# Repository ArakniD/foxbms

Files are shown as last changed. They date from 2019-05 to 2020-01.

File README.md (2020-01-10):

# foxBMS

foxBMS is a free, open and flexible development environment to design battery
management systems. It is the first modular open source BMS development
platform.

The foxconda environment: This environment provides all the tools necessary
to generate the documentation, compile the code for the MCUs and flash the
generated binaries on the MCUs (e.g., ``Python``, ``git``, ``GCC``). foxconda
can be downloaded [here](https://iisb-foxbms.iisb.fraunhofer.de/foxbms/).

The starting point to get foxBMS is the foxBMS repository at
[https://github.com/foxBMS/foxbms](https://github.com/foxBMS/foxbms), which
contains all files for the foxBMS project.

## foxBMS Repository

- In `foxbms\documentation` the configuration of the doxygen documentation for
  the primary and secondary MCU can be found.
- The software for the MCUs is found in `foxbms\embedded-software`. This
  includes the Hardware Abstraction Layer (HAL), the real-time operating system
  FreeRTOS and the BMS application itself.
- The layout and schematic files for the foxBMS hardware are found in the
  `foxbms\hardware`.
- The build toolchain and other tools related to foxBMS are found in
  `foxbms\tools`.

A generated version of the Sphinx documentation can be found at
[docs.foxbms.org](https://docs.foxbms.org). It explains the structure of the
foxBMS hardware, how to install the foxconda environment and how to use
foxconda to compile and flash the sources.

## Building the Sources

For building the software, open a shell and type ``python tools\waf --help``.
All available build options will be displayed. The top build directory is
``foxbms\build``.

[foxbms.org/](https://foxbms.org/)

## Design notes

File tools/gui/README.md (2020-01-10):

# foxBMS GUI

The script ``foxbms_interface.py`` is used to visualize the data from foxBMS
(e.g., voltages, temperatures current, errors).

It was written in a modular way, so that the only reference to the driver
of the CAN adapter is in the function ``receive_send_can_adapter()``.
Throughout the rest of the code, instances of the class can_message() are
used to manipulate CAN frames (ID, DLC, data).

The interface needs ``matplotlib``. Within the foxconda environment, this
can be done by using the command

```sh
C:\foxconda3\Scripts\activate
conda install matplotlib
```

The default version was configured to work with USB CAN-adapter from
PEAK (information found on the [peak-system.com](https://www.peak-system.com)
website). Two external elements are then needed in addition to the interface
script:

* PCAN-adapter DLL
* Python-wrapper for PCAN, named ``PCANBasic.py``

These files are redistributed in the foxBMS repository.
Before using them, you have to read the file ``readme.txt`` which gives
the terms of use.

The redistributed DLL is the 64 bit version.

The frame ``AdapterSelectionFrame()`` was used to implement the choice of the
CAN-adapter to use. It was configured to write with the PCAN-adapters.
In case another adapter is used, the frame has to be modified accordingly.

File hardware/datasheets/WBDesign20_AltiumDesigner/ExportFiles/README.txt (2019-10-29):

## WEBENCH Design 20
Created at Sun Jul 21 03:32:41 PDT 2019
**********************************************************
***************** Schematic Instructions  ****************
**********************************************************

To import your new Schematic into Altium:

1. Unzip the downloaded folder files to a local directory and 
   Start the Altium program.
2. From the menu select "File"->"Open".
3. Select the file named in the path above ending with ".schdoc"
   and "Open" the file.
4. Your Schematic should be viewable within Altium now.

For additional information, please visit this site:
http://www.accelerated-designs.com/help/Altium_BrdSch_import.html

**********************************************************
*******************  PCB Instructions  *******************
**********************************************************

To import your new BOARD into Altium:

1. Unzip the downloaded folder files to a local directory
	and Start the Altium program.
2. From the menu select "File"->"Open".
3. Select the file named in the path above ending with ".pcbdoc"
   and "Open" the file.
4. Planes will need to be repoured to update the Copper Pour Polygons
	a. Once your board is loaded, select the Tools menu from the
	   top Menu Bar
	b. Scroll to the Polygon Pours item on the Tools Menu.
	c. The Polygon Pours item should expand to show more options
	d. Select Repour All Polygons, this will repour all of the
	   polygons.
5. Your board should be viewable within Altium now.

For additional information, please visit this site:
http://www.accelerated-designs.com/help/Altium_BrdSch_import.html

**********************************************************
*******************  LIB Instructions  *******************
**********************************************************

To import your new LIBRARY PARTS into Altium follow these steps:

1. After running the Ultra Librarian export for the first time,
   you will need to copy the following files into an area where
   they can be accessed for all future translations.  They are script
   files that Altium will need to be able to find.
	a. UL_Form.dfm
	b. UL_Form.pas
	c. UL_Import.pas
	d. UL_Import.prjScr
2. The above script file will need to be run from within Altium.
   This can be done by going to File, Open and selecting the
   UL_Import.PrjScr file stored above.
3. Select the "DXP" dropdown menu in the top-left corner runfrom
   the drop down menu and select "Run Script". Select "UL_Form.pas"
   and click "OK"
4. When the script is run, it will ask you for the file name of the
   Ultra Librarian file to run. Click "File...", select the latest file
   produced with a date code (for instance 2010-02-17_23-12-34.txt), and
   click "Start Import".
5. The script will open a new Integraged Library project and import
   the Ultra Librarian data into it.  When complete a message box
   will pop up saying that import is done.

For additional information, please visit this site:
http://www.accelerated-designs.com/help/Altium_import.html

For a video tutorial, please visit:
http://youtu.be/pih50yx9HYU

**********************************************************
****************  SIMULATION Instructions  ***************
**********************************************************
This XML can be imported in Altium Designer 14 and higher using
WEBENCH Altium Connector Extension and simulated using WEBENCH
Simulation Engine.

The WEBENCH Altium Connector provides an interface to the
Texas Instruments WEBENCH Designer Tools as well as to open
WEBENCH exported Designs directly from inside Altium Designer.
It also includes the advanced WEBENCH Simulation Engine which
can be used for offline circuit simulations.

You will need to activate WEBENCH Altium Connector to be able
to use the WEBENCH Simulation Engine.

Installation guide:
http://www.ti.com/lit/SNVU481
You can download the WEBENCH extension from Altium Designer Extensions.

Connector Details:
http://www.ti.com/lsds/ti/analog/webench/altiumconnector.page

More about WEBENCH simulation export to Altium:
http://www.ti.com/lsds/ti/analog/webench/simexportaltium.page

User Manual:
http://www.ti.com/lit/szzu007

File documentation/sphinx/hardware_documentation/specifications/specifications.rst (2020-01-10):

.. include:: ../../macros.rst

.. _HARDWARE_DOCUMENTATION_SPECIFICATIONS:

==============
Specifications
==============

The following specifications must be met to ensure a safe and optimal work with the |foxbms| hardware.

----------
BMS-Master
----------

^^^^^^^^^^^^^^^^^^
Electrical Ratings
^^^^^^^^^^^^^^^^^^

==================================================  =======     =======     =======     ====
Description                                         Minimum     Typical     Maximum     Unit
==================================================  =======     =======     =======     ====
Supply Voltage DC                                   10          --          26          V
Contactor Continuous Current                        --          --          4           A
Contactor Feedback Supply Voltage                   --          5.0         --          V
Analog Input                                        --          --          3.3         V
Isolated Contacts Continuous Current                --          --          4           A
Interlock Circuit Sink Current                      --          10          --          mA
Idle Supply Current at 12V supply                   --          150         --          mA
Idle Supply Current at 24V supply                   --          110         --          mA
==================================================  =======     =======     =======     ====

^^^^^^^^^^^^^^^^^^^^^^^^^^^^^^^^^^^^^^^^^^^
Mechanical Dimensions (BMS-Master PCB only)
^^^^^^^^^^^^^^^^^^^^^^^^^^^^^^^^^^^^^^^^^^^

==================================================  =======     =======
Description                                         Value       Unit
==================================================  =======     =======
Width                                               120         mm
Length                                              160         mm
Height                                              15          mm
Weight                                              122         g
==================================================  =======     =======

^^^^^^^^^^^^^^^^^^^^^^^^^^^^^^^^^^^^^^^^^^^^^^^^^^
Mechanical Dimensions (BMS-Master Unit in housing)
^^^^^^^^^^^^^^^^^^^^^^^^^^^^^^^^^^^^^^^^^^^^^^^^^^

The BMS-Master Unit consists of BMS-Master board, BMS-Interface board and BMS-Extension board and is mounted in an aluminum housing.

==================================================  =======     =======
Description                                         Value       Unit
==================================================  =======     =======
Width                                               124         mm
Length                                              164         mm
Height                                              49.2        mm
Weight                                              785         g
==================================================  =======     =======

-----------------
BMS-Slave 12-Cell
-----------------

^^^^^^^^^^^^^^^^^^
Electrical Ratings
^^^^^^^^^^^^^^^^^^

==================================================  =======     =======     =======     ====
Description                                         Minimum     Typical     Maximum     Unit
==================================================  =======     =======     =======     ====
Battery Module Voltage                              11          --          60          V
Single Battery Cell Voltage                         0           --          5           V
Temperature Sensor Inputs                           --          10k         --          Ω
Analog Inputs (pin headers)                         0           --          5           V
Digital Inputs/Outputs (pin headers)                0           --          5           V
External DC Supply (HW version 2.1.0 and above)     8           12          24          V
==================================================  =======     =======     =======     ====

^^^^^^^^^^^^^^^^^^^^^^^^^^^^^^^^
Mechanical Dimensions (PCB only)
^^^^^^^^^^^^^^^^^^^^^^^^^^^^^^^^

==================================================  =======     =======
Description                                         Value       Unit
==================================================  =======     =======
Width                                               100         mm
Length                                              160         mm
Height                                              15          mm
Weight                                              83          g
==================================================  =======     =======

-----------------
BMS-Slave 18-Cell
-----------------

^^^^^^^^^^^^^^^^^^
Electrical Ratings
^^^^^^^^^^^^^^^^^^

==================================================  =======     =======     =======     ====
Description                                         Minimum     Typical     Maximum     Unit
==================================================  =======     =======     =======     ====
Battery Module Voltage                              16          --          90          V
Single Battery Cell Voltage                         0           --          5           V
Temperature Sensor Inputs                           --          10k         --          Ω
Analog Inputs (pin headers)                         0           --          5           V
Digital Inputs/Outputs (pin headers)                0           --          5           V
External DC Supply                                  8           12          24          V
==================================================  =======     =======     =======     ====

^^^^^^^^^^^^^^^^^^^^^^^^^^^^^^^^
Mechanical Dimensions (PCB only)
^^^^^^^^^^^^^^^^^^^^^^^^^^^^^^^^

==================================================  =======     =======
Description                                         Value       Unit
==================================================  =======     =======
Width                                               100         mm
Length                                              160         mm
Height                                              15          mm
Weight                                              88          g
==================================================  =======     =======

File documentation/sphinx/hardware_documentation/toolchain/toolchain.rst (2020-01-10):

.. include:: ../../macros.rst

.. _HARDWARE_DOCUMENTATION_TOOLCHAIN:

=========
Toolchain
=========

Layout and schematics
---------------------

The initial layout and schematics were developed with Cadsoft Eagle version
6.5.0 which is now owned by
`AUTODESK <https://www.autodesk.com/products/eagle/overview>`_. Recently, all
hardware projects were ported to
`Altium Designer <https://www.altium.com/altium-designer/de>`_.

Information on Debugging
------------------------

Two types of debugger have been tested with |foxBMS|.

* The first one is the
  `Segger J-Link Plus <https://www.segger.com/j-link-plus.html>`_ with the
  `adapter for 19-Pin Cortex-M <https://www.segger.com/products/debug-probes/j-link/accessories/adapters/19-pin-cortex-m-adapter/>`_
  (the adapter is needed to connect the debugger to the |master|). A cheaper
  debugger solution is the
  `Segger J-Link Base <https://www.segger.com/jlink_base.html>`_ which also
  needs the adapter.

* The second type of debugger is the
  `Lauterbach Debugger <http://www.lauterbach.com>`_ µTrace for Cortex-M (see
  the "Products" section in the navigation bar on the left). The Lauterbach
  debugger provides more debugging functionalities, but is also more expensive
  than the J-Link.

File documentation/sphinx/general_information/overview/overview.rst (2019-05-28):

.. include:: ../../macros.rst

.. _GENERAL_INFORMATION_OVERVIEW:

========
Overview
========

Hereafter a general overview of the content of |foxbms| can be found.

The |master| consists of 3 boards: |BMS-Master|, |BMS-Interface|, |BMS-Extension|. Two ARM-based microcontroller units (Cortex-M4) are used on |BMS-Master|: |MCU0| (also called primary MCU) and |MCU1| (also called secondary MCU). The BMS software runs on |MCU0|, while |MCU1| is used for redundant safety.

|MCU0| communicates with the outside world via a CAN bus (|CAN0|). The current flowing through the battery system is measured via a current sensor connected via the CAN bus. The sensor is controlled via CAN by |MCU0| and sends the resulting measurement via CAN.

The |slave| (|BMS-Slave|) are used to measure cell voltages and cell temperatures in the battery modules. The |slaves| are linked via a proprietary daisy chain from the company Linear Technology (i.e., isoSPI).

In order for the |master| to communicate with the |slaves|, an interface board (i.e., |BMS-Interface|) is needed. It converts the SPI signals from the |BMS-Master| into differential signals used by the daisy chain and vice versa.

Three power contactors are used to connect and disconnect the battery modules (or pack) from the load:

 - Main Contactor Plus
 - Main Contactor Minus
 - Pre-charge contactor

These contactors are driven by |MCU0|. Requests are made via CAN to the system to open and close the contactors. Based on the measurements and the algorithms implemented in the software, |MCU0| decides if the contactors should be closed or opened. It sends information via CAN so that the user knows the state of the system.

An interlock line is also present. If it is opened, either by |MCU0|, |MCU1| or somewhere else (e.g., emergency stop), all contactors will immediately open.

A secondary ARM-based microcontroller is present on the master, called |MCU1| (or secondary MCU). It monitors the slaves via a second and separate daisy chain. Like the |MCU1|, it can open the interlock in case something goes wrong with the system.

In case more inputs and outputs and further functions are required, an |BMS-Interface| is available and can be easily adapted to specific needs.

This description reflects the current state of foxBMS. Due to the open nature of the system, many other possibilities can be implemented, like for example:

 - Use of other types of current sensors (e.g., shunt-based or Hall-effect based)
 - No |slave| needs to be used: a direct measurement of the cell voltages and cell temperatures can be performed by the |master|
 - A higher number of contactors can be controlled (e.g., up to 9)
 - etc...

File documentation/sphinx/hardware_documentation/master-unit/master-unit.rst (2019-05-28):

.. include:: ../../macros.rst

.. _HARDWARE_DOCUMENTATION_OVERVIEW:

===========
Master-Unit
===========

This section describes the hardware modules used in |foxbms|. :numref:`Fig. %s <master_block_diagram>` shows a block diagram of the |master| with all its components.

.. _master_block_diagram:


   |master| hardware block diagram

Supply 0 (|primary|)
--------------------

.. _supply0:


   Supply for all circuit parts related to the |primary| part of |foxbms|

The external supply for the |BMS-Master| is divided in a part supplying the interlock circuit, the contactors (``SUPPLY_EXT2``), and the rest of the circuit (``SUPPLY_EXT0``) as shown in :numref:`Fig. %s <supply0>` . The |Master| can be supplied with a voltage between 12V and 24V DC. The |primary| part of the |foxbms| is isolated from ``SUPPLY_EXT0`` by an isolating DC/DC converter (IC202). The 5V output of the DC/DC converter is stepped down to 3.3V by an LM1085 LDO (IC201). The output of IC201 (+3.3V_0) supplies the |primary| microcontroller |MCU0| and the related circuits.

Supply 1 (|secondary|)
----------------------

.. _supply1:


   Supply for all circuit parts related to the |secondary| part of |foxbms|

The |secondary| part of |foxbms| is also supplied by ``SUPPLY_EXT0`` as shown in :numref:`Fig. %s <supply1>`. Also the |secondary| part of the |BMS-Master| is isolated from ``SUPPLY_EXT0`` by an isolating DC/DC converter (IC302). The 5V output of the DC/DC converter is stepped down to 3.3V by an LM1085 LDO (IC301). The output of IC301 (+3.3V_1) supplies the |secondary| microcontroller |MCU1| and the related circuits.

|MCU0| (|primary|)
------------------

.. _mcu0_boot_rst:


   Boot and reset circuit for the |primary| microcontroller

:numref:`Fig. %s <mcu0_boot_rst>` shows the boot and reset related circuits of the |primary| microcontroller |MCU0|. |MCU0| can be manually reset by push button S401. Please note that the housing has to be opened to reach S401, therefore resetting |MCU0| by means of S401 is intended for use in a laboratory setting/debugging situation.

.. _mcu0_adc_ref:


   ADC reference voltage for the |primary| microcontroller

The ADCs of the |primary| microcontroller |MCU0| are supplied with a 2.5V reference voltage provided by an ADR3425 (IC401) as shown in  :numref:`Fig. %s <mcu0_adc_ref>`.

.. _mcu0_osc:


   Clock circuits of the |primary| microcontroller

The |primary| microcontroller |MCU0| is clocked by an 8MHz oscillator as shown in :numref:`Fig. %s <mcu0_osc>`. An separate oscillator (Q402) is used to clock the RTC (real time clock) integrated in |MCU0|.

Interface between |MCU0| and |MCU1|
-----------------------------------

.. _mcu_to_mcu_if:


   Interface between |primary| and |secondary| microcontroller

Besides being linked over the common interlock line, the |primary| and |secondary| microcontroller also have a common SPI data interface. The |secondary| microcontroller |MCU1| acts as the master in the SPI communication. The interface is isolated using an ADUM3401 as shown in :numref:`Fig. %s <mcu_to_mcu_if>`.

Interface to Bender ISOMETER
----------------------------
.. _bender:


   Interface to the Bender ISOMETER

The |BMS-Master| supports Bender ISOMETER IR155-3203/-3204/-3210. Two inputs are provided: one for a PWM coded diagnostic signal and one for a simple status signal (OK or NOK) as shown in :numref:`Fig. %s <bender>`. The Bender ISOMETER is supplied ``SUPPLY_EXT0`` and may be switched on or off (lowside) by the |BMS-Master|. The input signals are limited to  level of 5V with Zener diodes D701 and D702. In order adapt the interface for use with a IR155-3204/-3203 device, the solder jumper R705 has to be removed. The input signals are isolated from the microcontoller by an ADUM3301 (IC702).

|CAN0|
------

.. _can0:


   Circuit of the CAN interface (|CAN0|)

The |CAN0| interface is intended to connect additional sensors, such as the Isabellenhütte IVT-MOD-300 current sensor to the |master| and the |master| to other devices such as a test bench control unit or an HMI unit. The circuit in :numref:`Fig. %s <can0>` shown the input circuit consisting of protection diode D801, common mode choke L801, C804, and termination resistors R801 and R802. The CAN transceiver TJA1052 provides isolation and can be put to sleep by the |primary| microcontroller |MCU0| via an CPC1008N optocoupler (IC803). The external part of the |CAN0| interface is supplied by ``SUPPLY_EXT0``.

Interlock
---------

.. _interlock:


   Interlock circuit

The |primary| and |secondary| microcontroller share a common interlock line as shown in :numref:`Fig. %s <interlock>`. The interlock line is isolated from both microcontrollers |MCU0| and |MCU1| by optocouplers. The interlock line is supplied with 10mA by a current source (LM317 - IC901). It can be interrupted by the |primary| microcontroller |MCU0| via optocoupler IC902 and can be read back by |MCU0| via optocoupler IC903. The |secondary| microcontroller |MCU1| can interrupt the interlock line via IC904 and read the interlock status via IC905. The 10mA cause a voltage drop on R906, which turns on MOSFET T901. T901 switches the common ground of all contactors (connected to the |BMS-Master| and |BMS-Extension|). Therefore, when the interlock line is interrupted, the contactors are no longer supplied and open.

Contactors
----------

.. _contactors:


   Contactor circuit, exemplarily shown for contactor0

The |Master| can control up to 9 contactors: 6 on the |BMS-Master| and 3 on the |BMS-Extension|. The according control and feedback circuit is exemplarily shown  for contactor 0 in :numref:`Fig. %s <contactors>`. The contactor is switched on and off by an AQV25G2S photoMOS (IC1001) by the |primary| microcontroller |MCU0|. Every contactor channel is protected with slow blowing fuse (F1001) type Schurter UMT-250 630mA (3403.0164.xx). The free wheeling diode D1001 is not populated. It has to be inserted when contactors are used, that do not provide an internal free wheeling diode. The contactor interface also supports a feedback functionality for contactors with auxiliary contacts. The contactor status can be read back by |MCU0| via an ADUM3300 (IC1103).

Isolated USB interface (|primary| and |secondary|)
--------------------------------------------------

.. _usb:


   USB interface circuit

Both mircocontrollers |MCU0| and |MCU1| provide an isolated USB interface, as exemplarily shown for |MCU0| in :numref:`Fig. %s <usb>`. A FT231XS-R interface IC (IC1402) converts the USB signal to UART, which can easily be interfaced by the microcontroller. The UART signals are isolated by an ADUM3401 isolation IC (IC1403). The USB interface can be used to flash the microcontroller and for communication.

EEPROM
------

.. _eeprom:


   EEPROM, exemplarily shown for the |MCU0|

The |BMS-Master| provides an 2MB EEPROM for data storage for the |primary| and |secondary| MCU (see :numref:`Fig. %s <eeprom>`). It uses an SPI interface, which is shared with the memory card, which is also connected to |MCU0|.

Isolated RS485 Interface
------------------------

.. _rs485:


   Isolated RS485 interface circuit

On the |BMS-Extension| an isolated RS485 interface is provided. It can be used to communicate with the |master| as an alternative to the CAN interface or the UART over USB interface. Moreover, via this interface, monitoring circuits (slaves) using RS485 instead of CAN or another proprietary communication protocol can be connected to the |master|. :numref:`Fig. %s <rs485>` shows the RS485 interface schematic. The external part of the circuit is supplied via a voltage applied to pins 5 (7V - 20V) and 6 (GND) of connector X1301. The external supply voltage is also available on pin 1 (GND) and pin 4. IC1301 provides 5V supply voltage for the transceiver (IC1302) and the external side of the isolator (IC1303). The transceiver (LT1785) features a receiver enable (!RE) and a driver enable (DE) functionality, which can be controlled by the |primary| microcontroller via the signals ``RS485_MCU0_NRE`` and ``RS485_MCU0_DE`` respectively. For data transmission the signals ``RS485_MCU0_TX`` and ``RS485_MCU0_RX`` are used. The data signals are available on connector X1301 pins 1 and 2. The data signals and the enable signals are galvanically isolated from the |BMS-Master| by an ADUM3401 isolator IC.

Isolated Normally Open Contacts (isoNOC)
----------------------------------------

.. _iso_noc:


   Isolated normally open contacts (``ISONOC0`` examplarily)

The |BMS-extension| provides 6 normally open contacts (``ISONOC0`` to ``ISONOC5``) for multi-purpose use. Their function is exemplarily described for ISONOC channel0 ( shown in :numref:`Fig. %s <iso_noc>`). Isolation and switching functionality are realized by AQV25G2S photoMOS (IC2001). The photoMOS are controlled by a MOSFET (T2001), which again is switched by the |primary| microcontroller (``ISONOC0_CONTROL``). The photoMOS is configured for a maximum load current of 6A at 50V. Diode D1002 is optionally and not populated by default. Both power terminals of the photoMOS are available on connector X2001 as ``ISONOC0_POSITIVE`` and ``ISONOC0_POSITIVE`` on consecutive pins 1 and 2.

Analog Inputs
-------------

.. _analog_inputs:


   Non isolated analog inputs (analog channel 0 exemplarily)

For the acquisition of analog data, there are 5 ADC channels (``ANALOG_IN_CH0`` - ``ANALOG_IN_CH4``) available on |BMS-Extension| board. :numref:`Fig. %s <analog_inputs>` shows the input circuit for channel 0. The analog input of the microcontroller (``ADC_MCU0_CH0``) is protected by diode D1701, which clamps the input voltage to 3.3V. By default R1701 is shorted with jumper, while R1702 is 7.75kOhm and C1701 is 100nF. The analog input channels are available on connector X1701. A reference voltage of 2.5V is provided by IC1701 (ADR3425), which can supply a total load current up to +10mA and sink up −3mA. The reference voltage is available in X1701 next to every analog input pin. Pin 11 and 12 are connected to GND.

.. note::
    The analog inputs are not isolated. They are referenced to the same potential as the |primary| microcontroller.

Isolated GPIO
-------------

.. _isolated_gpio:


   Isolated GPIOs (Input 0 and 1; Output 0 and 1 shown exemplarily)

The |BMS-Extension| provides 4 isolated inputs and 4 isolated outputs for general purpose (shown in :numref:`Fig. %s <isolated_gpio>` ). Two ADUM3402 (IC1902 and IC1903) are used for isolation. Their external side of is supplied by ``SUPPLX_EXT0`` via a 78L05F linear voltage regulator (IC1901). The inputs are equipped with a 10kOhm pull down resistor. All isolated GPIOs are available on the connector X1901 pins 1 to 8. Pins 9 and 10 of X1901 are connected to ``GND_EXT0``.

Memory Card
-----------

.. _memory_card:


   Memory card

On the |BMS-Extension| also a memory card slot can be found. It is directly connected to the Data Storage SPI of the |primary| microcontroller. :numref:`Fig. %s <memory_card>` shows the schematic. Via the signal ``CARD_SUPPLY_CONTROL`` (|primary| microcontroller) the supply voltage of the memory card can be switched on and off.

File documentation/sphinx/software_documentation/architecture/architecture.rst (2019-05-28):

.. include:: ../../macros.rst

.. _SOFTWARE_DOCUMENTATION_ARCHITECTURE:

=====================
Software Architecture
=====================

This section describes the |foxbms| software architecture. The architecture
was chosen to enable a processor independent programming as far as possible.
Fig. :numref:`foxbms_software_architecture` shows the software architecture
of |foxbms|.

..  graphviz::
    :caption: |foxbms| software architecture
    :name: foxbms_software_architecture

        digraph {
            rankdir=TB;
            graph [fontname = "monospace"]
            node [fontname = "monospace"]
            edge [fontname = "monospace"];
            subgraph cluster_architecture {
                label="foxBMS (runs within OS context)";
                app [label="application"];
                engine [label="engine"];
                modules [label="foxBMS-Modules", target="_bottom"];
                modules -> app;
                app -> modules;
                app -> engine;
                engine -> app;
                engine -> modules;
            }
            subgraph cluster_foxbms_hal {
                label="";
                drivers [label="Drivers"];
            }
            subgraph cluster_hal {
                label="";
                target="_bottom";
                hal     [label="HAL"];
            }
            modules -> drivers;
            drivers -> hal;
     }

The software consists of a base hardware abstraction layer of the
microcontroller. The driver layer on top if it is used to configure and
initialize the peripherals of the microcontroller. These hardware dependent
layers resemble the base of the software architecture. The remaining modules
are built on top of it to allow an easy port of the software to different
microcontrollers.

Hardware abstraction layer
==========================

The hardware abstraction layer (HAL) consists of the STM32F4xx HAL Drivers
|version-hal|. Additionaly the Cortex Microcontroller Software Interface Standard
(CMSIS) |version-cmsis| is used as an abstraction layer for the Cortex M4F processor.

Drivers
=======

The driver layer is responsible for the configuration and the initialization of
the controller peripherals. These drivers are dependent on the specific used
microcontroller and the used HAL. Drivers are only allowed to include files
from driver or the lower hardware abstraction layer (i.e. SPI modules includes
DMA module to configure the respective DMA stream).

|foxbms|-Modules
================

|foxbms|-modules initialize, configure and control hardware connected to the
|master|. These modules are only allowed to access the hardware through the drivers
and directly via the HAL. No direct function calls to the HAL should be make
the modules as independent as possible from the used microcontroller. They may
include engine modules (i.e. database, diag), applications (com) or even the
operating system if they need to ensure some runtime specific behaviour. These
modules are called within the operating system to ensure a real-time behaviour.

Operating System
================

The real-time operating system FreeRTOS |version-freertos| is used to manage
the foxBMS-engine and applications. Tasks with different priorities are used to
process the different algorithms and state machines and to ensure a real-time
behaviour of the different modules.

|foxbms|-Engine
===============

Important hardware independent software modules are bundled to the
foxBMS-engine. This involves a database for storing important parameters, a
diagnosis module for error detection and handling as well as the
startup/initialization behaviour of the BMS. The operating system engine tasks
are the tasks with the highest priorites and used to ensure a real-time
behaviour of the safety-critical modules. Engine modules are allowed to include
|foxbms|-Modules, drivers, applications and of course the operating system.

|foxbms|-Application
====================

The application layer gathers all hardware independent modules that are
responsible for the actual BMS functionality (i.e. SOC, SOH, balancing...).
The most important module is the |mod_bms| that monitors the behaviour of the
battery system to ensure an adherence of the safe-operating area and controls
the BMS state (i.e. charging/discharging). The operating system applications
tasks are the tasks with the lowest priorites to ensure a real-time behaviour
of the safety-critical modules. Applications are allowed to include |foxbms|-Modules, drivers, engine-modules and of course
the operating system.

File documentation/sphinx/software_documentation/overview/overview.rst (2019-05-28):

.. include:: ../../macros.rst

.. _SOFTWARE_DOCUMENTATION_OVERVIEW:

=================
Software Overview
=================

.. highlight:: C

Startup
-------
The startup code begins at the label ``Reset_Handler`` in
``general\config\startup_stm32f429xx.s``. After initialization of the main
microcontroller registers, the system clock unit and the memory data (e.g.,
stack- and program pointer, system control block (SCB), interrupt vector,
pre-initialization of data-sections, FPU settings), the C function ``main()``
is called.
In ``general\main.c`` the second step of initializations of the
microcontroller unit, peripherals and software modules are done (e.g.,
interrupt priorities, hardware modules like SPI and DMA). At this point,
interrupts are still disabled. The steps are indicated by the global variable
``os_boot``. At the end of the main function, the operating system resources
(tasks, events, queues, mutex) are configured in ``OS_TaskInit()``
(``os/os.c``) and the scheduler is started by enabling the interrupts.
Scheduling is started by invoking all configured tasks (FreeRTOS threads)
regarding their priority. The activation of the scheduling is indicated by
``os_boot = OS_RUNNING``. The OS-scheduler first calls the task
``void ENG_TSK_Engine(void)`` as the highest priority is assigned to this task.
All other tasks are blocked in a while-loop until ``ENG_TSK_Engine()`` finishes
the third initialization step and enters the periodic execution.

Operating System
----------------

The following changes were to the FreeRTOS kernel in file port.c:

- Function ``uint8_t vPortCheckCriticalSection(void)`` was added to check if
  a function is currently executed within a critical section of the OS.

A critical section is entered with the FreeRTOS function ``vPortEnterCritical``
and exited with the function ``vPortExitCritical``. The operating system is
configured in the file ``FreeRTOSConfig.h``. A detailed explanation of the
parameters is given at https://www.freertos.org/a00110.html.

Engine
------

The task ``void ENG_TSK_Engine(void)`` executes the third (and last) step of
system initialization with enabled interrupts in ``ENG_PostOSInit()``. Then
``OS_TSK_Engine()`` manages the database and system monitoring via a periodic
call of ``DATA_Task()`` and ``DIAG_SysMon()`` every 1ms.

After that, ``os_boot`` is set to ``OS_SYTEM_RUNNING`` and the function
``void ENG_Init(void)`` is run before the periodic tasks. Initializations can
be made in this function. The database is already running when it is called.
The system then runs the following tasks periodically:

 - ``void ENG_TSK_Cyclic_1ms(void)``
 - ``void ENG_TSK_Cyclic_10ms(void)``
 - ``void ENG_TSK_Cyclic_100ms(void)``

It must be noted that no changes should be made directly in these functions,
since they are used as wrapper. They call the following functions:

 - ``void ENG_Cyclic_1ms(void)``
 - ``void ENG_Cyclic_10ms(void)``
 - ``void ENG_Cyclic_100ms(void)``

where the effective calls for system tasks are made. These three functions and
``ENG_TSK_Engine()`` make up the core of the system and are called ``engine``.
These function calls are found in ``engine/task/enginetask.c``. Additionally,
three users tasks run periodically. They are described in :ref:`usr_apps`.

.. _usr_apps:

User Applications
-----------------

For the user applications, three periodic tasks are available:

 - ``void APPL_TSK_Cyclic_1ms(void)``
 - ``void APPL_TSK_Cyclic_10ms(void)``
 - ``void APPL_TSK_Cyclic_100ms(void)``

It must be noted that no changes should be made directly in these functions,
since they are used as wrapper. They call the following functions:

 - ``void APPL_Cyclic_1ms(void)``
 - ``void APPL_Cyclic_10ms(void)``
 - ``void APPL_Cyclic_100ms(void)``

Here, the user can implement its own functions, like new battery state estimation
algorithms. The user has access to system data via the database. These function
calls are found in ``application/task/appltask_cfg.c``.

Startup Sequence
----------------

The start-up sequence is shown in :numref:`fig. %s <startup_simplified>`.

.. _startup_simplified:


   |foxbms| system start-up

Software Architecture
---------------------

The database runs with the highest priority in the system and provides
asynchronous data exchange for the whole system. :numref:`Fig. %s <database>`
shows the data exchanges implemented via the database.

.. _database:


   Asynchronous data exchange with the |foxbms| database

:numref:`Fig. %s <engine>` shows the main structure of |foxbms|.

.. _engine:


   Main tasks in |foxbms|

The two key modules used are:

 - ``SYS``
 - ``BMS``

``SYS`` has a lower priority than the database and a higher priority than
``BMS``. Both modules are implemented as a state machine, with a trigger
function that implements the transition between the states. The trigger
functions of ``SYS`` is called in ``void ENG_Cyclic_10ms(void)``. As
``BMS`` implements the user application, it is called in the user task
``void APPL_Cyclic_1ms(void)``.

``SYS`` controls the operating state of the system. It starts the other
state machines (e.g., ``CONT`` for the contactors, ``ILCK`` for the
interlock, ``BMS``).

``BMS`` gathers info on the system via the database and takes decisions based
on this data. The BMS is driven via CAN. Requests are made via CAN to go
either in STANDBY mode (i.e., contactors are open) or in NORMAL mode (i.e.,
contactors are closed). A safety feature is that these requests must be sent
periodically every 100ms. ``BMS`` retrieves the state requests received via
CAN from the database and analyses them. If the requests are not sent
correctly, this means that the controlling unit driving the BMS has a
problem and the correctness of the orders sent to the BMS may not be given
anymore. As a consequence, in this case ``BMS`` makes a request to ``CONT``
to open the contactors. Currently, ``BMS`` checks the cell voltages, the cell
temperatures and the global battery current. If one of these physical
quantities show a value out of the safe operating area, ``BMS`` makes the
corresponding state request to ``CONT`` to open the contactors. ``BMS`` is
started via an initial state request made in ``SYS``.

A watchdog instance is needed in case one of the aforementioned tasks hangs:
in this case, the control over the contactors would not be provided anymore.
This watchdog is made by the System Monitor module which monitors all
important tasks (e.g., ``Database``, ``SYS``, ``BMS``): if any of the
monitored tasks hangs, the contactors are opened to prevent damage and
protect persons and the battery. To ensure the highest level of safety,
opening the contactors is made by direct access to the |mod_io|.

A last barrier is present in case all the preceeding measures fail: the
hardware watchdog timer. In case it is not triggered periodically, it resets
the systems, provoking the opening of the contactors. Function calls (other
than ``SYS``) and closely related to the system are made in the engine tasks,
for example:

 - CAN
 - Battery cells monitoring (voltages and temperatures)
 - Galvanic isolation monitoring
 - Lithium 3V coin cell voltage monitoring
 - EEPROM
 - NVRAM-Handler

Diagnostic
----------

The |mod_diag| is designed to report problems on the whole system. The events
that trigger the |mod_diag| have to be defined by the user. The event handler
``DIAG_Handler(...)`` has to be called when the event is detected. The way the
system reacts to a ``Diag`` event is defined via a callback function or by the
caller according the return value.

Diagnostic events are stored in the Backup SRAM memory in the variable
``DIAG_ERROR_ENTRY_s diag_memory[]``

.. code-block:: C

   typedef struct {
    uint8_t YY;
    uint8_t MM;
    uint8_t DD;
    uint8_t hh;
    uint8_t mm;
    uint8_t ss;
    DIAG_EVENT_e event;
    DIAG_CH_ID_e event_id;
    uint32_t item;
    uint32_t dummy1;
    uint32_t Val0;
    uint32_t Val1;
    uint32_t Val2;
    uint32_t Val3;
    } DIAG_ERROR_ENTRY_s;

Data stored in the database
---------------------------

The following data is stored in the database:

  - Cell voltages
  - Cell temperatures
  - SOX (Battery state, contains State-of-Charge)
  - Balancing control
  - Balancing feedback
  - Current sensor measurements (includes battery current)
  - Hardware information
  - Last state request made to the BMS
  - Minimum, maximum and average values for voltages and temperatures
  - Measurement from isolation monitor
  - Interface to communicate via I2C with extra funcitonalities on slave (e.g., EEPROM, port expander)
  - Result from open-wire check on slaves
  - LTC device parameter
  - LTC accuracy
  - Error state of the BMS (i.e., error flags, set to 0 or 1)
  - MSL, maximum safety limits
  - RSL, recommended safety limits
  - MOL, maximum operating limits
  - Calculated values for moving average
  - Contactor feedback
  - Interlock feedback
  - BMS state (e.g., standby, normal, charge, error)
  - Current limits calcuated for State-of-Function
  - Voltages read on GPIOs of the slaves

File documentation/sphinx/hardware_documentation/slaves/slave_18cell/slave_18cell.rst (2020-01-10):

.. include:: ../../../macros.rst

.. _HW_SLAVE_18CELL:

==================================
Slave 18-Cell ``v1.1.3 and above``
==================================

--------
Overview
--------

.. important::

   The following description only applies for the 18-cell |BMS-Slave| hardware versions ``1.1.3`` and above.

.. hint::

   All connector pinouts described below follow the :ref:`sec-connector-convention`.

^^^^^^^^^^^^^
Block Diagram
^^^^^^^^^^^^^

.. _BMS-Slave_18cell:


   foxBMS BMS-Slave 18-Cell Block Diagram
..

^^^^^^^^^^^^^^^^^^^^^^^^^^
Schematic and Board Layout
^^^^^^^^^^^^^^^^^^^^^^^^^^

More information about the board schematic and layout files can be found in section :ref:`hardware_design_resources`.

^^^^^^^^^^^^^^^^^^^^^
Mechanical Dimensions
^^^^^^^^^^^^^^^^^^^^^

The size of the foxBMS Slave PCB is 160x100mm. A ``*.step`` file and a ``3D-PDF`` of the PCB can be found in section :ref:`hardware_design_resources`.

---------
Functions
---------

The following general descriptions apply to both, the primary and the secondary unit on the foxBMS BMS-Slave. If there are any differences in hardware
between the primary and the secondary unit they will be marked as such.

^^^^^^^^^^^^^^^^^^^^^^^^
Cell Voltage Measurement
^^^^^^^^^^^^^^^^^^^^^^^^

The cell voltage sense lines are input on the connector X200. The pinout is described in :numref:`table %s <cell_sense_connector_18>`.



.. _cell_sense_connector_18:

.. table:: Cell voltage sense connector

    ====   =============    ============    =================================
    Pin    Signal           Direction       Description
    ====   =============    ============    =================================
    1      VBAT-            Input           Battery module negative terminal
    2      CELL_0+          Input           Cell 0 positive terminal
    3      CELL_2+          Input           Cell 2 positive terminal
    4      CELL_4+          Input           Cell 4 positive terminal
    5      CELL_6+          Input           Cell 6 positive terminal
    6      CELL_8+          Input           Cell 8 positive terminal
    7      CELL_10+         Input           Cell 10 positive terminal
    8      CELL_12+         Input           Cell 12 positive terminal
    9      CELL_14+         Input           Cell 14 positive terminal
    10     CELL_16+         Input           Cell 16 positive terminal
    11     VBAT+            Input           Battery module positive terminal
    12     NC               --              --
    13     CELL_0-          Input           Cell 0 negative terminal
    14     CELL_1+          Input           Cell 1 positive terminal
    15     CELL_3+          Input           Cell 3 positive terminal
    16     CELL_5+          Input           Cell 5 positive terminal
    17     CELL_7+          Input           Cell 7 positive terminal
    18     CELL_9+          Input           Cell 9 positive terminal
    19     CELL_11+         Input           Cell 11 positive terminal
    20     CELL_13+         Input           Cell 13 positive terminal
    21     CELL_15+         Input           Cell 15 positive terminal
    22     CELL_17+         Input           Cell 17 positive terminal
    23     NC               --              --
    24     NC               --              --
    ====   =============    ============    =================================

Each of these lines is fused with a fast acting 250 mA surface-mount fuse (F301 - F319) on the board except of the VBAT+ and VBAT- lines which are fused with a
value of 500 mA (F300 and F320). This essentially is important for an evaluation environment. The VBAT+ and VBAT- connection is used for the internal power
supply of the slave board. If the battery module does not contain these separate wires to the positive and negative module terminal the solder jumpers SJ300
and SJ301 have to be shorted. In this case the slave will be supplied through the sense lines CELL_0- and CELL_11+. Running the slave in this configuration
could result in cell measurement errors due to voltage drop on the sense wires.

The cell input lines are filtered by a grounded or differential capacitor filter (both possibilities provided on the PCB). More information on the
corner frequency of this filtering can be found in the schematic. The grounded capacitor filter should be used in environments affected with
high noise as it offers a high level of battery voltage ripple rejection. The differential capacitor filter can be used when noise is less occurrent or the
design is subjected to cost optimization.

^^^^^^^^^^^^^^^^^^^^^^
Passive Cell Balancing
^^^^^^^^^^^^^^^^^^^^^^

The passive balancing circuit is realized by a parallel connection of two 130 Ohm discharge-resistors that can be connected to each single cell in parallel.
The MOSFET switches (T1500 - T1517) that control the connection to the cells are controlled by the primary |LTC-18| monitoring IC. The |LTC-18| on the secondary
unit does not support balancing. The resistor value of 2x 130 Ohm results in a balancing current of about 55mA at a cell voltage of 3.6V. This current results
in a power dissipation of about 0.2W per balancing channel (at 3.6V).

^^^^^^^^^^^^^^^^^^^^^^^^^^^^^^
Global Cell Balancing Feedback
^^^^^^^^^^^^^^^^^^^^^^^^^^^^^^

In order to check the proper function of the balancing process or to detect a malfunction in the balancing control circuit, a global balancing
feedback signal is connected to the |LTC-18|. This allows the system to check whether any balancing action is currently taking place at any time. The feedback
signal is connected to the GPIO3 of the |LTC-18|. The signal remains in a logic zero state until any balancing action on any cell starts.

^^^^^^^^^^^^^^^^^^^^^^^^^^^^^^
Temperature Sensor Measurement
^^^^^^^^^^^^^^^^^^^^^^^^^^^^^^

The cell temperature sensors are connected to the connectors X201 (primary) and X202 (secondary). The pinout is identical for the primary and secondary
unit and is described in :numref:`table %s <temp_sense_connector_18>`.

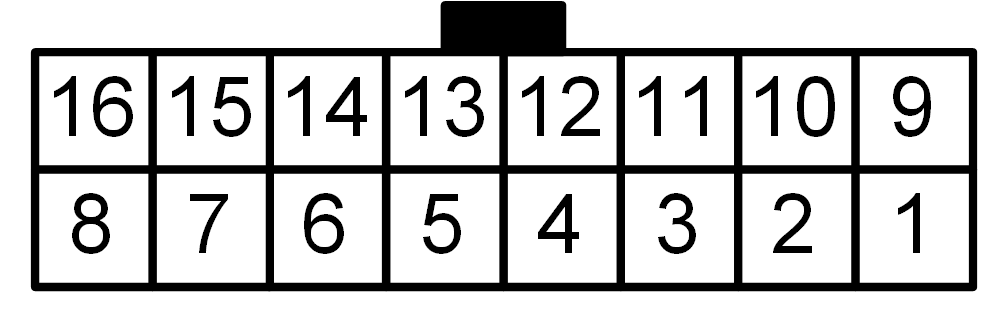
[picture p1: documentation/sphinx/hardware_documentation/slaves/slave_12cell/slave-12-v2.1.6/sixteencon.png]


.. _temp_sense_connector_18:

.. table:: Temperature sensor connector

    ====   =============    ============    ========================
    Pin    Signal           Direction       Description
    ====   =============    ============    ========================
    1      T-SENSOR_0       Input           NTC Sensor 0 terminal 1
    2      T-SENSOR_1       Input           NTC Sensor 1 terminal 1
    3      T-SENSOR_2       Input           NTC Sensor 2 terminal 1
    4      T-SENSOR_3       Input           NTC Sensor 3 terminal 1
    5      T-SENSOR_4       Input           NTC Sensor 4 terminal 1
    6      T-SENSOR_5       Input           NTC Sensor 5 terminal 1
    7      T-SENSOR_6       Input           NTC Sensor 6 terminal 1
    8      T-SENSOR_7       Input           NTC Sensor 7 terminal 1
    9      FUSED_VBAT-      Input           NTC Sensor 0 terminal 2
    10     FUSED_VBAT-      Input           NTC Sensor 1 terminal 2
    11     FUSED_VBAT-      Input           NTC Sensor 2 terminal 2
    12     FUSED_VBAT-      Input           NTC Sensor 3 terminal 2
    13     FUSED_VBAT-      Input           NTC Sensor 4 terminal 2
    14     FUSED_VBAT-      Input           NTC Sensor 5 terminal 2
    15     FUSED_VBAT-      Input           NTC Sensor 6 terminal 2
    16     FUSED_VBAT-      Input           NTC Sensor 7 terminal 2
    ====   =============    ============    ========================

Standard 10kΩ NTC resistors (e.g. Farnell-Nr. 1299926) are recommended for use. When using other values than these, the series resistors
(R100-R107) on the board may have to be adjusted. Please note that the accuracy of the internal voltage reference VREF2 decreases heavily with
a load of over 3mA. Using 8x 10kΩ NTC resistors with the corresponding 10kΩ series resistors results in a current of 1.2mA (at 20°C) which is drawn
from VREF2.

Each 8 temperature sensors are connected to an analog multiplexer.
The analog multiplexer can be controlled via I²C by the |LTC-18| (7-bit address: 0x4C). In order to ensure fast settling times after switching the
multiplexer input, the output signal of the multiplexer is buffered by an operational amplifier. Finally the analog voltage of the selected sensor
is measured on the GPIO1 pin of the |LTC-18|.

^^^^^^^^^^^^^^^
On-board EEPROM
^^^^^^^^^^^^^^^

The primary unit as well as the secondary unit of the foxBMS BMS-Slave board is equipped with an EEPROM IC (IC801).
The EEPROM for example can be used for storing data such as calibration values. Similar to the analog multiplexers, the EEPROM device is connected to the I²C bus of the |LTC-18| (7-bit address: 0x50).

^^^^^^^^^^^^^^^^^^^^^^^^^^^^^^^^^^^
On-board Ambient Temperature Sensor
^^^^^^^^^^^^^^^^^^^^^^^^^^^^^^^^^^^

For an additional monitoring of the ambient temperature an on-board temperature sensor is used. This temperature sensor can be read by the |LTC-18| via
the I²C bus (7-bit address: 0x48). It is possible to program an alert temperature. Once the measured temperature reaches this alert temperature the alert pin
of the IC is set to a logic low level. Currently this signal is not used on the BMS-Slave board, but it is accessible on the connector X404.

^^^^^^^^^^^^^^^^^^^^^^^^^^^^^
Additional Inputs and Outputs
^^^^^^^^^^^^^^^^^^^^^^^^^^^^^

Several additional analog and digital inputs and outputs are provided on the BMS-Slave board via pin headers. Each 16 analog inputs are provided on
connector X400 (primary) and X401 (secondary). The pinout for the connectors for the primary and secondary unit is identical and is described in :numref:`table %s <analog_in_connector_18>`.

.. _analog_in_connector_18:

.. table:: Connector for analog inputs

    ====   =============    ============    =============================
    Pin    Signal           Direction       Description
    ====   =============    ============    =============================
    1      ANALOG-IN_0      Input           Analog input 0
    2      ANALOG-IN_1      Input           Analog input 1
    3      ANALOG-IN_2      Input           Analog input 2
    4      ANALOG-IN_3      Input           Analog input 3
    5      ANALOG-IN_4      Input           Analog input 4
    6      ANALOG-IN_5      Input           Analog input 5
    7      ANALOG-IN_6      Input           Analog input 6
    8      ANALOG-IN_7      Input           Analog input 7
    9      ANALOG-IN_8      Input           Analog input 8
    10     ANALOG-IN_9      Input           Analog input 9
    11     ANALOG-IN_10     Input           Analog input 10
    12     ANALOG-IN_11     Input           Analog input 11
    13     ANALOG-IN_12     Input           Analog input 12
    14     ANALOG-IN_13     Input           Analog input 13
    15     ANALOG-IN_14     Input           Analog input 14
    16     ANALOG-IN_15     Input           Analog input 15
    17     +3.0V_VREF2      Output          |LTC-18| 3.0V voltage reference
    18     FUSED_VBAT-      Output          GND
    ====   =============    ============    =============================

Each 8 analog inputs are connected to an analog multiplexer. The analog multiplexers can be controlled via I²C by the
|LTC-18| (7-bit addresses: 0x4D and 0x4E). In order to ensure fast settling times after switching the multiplexer input, the output signals of the
multiplexers are buffered by operational amplifiers. Finally the analog voltage of the selected sensor can be measured on the GPIO2 pin of the |LTC-18|.

Each 8 digital inputs/outputs are provided on the connectors X402 (primary) and X403 (secondary). The pinout for the connectors for the primary
and secondary unit is identical and is described in :numref:`table %s <digital_io_connector_18>`.

.. _digital_io_connector_18:

.. table:: Connector for digital IOs

    ====   =============    ============    =============================
    Pin    Signal           Direction       Description
    ====   =============    ============    =============================
    1      DIGITAL-IO_0     Input/Output    Digital input/output 0
    2      DIGITAL-IO_1     Input/Output    Digital input/output 1
    3      DIGITAL-IO_2     Input/Output    Digital input/output 2
    4      DIGITAL-IO_3     Input/Output    Digital input/output 3
    5      DIGITAL-IO_4     Input/Output    Digital input/output 4
    6      DIGITAL-IO_5     Input/Output    Digital input/output 5
    7      DIGITAL-IO_6     Input/Output    Digital input/output 6
    8      +5.0V_VREG       Output          |LTC-18| 5.0V regulated voltage
    9      FUSED_VBAT-      Output          GND
    ====   =============    ============    =============================

Each 8 digital inputs/outputs are connected to an I²C controlled port expander (7-bit address: 0x20). The direction of the inputs/outputs as well as the logic
levels on the pins can be selected by register settings. Each of the 8 digital inputs/outputs has a discrete pull up resistor that for example can be used
for directly connecting a tactile switch.

^^^^^^^^^^^^^^^^^^^^^^^^^^^^^
isoSPI Daisy Chain Connection
^^^^^^^^^^^^^^^^^^^^^^^^^^^^^

The data transmission between the slaves and between the slaves and the basic board takes place using the isoSPI interface. The isoSPI signals are input/output on
the connectors X500/X501 (primary) and X502/X503 (secondary). The isoSPI ports are bidirectional, that means they can be used in forward and reverse direction.
The isoSPI connections are isolated galvanically using pulse transformers (TR1400). The voltage amplitude of the differential signal can be adjusted
by setting resistors (see section :ref:`hw_slave_daisy_current_18cell`).

The pinout of the isoSPI connectors is described in :numref:`table %s <daisy_input_connectors_18>` and :numref:`table %s <daisy_output_connectors_18>`.

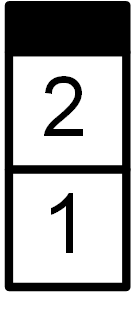
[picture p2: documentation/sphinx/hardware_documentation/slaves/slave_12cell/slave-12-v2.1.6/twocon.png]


.. _daisy_input_connectors_18:

.. table:: isoSPI Daisy Chain Input Connectors

   =============  ==============================
   Connector Pin  Daisy Chain
   =============  ==============================
   1              IN+ (Primary/Secondary |LTC-18|)
   2              IN- (Primary/Secondary |LTC-18|)
   =============  ==============================

.. _daisy_output_connectors_18:

.. table:: isoSPI Daisy Chain Output Connectors

   =============  ==============================
   Connector Pin  Daisy Chain
   =============  ==============================
   1              OUT+ (Primary/Secondary |LTC-18|)
   2              OUT- (Primary/Secondary |LTC-18|)
   =============  ==============================

^^^^^^^^^^^^^^^^^^^^^^^^^^^
Hardware Settings / Options
^^^^^^^^^^^^^^^^^^^^^^^^^^^

Software Timer
""""""""""""""

The internal software timer of the |LTC-18| can be enabled/disabled by a dedicated external pin (SWTEN, pin 36 of the |LTC-18|). In order to support all features, the foxBMS
BMS-Slave board offers a possibility to switch the software timer. The software timer is enabled in the standard configuration, which means pin 36 is
pulled to VREG via a zero-ohm resistor (R1407). The timer can be disabled by removing the resistor R1407 and placing a zero-ohm resistor to R1406.

.. _hw_slave_daisy_current_18cell:

Daisy Chain Communication Current
"""""""""""""""""""""""""""""""""

The daisy chain communication current can be set by the resistors R1400 and R1402. The default value is 820Ω for R1402 and 1.2kΩ for R1400.
This values result in a bias current of approx. 1mA and a differential signal amplitude of 1.18V. Theses values are suitable for high noise environments with
cable lengths of over 50m. For more information please have a look at the |LTC-18| datasheet.

Status LED
""""""""""

The status LEDs LD1400 show the current mode of each, the primary and secondary |LTC-18|. The LED is on in STANDBY, REFUP or MEASURE mode, whereas
the LED is off in SLEEP mode. The LED can be disabled by removing the resistor R1403 next to the LED.

GPIO Extension Connector
""""""""""""""""""""""""

The internal GPIO lines 1 to 5 of the primary or secondary |LTC-18| can be connected to the GPIO extension pin header X404 via optional zero-ohm resistors. In the
standard configuration these resistors are not placed. Of course it is possible to place each both resistors for a parallel connection of the internal
signals to the GPIO extension connector. For more information see the corresponding page of the schematics. The placement of the resistors and the resulting connection
is shown in :numref:`table %s <gpio_connector_18>`.

.. _gpio_connector_18:

.. table:: GPIO extension connector

    ====   =====================    ============================
    GPIO   connect to pin header    connect to internal function
    ====   =====================    ============================
    1      R1408                    R1409 (default)
    2      R1410                    R1411 (default)
    3      R1412                    R1413 (default)
    4      R1414                    R1415 (default)
    5      R1416                    R1417 (default)
    ====   =====================    ============================

The pinout of the extension connector X404 is described in :numref:`table %s <extension_connector_18>`.

.. _extension_connector_18:

.. table:: Extension connector

    ====   ====================   ============    =========================================
    Pin    Signal                 Direction       Description
    ====   ====================   ============    =========================================
    1      +3.0V_VREF2_0          Output          Primary |LTC-18| 3.0V reference voltage 2
    2      +3.0V_VREF2_1          Output          Secondary |LTC-18| 3.0V reference voltage 2
    3      +5.0V_VREG_0           Output          Primary |LTC-18| 5.0V regulated voltage
    4      +5.0V_VREG_1           Output          Secondary |LTC-18| 5.0V regulated voltage
    5      PRIMARY-GPIO1-OPT      Input/Output    Primary |LTC-18| GPIO1
    6      SECONDARY-GPIO1-OPT    Input/Output    Secondary |LTC-18| GPIO1
    7      PRIMARY-GPIO2-OPT      Input/Output    Primary |LTC-18| GPIO2
    8      SECONDARY-GPIO2-OPT    Input/Output    Secondary |LTC-18| GPIO2
    9      PRIMARY-GPIO3-OPT      Input/Output    Primary |LTC-18| GPIO3
    10     SECONDARY-GPIO3-OPT    Input/Output    Secondary |LTC-18| GPIO3
    11     PRIMARY-GPIO4-OPT      Input/Output    Primary |LTC-18| GPIO4
    12     SECONDARY-GPIO4-OPT    Input/Output    Secondary |LTC-18| GPIO4
    13     PRIMARY-GPIO5-OPT      Input/Output    Primary |LTC-18| GPIO5
    14     SECONDARY-GPIO5-OPT    Input/Output    Secondary |LTC-18| GPIO5
    15     PRIMARY-WDT            Output          Primary |LTC-18| watchdog output
    16     SECONDARY-WDT          Output          Secondary |LTC-18| watchdog output
    17     PRIMARY-TEMP-ALERT     Output          Primary board temp. sensor alarm output
    18     SECONDARY-TEMP-ALERT   Output          Secondary board temp. sensor alarm output
    19     FUSED_VBAT-            Output          GND
    20     FUSED_VBAT-            Output          GND
    ====   ====================   ============    =========================================

The GPIO lines 6 to 9 are wired to the connector X405 permanently. There is no internal function for this GPIO lines. The pinout of the extension
connector X405 is described in :numref:`table %s <gpio2_connector>`.

.. _gpio2_connector:

.. table:: Additional GPIO extension connector

    ====   ================       ============    ======================
    Pin    Signal                 Direction       Description
    ====   ================       ============    ======================
    1      PRIMARY-GPIO6          Input/Output    Primary |LTC-18| GPIO6
    2      SECONDARY-GPIO6        Input/Output    Secondary |LTC-18| GPIO6
    3      PRIMARY-GPIO7          Input/Output    Primary |LTC-18| GPIO7
    4      SECONDARY-GPIO7        Input/Output    Secondary |LTC-18| GPIO7
    5      PRIMARY-GPIO8          Input/Output    Primary |LTC-18| GPIO8
    6      SECONDARY-GPIO8        Input/Output    Secondary |LTC-18| GPIO8
    7      PRIMARY-GPIO9          Input/Output    Primary |LTC-18| GPIO9
    8      SECONDARY-GPIO9        Input/Output    Secondary |LTC-18| GPIO9
    ====   ================       ============    ======================

^^^^^^^^^^^^^^^^^^^^^^^^^^^
External Isolated DC-Supply
^^^^^^^^^^^^^^^^^^^^^^^^^^^

It is possible to supply the |BMS-Slave| by an external DC power supply with a voltage range of 8V to 24V. The DC input is protected against reverse voltage and over-current (with a 1.25A fuse).
The external DC supply has to be connected on connector X1001 or X1002 (both connectors are in parallel for daisy chaining the supply). The pinout of the connectors X1001 and X1002 is shown
in :numref:`table %s <dc_connector_18>`.



.. _dc_connector_18:

.. table:: External DC supply connector

    ====   =============    ============    ========================
    Pin    Signal           Direction       Description
    ====   =============    ============    ========================
    1      DC+              Input           positive supply terminal
    2      DC-              Input           negative supply terminal
    ====   =============    ============    ========================

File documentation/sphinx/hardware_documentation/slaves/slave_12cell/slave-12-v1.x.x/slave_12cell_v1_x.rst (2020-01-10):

.. include:: ../../../../macros.rst

.. _HW_SLAVE_12CELL_V1_X:

========================
Slave 12-Cell ``v1.x.x``
========================

--------
Overview
--------

.. note::

   The following description only applies for the |BMS-Slave| hardware versions ``1.x.x``.

.. hint::

   All connector pinouts described below follow the :ref:`sec-connector-convention`.

^^^^^^^^^^^^^
Block Diagram
^^^^^^^^^^^^^

A block diagram of a |BMS-Slave| is shown below:

.. _slave_diagram:


   Block diagram of a |BMS-Slave|
..

The connector indicated as ``Daisy Chain`` in :numref:`fig. %s <foxbmsfront_quickstart>` must be used on the |BMS-Master|. Its layout is described in the table below:



.. _master_daisy_connector:

.. table:: |BMS-Master| Daisy Chain Connector

   ====   ======================
   Pin    Signal
   ====   ======================
   1      NC
   2      OUT+ (Secondary |LTC-old|)
   3      OUT- (Secondary |LTC-old|)
   4      NC
   5      NC
   6      OUT+ (Primary |LTC-old|)
   7      OUT- (Primary |LTC-old|)
   8      NC
   9      NC
   10     NC
   11     NC
   12     NC
   13     NC
   14     NC
   15     NC
   16     NC
   ====   ======================

.. note::
   This connector pin out is only valid for use of a foxBMS Master Interface board for the |LTC-old| monitoring IC.

On the |BMS-Slave|, the connectors indicated as ``Primary Daisy Chain connector`` and ``Secondary Daisy Chain connector`` in :numref:`fig. %s <slave_diagram>` must be used. Their layout is described in :numref:`table %s <primary_daisy_connector>`.



.. _primary_daisy_connector:

.. table:: Primary Daisy Chain Connector

   =============  ============
   Connector Pin  Daisy Chain
   =============  ============
   1              IN+ (Primary |LTC-old|)
   2              OUT- (Primary |LTC-old|)
   3              IN- (Primary |LTC-old|)
   4              OUT+ (Primary |LTC-old|)
   =============  ============

The OUT+ and OUT- pins of the |BMS-Master| go to the IN+ and IN- pins of the |BMS-Slave|.  A cable with a receptable on both ends must be crimped correctly to make the connection.

In case a second |BMS-Slave| must be connected to the daisy chain, the OUT+ and OUT- pins of the first |BMS-Slave| must be connected to the IN+ and IN- pins of the second |BMS-Slave|.

--------------------------------------
Cell Voltage Connector on the |slaves|
--------------------------------------

The connector indicated as ``Battery cell connector (16 pin)`` in :numref:`fig. %s <slave_diagram>` has two purposes:

 * Supply of the |BMS-Slave|
 * Input of the cell voltages to the |LTC-old| monitoring chip

The layout of the connector is described in :numref:`table %s <cell_voltage_connector>`. Up to 12 battery cells can be connected in series, between VBAT+ and VBAT-. The |BMS-Slave| is supplied by VBAT+ and VBAT-. The total voltage of all cells in series must be between 11V and 55V (see [ltc_datasheet6804]_ and [ltc_datasheet6811]_). 0- correspond to the negative pole of cell 0, 0+ to the positive pole of cell 0, 1- correspond to the negative pole of cell 1, 1+ to the positive pole of cell 1 and so one till 11+, the positive pole of cell 11. As the cells are connected in series, the positive pole of one cell is connected to the negative pole of the next cell: 0+ to 1-, 1+ to 2+ and so on. The poles should be connected to the cell voltage connector as shown in :numref:`table %s <cell_voltage_connector>`.

If less than 12 battery cells are used, information on how to connect them can be found |LTC-old| datasheets ([ltc_datasheet6804]_ and [ltc_datasheet6811]_).

.. _cell_voltage_connector_layout:


.. _cell_voltage_connector:

.. table:: |BMS-Slave|, battery cell voltage connector

   =============  ============
   Connector Pin  Battery Cell
   =============  ============
   1              VBAT-
   2              0+ (1-)
   3              2+ (3-)
   4              4+ (5-)
   5              6+ (7-)
   6              8+ (9-)
   7              10+ (11-)
   8              NC
   9              0-
   10             1+ (2-)
   11             3+ (4-)
   12             5+ (6-)
   13             7+ (8-)
   14             9+ (10-)
   15             11+
   16             VBAT+
   =============  ============

In case no cells are available, they can be simulated with a series of voltage divider. A voltage supplied of 30V should be used and 12 resistors with the same value connected in series between the positive and negative connectors of the voltage supply. The positive connector is linked to VBAT+, the negative connector to VBAT- and each pole of a resistor correspond to  a pole of a battery cell. The voltage of 30V  is chosen so that every simulated cell voltage lies around 2.5V, which lies in the center of the safe operating area defined by default in the |foxbms| software.

------------------------------------------
Cell Temperature Connector on the |slaves|
------------------------------------------

The connector indicated as ``Temperature sensor connector (24 pin)`` in :numref:`fig. %s <slave_diagram>` is used to connect temperature sensors to the |BMS-Slave|.

:numref:`Table %s <cell_temperature_connector>` describes the temperature connector.

.. _cell_temperature_connector_layout:


.. _cell_temperature_connector:

.. table:: Temperature Sensor Connector

   =============  ==================
   Connector Pin  Temperature Sensor
   =============  ==================
   1, 24          T-Sensor 0
   2, 23          T-Sensor 1
   3, 22          T-Sensor 2
   4, 21          T-Sensor 3
   5, 20          T-Sensor 4
   6, 19          T-Sensor 5
   =============  ==================

:numref:`Fig. %s <temp_sensor>` shows the functioning of a temperature sensor.

.. _temp_sensor:


   Temperature sensor circuit.

The voltage VREF (3V) is generated by the |LTC-old| chip. A temperature-dependent resistor must be added to build a voltage divider (drawn as a dashed line in :numref:`fig. %s <temp_sensor>`, not delivered with the |BMS-Slaves|). The resulting voltage is measured by the |LTC-old| chip. Knowing the temperature dependence of the resistor, the relation between measured voltage and temperature can be determined.

A function is present in the code to make the conversion between measured voltage and temperature. It must be adapted to the temperature sensor used. This is described in the software FAQ (:ref:`sw_faq_temperature_sensors`). In case temperatures are read incorrectly, this function is the first step to verify.

It must be noted that if no sensor is connected, 3V are measured. For the quickstart guide, no sensor needs to be connected: the conversion function is simply a multiplication by 10, so 30°C will be displayed, which again lies in the center of the safe operating area defined by default in the |foxbms| software.

If sensors are added, they must be connected between the connector pins corresponding to the sensors 0 to 5, as shown in :numref:`table %s <cell_temperature_connector>`.

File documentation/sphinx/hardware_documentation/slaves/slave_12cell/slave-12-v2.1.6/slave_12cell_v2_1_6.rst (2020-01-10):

.. include:: ../../../../macros.rst

.. _HW_SLAVE_12CELL_V2_1_6:

==================================
Slave 12-Cell ``v2.1.6 and above``
==================================

--------
Overview
--------

.. important::

   The following description only applies for the 12-cell |BMS-Slave| hardware versions ``2.1.6`` and above.

   The documentation for the 12-cell |BMS-Slave| version ``2.1.2`` to ``2.1.5`` can be found :ref:`here <hw_slave_12cell_v2_1_2>`.

   The documentation for the 12-cell |BMS-Slave| version ``2.0.3`` to ``2.1.1`` can be found :ref:`here <hw_slave_12cell_v2_0_3>`.

   The documentation for the 12-cell |BMS-Slave| version ``1.x.x`` can be found :ref:`here <hw_slave_12cell_v1_x>`.

.. hint::

   All connector pinouts described below follow the :ref:`sec-connector-convention`.

^^^^^^^^^^^^^
Block Diagram
^^^^^^^^^^^^^

A block diagram of the |BMS-Slave| is shown in :numref:`fig. %s <BMS-Slave_12cell_v2.1.6>`

.. _BMS-Slave_12cell_v2.1.6:
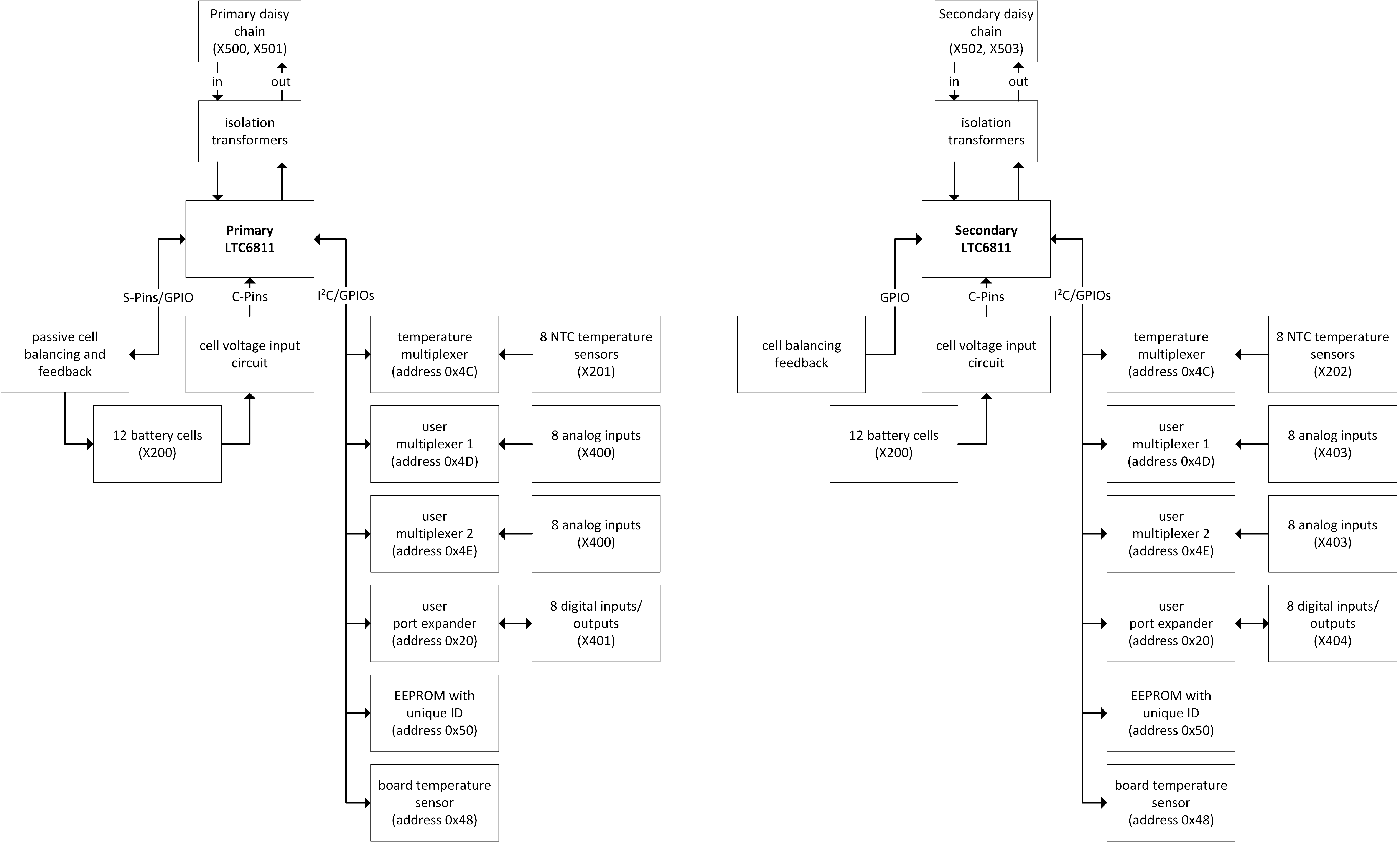
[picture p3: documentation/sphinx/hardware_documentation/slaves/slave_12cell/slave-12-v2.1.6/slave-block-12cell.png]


   |BMS-Slave| 12-Cell Block Diagram
..

^^^^^^^^^^^^^^^^^^^^^^^^^^
Schematic and Board Layout
^^^^^^^^^^^^^^^^^^^^^^^^^^

More information about the board schematic and layout files can be found in section :ref:`hardware_design_resources`.

^^^^^^^^^^^^^^^^^^^^^
Mechanical Dimensions
^^^^^^^^^^^^^^^^^^^^^

The size of the foxBMS Slave PCB is 160x100mm. A ``*.step`` file of the PCB can be found in section :ref:`hardware_design_resources`.

---------
Functions
---------

The following general description applies to both, the primary and the secondary of the |BMS-Slave|. If there are any differences in hardware between the primary and the secondary they will be marked as such.

^^^^^^^^^^^^^^^^^^^^^^^^
Cell Voltage Measurement
^^^^^^^^^^^^^^^^^^^^^^^^

The cell voltage sense lines are input on the connector X200. The pinout is described in :numref:`table %s <cell_sense_connector_v2.1.6>`.



.. _cell_sense_connector_v2.1.6:

.. table:: Cell voltage sense connector

    ====   =============    ============    =================================
    Pin    Signal           Direction       Description
    ====   =============    ============    =================================
    1      VBAT-            Input           Battery module negative terminal
    2      CELL_0+          Input           Cell 0 positve terminal
    3      CELL_2+          Input           Cell 2 positve terminal
    4      CELL_4+          Input           Cell 4 positve terminal
    5      CELL_6+          Input           Cell 6 positve terminal
    6      CELL_8+          Input           Cell 8 positve terminal
    7      CELL_10+         Input           Cell 10 positve terminal
    8      VBAT+            Input           Battery module positive terminal
    9      NC               --              --
    10     NC               --              --
    11     NC               --              --
    12     NC               --              --
    13     CELL_0-          Input           Cell 0 negative terminal
    14     CELL_1+          Input           Cell 1 positive terminal
    15     CELL_3+          Input           Cell 3 positive terminal
    16     CELL_5+          Input           Cell 5 positive terminal
    17     CELL_7+          Input           Cell 7 positive terminal
    18     CELL_9+          Input           Cell 9 positive terminal
    19     CELL_11+         Input           Cell 11 positive terminal
    20     NC               --              --
    21     NC               --              --
    22     NC               --              --
    23     NC               --              --
    24     NC               --              --
    ====   =============    ============    =================================

Each of these lines is protected by a 250mA fast fuse surface mount device (F301 - F313) on the board except of the VBAT+ and VBAT- lines which are protected by a value of 500mA (F300 and F314). This is especially important for a test environment. The VBAT+ and VBAT- connections are used for the internal power supply of the |BMS-Slave| board. If the battery module does not contain these separate wires to the positive and negative module terminals, the solder jumpers SJ401 and SJ402 have to be shorted. In this case the power required by the |BMS-Slave| will be supplied through the sense lines CELL_0- and CELL_11+. Running the |BMS-Slave| in this configuration could result in cell measurement errors due to voltage drop over the sense wires.

The cell input lines are filtered by a grounded or differential capacitor filter: both possibilities are provided on the PCB of the |BMS-Slave|. More information on the corner frequency of this filtering can be found in the schematic. The grounded capacitor filter should be used in environments affected with a high noise as it offers a high level of battery voltage ripple rejection. The differential capacitor filter can be used when noise is less occurrent or the design is subjected to cost optimization.

^^^^^^^^^^^^^^^^^^^^^^
Passive Cell Balancing
^^^^^^^^^^^^^^^^^^^^^^

The passive balancing circuit is realized by a parallel connection of two 68Ω discharge resistors that can be connected to each single cell in parallel. The MOSFET switches (T1500 - T1511) that control the connection to the cells are controlled by the primary |LTC| monitoring IC. The secondary |LTC| does not support balancing. The resistor value of 2x 68Ω results in a balancing current of about 100mA at a cell voltage of 3.6V. This current results in a power dissipation of about 0.36W per balancing channel (at 3.6V).

^^^^^^^^^^^^^^^^^^^^^^^^^^^^^^
Global Cell Balancing Feedback
^^^^^^^^^^^^^^^^^^^^^^^^^^^^^^

In order to check the proper function of the balancing process or to detect a malfunction in the balancing circuit, a global balancing feedback signal is connected to the |LTC|. This allows the |BMS-Master| to check wheather any balancing action is currently taking place. The feedback signal is connected to the GPIO3 of the |LTC|. The signal remains in a logic zero state until any balancing action on at least one cell in the module starts.

.. _slave_voltage_divider_v2.1.6:

^^^^^^^^^^^^^^^^^^^^^^^^^^^^^^
Temperature Sensor Measurement
^^^^^^^^^^^^^^^^^^^^^^^^^^^^^^

The cell temperature sensors are connected to the connectors X201 (primary) and X202 (secondary). The pinout is identical for the primary and secondary and is described in :numref:`table %s <temp_sense_connector_v2.1.6>`.



.. _temp_sense_connector_v2.1.6:

.. table:: Temperature sensor connector

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

Standard 10kΩ NTC resistors (e.g., Farnell-Nr. 1299926) are recommended for use. When using other values than these, the series resistors (R100-1/2 to R107-1/2) on the board may have to be adjusted. Please note that the accuracy of the internal voltage reference VREF2 decreases heavily with a load of over 3mA. Using 8x 10kΩ NTC resistors with the corresponding 10kΩ series resistors results in a current of 1.2mA (at 20°C) which is drawn from VREF2.

Each of the 8 temperture sensors are connected to an analog multiplexer. The analog multiplexer can be controlled via I²C by the |LTC| (7-bit address: 0x4C). In order to ensure fast settling times after swiching the multiplexer input, the output signal of the multiplexer is buffered by an operational amplifier. Finally the analog voltage of the selected sensor is measured on the GPIO1 pin of the |LTC|.

^^^^^^^^^^^^^^^
On-board EEPROM
^^^^^^^^^^^^^^^

.. attention::

   The |BMS-Slave| hardware versions ``2.1.0`` and above use a different EEPROM IC (ST M24M02) than all other previous hardware versions.

The primary as well as the secondary unit of the |BMS-Slave| board is equipped with an EEPROM (IC800-1/2). The EEPROM for example can be used for storing data such as calibration values or minimum and maximum temperatures seen by the module during its lifetime. Similar to the analog multiplexers, the EEPROM device is connected to the I²C bus of the |LTC| (7-bit address: 0x50).

^^^^^^^^^^^^^^^^^^^^^^^^^^^^^^^^^^^
On-board Ambient Temperature Sensor
^^^^^^^^^^^^^^^^^^^^^^^^^^^^^^^^^^^

For an additional monitoring of the ambient temperature an on-board temperature sensor is used. This temperature sensor can be read by the |LTC| via the I²C bus (7-bit address: 0x48). It is possible to program an alert temperature level. Once the measured temperature reaches this alert temperature level, the alert pin of the IC is set to a logic low level. Currently, this signal is not used on the |BMS-Slave| board, but it is accessible on the connector X402.

^^^^^^^^^^^^^^^^^^^^^^^^^^^^^
Additional Inputs and Outputs
^^^^^^^^^^^^^^^^^^^^^^^^^^^^^

Several additional analog and digital inputs and outputs are provided on the |BMS-Slave| board via pin headers. Each 16 analog inputs are provided on connector X400 (primary) and X403 (secondary). The pinout for the connectors for the primary and secondary unit is identical and is described in :numref:`table %s <analog_in_connector_v2.1.6>`.

.. _analog_in_connector_v2.1.6:

.. table:: Connector for analog inputs

    ====   =============    ============    =============================
    Pin    Signal           Direction       Description
    ====   =============    ============    =============================
    1      ANALOG-IN_0      Input           Analog input 0
    2      ANALOG-IN_1      Input           Analog input 1
    3      ANALOG-IN_2      Input           Analog input 2
    4      ANALOG-IN_3      Input           Analog input 3
    5      ANALOG-IN_4      Input           Analog input 4
    6      ANALOG-IN_5      Input           Analog input 5
    7      ANALOG-IN_6      Input           Analog input 6
    8      ANALOG-IN_7      Input           Analog input 7
    9      ANALOG-IN_8      Input           Analog input 8
    10     ANALOG-IN_9      Input           Analog input 9
    11     ANALOG-IN_10     Input           Analog input 10
    12     ANALOG-IN_11     Input           Analog input 11
    13     ANALOG-IN_12     Input           Analog input 12
    14     ANALOG-IN_13     Input           Analog input 13
    15     ANALOG-IN_14     Input           Analog input 14
    16     ANALOG-IN_15     Input           Analog input 15
    17     +3.0V_VREF2      Output          |LTC| 3.0V voltage reference
    18     FUSED_VBAT-      Output          GND
    ====   =============    ============    =============================

Each 8 analog inputs are connected to an analog multiplexer. The analog multiplexers can be controlled via I²C by the |LTC| (7-bit addresses: 0x4D and 0x4E). In order to ensure fast settling times after switching the multiplexer input, the output signals of the multiplexers are buffered by operational amplifiers. Finally the analog voltage of the selected sensor can be measured on the GPIO2 pin of the |LTC|.

Each 8 digital inputs/outputs are provided on the connectors X401 (primary) and X404 (secondary). The pinout for the connectors for the primary and secondary unit is identical and is described in :numref:`table %s <digital_io_connector_v2.1.6>`.

.. _digital_io_connector_v2.1.6:

.. table:: Connector for digital IOs

    ====   =============    ============    =============================
    Pin    Signal           Direction       Description
    ====   =============    ============    =============================
    1      DIGITAL-IO_0     Input/Output    Digital input/output 0
    2      DIGITAL-IO_1     Input/Output    Digital input/output 1
    3      DIGITAL-IO_2     Input/Output    Digital input/output 2
    4      DIGITAL-IO_3     Input/Output    Digital input/output 3
    5      DIGITAL-IO_4     Input/Output    Digital input/output 4
    6      DIGITAL-IO_5     Input/Output    Digital input/output 5
    7      DIGITAL-IO_6     Input/Output    Digital input/output 6
    8      +5.0V_VREG       Output          |LTC| 5.0V regulated voltage
    9      FUSED_VBAT-      Output          GND
    ====   =============    ============    =============================

Each 8 digital inputs/outputs are connected to an I²C controlled port expander (7-bit address: 0x20). The direction of the inputs/outputs as well as the logic levels on the pins can be selected by register settings. Each of the 8 digital inputs/outputs has a discrete pull up resistor that for example can be used for directly connecting a tactile switch.

^^^^^^^^^^^^^^^^^^^^^^^^^^^^^
isoSPI Daisy Chain Connection
^^^^^^^^^^^^^^^^^^^^^^^^^^^^^

The data transmission between the slaves and between the slaves and the basic board takes place using the isoSPI interface. The isoSPI signals are input on the connectors X500 (primary) and X502 (secondary). The isoSPI signals for daisy-chaining are output on the connectors X501 (primary) and X503 (secondary). The isoSPI connections are isolated galvanically using pulse transformers (TR1400-1/2). The voltage amplitude of the differential signal can be adjusted by setting resistors (see paragraph :ref:`hw_slave_daisy_current_12cell_v2.1.6`).

The pinout of the isoSPI connectors is described in :numref:`table %s <daisy_input_connectors_v2.1.6>` and :numref:`table %s <daisy_output_connectors_v2.1.6>`.



.. _daisy_input_connectors_v2.1.6:

.. table:: isoSPI Daisy Chain Input Connectors

   =============  ==============================
   Connector Pin  Daisy Chain
   =============  ==============================
   1              IN+ (Primary/Secondary |LTC|)
   2              IN- (Primary/Secondary |LTC|)
   =============  ==============================

.. _daisy_output_connectors_v2.1.6:

.. table:: isoSPI Daisy Chain Output Connectors

   =============  ==============================
   Connector Pin  Daisy Chain
   =============  ==============================
   1              OUT+ (Primary/Secondary |LTC|)
   2              OUT- (Primary/Secondary |LTC|)
   =============  ==============================

^^^^^^^^^^^^^^^^^^^^^^^^^^^
Hardware Settings / Options
^^^^^^^^^^^^^^^^^^^^^^^^^^^

Software Timer
""""""""""""""

The internal software timer of the |LTC| can be enabled/disabled by a dedicated external pin (SWTEN, pin 36 of the |LTC|). In order to support all features, the |BMS-Slave| board offers a possibility to switch the software timer. The software timer is enabled in the standard configuration, which means pin 36 is pulled to VREG via a zero-ohm resistor (R221/R321). The timer can be disabled by removing the resistor R1402-1/2 and placing a zero-ohm resistor to R1403-1/2.

.. _hw_slave_daisy_current_12cell_v2.1.6:

Daisy Chain Communication Current
"""""""""""""""""""""""""""""""""

The daisy chain communication current can be set by the resistors R1419-1/2 and R1421-1/2. The default value is 820Ω for R14211/2 and 1.21kΩ for R1419-1/2. This values result in a bias current of approximately 1mA and a differential signal amplitude of 1.18V. Theses values are suitable for high noise environments with cable lengths of over 50m. More information can be found in the |LTC| datasheet.

Status LED
""""""""""

The status LEDs LD1400-1/2 show the current mode of each, the primary and secondary |LTC|. The LED is on in STANDBY, REFUP or MEASURE mode, whereas the LED is off in SLEEP mode. The LED can be disabled by removing the resistor R1407-1/2.

GPIO Extension Connector
""""""""""""""""""""""""

The internal GPIO lines of the primary or secondary |LTC| can be connected to the GPIO extension pin header X402 via optional zero-ohm resistors. In the standard configuration these resistors are not placed. Of course it is possible to place each both resistors for a parallel connection of the internal signals to the GPIO extension connector. The placement of the resistors and the resulting connection is shown in :numref:`table %s <gpio_connector_v2.1.6>`.

.. _gpio_connector_v2.1.6:

.. table:: GPIO extension connector

    ====   =====================    ============================
    GPIO   connect to pin header    connect to internal function
    ====   =====================    ============================
    1      R1405-1/2                R1406-1/2 (default)
    2      R1409-1/2                R1410-1/2 (default)
    3      R1412-1/2                R1413-1/2 (default)
    4      R1414-1/2                R1417-1/2 (default)
    5      R1418-1/2                R1420-1/2 (default)
    ====   =====================    ============================

The pinout of the extension connector X402 is described in :numref:`table %s <extension_connector_v2.1.6>`.

.. _extension_connector_v2.1.6:

.. table:: Extension connector

    ====   ====================   ============    =========================================
    Pin    Signal                 Direction       Description
    ====   ====================   ============    =========================================
    1      +3.0V_VREF2_0          Output          Primary |LTC| 3.0V reference voltage 2
    2      +3.0V_VREF2_1          Output          Secondary |LTC| 3.0V reference voltage 2
    3      +5.0V_VREG_0           Output          Primary |LTC| 5.0V regulated voltage
    4      +5.0V_VREG_1           Output          Secondary |LTC| 5.0V regulated voltage
    5      PRIMARY-GPIO1-OPT      Input/Output    Primary |LTC| GPIO1
    6      SECONDARY-GPIO1-OPT    Input/Output    Secondary |LTC| GPIO1
    7      PRIMARY-GPIO2-OPT      Input/Output    Primary |LTC| GPIO2
    8      SECONDARY-GPIO2-OPT    Input/Output    Secondary |LTC| GPIO2
    9      PRIMARY-GPIO3-OPT      Input/Output    Primary |LTC| GPIO3
    10     SECONDARY-GPIO3-OPT    Input/Output    Secondary |LTC| GPIO3
    11     PRIMARY-GPIO4-OPT      Input/Output    Primary |LTC| GPIO4
    12     SECONDARY-GPIO4-OPT    Input/Output    Secondary |LTC| GPIO4
    13     PRIMARY-GPIO5-OPT      Input/Output    Primary |LTC| GPIO5
    14     SECONDARY-GPIO5-OPT    Input/Output    Secondary |LTC| GPIO5
    15     PRIMARY-WDT            Output          Primary |LTC| watchdog output
    16     SECONDARY-WDT          Output          Secondary |LTC| watchdog output
    17     PRIMARY-TEMP-ALERT     Output          Primary board T-sensor alarm output
    18     SECONDARY-TEMP-ALERT   Output          Secondary board T-sensor alarm output
    19     FUSED_VBAT-            Output          GND
    20     FUSED_VBAT-            Output          GND
    ====   ====================   ============    =========================================

^^^^^^^^^^^^^^^^^^^^^^^^^^^
External Isolated DC-Supply
^^^^^^^^^^^^^^^^^^^^^^^^^^^

.. note::

   The external isolated DC-supply is only available in the |BMS-Slave| hardware versions ``2.1.0`` and above.

It is possible to supply the |BMS-Slave| by an external DC power supply with a voltage range of 8V to 24V. The DC input is protected against reverse voltage and over-current (with a 1.25A fuse). The external DC supply has to be connected on connector X1001 or X1002 (both connectors are in parallel for daisy chaining the supply). The pinout of the connectors X1001 and X1002 is shown in :numref:`table %s <dc_connector_v2.1.6>`.



.. _dc_connector_v2.1.6:

.. table:: External DC supply connector

    ====   =============    ============    ========================
    Pin    Signal           Direction       Description
    ====   =============    ============    ========================
    1      DC+              Input           positive supply terminal
    2      DC-              Input           negative supply terminal
    ====   =============    ============    ========================

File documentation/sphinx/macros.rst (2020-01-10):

:orphan:

.. -----------------------------------------------
.. General Documentation Macros
.. -----------------------------------------------
.. |version| replace:: ``1.6.3``
.. |version-hal| replace:: ``V1.7.4``
.. |version-cmsis| replace:: ``V2.6.2``
.. |version-freertos| replace:: ``V10.1.1``
.. |hw-version-master| replace:: ``1.0.6``
.. |hw-version-extension| replace:: ``1.0.5``
.. |hw-version-interface| replace:: ``1.9.4``
.. |hw-version-12-slave| replace:: ``2.1.7``
.. |hw-version-18-slave| replace:: ``1.1.5``
.. |timestamp| date:: %Y-%m-%d %H:%M:%S
.. |foxbms| replace:: foxBMS
.. |foxconda3| replace:: foxconda3
.. |doxygen| replace:: Doxygen

.. -----------------------------------------------
.. Hardware Documentation Macros
.. -----------------------------------------------
.. |LTC-old| replace:: LTC6804-1
.. |LTC| replace:: LTC6811-1
.. |LTC-18| replace:: LTC6813-1
.. |master| replace:: foxBMS Master Unit
.. |masters| replace:: foxBMS Master Units
.. |slave| replace:: foxBMS Slave Unit
.. |slaves| replace:: foxBMS Slave Units
.. |BMS-Master| replace:: BMS-Master Board
.. |BMS-Extension| replace:: BMS-Extension Board
.. |BMS-Interface| replace:: BMS-Interface Board
.. |BMS-Slave| replace:: BMS-Slave Board
.. |BMS-12-Slave| replace:: Slave 12-cell board
.. |BMS-18-Slave| replace:: Slave 18-cell board
.. |BMS-Slaves| replace:: BMS-Slave Boards
.. |primary| replace:: primary
.. |secondary| replace:: secondary
.. |MCU0| replace:: MCU0
.. |MCU1| replace:: MCU1
.. |CAN0| replace:: CAN0
.. |CAN1| replace:: CAN1

.. -----------------------------------------------
.. Software Module Name Macros
.. -----------------------------------------------
.. |mod_bms| replace:: ``bms`` module
.. |mod_sys| replace:: ``sys`` module
.. |mod_io| replace:: ``io`` module
.. |mod_contactor| replace:: ``contactor`` module
.. |mod_interlock| replace:: ``interlock`` module
.. |mod_can| replace:: ``can`` module
.. |mod_cansignal| replace:: ``cansignal`` module
.. |mod_ltc| replace:: ``ltc`` module
.. |mod_com| replace:: ``com`` module
.. |mod_uart| replace:: ``uart`` module
.. |mod_chksum| replace:: ``chksum`` module
.. |mod_sox| replace:: ``sox`` module
.. |mod_isoguard| replace:: ``isoguard`` module
.. |mod_bal| replace:: ``balancing`` module
.. |mod_diag| replace:: ``diag`` module
.. |mod_meas| replace:: ``measurement`` module
.. |mod_database| replace:: ``database`` module
.. |mod_bender| replace:: ``bender`` module
.. |mod_nvm| replace:: ``nvm`` module
.. |mod_nvmh| replace:: ``nvramhandler`` module
.. |mod_algo| replace:: ``algorithm`` module
.. |mod_adc| replace:: ``adc`` module
.. |mod_dma| replace:: ``dma`` module
.. |mod_foxmath| replace:: ``foxmath`` module
.. |mod_hwinfo| replace:: ``hwinfo`` module
.. |mod_vic| replace:: ``vic`` module
.. |mod_watchdog| replace:: ``watchdog`` module
.. |installer archive| replace:: ``foxconda-3.0.3-Windows-x86_64.exe``

.. -----------------------------------------------
.. Hardware-Software Quickcheck Macros
.. -----------------------------------------------
.. |eo| replace:: ``emergency off``
.. |il| replace:: ``interlock``
.. |pmc| replace:: ``plus main contactor``
.. |ppc| replace:: ``plus precharge contactor``
.. |mmc| replace:: ``minus main contactor``
.. |hear| replace:: **(H)**
.. |normal| replace:: Normal
.. |stdby| replace:: Standby

.. -----------------------------------------------
.. Variable Name Macros
.. -----------------------------------------------
.. |var_il| replace:: variable: ``ilck_interlock_state``
.. |var_co| replace:: variable: ``cont_contactor_states``
.. |var_bms_state| replace:: variable ``bms_state``

.. -----------------------------------------------
.. State Machine Macros
.. -----------------------------------------------
.. |req_normal| replace:: Request `Normal`-state via CAN
.. |req_stdby| replace:: Request `Standby`-state via CAN
.. -----------------------------------------------

.. |waf|            replace:: ``waf``

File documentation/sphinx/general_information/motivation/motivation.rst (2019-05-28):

.. include:: ../../macros.rst

.. _GENERAL_INFORMATION_MOTIVATION:

==========
Motivation
==========

What is |foxbms|?
-----------------

With |foxbms|, Fraunhofer IISB delivers the first generation of its open
source battery management system (BMS) research and development platform. The
|foxbms| platform is completely free and open, designed for a maximum of
flexibility, and comprehensively documented. It includes all necessary
hardware and software for potentially any kind of mobile and stationary
application that uses modern rechargeable electrochemical energy storage
systems (e.g., lithium-ion batteries, redox-flow batteries, supercapacitors):

 - |foxbms| Hardware: the schematics and the layout of all electronic boards
   are available for download and the design is based on commonly available
   components and devices, that do not require NDAs or confidentiality
   agreements.
 - |foxbms| Software: the software toolchain uses only own developed open
   source and free of charge components or free of charge third-party
   software, and the entire BMS source code is provided online with its own
   development environment and configuration files, thus enabling immediate
   use on Windows, Mac, and Linux operating systems.

What is |foxbms| designed for?
------------------------------

Experience gained from international research and development projects over
the last 15 years in the field of electrochemical energy storage systems at
Fraunhofer IISB has been implemented in the hardware and software of the
|foxbms| platform. It is designed to manage high-performance prototypes of
advanced and innovative lithium-ion battery systems of any size (i.e., from a
few cells up to several hundreds of kWh and kW), especially for systems
requiring the highest availability and safety levels.

The free and open source version of |foxbms| is not intended for immediate use
in commercial products as they have to meet specific standards and require
application-dependent certifications. In fact, |foxbms| is a safe research,
development, and test platform providing all functions for managing the
complexity and size of state-of-the-art electrochemical energy storage
systems.

Specific adaptions of |foxbms| can be ordered directly from Fraunhofer IISB or
can be jointly developed, for example for automotive, aviation, space,
submarine, industrial, and renewable energy storage applications.

Who is the intended audience?
-----------------------------

|foxbms| is a free and open BMS platform that can be used for developing and
testing products. The |foxbms| hardware and documentation are licensed under
the Creative Commons Attribution 4.0 International (CC BY 4.0) license. The
|foxbms| software is licensed under the BSD 3-Clause license. This means,
|foxbms| parts can be utilized unrestrictedly, including commercial use. The
|foxbms| platform addresses especially:

 - R&D and test engineers requiring a smart and powerful, well documented BMS
   platform
 - Engineering companies requiring a maintained and supported BMS for their
   developments
 - Small enterprises requiring a flexible and future proof BMS for developing
   their products
 - Large enterprises requiring a reliable and safe BMS for testing their
   prototypes
 - Research organizations requiring a simple and universal BMS development
   platform
 - Students looking for a free and open BMS software development toolchain

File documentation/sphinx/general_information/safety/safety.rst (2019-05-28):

.. include:: ../../macros.rst

.. _GENERAL_INFORMATION_SAFETY:

======
Safety
======

This document describes the hazard risk analysis and assessment done for the |foxbms| platform. The content of this document must be read and understood before any tests are done with the |foxbms| hardware. All physical quantities and units used in the document are SI based.

Hazard Risk Analysis and Assessment
-----------------------------------

The risk analysis and assessment was last performed in May 2017. Following persons were involved:

.. list-table::
   :header-rows: 1
   :widths: 15 85

   * - **Name**
     - **Responsibility**
   * - Vincent Lorentz
     - Global project Management
   * - Stéphane Koffel
     - Technical Project Management
   * - Martin Wenger
     - Hardware Development (BMS-Extension)
   * - Radu Schwarz
     - Hardware Development (BMS-Master)
   * - Sebastian Wacker
     - Hardware Development (BMS-Slave)
   * - Stefan Waldhör
     - Software Development
   * - Müsfik Akdere
     - Software Development
   * - Johannes Wachtler
     - Validation and Tests
   * - Markus Freund
     - Moderation

General Description of the |foxbms| Platform
--------------------------------------------

|foxbms| is a research and development platform aimed to be used to develop battery management systems (BMS) for rechargeable energy storage systems based on lithium-ion batteries (LIB) or comparable electrochemical rechargeable accumulator cells (e.g., other chemistries like lithium-sulfur, sodium-ion or even all-solid-state batteries), lithium-ion capacitors (LIC), electric double-layer capacitors (EDLC or supercapacitors). The lithium-ion battery packs or battery modules are a major source of hazards and are not part of the |foxbms| platform (see :numref:`fig. %s <general_information_safety_battery_system>`). The main purposes of the battery management system are charge monitoring and keeping the battery cells in their safe operating area to ensure optimal safety and the longest battery lifetime.

.. _general_information_safety_battery_system:


   |foxbms| in the battery system

For those tasks, the |foxbms| platform is equipped with measurement and control circuits (i.e., |BMS-Slaves|) to monitor the battery cells and to get information about their states. With this, the cell voltages, temperatures and overall battery pack current are measured, and kept in the safe operating area. The battery charge equalization (i.e., balancing) is controlled and fed back to the |master|. The setup of the system is shown in :numref:`fig. %s <general_information_safety_battery_system_block_diagram>`.

.. _general_information_safety_battery_system_block_diagram:


    Block diagram showing the typical topology of a battery system

The |foxbms| platform uses a passive balancing circuit based on the |LTC| multicell battery monitoring integrated circuit. The unique selling point of the |foxbms| platform is its virtually unlimited possibilities to be adapted the needs of the user.

Limits of the |foxbms| Platform
-------------------------------

The |foxbms| platform consists only of the |master| with the |slaves| and the provided computer software. It does not include battery cells, battery cell models, power contactors, current sensors, fuses, chargers, power supplies, ground fault detector.

The |master| and the |slaves| have a primary and a secondary side which are separated and galvanically isolated from each other.

The area of the use of |foxbms| must be free of hazardous materials like flammable gases, combustible dust or ignitable dust and fibers. The temperature should be around 20°C and may not exceed the battery cells restrictions given by the battery cell manufacturer (e.g., around 45°C to 60°C, depending on the battery cell chemistry). The operating and storage environment needs to be dry and free of static electricity with air humidity between 35% and 55%.
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

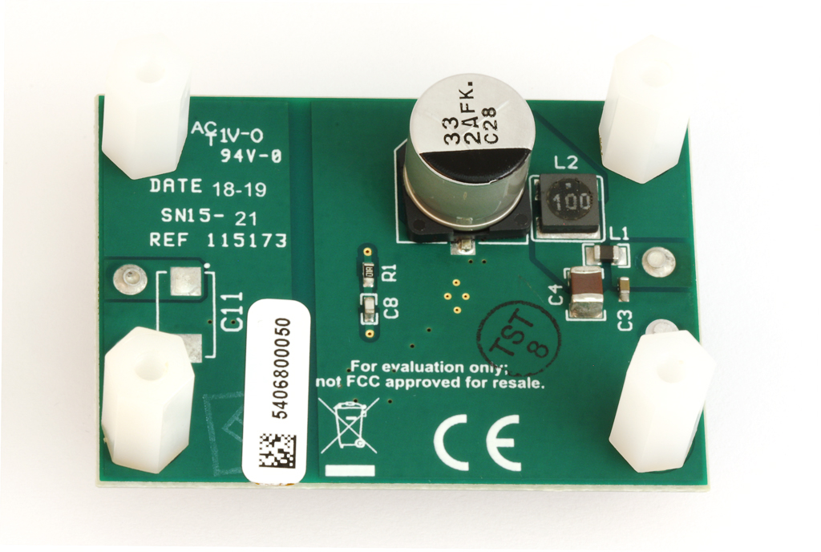
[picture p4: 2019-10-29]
hardware/datasheets/snvc233/LM5180EVM-S05 bottom side1.jpg

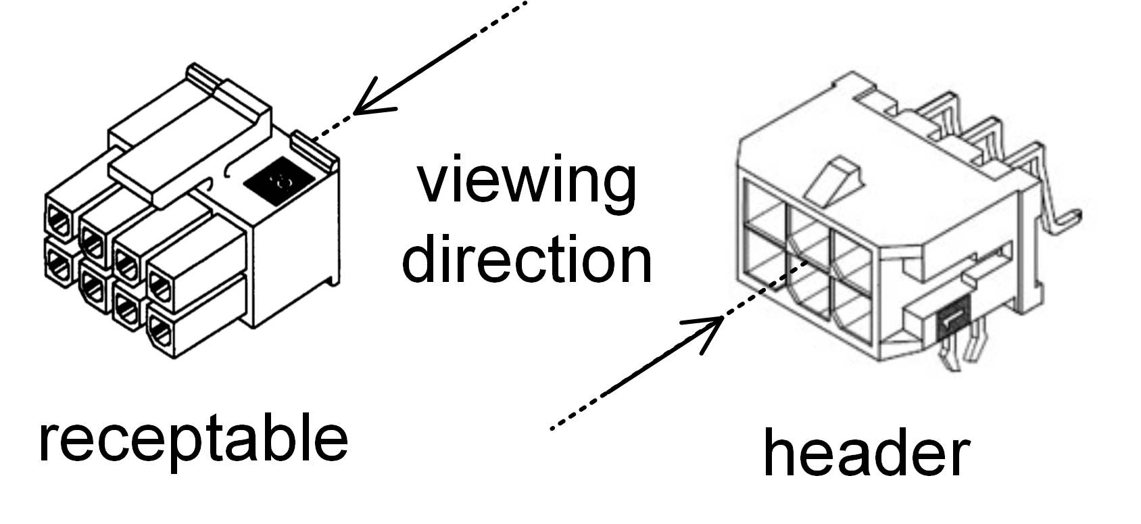
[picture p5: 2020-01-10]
documentation/sphinx/hardware_documentation/slaves/slave_12cell/slave-12-v2.1.6/viewing_direction.png

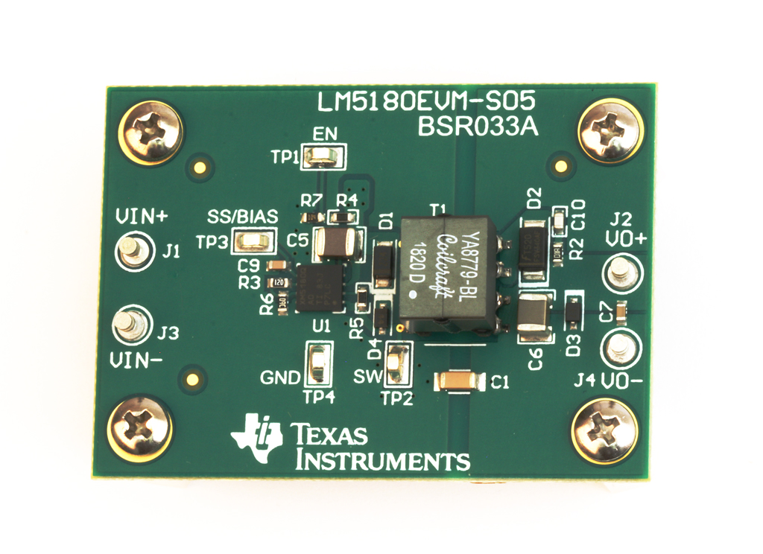
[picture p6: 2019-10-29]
hardware/datasheets/snvc233/LM5180 EVM top side.jpg

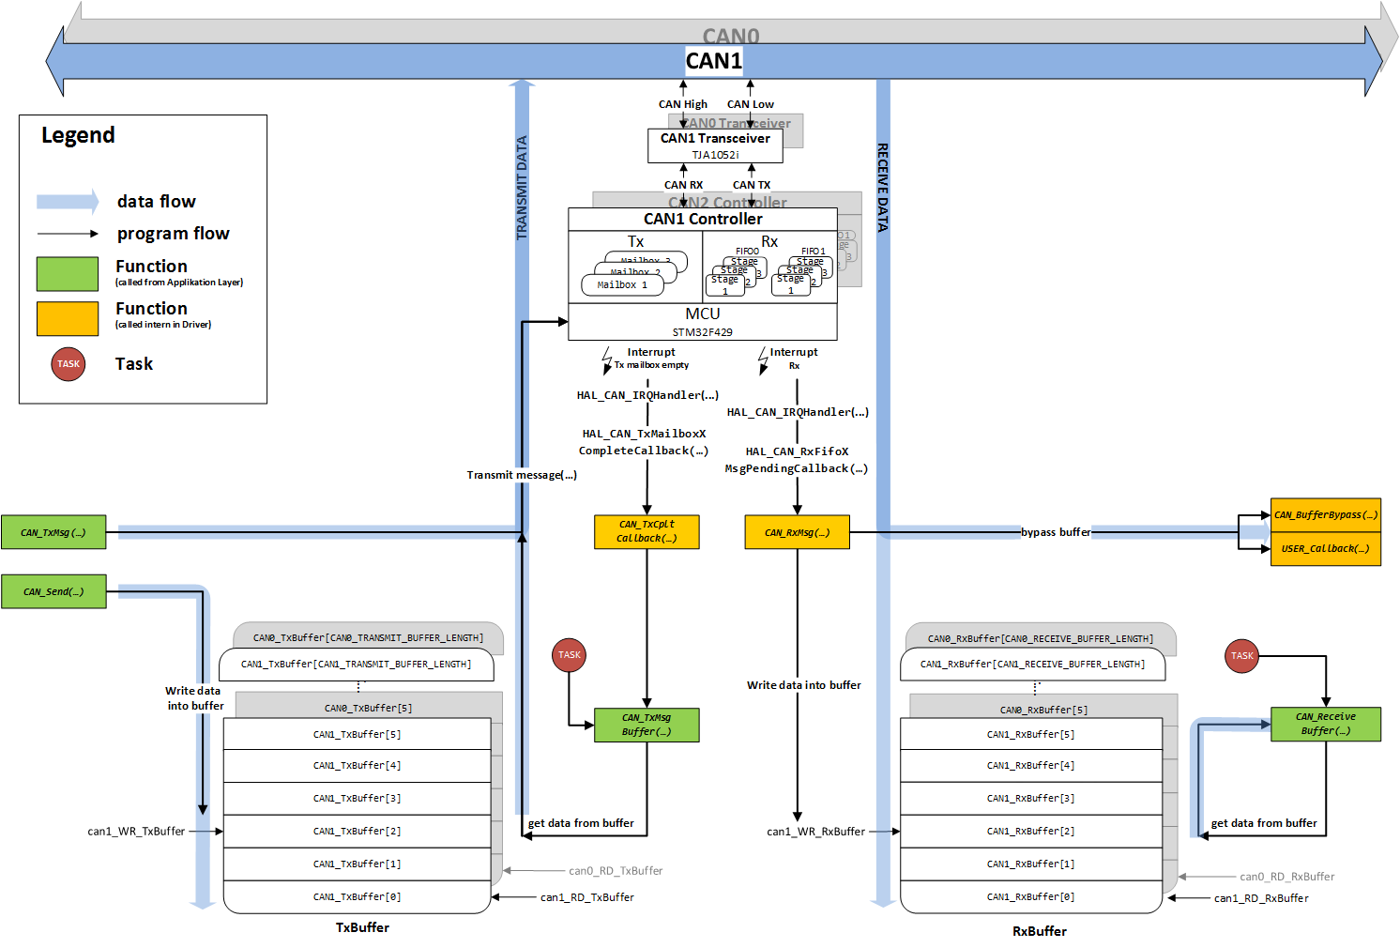
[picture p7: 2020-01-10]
documentation/sphinx/software_documentation/modules/can/can_flowchart.png

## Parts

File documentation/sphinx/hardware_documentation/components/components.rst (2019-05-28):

.. include:: ../../macros.rst

.. _HARDWARE_DOCUMENTATION_COMPONENTS:

=================
Safety Components
=================

Before using |master| and the |slaves| with lithium-ion batteries, safety must be considered very carefully. The following parts and components are recommended to be used with the |master| and the |slaves|.

DC Battery Pack Fuse
--------------------

When using |foxBMS| with batteries, a DC fuse in the current path is mandatory. In case of external short circuit of the battery pack, this fuse must be able to break the current at the maximum high-voltage of the complete battery. This DC fuse is a critical safety component and needs to be selected very carefully. The different parameters of the specific battery pack used must be taken into account (e.g., maximum voltage, expected short circuit current, continuous current).

:numref:`Fig. %s <battery_system_block_diagram>` shows how to set up a basic battery system using these components. In the section :ref:`hardware_documentation_bjb`, details can be found on how to use these and other components depending on the used battery system.

.. _battery_system_block_diagram:


    Block diagram showing the typical topology of a battery system

Power Contactors
----------------

To switching high-current capable batteries, mechanical power contactors (power relays) shall be used. For safety reasons, contactors with auxiliary contacts providing true state feedback are strongly recommended. |foxBMS| was developed and tested with the contactors of type Gigavac GX14 (GX14BAB: 12V coil voltage and normally open auxiliary contacts), but will probably work with many other contactors. The most important safety parameters are the maximum break current and the maximum allowed voltage to be broken. This must carefully be checked by the user of the |foxBMS| research and development platform. Further, the pick-up and continuous current of the contactor coil must be checked to be within the |foxBMS| electrical ratings. Nevertheless, contactors matching the used battery pack specification (e.g., continuous current, maximum voltage, short circuit current) are mandatory.

Current Sensor
--------------

To measure the battery pack current, CAN based current sensors can be used. The Isabellenhütte IVT-MOD and IVT-S shunt based current sensors were tested with |foxBMS|. The automotive current sensor IVT-MOD 300 provides a current measurement range of +/-300A and in addition three voltage measurement inputs with a voltage measurement range of +/-600V. Current sensors with higher current measurement ranges are available. Please check the `Isabellenhütte homepage <https://www.isabellenhuette.de/en/home>`_ and contact a `salesperson <https://www.isabellenhuette.de/en/contact>`_ to get more information. If another CAN based current sensor is used, the embedded software on the |BMS-Master| must be adapted.

Insulation Monitor
------------------

|foxBMS| supports an insulation monitoring device (i.e., also called a ground fault detector) to detect faulty insulation of the battery pack against chassis, ground or or battery pack enclosure. Bender insulation monitor IR155-3203/-3204/-3210 are supported and tested, while IR155-3204 is recommended.
The Bender ISOMETER IR155-3203/-3204 monitors the insulation resistance between the insulated and active HV-conductors of an electrical drive system (up to 1000VDC) and the reference ground. The fault messages (insulation fault at the HV-system, connection or device error)  will be provided at the integrated and galvanic isolated interface. The interface consists of a status output (called OKHS output) and a measurement output
(called MHS/MLS output). The status output signalises errors or that the system is error free. The measurement output signalises the actual insulation resistance. Furthermore, it is possible to distinguish between different fault messages and device conditions, which
are base frequency encoded. For details, consult the corresponding device datasheet or manual. The insulation resistance threshold can be factory programmed, as well as an additional undervoltage threshold. Any violation of thresholds causes an error signal on the status pin.

According to ECE R-100 the insulation resistance between the high voltage bus and the electrical chassis shall have a minimum value of 100Ohm/V of the working voltage for DC buses, and a minimum value of 500Ohm/V of the working
voltage for AC buses (e.g., for a 800V system, the insulation resistance threshold should be selected for 400kOhm).

The following section describes how to test the Bender functionality.

Required Hardware
~~~~~~~~~~~~~~~~~

Before starting, following items are needed:

* |BMS-Master|
* Bender insulation monitor IR155-3204/-3210
* Lauterbach debugger
* Resistors (1kOhm, 220kOhm, 470kOhm, 1MOhm)
* Terminal block for simple wire connection
* This documentation

Electrical Connections
~~~~~~~~~~~~~~~~~~~~~~

The follwong figure displays the the connectors of the Bender insulation monitor.

.. _bender_wiring:


   Wiring of the Bender insulation monitor (image source: Bender Datasheet)

Connect the Bender as follwing:

* connect the bender to |foxbms| as described in chapter :ref:`hardware_documentation_specifications`
* connect line voltage L-(connector XLA-) to chassis ground (Pin 3 and 4 of connector XK1A)
* connect one of the resistors between chassis ground/line voltage L-(XLA-) and line voltage L+(XLA+)

Depending on the connected resistor, different insulation values are measured.

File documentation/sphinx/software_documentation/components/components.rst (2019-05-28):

.. include:: ../../macros.rst

.. _SOFTWARE_DOCUMENTATION_COMPONENTS:

===================
Software Components
===================

.. highlight:: C

The |foxbms| embedded software is made out of the following components:

 - ``mcu-common``
 - ``mcu-freertos``
 - ``mcu-hal``
 - ``mcu-primary``
 - ``mcu-secondary``

mcu-common
==========

The ``mcu-common`` directory contains drivers that are common to |MCU0| and
|MCU1|. This means that any change made in the common directory affects both
|MCU0| and |MCU1|.

driver
------

The ``driver`` directory contains a |foxbms| specific abstraction layer for
the hardware.

+-------------+-------------------------------------------------------------------------------------------+
| Element     | Description                                                                               |
+=============+===========================================================================================+
| adc         | Driver for analog to digital converter, measurement of lithium backup battery voltage     |
+-------------+-------------------------------------------------------------------------------------------+
| can         | Driver to receive/transmit CAN message                                                    |
+-------------+-------------------------------------------------------------------------------------------+
| chksum      | Checksum algorithms for modulo 32-bit addition and CRC32                                  |
+-------------+-------------------------------------------------------------------------------------------+
| dma         | Configuration for Direct Memory Access (e.g. used for SPI Communication)                  |
+-------------+-------------------------------------------------------------------------------------------+
| io          | Driver and interfaces for I/O ports (control of output pins and read of input pins)       |
+-------------+-------------------------------------------------------------------------------------------+
| mcu         | Driver for the interlock                                                                  |
+-------------+-------------------------------------------------------------------------------------------+
| rcc         | Configuration of the prescaler for the MCU clock system                                   |
+-------------+-------------------------------------------------------------------------------------------+
| rtc         | Real time clock driver, Control and Access of Backup SRAM Registers                       |
+-------------+-------------------------------------------------------------------------------------------+
| spi         | Driver for communication via Serial Peripheral Interface (SPI bus)                        |
+-------------+-------------------------------------------------------------------------------------------+
| uart        | Driver for serial communication (UART, RS232 , RS485)                                     |
+-------------+-------------------------------------------------------------------------------------------+
| vic         | Interrupt configuration                                                                   |
+-------------+-------------------------------------------------------------------------------------------+
| watchdog    | Driver for the watchdog timer                                                             |
+-------------+-------------------------------------------------------------------------------------------+

engine
------

The ``engine`` directory contains all the core functions of the BMS.

+-------------+------------------------------------------------------------------------------------+
| Element     | Description                                                                        |
+=============+====================================================================================+
| database    | Implementation of the asynchronous data exchange                                   |
+-------------+------------------------------------------------------------------------------------+

module
------

The ``module`` directory contains all the software modules needed by the BMS.

+-------------+-------------------------------------------------------------------------------------------+
| Element     | Description                                                                               |
+=============+===========================================================================================+
| cansignal   | Definition of CAN messages and signals                                                    |
+-------------+-------------------------------------------------------------------------------------------+
| hwinfo      | Functions to return information about the hardware (e.g., cpu temperature)                |
+-------------+-------------------------------------------------------------------------------------------+
| interlock   | Driver for the interlock                                                                  |
+-------------+-------------------------------------------------------------------------------------------+
| led         | Functions for using the LEDs                                                              |
+-------------+-------------------------------------------------------------------------------------------+
| ltc         | Driver for battery cell monitoring IC                                                     |
+-------------+-------------------------------------------------------------------------------------------+
| meas        | Uses ltc module to perform measurements                                                   |
+-------------+-------------------------------------------------------------------------------------------+

util
----

The ``util`` directory contains additional functions.

+-------------+------------------------------------------------------------------------------------+
| Element     | Description                                                                        |
+=============+====================================================================================+
| foxmath     | Implementation of a math library                                                   |
+-------------+------------------------------------------------------------------------------------+
| misc        | miscellaneous functions (e.g., functions to reverse a string                       |
+-------------+------------------------------------------------------------------------------------+

mcu-freertos
============

The ``mcu-freertos`` directory contains the operating system software (FreeRTOS).

+-----------------------+--------------------------------------------------------------------------------+
| Element               | Description                                                                    |
+=======================+================================================================================+
| Source                | FreeRTOS                                                                       |
+-----------------------+--------------------------------------------------------------------------------+

mcu-hal
=======

The ``mcu-hal`` directory contains the Hardware Abstraction Layer (HAL). It is
used by the system but is provided by the MCU manufacturer, in this case
ST-Microelectronics. It is used by |foxbms| but not part of |foxbms|.

+-----------------------+--------------------------------------------------------------------------------+
| Element               | Description                                                                    |
+=======================+================================================================================+
| CMSIS                 | Interface and configuration of CMSIS                                           |
+-----------------------+--------------------------------------------------------------------------------+
| STM32F4xx_HAL_Driver  | STM32F4xx family Hardware Abstraction Layer drivers                            |
+-----------------------+--------------------------------------------------------------------------------+

mcu-primary
===========

The ``mcu-primary`` directory contains the software specific to |MCU0|.

application
-----------

The ``application`` directory contains the user applications.

+-------------+-----------------------------------------------------------------------------------+
| Element     | Description                                                                       |
+=============+===================================================================================+
| algo        | Task for integration various algorithms                                           |
+-------------+-----------------------------------------------------------------------------------+
| bal         | Driver for balancing                                                              |
+-------------+-----------------------------------------------------------------------------------+
| bms         | Decision are taken here by the BMS (e.g., open contactors in case of a problem)   |
+-------------+-----------------------------------------------------------------------------------+
| com         | Serial port communication layer (for debug purposes)                              |
+-------------+-----------------------------------------------------------------------------------+
| config      | Contains the configuration for the user applications (e.g., task configuration)   |
+-------------+-----------------------------------------------------------------------------------+
| sox         | Coulomb-counter (current integrator) and State-of-Function calculator             |
+-------------+-----------------------------------------------------------------------------------+
| task        | User specific cyclic tasks (10ms and 100ms)                                       |
+-------------+-----------------------------------------------------------------------------------+

Application tasks should be used to call user-defined functions.

driver
------

The ``driver`` directory contains a |foxbms| specific abstraction layer for
the hardware.

+-------------+-------------------------------------------------------------------------------------------+
| Element     | Description                                                                               |
+=============+===========================================================================================+
| config      | Configuration of the drivers (from mcu-common and primary specfific)                      |
+-------------+-------------------------------------------------------------------------------------------+
| sdram       | Drivers for the external SDRAM                                                            |
+-------------+-------------------------------------------------------------------------------------------+
| timer       | Drivers for the internal timers                                                           |
+-------------+-------------------------------------------------------------------------------------------+

engine
------

The ``engine`` directory contains all the core functions of the BMS.

+--------------+------------------------------------------------------------------------------------+
| Element      | Description                                                                        |
+==============+====================================================================================+
| config       | Contains the configuration of engine components (e.g., task configuration)         |
+--------------+------------------------------------------------------------------------------------+
| diag         | With this software module, other modules can report problems                       |
+--------------+------------------------------------------------------------------------------------+
| nvramhandler | Handler for the non volatile memories                                              |
+--------------+------------------------------------------------------------------------------------+
| sys          | System state machine, starts all other state machines                              |
+--------------+------------------------------------------------------------------------------------+
| task         | Cyclic engine tasks (1, 10 and 100ms) that call system related functions           |
+--------------+------------------------------------------------------------------------------------+

general
-------

The ``general`` directory contains the main function and configuration files.

+-------------+-----------------------------------------------------------------------------------+
| Element     | Description                                                                       |
+=============+===================================================================================+
| main        | Initialization of hardware modules, of interrupts and of the operating system     |
+-------------+-----------------------------------------------------------------------------------+
| config      | Contains the configuration for the system initialization:                         |
|             | configuration and interface functions to HAL and FreeRTOS,                        |
|             | global definitions, interrupt configurations and startup code                     |
+-------------+-----------------------------------------------------------------------------------+
| includes    | Contains the standard types                                                       |
+-------------+-----------------------------------------------------------------------------------+
| version     | Sets the version number                                                           |
+-------------+-----------------------------------------------------------------------------------+

module
------

The ``module`` directory contains all the software modules needed by the BMS.

+-------------+-------------------------------------------------------------------------------------------+
| Element     | Description                                                                               |
+=============+===========================================================================================+
| config      | Contains the configuration for the software modules                                       |
+-------------+-------------------------------------------------------------------------------------------+
| contactor   | Driver to open/close contactors and read contactor feedback                               |
+-------------+-------------------------------------------------------------------------------------------+
| isoguard    | Driver for monitoring galvanic isolation in the system                                    |
+-------------+-------------------------------------------------------------------------------------------+
| nvram       | Non-volatile Memory: Eeprom and button cell buffered SRAM (BKP_SRAM)                      |
+-------------+-------------------------------------------------------------------------------------------+

os
--

The ``os`` directory contains configurations for the operating system FreeRTOS.

+-------------+----------------------------------------------------------------------------------------+
| Element     | Description                                                                            |
+=============+========================================================================================+
| os          | Interface to FreeRTOS (e.g., wrapper functions of cyclic application and engine tasks) |
+-------------+----------------------------------------------------------------------------------------+

mcu-secondary
=============

Contains the software specific to |MCU1|. These are the same elements as
``mcu-primary``, adapted for |MCU1|.

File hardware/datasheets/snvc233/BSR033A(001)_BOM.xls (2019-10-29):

Filename: | #VALUE!
Variant: | 001
Generated: | 11/2/2018 9:12:43 AM
 |  | LM5180EVM-S05
Designator | Quantity | Value | Description | PackageReference | PartNumber | Manufacturer | Alternate PartNumber | Alternate Manufacturer
!PCB | 1 |  | Printed Circuit Board |  | BSR033 | Any
C1 | 1 | 1000pF | CAP, CERM, 1000 pF, 2000 V, +/- 10%, X7R, 1206_190 | 1206_190 | 202R18W102KV4E | Johanson Technology
C2 | 1 | 33uF | CAP, AL, 33 uF, 100 V, +/- 20%, 0.7 ohm, AEC-Q200 Grade 2, SMD | SMT Radial G | EEE-FK2A330P | Panasonic
C3, C7 | 2 | 0.1uF | CAP, CERM, 0.1 uF, 100 V, +/- 10%, X7R, 0603 | 0603 | GRM188R72A104KA35J | MuRata
C4, C5 | 2 | 4.7uF | CAP, CERM, 4.7 uF, 100 V, +/- 10%, X7S, 1210 | 1210 | GRM32DC72A475KE01L | MuRata
C6 | 1 | 100uF | CAP, CERM, 100 uF, 6.3 V, +/- 20%, X6S, 1210 | 1210 | GRM32EC80J107ME20L | MuRata
C8, C10 | 2 | 22pF | CAP, CERM, 22 pF, 100 V, +/- 5%, C0G/NP0, 0603 | 0603 | GRM1885C2A220JA01D | MuRata
C9 | 1 | 0.047uF | CAP, CERM, 0.047 uF, 25 V, +/- 10%, X7R, AEC-Q200 Grade 1, 0603 | 0603 | GCM188R71E473KA37D | MuRata
D1 | 1 | 24V | Diode, Zener, 24 V, 1 W, PowerDI123 | PowerDI123 | DFLZ24-7 | Diodes Inc.
D2 | 1 | 40V | Diode, Schottky, 40 V, 3 A, AEC-Q101, SMAF | SMAF | FSV340AF | Fairchild Semiconductor
D3 | 1 | 5.6V | Diode, Zener, 5.6 V, 200 mW, SOD-323 | SOD-323 | MMSZ5232BS-7-F | Diodes Inc.
D4 | 1 | 75V | Diode, Ultrafast, 75 V, 0.25 A, SOD-323 | SOD-323 | CMDD4448 | Central Semiconductor
H1, H2, H3, H4 | 4 |  | MACHINE SCREW PAN PHILLIPS 4-40 | Machine Screw, 4-40, 1/4 inch | PMSSS 440 0025 PH | B&F Fastener Supply
H5, H6, H7, H8 | 4 |  | Standoff, Hex, 0.5"L #4-40 Nylon | Standoff | 1902C | Keystone
J1, J2, J3, J4 | 4 |  | Terminal, Turret, TH, Double | Keystone1573-2 | 1573-2 | Keystone
L1 | 1 | 22 ohm | Ferrite Bead, 22 ohm @ 100 MHz, 6 A, 0805 | 0805 | 742792021 | Wurth Elektronik
L2 | 1 | 10uH | Inductor, Shielded Drum Core, Ferrite, 10 uH, 1 A, 0.12 ohm, SMD | WE-TPC-M1 | 744042100 | Wurth Elektronik
R1, R2 | 2 | 100 | RES, 100, 1%, 0.1 W, 0603 | 0603 | CRCW0603100RFKEA | Vishay-Dale
R3 | 1 | 130k | RES, 130 k, 1%, 0.1 W, AEC-Q200 Grade 0, 0603 | 0603 | CRCW0603130KFKEA | Vishay-Dale
R4 | 1 | 536k | RES, 536 k, 1%, 0.1 W, AEC-Q200 Grade 0, 0603 | 0603 | CRCW0603536KFKEA | Vishay-Dale
R5 | 1 | 158k | RES, 158 k, 1%, 0.1 W, AEC-Q200 Grade 0, 0603 | 0603 | CRCW0603158KFKEA | Vishay-Dale
R6 | 1 | 12.1k | RES, 12.1 k, 1%, 0.1 W, 0603 | 0603 | CRCW060312K1FKEA | Vishay-Dale
R7 | 1 | 100k | RES, 100 k, 1%, 0.1 W, AEC-Q200 Grade 0, 0603 | 0603 | CRCW0603100KFKEA | Vishay-Dale
T1 | 1 | 30uH | Transformer, 30 uH, SMD | 9.3x10.2mm | YA8779-BL | Coilcraft
TP1, TP2, TP3, TP4 | 4 |  | Test Point, Miniature, SMT | Testpoint_Keystone_Miniature | 5015 | Keystone
U1 | 1 |  | 70-V PSR Flyback Converter With 100-V, 1.2-A Power Switch and Ultra-Low IQ, NGU0008C (WSON-8) | NGU0008C | LM5180QNGURQ1 | Texas Instruments | LM5180QNGUTQ1 | Texas Instruments
C11 | 0 | 220uF | CAP, Aluminum Polymer, 220 µF, 6.3 V,+/- 20%, 0.01 ohm, 7343-31 SMD | 7343-31 | ECASD60J227M010K00 | MuRata
FID1, FID2, FID3 | 0 |  | Fiducial mark. There is nothing to buy or mount. | N/A | N/A | N/A
 |  | Notes:
 |  | Unless otherwise noted in the Alternate PartNumber and/or Alternate Manufacturer columns, all parts may be substituted with equivalents.

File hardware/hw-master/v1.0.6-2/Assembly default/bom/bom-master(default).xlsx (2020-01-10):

Line # | Name | Description | Designator | Case EIA | Quantity | TargetPrice | Fitted | Manufacturer 1 | Manufacturer Part Number 1 | Manufacturer Lifecycle 1 | Supplier 1 | Supplier Part Number 1 | Supplier Unit Price 1 | Supplier Subtotal 1
 | 330m | Eaton 330mF, 5.5v, -20 to +80, Ultracapacitor, KW-5R5C334H-R | BT1 |  | 1 | 0 |  | Eaton | KW-5R5C334-R | Volume Production | Digi-Key | 283-4151-ND | 4.48 | 4.48
 | 4.7µF 16V | Ceramic, 4.7µF, ±10%, 16V, X7R, –55 to 125°C, 0805 (2012),RoHS, Automotive | C1_1, C1_2, C39, C85 | 0805 | 4 | 0 |  | Murata | GCJ21BR71C475KA01L | Volume Production | Digi-Key | 490-10557-1-ND | 0.53 | 2.12
 | 100nF 50V | Ceramic, 100nF, ±10%, 50V, X7R, –55 to 125°C, 0603 (1608),RoHS, Automotive | C2_1, C2_2, C5_1, C5_2, C10_1, C10_2, C12_1, C12_2, C28_1, C28_2, C28_3, C28_4, C31, C55, C56, C70, C71, C73, C76, C77, C78, C79, C80, C81, C82, C86, C107, C115, C128, C134, C142, C143, C149, C150, C151, C152, C159, C161_1, C161_2, C164, C165_1, C165_2, C166, C167, C177, C178, C179, C180 | 0603 | 48 | 0 |  | Yageo | CC0603JRX7R9BB104 | Volume Production | Digi-Key | 311-1779-1-ND | 0.0371 | 3.71
 | 10µF 10V | Ceramic, 10µF, ±10%, 10V, X7R, –55 to 125°C, 0805 (2012),RoHS, Automotive | C3_1, C3_2, C8_1, C8_2, C9_1, C9_2, C144, C146, C158_1, C158_2 | 0805 | 10 | 0 |  | Taiyo Yuden | LMK212AB7106MG-T | Volume Production | Digi-Key | 587-3417-1-ND | 0.157 | 1.57
 | 47pF 50V | Ceramic, 47pF, ±5%, 50V, C0G, 25 to 125°C, 0402 (1005),RoHS, Automotive | C4_1, C4_2, C7_1, C7_2 | 0402 | 4 | 0 |  | Murata | GCM1555C1H470JA16D | Volume Production | Digi-Key | 490-10670-1-ND | 0.1 | 0.4
 | 390pF 25V | Ceramic, 390pF, ±5%, 25V, C0G, 25 to 125°C, 0402 (1005),RoHS, Automotive | C6_1, C6_2 | 0402 | 2 | 0 |  | Murata | GCM1555C1H180JA16D | Volume Production | Digi-Key | 490-12650-1-ND | 0.14594 | 0.29188
 | 1.0µF 25V | Ceramic, 1.0µF, ±10%, 25V, X7R, –55 to 125°C, 0603 (1608),RoHS, Automotive | C11_1, C11_2, C67, C154 | 0603 | 4 | 0 |  | Murata | GCJ188R71E105KA01D |  | Digi-Key | 490-14409-1-ND | 0.40864 | 1.63
 | 10nF 50V | Ceramic, 10nF, ±10%, 50V, X7R, –55 to 125°C, 0603 (1608),RoHS, Automotive | C13_1, C13_2, C153, C157 | 0603 | 4 | 0 |  | Murata | GCJ188R71H102KA01D | Volume Production | Digi-Key | 490-5768-1-ND | 0.24 | 0.96
 | 2.2µF 25V | Ceramic, 2.2µF, ±10%, 25V, X7R, –55 to 125°C, 0805 (2012),RoHS, Automotive | C14, C17, C96, C141 | 0805 | 4 | 0 |  | Murata | GCM21BR71E225KA73L | Volume Production | Digi-Key | 490-4787-1-ND | 0.64 | 2.56
 | 100nF 50V | Ceramic, 100nF, ±10%, 50V, X7R, –55 to 125°C, 0402 (1005),RoHS, Automotive | C15, C16, C29, C30, C33, C34, C35, C40, C87, C88, C89, C90, C97, C105, C108, C109, C116, C123, C125, C126, C127, C135, C136, C137, C138 | 0402 | 25 | 0 |  | Murata | GCM155R71H104KE02D | Volume Production | Digi-Key | 490-10672-1-ND | 0.061 | 1.53
 | T598D107M010ATE025 | CAP, Aluminum Polymer, 220 µF, 6.3 V,+/- 20%, 0.01 ohm, 7343-31 SMD | C18_1, C18_2 |  | 2 | 0 |  | Murata | ECASD60J227M010K00 | Volume Production | Digi-Key | 490-12529-1-ND | 1.84 | 3.68
 | 27p/50V | MLCC | C19, C26, C36, C48 | 0603 | 4 | 0 |  | KEMET | C0603X270J5GACAUTO | Volume Production | Farnell | 2219430 | 0.28082 | 2.81
 | 100n/50V | MLCC | C20_1, C20_2, C20_3, C20_4, C23_1, C23_2, C84, C147, C148 | 0603 | 9 | 0 |  | Yageo | CC0603JRX7R9BB104 | Volume Production | Digi-Key | 311-1779-1-ND | 0.079 | 0.79
 | GRM188R72A104KA35J | CAP, CERM, 0.1 uF, 100 V, +/- 10%, X7R, 0603 | C22_1, C22_2, C52_1, C52_2 |  | 4 | 0 |  | Murata | GRM188R72A104KA35J | Volume Production | Digi-Key | 490-6439-1-ND | 0.28 | 1.12
 | GRM1885C2A220JA01D | CAP, CERM, 22 pF, 100 V, +/- 5%, C0G/NP0, 0603 | C24_1, C24_2, C43_1, C43_2 |  | 4 | 0 |  | Murata | GRM1885C2A220JA01D | Volume Production | Digi-Key | 490-1335-1-ND | 0.11 | 0.44
 | GRM32EC80J107ME20L | CAP, CERM, 100 uF, 6.3 V, +/- 20%, X6S, 1210 | C25_1, C25_2 |  | 2 | 0 |  | Murata | GRM32EC80J107ME20L | Volume Production | Digi-Key | 490-6533-6-ND | 1.52 | 3.04
 | 1.0µF 25V | Ceramic, 1.0µF, ±10%, 25V, X7R, –55 to 125°C, 0603 (1608),RoHS, Automotive | C37, C44, C75, C83, C91, C92_1, C92_2, C93, C122, C124, C130, C145 | 0603 | 12 | 0 |  | Samsung | CL10B105KA8NFNC | Volume Production | Digi-Key | 1276-1942-6-ND | 0.061 | 0.732
 | 18pF 50V | Ceramic, 18pF, ±5%, 50V, X7R, 25 to 125°C, 0402 (1005),RoHS, Automotive | C38, C42, C99, C102, C112, C117 | 0402 | 6 | 0 |  | Murata | GCM1555C1H180JA16D | Volume Production | Digi-Key | 490-12650-1-ND | 0.14594 | 0.87565
 | CAP TANTALUM 33UF 50V 2917 | 33µF Molded Tantalum Polymer Capacitor 50V 2917 (7343 Metric) 75mOhm @ 100kHz | C47_1, C47_2 |  | 2 | 0 |  | KEMET | T521X336M050ATE075 | Volume Production | RSComponents | 1737037 | 2.38 | 4.76
 | GRM32DC72A475KE01L | CAP, CERM, 4.7 uF, 100 V, +/- 10%, X7S, 1210 | C49_1, C49_2, C50_1, C50_2 |  | 4 | 0 |  | Samsung | CL32B475KBUYNNE | Volume Production | Digi-Key | 1276-1292-6-ND | 0.54 | 2.16
 | GCM188R71E473KA37D | CAP, CERM, 0.047 uF, 25 V, +/- 10%, X7R, AEC-Q200 Grade 1, 0603 | C53_1, C53_2 |  | 2 | 0 |  | Murata | GCM188R71E473KA37D | Volume Production | Digi-Key | 490-8018-1-ND | 0.23 | 0.46
 | 100nF 50V | Ceramic, 100nF, ±20%, 50V, X7R, –55 to 125°C, 0805 (2012),RoHS, Automotive | C54, C69 | 0805, 0603 | 2 | 0 |  | Murata | GRM21BR71H104KA01L | Volume Production | Element14 | 8820120 | 0.02515 | 0.2515
 | 1500pF 50V | Ceramic, 390pF, ±5%, 25V, C0G, 25 to 125°C, 0402 (1005),RoHS, Automotive | C57 | 0402 | 1 | 0 |  | Murata | GRM155R71H152KA01D | Volume Production | Digi-Key | 490-3245-6-ND | 0.1 | 0.1
 | 10uF 50V | Ceramic, 10uF, 50 V, -55 to 125 degC, 2-Pin SMD (1210), RoHS, Tape and Reel | C58 | 1210 | 1 | 0 |  | Samsung | CL32B106KBJNNWE | Volume Production | Digi-Key | 1276-3388-1-ND | 0.66 | 0.66
 | 10nF 50V | Ceramic, 10nF, ±10%, 50V, X7R, –55 to 125°C, 0402 (1005),RoHS, Automotive | C59, C68 | 0402 | 2 | 0 |  | Murata | GRM155R71H103KA88D | Volume Production | Digi-Key | 490-4516-6-ND | 0.1 | 0.2
 | 22uF 16V | Ceramic, 22uF, 16 V, -55 to 125 degC, 2-Pin SMD (1210), RoHS, Tape and Reel | C60, C61, C62 | 1210 | 3 | 0 |  | Samsung | CL32B226MOJNNNE | Volume Production | Digi-Key | 1276-3395-1-ND | 0.55 | 1.65
 | 1200pF 50V | Ceramic, 390pF, ±5%, 50V, C0G, 25 to 125°C, 0402 (1005),RoHS, Automotive | C63 | 0402 | 1 | 0 |  | Murata | GRM155R71H122KA01D | Volume Production | Digi-Key | 490-1304-6-ND | 0.1 | 0.1
 | GRM31CR72A105KA01L | Chip Capacitor, 1 uF, +/- 10%, 100 V, -55 to 125 degC, 1206 (3216 Metric), RoHS, Tape and Reel | C64, C65, C72, C74 | 1206 | 4 | 0 |  | Murata | GRM31CR72A105KA01L | Volume Production | Digi-Key | 490-3909-1-ND | 0.77 | 3.08
 | 10nF 50V | Ceramic, 10nF, ±10%, 50V, X7R, –55 to 125°C, 0402 (1005),RoHS, Automotive | C66 | 0402 | 1 | 0 |  | Murata | GRM155R71H103KA88D | Volume Production | Digi-Key | 490-4516-6-ND | 0.1 | 0.1
 | 10µF 10V | Ceramic, 10µF, ±10%, 10V, X7R, –55 to 125°C, 0805 (2012),RoHS, Automotive | C120, C156 | 0805 | 2 | 0 |  | Murata | GCJ21BR71A106KE01L | Volume Production | Digi-Key | 490-12646-1-ND | 0.93403 | 1.87
 | 100nF 50V | Ceramic, 100nF, ±10%, 50V, X7R, –55 to 125°C, 0603 (1608),RoHS, Automotive | C155 | 0603 | 1 | 0 |  | Yageo | CC0603JRX7R9BB104 | Volume Production | Digi-Key | 311-1779-1-ND | 0.11 | 0.11
 | GRM1885C1H560JA01D | CAP, CERM, 56 pF, 50 V, +/- 5%, C0G/NP0, 0603 | C160_1, C160_2, C163_1, C163_2 |  | 4 | 0 |  | Murata | GRM1885C1H560JA01D | Volume Production | Digi-Key | 490-1421-1-ND | 0.11 | 0.44
 | GCM188R71H472KA37D | CAP, CERM, 4700 pF, 50 V, +/- 10%, X7R, AEC-Q200 Grade 1, 0603 | C162_1, C162_2 |  | 2 | 0 |  | Murata | GCM188R71H472KA37D | Volume Production | Digi-Key | 490-4932-1-ND | 0.17 | 0.34
 | 1u/50V | MLCC | C181 | 0603 | 1 | 0 |  | Taiyo Yuden | UMK107AB7105KA-T | Volume Production | Farnell | 2779055 | 0.32262 | 0.32262
 | MMSZ5232BS-7-F | Diode, Zener, 5.6 V, 200 mW, SOD-323 | D1_1, D1_2 |  | 2 | 0 |  | Diodes | MMSZ5232BS-7-F | Volume Production | Digi-Key | MMSZ5232BS-FDICT-ND | 0.27 | 0.54
 | 40V | Diode, Schottky, 40 V, 3 A, AEC-Q101, SMAF | D2_1, D2_2 |  | 2 | 0 |  | ON Semiconductor / Fairchild | FSV340AF | New Product | Digi-Key | FSV340AFCT-ND | 0.5 | 1
 | DFLZ24-7 | Diode, Zener, 24 V, 1 W, PowerDI123 | D3_1, D3_2 |  | 2 | 0 |  | Diodes | DFLZ24-7 | Volume Production | Digi-Key | DFLZ24DICT-ND | 0.36 | 0.72
 | 75V | Diode, Ultrafast, 75 V, 0.25 A, SOD-323 | D4_1, D4_2 |  | 2 | 0 |  | Central Semiconductor | CMDD4448TR | Volume Production | Digi-Key | 1514-CMDD4448TRPBFREECT-ND | 0.51 | 1.02
 | MM3Z12VT1G | Zener Diode | D5, D6 |  | 2 | 0 |  | ON Semiconductor | MM3Z12VT1G | Volume Production | Digi-Key | MM3Z12VT1GOSCT-ND | 0.15 | 0.3
 | BAT54SW-7-F | Schottky Barrier Diode, 30 V, 200 mA, -65 to 125 degC, 3-Pin SOT323, RoHS, Tape and Reel | D7 |  | 1 | 0 |  | Diodes | BAT54SW-7-F | Volume Production | Digi-Key | BAT54SW-FDIDKR-ND | 0.25 | 0.25
 | CDSOD323-T05 | TVS Diode, CDSOD323 Series, Unidirectional, 5 V, 18.3 V, SOD-323, 2 Pins | D8, D9, D10, D11 |  | 4 | 0 |  | Bourns | CDSOD323-T05S | Volume Production | Digi-Key | CDSOD323-T05SCT-ND | 0.63 | 2.52
 | MBR0520L | Schottky Diode, 20V, 0.2A, 2-pin SOD-123, RoHS, Tape and Reel | D16, D17 |  | 2 | 0 |  | ON Semiconductor / Fairchild | MBR0520L | Volume Production | Digi-Key | MBR0520LCT-ND | 0.34 | 0.68
 | BZX84C5V1ET1G | Zener Voltage Regulator, 225 mW, 3-Pin SOT-23, Pb-Free, Tape and Reel | D18 |  | 1 | 0 |  | ON Semiconductor | SZBZX84C5V1ET1G | Volume Production | Digi-Key | SZBZX84C5V1ET1GOSDKR-ND | 0.21 | 0.21
 | ISO7741DWR | Imported | IC1_1, IC1_2 |  | 2 | 0 |  | Texas Instruments | ISO7741DWR |  | TI store | ISO7741DWR | 3.02 | 6.04
 | FT231XQ-R | USB to Full-Handshake UART Interface Chip, UHCI/OHCI/EHCI Compatible, USB 2.0 Compatible, -40 to +85 degC, 20-Pin QFN, Pb-Free, Tape and Reel | IC2_1, IC2_2 |  | 2 | 0 |  | FTDI | FT231XQ-R | Volume Production | Digi-Key | 768-1128-6-ND | 2.12 | 4.24
 | MB85RS2MTAPNF-G-BDERE1 | FRAM (Ferroelectric RAM) Memory IC 2Mb (256K x 8) SPI 40MHz 8-SOP | IC3 |  | 1 | 0 |  | Fujitsu | MB85RS2MTAPNF-G-BDERE1 |  | Digi-Key | 865-1286-1-ND | 6.21 | 6.21
 | IS42S16400J-7TLI | SDRAM, 4M x 16 Bit | IC4 |  | 1 | 0 |  | ISSI | IS42S16400J-7TLI | Volume Production | Digi-Key | 706-1132-ND | 1.93 | 1.93
 | BLM21AG471SN1J | Chip Ferrite Bead for General Signal lines, 470 Ohm, 700 mA, -55 to 125 degC, 2 x 1.25 x 1.05 mm SMD, Tape and Reel | L1_1, L1_2, L2_1, L2_2, L6, L7, L8, L9, L10, L11, L12, L13, L14, L17 |  | 14 | 0 |  | Murata | BLM21AG471SZ1D |  | Digi-Key | 490-16493-6-ND | 0.122 | 1.71
 | 744042100 | Inductor, Shielded Drum Core, Ferrite, 10 uH, 1 A, 0.12 ohm, SMD | L3_1, L3_2 |  | 2 | 0 |  | Wurth Electronics | 744042100 | Volume Production | Digi-Key | 732-1025-1-ND | 1.43 | 2.86
 | 742792021 | Ferrite Bead, 22 ohm @ 100 MHz, 6 A, 0805 | L4_1, L4_2 |  | 2 | 0 |  | Wurth Electronics | 742792021 | Volume Production | Digi-Key | 732-4637-1-ND | 0.22 | 0.44
 | SDR0403-4R7ML | 4.7uH | L5 |  | 1 | 0 |  | Bourns | SDR0403-4R7ML | Volume Production | Digi-Key | SDR0403-4R7MLCT-ND | 0.6 | 0.6
 | PA4332.222NLT | Imported | L15_1, L15_2 |  | 2 | 0 |  | Pulse | PA4332.222NLT | Volume Production | Mouser | 673-PA4332222NLT | 0.61 | 1.22
 | Wurth 750316031 Xformer | Isolated interface power supply for CAN, RS-485, RS-422, RS-232, SPI, I2C, lower-power LAN 1:1 1A | L16 |  | 1 | 0 |  | Wurth Electronics Midcom | 750316031 |  | Digi-Key | 1297-1220-6-ND | 6.06 | 6.06
 | B82789C0104H001 | Coupled inductor, 100 µH, 0.15 A, 1.5 ohm, SMD | L20_1, L20_2 |  | 2 | 0 |  | TDK EPCOS | B82789C104H2 | Obsolete | Arrow | B82789C104H2 | 1.68 | 3.37
 | green | LED | LED1, LED4 | 0603 | 2 | 0 |  | Wurth Electronics | 150060VS75000 | Volume Production | Digi-Key | 732-4980-1-ND | 0.14 | 0.28
 | red | LED | LED2, LED5 | 0603 | 2 | 0 |  | Wurth Electronics | 150060RS75000 | Volume Production | Digi-Key | 732-4978-1-ND | 0.14 | 0.28
 | orange | LED | LED3, LED6 | 0603 | 2 | 0 |  | Wurth Electronics | 150060YS75000 | Volume Production | Digi-Key | 732-4981-1-ND | 0.14 | 0.28
 | PS1240P02CT3 | Loudspeaker | LS1 |  | 1 | 0 |  | TDK | PS1240P02CT3 | Volume Production | Digi-Key | 445-5229-1-ND | 0.73 | 0.73
 | CX2520DB32000D0GEJZ1 | Crystal,CRYSTAL 40MHZ 15PF 85degC Surface Mount 2.5 x 2.0 mm | Q1, Q13 |  | 2 | 0 |  | Abracon | ABM3B-8.000MHZ-10-1-U-T | Volume Production | Digi-Key | 535-9721-1-ND | 0.69 | 1.38
 | BSS138 | MOSFET, N-CH, 50V, 0.22A, SOT-23 | Q2, Q4, Q6, Q8, Q10 |  | 5 | 0 |  | Micross | BSS138 |  | Mouser | 512-BSS138 | 0.26 | 1.3
 | CSD17308Q3 | MOSFET, N-CH, 30V, 47A, SON 3.3x3.3mm | Q3 |  | 1 | 0 |  | Texas Instruments | CSD17308Q3 | Volume Production | TI store | CSD17308Q3 | 0.65 | 0.65
 | CSD18543Q3A | 60V, N ch NexFET MOSFET™, single SON3x3, 9.9mOhm | Q5, Q7, Q9, Q11 |  | 4 | 0 |  | Texas Instruments | CSD18543Q3A |  | Digi-Key | 296-47321-1-ND | 0.84 | 3.36
 | 32.768kHz | Crystal, 32.768 KHz, 12.5 pF, -40 to 85 degC, 2-Pin SMD, RoHS, Tape and Reel | Q12 |  | 1 | 0 |  | Epson | FC-13532.7680KA-A3 | Volume Production | Digi-Key | SE2413CT-ND | 0.62755 | 0.62755
 | 27R | SMD Resistor 27R 0603 | R1_1, R1_2, R5_1, R5_2 | 0603 | 4 | 0 |  | Panasonic | ERJ-3GEYJ270V | Volume Production | Farnell | 2059559 | 0.05564 | 0.55642
 | 130R | SMD Resistor 130R 0603 | R2, R3, R4, R60, R61, R62 | 0603 | 6 | 0 |  | Panasonic | ERJ3RBD1300V | Volume Production | Farnell | 2379959 | 0.08033 | 0.80328
 | 0.01R | SMD Resistor 10m 0805 | R6, R116 | 0805 | 2 | 0 |  | Yageo | RL0805FR-7W0R01L | Volume Production | Digi-Key | 311-.01LUCT-ND | 0.58 | 1.16
 | 0R | SMD Resistor 0R 0603 | R7_1, R7_2, R8_1, R8_2, R9, R20_1, R20_2, R26, R55, R56 | 0603 | 10 | 0 |  | Multicomp | MCMR06X000PTL | Volume Production | Farnell | 2073345 | 0.00784 | 0.07837
 | 680R | SMD Resistor 680R 0603 | R10, R54 | 0603 | 2 | 0 |  | Panasonic | ERA3APB681V | Volume Production | Farnell | 2797303 | 0.62303 | 6.23
 | 1k2 | SMD Resistor 1k2 0603 | R11_1, R11_2, R11_3, R11_4 | 0603 | 4 | 0 |  | Multicomp | MCMR06X1201FTL | Volume Production | Farnell | 2073370 | 0.00953 | 0.09535
 | 806R | SMD Resistor 806R 0603 | R12_1, R12_2, R12_3, R12_4 | 0603 | 4 | 0 |  | Panasonic | ERJ-3EKF8060V | Volume Production | Farnell | 2059324 | 0.08059 | 0.80589
 | 2k | SMD Resistor 2k 0603 | R13_1, R13_2, R14_1, R14_2 | 0603 | 4 | 0 |  | Panasonic | ERJ-3EKF2001V | Volume Production | Farnell | 2059343 | 0.08399 | 0.83985
 | 120R | SMD Resistor 120R 0603 | R15_1, R15_2, R15_3, R15_4 | 0603 | 4 | 0 |  | Yageo | RC0805FR-07120RL | Volume Production | Digi-Key | 311-120CRCT-ND | 0.1 | 0.4
 | 0R | SMD Resistor 10m 0805 | R16, R57, R113, R123 | 0805 | 4 | 0 |  | Yageo | RC0805JR-130RL | Volume Production | Mouser | 603-RC0805JR-130RL | 0.026 | 0.26
 | 10k | SMD Resistor 10k 0603 | R17, R24, R34, R35, R41, R70, R73, R74, R75, R78, R79, R80, R83, R84, R86, R92, R93, R94, R95, R96, R99, R101, R115, R134, R138, R139, R140, R141, R142, R143 | 0603 | 30 | 0 |  | MULTICOMP PRO | MCMR06X1002FTL |  | Farnell | 2073349 | 0.00977 | 0.29316
 | CRCW0603100RFKEA | RES, 100, 1%, 0.1 W, 0603 | R21_1, R21_2, R33_1, R33_2 |  | 4 | 0 |  | Vishay Dale | CRCW0603100RFKEA | Volume Production | Digi-Key | 541-100HCT-ND | 0.034 | 0.34
 | 20k | SMD Resistor 20k 0603 | R23_1, R23_2 | 0603 | 2 | 0 |  | Panasonic | ERJ3EKF2002V | Volume Production | Farnell | 2059432 | 0.07889 | 0.78891
 | 100k | SMD Resistor 100k 0603 | R25, R58, R104, R109, R110, R117, R119, R126 | 0603 | 8 | 0 |  | Yageo | RC0603JR-13100KL | Volume Production | Arrow | RC0603JR-13100KL | 0.0141 | 0.141
 | 0R | SMD Resistor 0R 0402 | R31, R48, R64, R112 | 0402 | 4 | 0 |  | Yageo | RC0402JR-070RL | Volume Production | Digi-Key | 311-0.0JRCT-ND | 0.013 | 0.13
 | CRCW0603158KFKEA | RES, 158 k, 1%, 0.1 W, AEC-Q200 Grade 0, 0603 | R39_1, R39_2 |  | 2 | 0 |  | Vishay | CRCW0603158KFKEA | Volume Production | Digi-Key | 541-158KHCT-ND | 0.1 | 0.2
 | 10R | SMD Resistor 10R 0603 | R40, R85, R132 | 0603 | 3 | 0 |  | Multicomp | MCMR06X10R0FTL | Volume Production | Farnell | 2073361 | 0.01842 | 0.18425
 | CRCW0603130KFKEA | RES, 130 k, 1%, 0.1 W, AEC-Q200 Grade 0, 0603 | R44_1, R44_2 |  | 2 | 0 |  | Vishay | CRCW0603130KFKEA | Volume Production | Digi-Key | 541-130KHCT-ND | 0.1 | 0.2
 | CRCW060312K1FKEA | RES, 12.1 k, 1%, 0.1 W, 0603 | R45_1, R45_2 |  | 2 | 0 |  | Vishay | CRCW060312K1FKEA | Volume Production | Digi-Key | 541-12.1KHCT-ND | 0.1 | 0.2
 | 430R | SMD Resistor 430R 0603 | R46, R87 | 0603 | 2 | 0 |  | Multicomp | MCSR06X4300FTL | Volume Production | Farnell | 2074259 | 0.01162 | 0.11625
 | 10.7k | SMD Resistor 10.7k 0402 | R47 | 0402 | 1 | 0 |  | Multicomp | MC00625W0402110K7 | Volume Production | Element14 | 1803139 | 0.00148 | 0.07397
 | 26.1k | SMD Resistor 26.1k 0402 | R49, R63 | 0402 | 2 | 0 |  | Samsung | RC1005F2612CS | Volume Production | Arrow | RC1005F2612CS | 0.0054 | 0.0108
 | 49k9 | SMD Resistor 49.9k 0402 | R50, R65 | 0402 | 2 | 0 |  | Multicomp | MCMR04X4992FTL | Volume Production | Element14 | 2073088 | 0.00959 | 0.09593
 | 100k | SMD Resistor 100k 0402 | R51 | 0402 | 1 | 0 |  | Vishay Dale | CRCW0402100KJNTD | Volume Production | Arrow | CRCW0402100KJNTD | 0.0063 | 0.0063
 | 300R | SMD Resistor 330R 0603 | R52 | 0805 | 1 | 0 |  | Vishay | CRCW1206300RFKEA | Volume Production | Digi-Key | 541-300FCT-ND | 0.1 | 0.1
 | 374k | SMD Resistor 374k 0402 | R53, R66 | 0402 | 2 | 0 |  | Stackpole Electronics | RMCF0402FT374K | Volume Production | Digi-Key | RMCF0402FT374KDKR-ND | 0.014 | 0.14
 | 0.47 | SMD Resistor 0R47 0402 | R59 | 0402 | 1 | 0 |  | Yageo | RC0402JR-071ML | Volume Production | Digi-Key | 311-1.0MJRDKR-ND | 0.1 | 0.1
 | 30k | SMD Resistor 30k 0402 | R67 | 0402 | 1 | 0 |  | TE Connectivity | CRG0402F30K | Volume Production | Element14 | 2331508 | 0.00754 | 0.07537
 | 56k | SMD Resistor 49.9k 0402 | R68 | 0402 | 1 | 0 |  | Yageo | RC0402FR-0756KL | Volume Production | Digi-Key | 311-56.0KLRDKR-ND | 0.1 | 0.1
 | 49k9 | SMD Resistor 49.9k 0402 | R69 | 0402 | 1 | 0 |  | Multicomp | MCMR04X4992FTL | Volume Production | Element14 | 2073088 | 0.00959 | 0.09593
 | 40R | SMD Resistor 120R 0603 | R71 | 0805 | 1 | 0 |  | MULTICOMP PRO | MCMR06X1200FTL |  | Farnell | 2073369 | 0.01818 | 0.18176
 | 20k | SMD Resistor 120R 0603 | R72 | 0805 | 1 | 0 |  | MULTICOMP PRO | MCMR06X1200FTL |  | Farnell | 2073369 | 0.01818 | 0.18176
 | 47R | SMD Resistor 47R 0603 | R76, R77, R81, R82, R89, R90, R97, R98 | 0603 | 8 | 0 |  | Panasonic | ERJ-3EKF47R0V | Volume Production | Farnell | 2303030 | 0.03696 | 0.36964
 | 100k | SMD Resistor 100k 0603 | R88, R91, R108 | 0603 | 3 | 0 |  | Yageo | RC0603JR-13100KL | Volume Production | Arrow | RC0603JR-13100KL | 0.0141 | 0.141
 | 47k | SMD Resistor 47k 0603 | R100 | 0603 | 1 | 0 |  | Multicomp | MCMR06X4702FTL | Volume Production | Farnell | 2073510 | 0.01006 | 0.10057
 | 10R | SMD Resistor 10R 0603 | R118, R120, R121, R122 | 0603 | 4 | 0 |  | Multicomp | MCMR06X10R0FTL | Volume Production | Farnell | 2073361 | 0.01842 | 0.18425
 | CRCW120660R4FKEA | RES, 60.4, 1%, 0.25 W, 1206 | R124_1, R124_2, R125_1, R125_2 |  | 4 | 0 |  | Vishay | CRCW120660R4FKEA | Volume Production | Digi-Key | 541-60.4FCT-ND | 0.1 | 0.4
 | 4k7 | SMD Resistor 4.7k 0603 | R127, R128 | 0603 | 2 | 0 |  | Yageo | RC0603FR-104K7L | Volume Production | Arrow | RC0603FR-104K7L | 0.0488 | 0.0976
 | 10M | SMD Resistor 10M 0603 | R129 | 0603 | 1 | 0 |  | Samsung | RC1608J106CS | Volume Production | Arrow | RC1608J106CS | 0.0071 | 0.0071
 | 1k | SMD Resistor 1k 0603 | R137 | 0603 | 1 | 0 |  | Panasonic | ERJ-1GEJ102C | Volume Production | Arrow | ERJ-1GEJ102C | 0.0423 | 0.0423
 | KMR221GLFS | Microminiature Tactile Switch | S1, S2 |  | 2 | 0 |  | ITT C&K | KMR221GLFS | Volume Production | Digi-Key | 401-1427-6-ND | 0.52 | 1.04
 | YA8779-BL | Transformer, 30 uH, SMD | T1_1, T1_2 |  | 2 | 0 |  | Coilcraft | YA8779-BLD
 | BSS84P | P-Channel SIPMOS Small-Signal-Transistor, -60 V VDS, -0.17 A ID, -55 to 150 degC, PG-SOT23, Reel, Green | T2, T4, T5, T7 |  | 4 | 0 |  | Infineon | BSS84P | Volume Production | Digi-Key | BSS84PH6327XTSA2CT-ND | 0.34 | 1.36
 | IRLML0100TRPBF | MOSFET-Transistor, n-Kanal, 1.6 A, 100 V, 0.178 ohm, 10 V, 2.5 V | T3, T6, T9 |  | 3 | 0 |  | International Rectifier | IRLML0100TRPBF | Volume Production | Digi-Key | IRLML0100TRPBFCT-ND | 0.52 | 1.56
 | SS/BIAS | Test Point, Miniature, SMT | TP9_1, TP9_2 |  | 2 | 0 |  |  |  |  | Digi-Key | 36-5015TR-ND
 | HX1188NL | 10/100 Base-T Single Port Surface Mount Magnetic with Turns Ratio, -40 to 85 degC, 16-Pin Module, RoHS, Tube | TR1, TR2 |  | 2 | 0 |  | Pulse | HX1188NLT | Volume Production | Digi-Key | 553-1536-6-ND | 5.17 | 10.34
 | TPS62142RGTR | Imported | U1_1, U1_2 |  | 2 | 0 |  | Texas Instruments | TPS62142RGTR | Volume Production | TI store | TPS62142RGTR | 1.65 | 3.3
 | STM32F429VIT6 | ARM Cortex-M4 32-bit MCU+FPU, 225 DMIPS, 2048 kB Flash, 256 kB Internal RAM, 82 I/Os, 100-pin LQFP, -40 to 85 degC, Tray | U2 |  | 1 | 0 |  | STMicroelectronics | STM32F429VIT6 | Volume Production | LCSC | C92002 | 9.19 | 9.19
 | LTC6820IUD#PBF | IsoSPI Isolated Communication Interface, 2.7 to 5.5 V, -40 to 85 degC, 16-Pin QFN (UD-16EPV-AA), Pb-Free | U3_1, U3_2, U3_3, U3_4 |  | 4 | 0 |  | Analog Devices / Linear Technology | LTC6820IUD#PBF | Volume Production | Digi-Key | LTC6820IUD#PBF-ND | 5.56 | 22.24
 | SN74LVC00ARGYR | Quadruple 2-Input Positive-NAND Gate, RGY0014A, LARGE T&R | U4_1, U4_2 |  | 2 | 0 |  | Texas Instruments | SN74LVC00ARGYR | Volume Production | Digi-Key | 296-13954-6-ND | 0.46 | 0.92
 | LM3724IM5-3.08/NOPB | 5-Pin Microprocessor Reset Circuits, 5-pin SOT-23, Pb-Free | U7, U17 |  | 2 | 0 |  | TI National Semiconductor | LM3724IM5-3.08/NOPB | Volume Production | Digi-Key | LM3724IM5-3.08/NOPBDKR-ND | 2.01 | 4.02
 | AQY212GHA | PhotoMOS GU 1 Form A, 60 V Load Voltage, 1.1 A Continuous Load Current, -40 to 85 degC, 4-Pin DIP(SMT), Tube, RoHS | U8, U11, U21, U24 |  | 4 | 0 |  | Panasonic | AQY212GHAX | Volume Production | Mouser | 667-AQY212GHAX | 1.81 | 7.24
 | LM5180QNGURQ1 | 70-V PSR Flyback Converter With 100-V, 1.2-A Power Switch and Ultra-Low IQ, NGU0008C (WSON-8) | U12_1, U12_2 |  | 2 | 0 |  | Texas Instruments | LM5180NGUR |  | TI store | LM5180NGUR | 5.59 | 11.18
 | TPS26602RHFR | 37V Clamped input protection | U13 |  | 1 | 0 |  | Texas Instruments | TPS26602RHFR |  | TI store | TPS26602RHFR | 4.62 | 4.62
 | ISO7762DBQR | Imported | U14 |  | 1 | 0 |  | Texas Instruments | ISO7762DBQR |  | Digi-Key | 296-49451-6-ND | 3.73 | 3.73
 | TVS3301DRBR | TVS3301 33-V Bidirectional Flat-Clamp Surge Protection Device | U15, U20 |  | 2 | 0 |  | Texas Instruments | TVS3301DRBR |  | Digi-Key | 296-53063-1-ND | 0.84 | 1.68
 | LM536013QDSXRQ1 | Imported | U16 |  | 1 | 0 |  | Texas Instruments | LM536013QDSXRQ1 |  | Mouser | 595-LM536013QDSXRQ1 | 4.57 | 4.57
 | LT3092EDD#TRPBF | 200 mA Two-Terminal Programmable Current Source, 0.3 mA Isupply, 8-pin SON (DD-8), -40 to 125 degC, Pb-Free, Tape and Reel | U18 |  | 1 | 0 |  | Analog Devices / Linear Technology | LT3092EDD#TRPBF | Volume Production | Digi-Key | LT3092EDD#TRPBFDKR-ND | 4.25 | 4.25
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

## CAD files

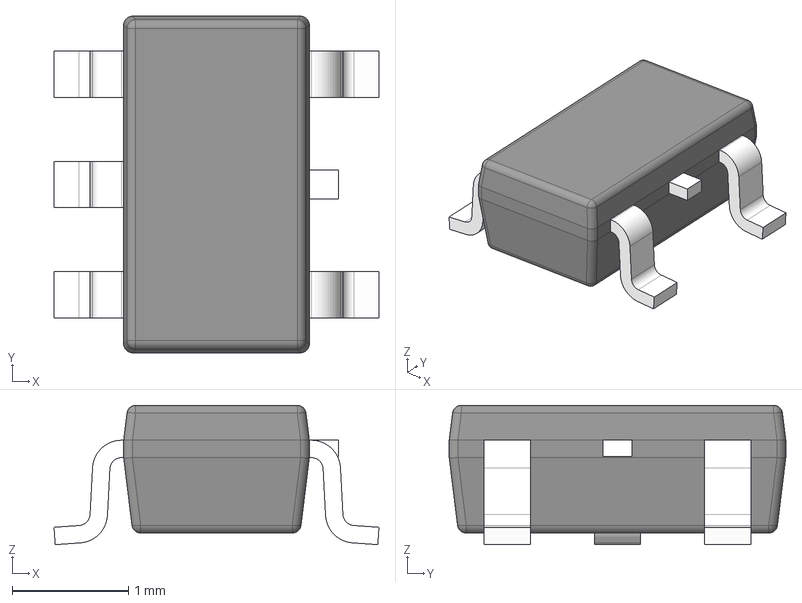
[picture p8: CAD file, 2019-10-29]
hardware/datasheets/Imports/DBV0005A.stp
2.80 x 2.90 x 1.20 mm
BODY-SOT
LEAD-SOT x 5
LEAD-DUMMY

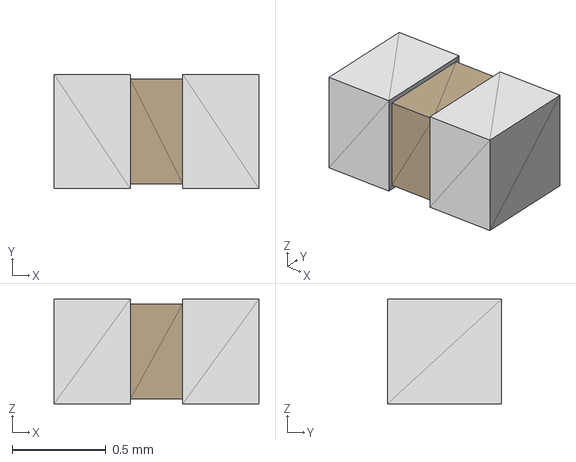
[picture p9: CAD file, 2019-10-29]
hardware/datasheets/WBDesign20_AltiumDesigner/ExportFiles/Board/Altium/2019-07-21_03-32-53/0402.stp
1.09 x 0.61 x 0.559 mm

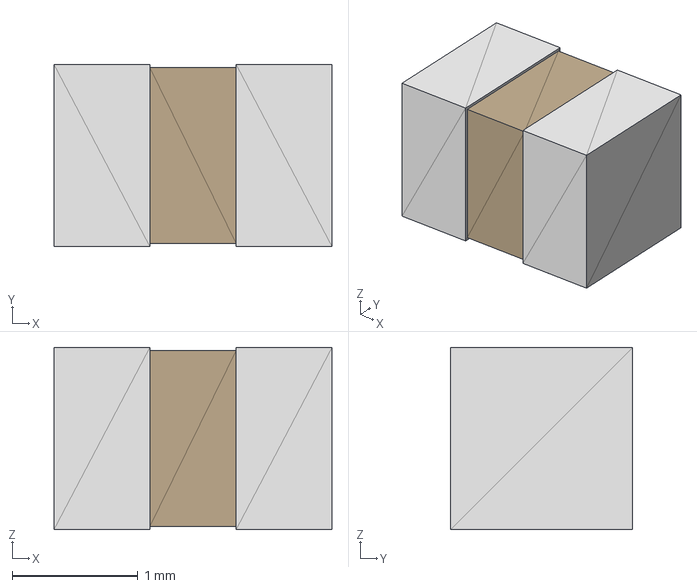
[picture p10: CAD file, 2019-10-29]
hardware/datasheets/WBDesign20_AltiumDesigner/ExportFiles/Schematic/webench_schematic_exchange_design_2304964_20_Altium/Altium/2019-07-21_03-32-45/0805.stp
2.21 x 1.45 x 1.45 mm

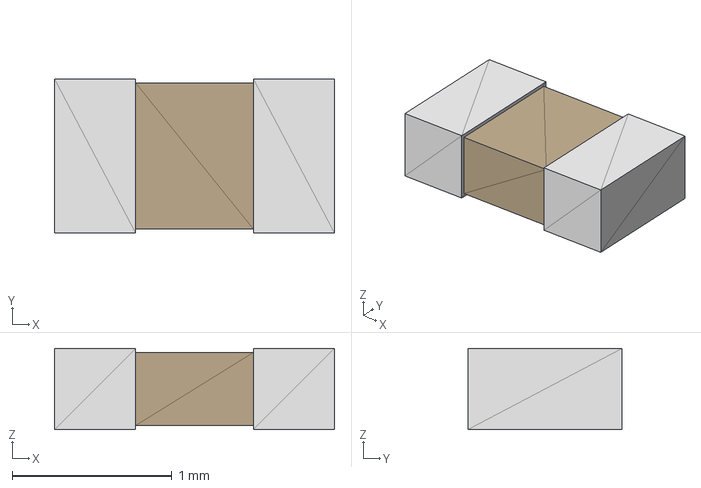
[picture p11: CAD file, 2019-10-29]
hardware/datasheets/WBDesign23/Altium/2019-07-21_05-20-36/0603.stp
1.75 x 0.965 x 0.508 mm

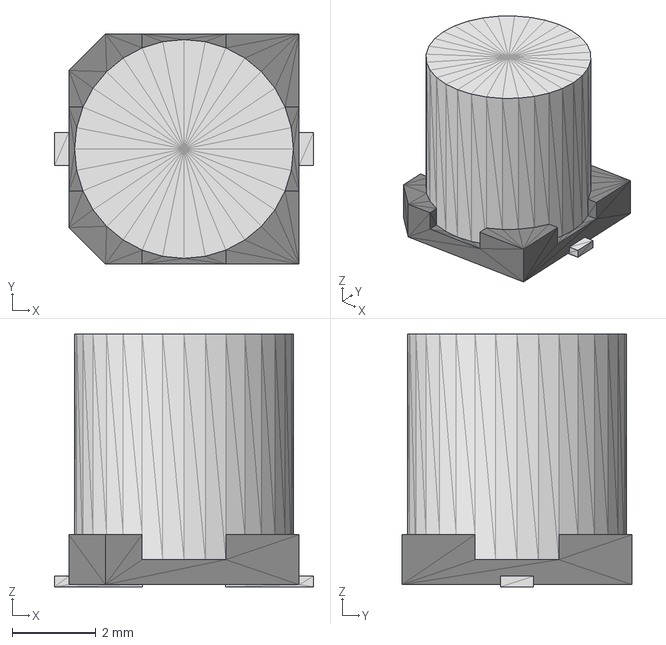
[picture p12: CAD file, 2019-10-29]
hardware/datasheets/WBDesign23/Altium/2019-07-21_05-20-38/SM_RADIAL_5MM.stp
6.20 x 5.51 x 6.05 mm

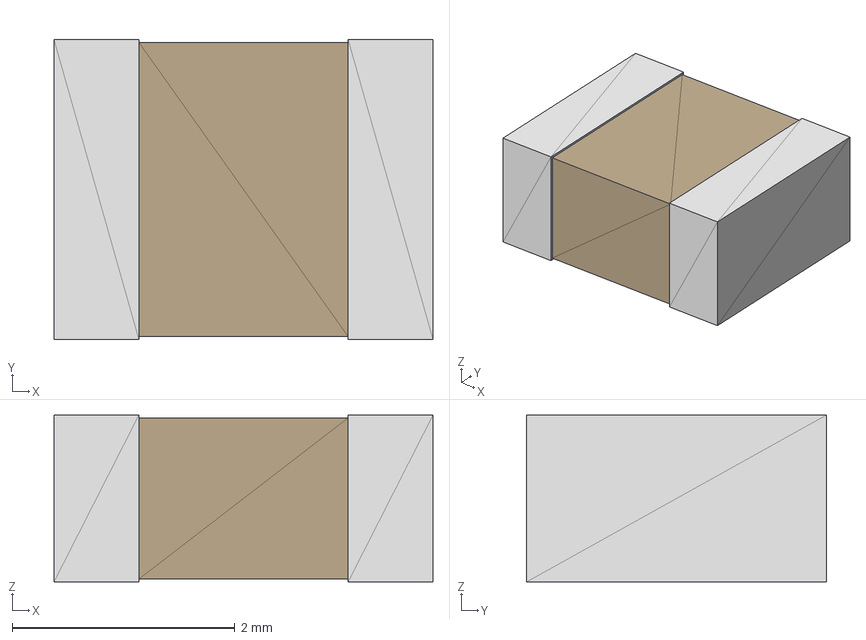
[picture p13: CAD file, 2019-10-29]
hardware/datasheets/WBDesign24_AltiumDesigner/ExportFiles/Schematic/Altium/2019-07-21_05-52-01/1210.stp
3.40 x 2.69 x 1.50 mm

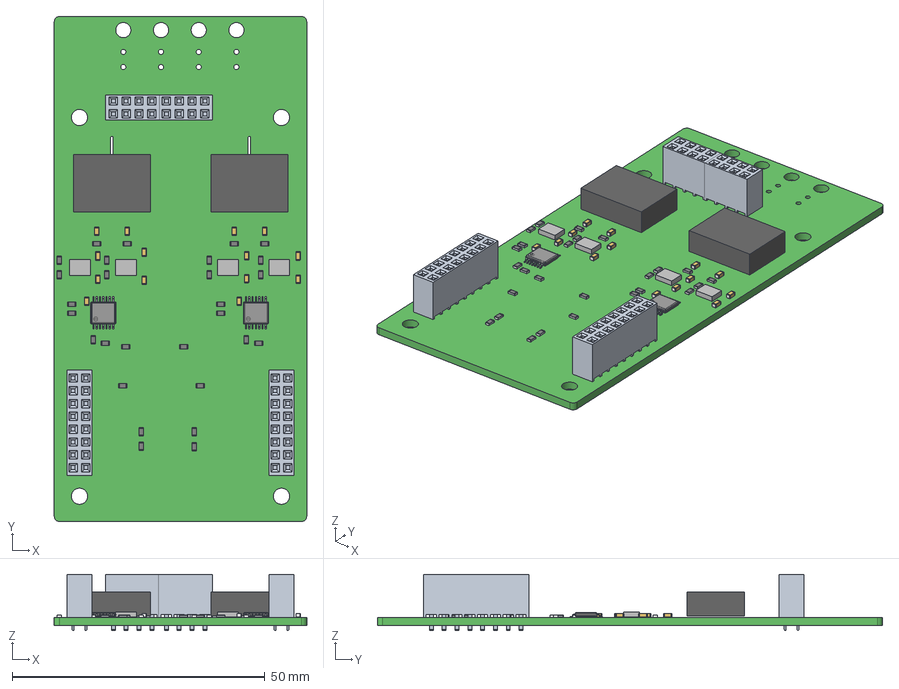
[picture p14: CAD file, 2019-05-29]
hardware/hw-interface-ltc6820/v1.9.3/Assembly default/Export STEP/interface(default).step
50.0 x 100.0 x 11.2 mm
Board
Mid_Body x 28
Open_CASCADE_STEP_translator_6.8_9.2.1 x 56
Mark x 28
SSW-104-01-X-D x 2
Extruded x 6
BODY_MTC14 x 2
LEAD_MTC14 x 28
Open_CASCADE_STEP_translator_6.8_2.1.1 x 14
Open_CASCADE_STEP_translator_6.8_2.1.2 x 14
Open_CASCADE_STEP_translator_6.8_2.2.1 x 14
SSW-108-01-X-D x 2

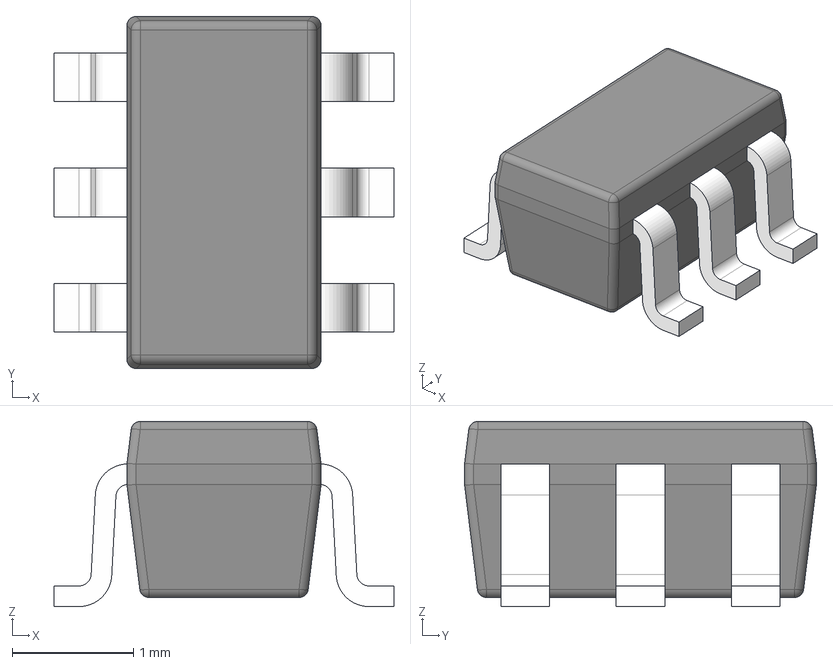
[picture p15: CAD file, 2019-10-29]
hardware/datasheets/Imports/DBV0006A.stp
2.80 x 2.90 x 1.52 mm
LEAD x 6

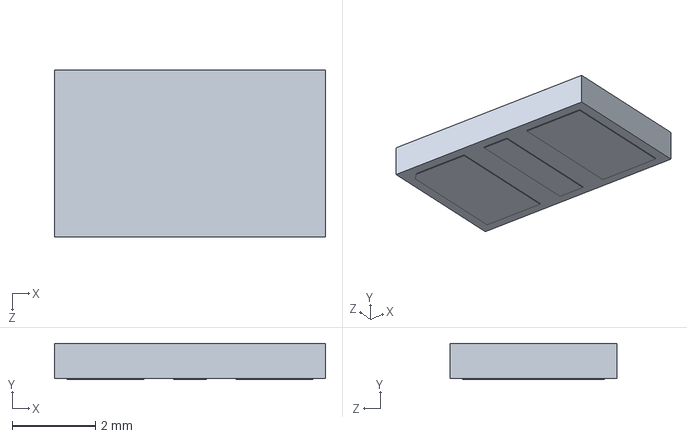
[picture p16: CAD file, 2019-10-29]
hardware/datasheets/tbu-ca.stp
6.50 x 0.875 x 4.00 mm

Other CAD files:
hardware/datasheets/WBDesign20_AltiumDesigner/ExportFiles/Schematic/webench_schematic_exchange_design_2304964_20_Altium/Altium/2019-07-21_03-32-47/0402.stp
hardware/datasheets/WBDesign21_AltiumDesigner/ExportFiles/Schematic/Altium/2019-07-21_03-39-47/0805.stp
hardware/datasheets/WBDesign21_AltiumDesigner/ExportFiles/Schematic/Altium/2019-07-21_03-39-48/0402.stp
hardware/datasheets/WBDesign24_AltiumDesigner/ExportFiles/Schematic/Altium/2019-07-21_05-52-03/1210.stp
hardware/datasheets/WBDesign20_AltiumDesigner/ExportFiles/Board/Altium/2019-07-21_03-32-53/0603.stp
hardware/datasheets/WBDesign20_AltiumDesigner/ExportFiles/Schematic/webench_schematic_exchange_design_2304964_20_Altium/Altium/2019-07-21_03-32-45/0603.stp
hardware/datasheets/WBDesign20_AltiumDesigner/ExportFiles/Schematic/webench_schematic_exchange_design_2304964_20_Altium/Altium/2019-07-21_03-32-47/0805.stp
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

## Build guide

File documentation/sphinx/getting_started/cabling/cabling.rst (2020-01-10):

.. include:: ../../macros.rst

.. _GETTING_STARTED_CABLING:

================
Cabling |foxbms|
================

In the preceding sections, the |master| has been connected to the power supply
and the |foxbms| firmware flashed on the |MCU0| and |MCU1|. This section
describes the |foxbms| hardware in more details and how to connect the |master|
to the |slaves| that perform the cell voltage and temperature measurements. The
CAN communication is also described.

.. note::

    When the connection is made between the |master| and the |slaves|, both
    primary and secondary isoSPI daisy chains have to be connected.

.. _sec-connector-convention:

----------------------------------
Convention for Connector Numbering
----------------------------------

:numref:`Fig. %s <connector_convention>` presents the convention for the
connector numbering. It is used throughout the documentation.

.. _connector_convention:


   Supply connector pin out, receptable - rear view, header - front view
   (image source: MOLEX)

There are two types of connectors:

 * Header
 * Receptable, plugged into the header

The numbering shown on the left in :numref:`fig. %s <connector_convention>`
is always valid when viewing in the direction indicated by the arrow with the
indication ``viewing direction``. This must be taken into account when crimping
the receptables.

-------------------------------------------
Global Description of the |foxbms| Hardware
-------------------------------------------

The |foxbms| system can be mounted in a metal housing, shown in
:numref:`fig. %s <housing>`.

.. _housing:


   |master| housing

In this configuration, the top plate can be removed to have access to the
|foxbms| electronic boards. This is done by unscrewing the four screws holding
the top plate.

The open housing is shown in :numref:`fig. %s <housing_open>`.

.. _housing_open:


   |master| housing, top plate removed

The boards can be removed from the housing. The boards without housing are
shown in :numref:`fig. %s <foxbms_stack>`. To start, it is not necessary to
remove the boards from the housing, but it is helpful to be able to look at the
LEDs located on the |BMS-Master|.

.. _foxbms_stack:


   |foxbms| board stack removed from the housing (both |BMS-Master| and
   |BMS-Interface| are shown)

:numref:`Fig. %s <housing_detail>` shows how to put the boards back in the
housing.

.. _housing_detail:


   Introduction of the board stack in the |Master| housing

------------------------------------------
Detailed Description of the Hardware Parts
------------------------------------------

The heart of |foxbms| is the |BMS-Master|, shown in
:numref:`fig. %s <foxbms_master>`.

.. _foxbms_master:


   |foxbms| |BMS-Master|

As shown in :numref:`fig. %s <foxbms_master>`, the |BMS-Master| has two
microcontroller units (MCU):

 - Primary (also called |MCU0|)
 - Secondary (also called |MCU1|)

Primary is the MCU where the |foxbms| software is run. The secondary MCU is
present for redundant safety when developing software code on the primary MCU.

Each MCU has a set of LEDs, as shown in :numref:`fig. %s <foxbms_master>`:

 - Power LED
 - Red indicator LED
 - Green indicator LED

The power LED must lit when power is supplied to the |BMS-Master|, and the
indicator LEDs should blink, except during flashing of software on the MCU.

If a debugger is used, it must be connected to the debug port (i.e.,
JTAG-interface) corresponding to the MCU being used.

An extension board named |BMS-Extension| is present under the |BMS-Master| and
is shown in :numref:`fig. %s <foxbms_extension>`.

.. _foxbms_extension:


   |foxbms| |BMS-Extension|

It is used to provide more I/O and interfaces than with the |BMS-Master| alone.

The |BMS-Interface| is located on top of the |BMS-Master| (shown in
:numref:`fig. %s <foxbms_interface>`).

.. _foxbms_interface:


   |foxbms| |BMS-Interface|

Its purpose is to convert the signals sent by the Serial Peripheral Interface
(SPI) of the |BMS-Master| to the first |BMS-Slave| in the daisy by using a
proprietary isoSPI interface from Linear Technology.

An example of a |BMS-Slave| is shown in :numref:`fig. %s <foxbms_slave>`.

.. _foxbms_slave:


   |foxbms| |BMS-Slave|

The |BMS-Slave| is based on the |LTC| battery cell monitoring chip. More
information on the |LTC| integrated circuit can be found in the datasheet
([ltc_datasheet6804]_ and [ltc_datasheet6811]_). It supervises up to 12 battery
cells connected in series. It performs voltage measurements, temperature
measurements and passive cell balancing. In the daisy chain, the |BMS-Slaves|
are connected via differential pair cables.

The |BMS-Slave| is not designed to be used in a specific housing.

-----------------------------------
Use of |foxbms| in a Battery System
-----------------------------------

:numref:`Fig. %s <hw_description>` present the organization of the hardware.
The system consists of :math:`n` battery modules and :math:`m` |BMS-Slaves|.
Each |BMS-Slave| is connected to a battery module, where it measures cell
voltages and cell temperatures. The |BMS-Slaves| are connected in a daisy chain
configuration: when a data package is sent to the daisy chain, it is first
received by slave 1, which transmits it to slave 2 and so on until the data
package is received by the last |BMS-Slave|.

.. _hw_description:


   |foxbms| in the battery system

The |BMS-Interface| converts the messages sent by the |BMS-Master| so that they
can be transmitted to the daisy chain and vice versa.

The |master| communicates with the current sensor (for instance,
Isabellenhuette IVT-MOD or IVT-S) via CAN.

Communication with the control unit (for instance, a personal computer), is
also made via CAN.

------------------------------------------------------
Hardware Setup of the |BMS-Master| and the |BMS-Slave|
------------------------------------------------------

:numref:`Fig. %s <foxbmsfront_quickstart>` presents all the connectors of the
|BMS-Master|.

.. _foxbmsfront_quickstart:


   Front view of the foxBMS Master, indicating the location of each header

The connectors needed for this quickstart guide are indicated in the following
parts.

Connecting the |BMS-Slave| to the |BMS-Master|
----------------------------------------------

.. note::

      When the connection is made between the |BMS-Master| and the |BMS-Slave|,
      two communication lines have to be connected: the primary and the
      secondary daisy chain.

The pin assignments and cabling instructions for all different |BMS-Slaves| are
documented in section :ref:`hw_slave`.

CAN Connector
-------------

The connector indicated as ``CAN 0`` in
:numref:`fig. %s <foxbmsfront_quickstart>` must be used on the |BMS-Master|.
Its layout is described in :numref:`table %s <master_CAN>`.



.. _master_CAN:

.. table:: Master CAN connection

   ====    =========    =============    ============
   Pin     Signal       Direction        Description
   ====    =========    =============    ============
   1       GND_EXT0     Output
   2       NC           --
   3       CAN0_L       Input/Output
   4       CAN0_H       Input/Output
   ====    =========    =============    ============

Ground of |CAN0| is shared with supply ground ``GND_EXT0``. |CAN0| is isolated
from the |MCU0| via the isolated CAN transceiver TJA1052. The CAN transceiver
may be put into standby mode by |MCU0|.

-----------------------------------
Communication with the |BMS-Master|
-----------------------------------

Once |foxbms| is running, CAN messages should be sent.

.. note::

      **A periodic state request must be made to the system by sending a
      message with ID 0x152 on the bus CAN periodically.**
      If not, the system will go into an error state. The period must be 100ms.
      More information on state requests can be found in the section
      :ref:`getting_started_communicating_CAN`. Typically the request
      `Standby state` can be made.

If voltages have been applied to the voltage connector, they are sent with the
message IDs 0x550, 0x551, 0x552 and 0x553. Details can be found in the section
:ref:`getting_started_communicating_CAN`.

If temperature sensors have been connected and the conversion function changed
in the software, temperature are sent with the messages with IDs 0x353 and
0x354. Details can be found in the section
:ref:`getting_started_communicating_CAN`.

----------------------------
Current Sensor Configuration
----------------------------

Further information on the current sensor tested with |foxbms| can be found in
the `datasheet of the current sensor <http://www.isabellenhuette.de/uploads/media/IVT_Modular_datasheet_1.20_02.pdf>`_.
By default, |foxbms| uses the factory defaults of the current sensor, which
works in cyclic (non-triggered) mode.
Another possibility tested with |foxbms| is to use the current sensor in
triggered mode. For this, the current sensor IVT-MOD from Isabellenhuette has
to be reprogrammed. The changes compared to factory default are then:

 * The CAN Message IDs was changed
 * The triggered measurement mode was activated

The two following parts sum up the differences between factory setup and
triggered setup tested with |foxbms|.

Factory Default
---------------

* CAN IDs

  * 0x411 (dec: 1041) Command
  * 0x521 (dec: 1313) Current Measurement
  * 0x522 (dec: 1314) Voltage Measurement 1
  * 0x523 (dec: 1315) Voltage Measurement 2
  * 0x524 (dec: 1316) Voltage Measurement 3
  * 0x511 (dec: 1297) Response

* Measurement Mode: Cyclic (Disabled and Triggered are other possible modes)

After Configuration
-------------------

* CAN IDs

  * 0x35B (dec: 859) Command
  * 0x35C (dec: 860) Current Measurement
  * 0x35D (dec: 861) Voltage Measurement 1
  * 0x35E (dec: 862) Voltage Measurement 2
  * 0x35F (dec: 863) Voltage Measurement 3
  * 0x7FF (dec: 2047) Response

* Measurement Mode: Triggered

-------------------------------------------
Hardware Related Frequently Asked Questions
-------------------------------------------

Are the schematic and layout source files available?
----------------------------------------------------

Yes, the complete |foxbms| schematic and layout files are available in EAGLE
format on GitHub. Refer to the HTML documentation section
:ref:`hardware_design_resources`.

Have both |MCU0| and |MCU1| to be connected?
-------------------------------------------------------

Yes, they should always be connected and configured to provide redundant
monitoring and improved safety during software development in prototyping
applications.

.. [ltc_datasheet6804] LTC6804 Datasheet http://cds.linear.com/docs/en/datasheet/680412fb.pdf
.. [ltc_datasheet6811] LTC6811 Datasheet http://cds.linear.com/docs/en/datasheet/68111f.pdf

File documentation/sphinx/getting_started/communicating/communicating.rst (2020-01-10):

.. include:: ../../macros.rst

.. _GETTING_STARTED_COMMUNICATING:

===========================
Communicating with |foxbms|
===========================

.. _getting_started_communicating_CAN:

Communicating over CAN
~~~~~~~~~~~~~~~~~~~~~~

The table :ref:`CANMsgs` shows the CAN messages sent and received by the BMS with their respective names and IDs, the direction and a short comment.

The table :ref:`CANSgnls` gives the CAN signals sent and received in these messages.

To add or change a signal it must be refered to the software FAQ: :ref:`faq_can_manually_add`.

.. note::

    18 cell voltages, 12 cell temperatures and 8 modules are configured in the default CAN configuration of the |foxbms| Software.

If less then 8  modules, 18 cell voltages or 12 temperature sensors are configured in the software (e.g., in ``batterysystem_cfg.h``),
default values are transmitted on these messages/signals. These values from the unused CAN messages must simply be ignored.

In case it is really wanted to not transmit these values, the configuration of the CAN module must be changed as shown in the software FAQ in
:ref:`faq_can_lessthan8modules` and in :ref:`faq_can_lessthan18cells`. The configuration must also be changed if more than 8 modules,
18 cell voltages or 12 temperature sensors are used.

.. _CANMsgs:

CAN Messages
------------

Message names in the DBC file can vary from the following tables in order to be compliant with the 32 character limit of DBC files.

**RX Messages:**

+-----------------------+----------------+---------+---------------+----------------------------------------+
| **Message Name**      | **Message ID** | **DLC** | **Direction** | **Description**                        |
+-----------------------+----------------+---------+---------------+----------------------------------------+
| CAN0_Software_Reset   | 0x95           | 8       | RX            | Perform software reset                 |
+-----------------------+----------------+---------+---------------+----------------------------------------+
| CAN0_Debug_Message    | 0x100          | 8       | RX            | Debug message                          |
+-----------------------+----------------+---------+---------------+----------------------------------------+
| CAN0_State_Request    | 0x120          | 8       | RX            | State request                          |
+-----------------------+----------------+---------+---------------+----------------------------------------+
| CAN0_IVT_Current      | 0x35C/0x521    | 6       | RX            | Current Sensing Current Value          |
+-----------------------+----------------+---------+---------------+----------------------------------------+
| CAN0_IVT_Voltage_1    | 0x35D/0x522    | 6       | RX            | Current Sensing Voltage 1              |
+-----------------------+----------------+---------+---------------+----------------------------------------+
| CAN0_IVT_Voltage_2    | 0x35E/0x523    | 6       | RX            | Current Sensing Voltage 2              |
+-----------------------+----------------+---------+---------------+----------------------------------------+
| CAN0_IVT_Voltage_3    | 0x35F/0x524    | 6       | RX            | Current Sensing Voltage 3              |
+-----------------------+----------------+---------+---------------+----------------------------------------+
| CAN0_IVT_Temperature  | 0x525          | 6       | RX            | Current Sensing Temperature            |
+-----------------------+----------------+---------+---------------+----------------------------------------+
| CAN0_IVT_Power        | 0x526          | 6       | RX            | Current Sensing Power                  |
+-----------------------+----------------+---------+---------------+----------------------------------------+
| CAN0_IVT_CoulombCount | 0x527          | 6       | RX            | Current Sensing Coulomb Counting Value |
+-----------------------+----------------+---------+---------------+----------------------------------------+
| CAN0_IVT_EnergyCount  | 0x528          | 6       | RX            | Current Sensing Energy Counting Value  |
+-----------------------+----------------+---------+---------------+----------------------------------------+
| CAN0_GetReleaseVersion| 0x777          | 8       | RX            | Request software version               |
+-----------------------+----------------+---------+---------------+----------------------------------------+

**TX Messages:**

+-----------------------------+----------------+---------+---------------+----------------------------------------+
| **Message Name**            | **Message ID** | **DLC** | **Direction** | **Description**                        |
+-----------------------------+----------------+---------+---------------+----------------------------------------+
| CAN0_MSG_Boot               | 0x101          | 8       | TX            | BMS booting successful                 |
+-----------------------------+----------------+---------+---------------+----------------------------------------+
| CAN0_MSG_SystemState_0      | 0x110          | 8       | TX            | BMS system state 0                     |
+-----------------------------+----------------+---------+---------------+----------------------------------------+
| CAN0_MSG_SystemState_1      | 0x111          | 8       | TX            | BMS system state 1                     |
+-----------------------------+----------------+---------+---------------+----------------------------------------+
| CAN0_MSG_SystemState_2      | 0x112          | 8       | TX            | BMS system state 2                     |
+-----------------------------+----------------+---------+---------------+----------------------------------------+
| CAN0_MSG_SlaveState_0       | 0x115          | 8       | TX            | BMS slave state 0                      |
+-----------------------------+----------------+---------+---------------+----------------------------------------+
| CAN0_MSG_SlaveState_1       | 0x116          | 8       | TX            | BMS slave state 1                      |
+-----------------------------+----------------+---------+---------------+----------------------------------------+
| CAN0_RecOperatingCurrent    | 0x130          | 8       | TX            | Recommended operating current          |
+-----------------------------+----------------+---------+---------------+----------------------------------------+
| CAN0_SOP                    | 0x131          | 8       | TX            | State-of-power                         |
+-----------------------------+----------------+---------+---------------+----------------------------------------+
| CAN0_SOC                    | 0x140          | 8       | TX            | State-of-charge                        |
+-----------------------------+----------------+---------+---------------+----------------------------------------+
| CAN0_SOH                    | 0x150          | 8       | TX            | State-of-health                        |
+-----------------------------+----------------+---------+---------------+----------------------------------------+
| CAN0_SOE                    | 0x160          | 8       | TX            | State-of-energy                        |
+-----------------------------+----------------+---------+---------------+----------------------------------------+
| CAN0_MinMaxCellVoltages     | 0x170          | 8       | TX            | Cell voltages Max Min Mean             |
+-----------------------------+----------------+---------+---------------+----------------------------------------+
| CAN0_SOV                    | 0x171          | 8       | TX            | State-of-voltage                       |
+-----------------------------+----------------+---------+---------------+----------------------------------------+
| CAN0_MinMaxCellTemperatures | 0x180          | 8       | TX            | Cell temperatures Max Min Mean         |
+-----------------------------+----------------+---------+---------------+----------------------------------------+
| CAN0_Tempering              | 0x190          | 8       | TX            | Cooling/Heating                        |
+-----------------------------+----------------+---------+---------------+----------------------------------------+
| CAN0_Insulation             | 0x1A0          | 8       | TX            | Insulation                             |
+-----------------------------+----------------+---------+---------------+----------------------------------------+
| CAN0_MovAveragePower_0      | 0x1D0          | 8       | TX            | Moving average power 0                 |
+-----------------------------+----------------+---------+---------------+----------------------------------------+
| CAN0_MovAveragePower_1      | 0x1D1          | 8       | TX            | Moving average power 1                 |
+-----------------------------+----------------+---------+---------------+----------------------------------------+
| CAN0_MovAveragePower_2      | 0x1D2          | 8       | TX            | Moving average power 2                 |
+-----------------------------+----------------+---------+---------------+----------------------------------------+
| CAN0_MovAverageCurrent_0    | 0x1E0          | 8       | TX            | Moving average current 0               |
+-----------------------------+----------------+---------+---------------+----------------------------------------+
| CAN0_MovAverageCurrent_1    | 0x1E1          | 8       | TX            | Moving average current 1               |
+-----------------------------+----------------+---------+---------------+----------------------------------------+
| CAN0_MovAverageCurrent_2    | 0x1E2          | 8       | TX            | Moving average current 2               |
+-----------------------------+----------------+---------+---------------+----------------------------------------+
| CAN0_PackVoltage            | 0x1F0          | 8       | TX            | Battery pack voltage                   |
+-----------------------------+----------------+---------+---------------+----------------------------------------+
| CAN0_Cell_voltage_M0_0      | 0x200          | 8       | TX            | Cell voltages module 0 cell 0 1 2      |
+-----------------------------+----------------+---------+---------------+----------------------------------------+
| CAN0_Cell_voltage_M0_1      | 0x201          | 8       | TX            | Cell voltages module 0 cell 3 4 5      |
+-----------------------------+----------------+---------+---------------+----------------------------------------+
| CAN0_Cell_voltage_M0_2      | 0x202          | 8       | TX            | Cell voltages module 0 cell 6 7 8      |
+-----------------------------+----------------+---------+---------------+----------------------------------------+
| CAN0_Cell_voltage_M0_3      | 0x203          | 8       | TX            | Cell voltages module 0 cell 9 10 11    |
+-----------------------------+----------------+---------+---------------+----------------------------------------+
| CAN0_Cell_voltage_M0_4      | 0x204          | 8       | TX            | Cell voltages module 0 cell 12 13 14   |
+-----------------------------+----------------+---------+---------------+----------------------------------------+
| CAN0_Cell_voltage_M0_5      | 0x205          | 8       | TX            | Cell voltages module 0 cell 15 16 17   |
+-----------------------------+----------------+---------+---------------+----------------------------------------+
| CAN0_Cell_temperature_M0_0  | 0x210          | 8       | TX            | Cell temperatures module 0 - 0 1 2     |
+-----------------------------+----------------+---------+---------------+----------------------------------------+
| CAN0_Cell_temperature_M0_1  | 0x211          | 8       | TX            | Cell temperatures module 0 - 3 4 5     |
+-----------------------------+----------------+---------+---------------+----------------------------------------+
| CAN0_Cell_temperature_M0_2  | 0x212          | 8       | TX            | Cell temperatures module 0 - 6 7 8     |
+-----------------------------+----------------+---------+---------------+----------------------------------------+
| CAN0_Cell_temperature_M0_3  | 0x213          | 8       | TX            | Cell temperatures module 0 - 9 10 11   |
+-----------------------------+----------------+---------+---------------+----------------------------------------+
| CAN0_Cell_voltage_M1_0      | 0x220          | 8       | TX            | Cell voltages module 1 cell 0 1 2      |
+-----------------------------+----------------+---------+---------------+----------------------------------------+
| CAN0_Cell_voltage_M1_1      | 0x221          | 8       | TX            | Cell voltages module 1 cell 3 4 5      |
+-----------------------------+----------------+---------+---------------+----------------------------------------+
| CAN0_Cell_voltage_M1_2      | 0x222          | 8       | TX            | Cell voltages module 1 cell 6 7 8      |
+-----------------------------+----------------+---------+---------------+----------------------------------------+
| CAN0_Cell_voltage_M1_3      | 0x223          | 8       | TX            | Cell voltages module 1 cell 9 10 11    |
+-----------------------------+----------------+---------+---------------+----------------------------------------+
| CAN0_Cell_voltage_M1_4      | 0x224          | 8       | TX            | Cell voltages module 1 cell 12 13 14   |
+-----------------------------+----------------+---------+---------------+----------------------------------------+
| CAN0_Cell_voltage_M1_5      | 0x225          | 8       | TX            | Cell voltages module 1 cell 15 16 17   |
+-----------------------------+----------------+---------+---------------+----------------------------------------+
| CAN0_Cell_temperature_M1_0  | 0x230          | 8       | TX            | Cell temperatures module 1 - 0 1 2     |
+-----------------------------+----------------+---------+---------------+----------------------------------------+
| CAN0_Cell_temperature_M1_1  | 0x231          | 8       | TX            | Cell temperatures module 1 - 3 4 5     |
+-----------------------------+----------------+---------+---------------+----------------------------------------+
| CAN0_Cell_temperature_M1_2  | 0x232          | 8       | TX            | Cell temperatures module 1 - 6 7 8     |
+-----------------------------+----------------+---------+---------------+----------------------------------------+
| CAN0_Cell_temperature_M1_3  | 0x233          | 8       | TX            | Cell temperatures module 1 - 9 10 11   |
+-----------------------------+----------------+---------+---------------+----------------------------------------+
| CAN0_Cell_voltage_M2_0      | 0x240          | 8       | TX            | Cell voltages module 2 cell 0 1 2      |
+-----------------------------+----------------+---------+---------------+----------------------------------------+
| CAN0_Cell_voltage_M2_1      | 0x241          | 8       | TX            | Cell voltages module 2 cell 3 4 5      |
+-----------------------------+----------------+---------+---------------+----------------------------------------+
| CAN0_Cell_voltage_M2_2      | 0x242          | 8       | TX            | Cell voltages module 2 cell 6 7 8      |
+-----------------------------+----------------+---------+---------------+----------------------------------------+
| CAN0_Cell_voltage_M2_3      | 0x243          | 8       | TX            | Cell voltages module 2 cell 9 10 11    |
+-----------------------------+----------------+---------+---------------+----------------------------------------+
| CAN0_Cell_voltage_M2_4      | 0x244          | 8       | TX            | Cell voltages module 2 cell 12 13 14   |
+-----------------------------+----------------+---------+---------------+----------------------------------------+
| CAN0_Cell_voltage_M2_5      | 0x245          | 8       | TX            | Cell voltages module 2 cell 15 16 17   |
+-----------------------------+----------------+---------+---------------+----------------------------------------+
| CAN0_Cell_temperature_M2_0  | 0x250          | 8       | TX            | Cell temperatures module 2 - 0 1 2     |
+-----------------------------+----------------+---------+---------------+----------------------------------------+
| CAN0_Cell_temperature_M2_1  | 0x251          | 8       | TX            | Cell temperatures module 2 - 3 4 5     |
+-----------------------------+----------------+---------+---------------+----------------------------------------+
| CAN0_Cell_temperature_M2_2  | 0x252          | 8       | TX            | Cell temperatures module 2 - 6 7 8     |
+-----------------------------+----------------+---------+---------------+----------------------------------------+
| CAN0_Cell_temperature_M2_3  | 0x253          | 8       | TX            | Cell temperatures module 2 - 9 10 11   |
+-----------------------------+----------------+---------+---------------+----------------------------------------+
| CAN0_Cell_voltage_M3_0      | 0x260          | 8       | TX            | Cell voltages module 3 cell 0 1 2      |
+-----------------------------+----------------+---------+---------------+----------------------------------------+
| CAN0_Cell_voltage_M3_1      | 0x261          | 8       | TX            | Cell voltages module 3 cell 3 4 5      |
+-----------------------------+----------------+---------+---------------+----------------------------------------+
| CAN0_Cell_voltage_M3_2      | 0x262          | 8       | TX            | Cell voltages module 3 cell 6 7 8      |
+-----------------------------+----------------+---------+---------------+----------------------------------------+
| CAN0_Cell_voltage_M3_3      | 0x263          | 8       | TX            | Cell voltages module 3 cell 9 10 11    |
+-----------------------------+----------------+---------+---------------+----------------------------------------+
| CAN0_Cell_voltage_M3_4      | 0x264          | 8       | TX            | Cell voltages module 3 cell 12 13 14   |
+-----------------------------+----------------+---------+---------------+----------------------------------------+
| CAN0_Cell_voltage_M3_5      | 0x265          | 8       | TX            | Cell voltages module 3 cell 15 16 17   |
+-----------------------------+----------------+---------+---------------+----------------------------------------+
| CAN0_Cell_temperature_M3_0  | 0x270          | 8       | TX            | Cell temperatures module 3 - 0 1 2     |
+-----------------------------+----------------+---------+---------------+----------------------------------------+
| CAN0_Cell_temperature_M3_1  | 0x271          | 8       | TX            | Cell temperatures module 3 - 3 4 5     |
+-----------------------------+----------------+---------+---------------+----------------------------------------+
| CAN0_Cell_temperature_M3_2  | 0x272          | 8       | TX            | Cell temperatures module 3 - 6 7 8     |
+-----------------------------+----------------+---------+---------------+----------------------------------------+
| CAN0_Cell_temperature_M3_3  | 0x273          | 8       | TX            | Cell temperatures module 3 - 9 10 11   |
+-----------------------------+----------------+---------+---------------+----------------------------------------+
| CAN0_Cell_voltage_M4_0      | 0x280          | 8       | TX            | Cell voltages module 4 cell 0 1 2      |
+-----------------------------+----------------+---------+---------------+----------------------------------------+
| CAN0_Cell_voltage_M4_1      | 0x281          | 8       | TX            | Cell voltages module 4 cell 3 4 5      |
+-----------------------------+----------------+---------+---------------+----------------------------------------+
| CAN0_Cell_voltage_M4_2      | 0x282          | 8       | TX            | Cell voltages module 4 cell 6 7 8      |
+-----------------------------+----------------+---------+---------------+----------------------------------------+
| CAN0_Cell_voltage_M4_3      | 0x283          | 8       | TX            | Cell voltages module 4 cell 9 10 11    |
+-----------------------------+----------------+---------+---------------+----------------------------------------+
| CAN0_Cell_voltage_M4_4      | 0x284          | 8       | TX            | Cell voltages module 4 cell 12 13 14   |
+-----------------------------+----------------+---------+---------------+----------------------------------------+
| CAN0_Cell_voltage_M4_5      | 0x285          | 8       | TX            | Cell voltages module 4 cell 15 16 17   |
+-----------------------------+----------------+---------+---------------+----------------------------------------+
| CAN0_Cell_temperature_M4_0  | 0x290          | 8       | TX            | Cell temperatures module 4 - 0 1 2     |
+-----------------------------+----------------+---------+---------------+----------------------------------------+
| CAN0_Cell_temperature_M4_1  | 0x291          | 8       | TX            | Cell temperatures module 4 - 3 4 5     |
+-----------------------------+----------------+---------+---------------+----------------------------------------+
| CAN0_Cell_temperature_M4_2  | 0x292          | 8       | TX            | Cell temperatures module 4 - 6 7 8     |
+-----------------------------+----------------+---------+---------------+----------------------------------------+
| CAN0_Cell_temperature_M4_3  | 0x293          | 8       | TX            | Cell temperatures module 4 - 9 10 11   |
+-----------------------------+----------------+---------+---------------+----------------------------------------+
| CAN0_Cell_voltage_M5_0      | 0x2A0          | 8       | TX            | Cell voltages module 5 cell 0 1 2      |
+-----------------------------+----------------+---------+---------------+----------------------------------------+
| CAN0_Cell_voltage_M5_1      | 0x2A1          | 8       | TX            | Cell voltages module 5 cell 3 4 5      |
+-----------------------------+----------------+---------+---------------+----------------------------------------+
| CAN0_Cell_voltage_M5_2      | 0x2A2          | 8       | TX            | Cell voltages module 5 cell 6 7 8      |
+-----------------------------+----------------+---------+---------------+----------------------------------------+
| CAN0_Cell_voltage_M5_3      | 0x2A3          | 8       | TX            | Cell voltages module 5 cell 9 10 11    |
+-----------------------------+----------------+---------+---------------+----------------------------------------+
| CAN0_Cell_voltage_M5_4      | 0x2A4          | 8       | TX            | Cell voltages module 5 cell 12 13 14   |
+-----------------------------+----------------+---------+---------------+----------------------------------------+
| CAN0_Cell_voltage_M5_5      | 0x2A5          | 8       | TX            | Cell voltages module 5 cell 15 16 17   |
+-----------------------------+----------------+---------+---------------+----------------------------------------+
| CAN0_Cell_temperature_M5_0  | 0x2B0          | 8       | TX            | Cell temperatures module 5 - 0 1 2     |
+-----------------------------+----------------+---------+---------------+----------------------------------------+
| CAN0_Cell_temperature_M5_1  | 0x2B1          | 8       | TX            | Cell temperatures module 5 - 3 4 5     |
+-----------------------------+----------------+---------+---------------+----------------------------------------+
| CAN0_Cell_temperature_M5_2  | 0x2B2          | 8       | TX            | Cell temperatures module 5 - 6 7 8     |
+-----------------------------+----------------+---------+---------------+----------------------------------------+
| CAN0_Cell_temperature_M5_3  | 0x2B3          | 8       | TX            | Cell temperatures module 5 - 9 10 11   |
+-----------------------------+----------------+---------+---------------+----------------------------------------+
| CAN0_Cell_voltage_M6_0      | 0x2C0          | 8       | TX            | Cell voltages module 6 cell 0 1 2      |
+-----------------------------+----------------+---------+---------------+----------------------------------------+
| CAN0_Cell_voltage_M6_1      | 0x2C1          | 8       | TX            | Cell voltages module 6 cell 3 4 5      |
+-----------------------------+----------------+---------+---------------+----------------------------------------+
| CAN0_Cell_voltage_M6_2      | 0x2C2          | 8       | TX            | Cell voltages module 6 cell 6 7 8      |
+-----------------------------+----------------+---------+---------------+----------------------------------------+
| CAN0_Cell_voltage_M6_3      | 0x2C3          | 8       | TX            | Cell voltages module 6 cell 9 10 11    |
+-----------------------------+----------------+---------+---------------+----------------------------------------+
| CAN0_Cell_voltage_M6_4      | 0x2C4          | 8       | TX            | Cell voltages module 6 cell 12 13 14   |
+-----------------------------+----------------+---------+---------------+----------------------------------------+
| CAN0_Cell_voltage_M6_5      | 0x2C5          | 8       | TX            | Cell voltages module 6 cell 15 16 17   |
+-----------------------------+----------------+---------+---------------+----------------------------------------+
| CAN0_Cell_temperature_M6_0  | 0x2D0          | 8       | TX            | Cell temperatures module 6 - 0 1 2     |
+-----------------------------+----------------+---------+---------------+----------------------------------------+
| CAN0_Cell_temperature_M6_1  | 0x2D1          | 8       | TX            | Cell temperatures module 6 - 3 4 5     |
+-----------------------------+----------------+---------+---------------+----------------------------------------+
| CAN0_Cell_temperature_M6_2  | 0x2D2          | 8       | TX            | Cell temperatures module 6 - 6 7 8     |
+-----------------------------+----------------+---------+---------------+----------------------------------------+
| CAN0_Cell_temperature_M6_3  | 0x2D3          | 8       | TX            | Cell temperatures module 6 - 9 10 11   |
+-----------------------------+----------------+---------+---------------+----------------------------------------+
| CAN0_Cell_voltage_M7_0      | 0x2E0          | 8       | TX            | Cell voltages module 7 cell 0 1 2      |
+-----------------------------+----------------+---------+---------------+----------------------------------------+
| CAN0_Cell_voltage_M7_1      | 0x2E1          | 8       | TX            | Cell voltages module 7 cell 3 4 5      |
+-----------------------------+----------------+---------+---------------+----------------------------------------+
| CAN0_Cell_voltage_M7_2      | 0x2E2          | 8       | TX            | Cell voltages module 7 cell 6 7 8      |
+-----------------------------+----------------+---------+---------------+----------------------------------------+
| CAN0_Cell_voltage_M7_3      | 0x2E3          | 8       | TX            | Cell voltages module 7 cell 9 10 11    |
+-----------------------------+----------------+---------+---------------+----------------------------------------+
| CAN0_Cell_voltage_M7_4      | 0x2E4          | 8       | TX            | Cell voltages module 7 cell 12 13 14   |
+-----------------------------+----------------+---------+---------------+----------------------------------------+
| CAN0_Cell_voltage_M7_5      | 0x2E5          | 8       | TX            | Cell voltages module 7 cell 15 16 17   |
+-----------------------------+----------------+---------+---------------+----------------------------------------+
| CAN0_Cell_temperature_M7_0  | 0x2F0          | 8       | TX            | Cell temperatures module 7 - 0 1 2     |
+-----------------------------+----------------+---------+---------------+----------------------------------------+
| CAN0_Cell_temperature_M7_1  | 0x2F1          | 8       | TX            | Cell temperatures module 7 - 3 4 5     |
+-----------------------------+----------------+---------+---------------+----------------------------------------+
| CAN0_Cell_temperature_M7_2  | 0x2F2          | 8       | TX            | Cell temperatures module 7 - 6 7 8     |
+-----------------------------+----------------+---------+---------------+----------------------------------------+
| CAN0_Cell_temperature_M7_3  | 0x2F3          | 8       | TX            | Cell temperatures module 7 - 9 10 11   |
+-----------------------------+----------------+---------+---------------+----------------------------------------+
| CAN0_MSG_ISENS_TRIG         | 0x35B          | 8       | TX            | Trigger for CurrentSensor              |
+-----------------------------+----------------+---------+---------------+----------------------------------------+

.. _CANSgnls:

CAN RX Signals
--------------

+---------------------------------+-----------------------+----------------+---------+---------+------------+------------+----------+---------------+
| **Message: CAN0_Software_Reset**| **Message ID: 0x95**  | **DLC: 8**     |         |         |            |            |          |               |
+---------------------------------+-----------------------+----------------+---------+---------+------------+------------+----------+---------------+
| **Signal name**                 | **Start bit**         | **Bit length** | **Min** | **Max** | **Factor** | **Offset** | **Unit** | **Byteorder** |
+---------------------------------+-----------------------+----------------+---------+---------+------------+------------+----------+---------------+

When this message is received, a software reset is performed.

--------------

+---------------------------------+-----------------------+----------------+---------+------------+------------+------------+----------+---------------+
| **Message: CAN0_Debug_Message** | **Message ID: 0x100** | **DLC: 8**     |         |            |            |            |          |               |
+---------------------------------+-----------------------+----------------+---------+------------+------------+------------+----------+---------------+
| **Signal name**                 | **Start bit**         | **Bit length** | **Min** | **Max**    | **Factor** | **Offset** | **Unit** | **Byteorder** |
+---------------------------------+-----------------------+----------------+---------+------------+------------+------------+----------+---------------+
| CAN0_SIG_DEBUG_Data             | 0                     | 64             | 0.0     | 0xFFFFFFFF | 1.0        | 0.0        | none     | Intel         |
+---------------------------------+-----------------------+----------------+---------+------------+------------+------------+----------+---------------+

This message contains only one single signal. The debug data is interpreted by the embedded software differently depending on its actual databits. In the software FAQ (:ref:`can_debug_message`), further details are given on the handling of debug messages.

--------------

+---------------------------------+-----------------------+----------------+---------+------------+------------+------------+----------+---------------+
| **Message: CAN0_State_Request** | **Message ID: 0x120** | **DLC: 8**     |         |            |            |            |          |               |
+---------------------------------+-----------------------+----------------+---------+------------+------------+------------+----------+---------------+
| **Signal name**                 | **Start bit**         | **Bit length** | **Min** | **Max**    | **Factor** | **Offset** | **Unit** | **Byteorder** |
+---------------------------------+-----------------------+----------------+---------+------------+------------+------------+----------+---------------+
| CAN0_SIG_ReceiveStateRequest    | 8                     | 8              | 0.0     | 255        | 1.0        | 0.0        | none     | Intel         |
+---------------------------------+-----------------------+----------------+---------+------------+------------+------------+----------+---------------+

In the messages described in the previous table, the signal ``CAN0_SIG_ReceiveStateRequest`` is used to change the state of the |master|. This is one of the most important signals: it allows initiating the procedure to close the power contactors. Possible request numbers in default configuration are 3 (Normal state), 4 (Charge state) and 8 (Standby state), but can be configured (0 is No Request). More details can be found in the documentation of the module :ref:`BMS`.

A state request has to be sent every 100ms, otherwise the BMS enters into an error state. The requests must come in the window 95-105ms to be valid.

--------------

+----------------------------------+------------------------------+----------------+-------------+------------+------------+------------+----------+---------------+
| **Message: CAN0_MSG_IVT_Current**| **Message ID: 0x35C/0x521**  | **DLC: 6**     |             |            |            |            |          |               |
+----------------------------------+------------------------------+----------------+-------------+------------+------------+------------+----------+---------------+
| **Signal name**                  | **Start bit**                | **Bit length** | **Min**     | **Max**    | **Factor** | **Offset** | **Unit** | **Byteorder** |
+----------------------------------+------------------------------+----------------+-------------+------------+------------+------------+----------+---------------+
| CAN0_SIG_IVT_Current_MuxID       | 0                            | 8              | 0.0         | 255        | 1.0        | 0.0        | none     | Intel         |
+----------------------------------+------------------------------+----------------+-------------+------------+------------+------------+----------+---------------+
| CAN0_SIG_IVT_Current_Status      | 8                            | 8              | 0.0         | 255        | 1.0        | 0.0        | none     | Intel         |
+----------------------------------+------------------------------+----------------+-------------+------------+------------+------------+----------+---------------+
| CAN0_SIG_IVT_Current_Measurement | 16                           | 32             | -2147483648 | 2147483647 | 1.0        | 0.0        | mA       | Intel         |
+----------------------------------+------------------------------+----------------+-------------+------------+------------+------------+----------+---------------+

``CAN0_IVT_Current_MuxID`` indicates the measurement type and ``CAN0_IVT_Current_Status`` indicates status values and counters of the current sensor measurement.
For details the `datasheet of the current sensor <http://www.isabellenhuette.de/uploads/media/IVT_Modular_datasheet_1.20_02.pdf>`_ must be consulted.
``CAN0_IVT_Current_Measurement`` is the current value measured by the sensor. It is a 32 bit signed value with 1mA resolution. It must be noted that resolution
in CAN transmission is not the same as the measurement accuracy.

--------------

+-------------------------------------+------------------------------+----------------+-------------+------------+------------+------------+----------+---------------+
| **Message: CAN0_MSG_IVT_Voltage_1** | **Message ID: 0x35D/0x522**  | **DLC: 6**     |             |            |            |            |          |               |
+-------------------------------------+------------------------------+----------------+-------------+------------+------------+------------+----------+---------------+
| **Signal name**                     | **Start bit**                | **Bit length** | **Min**     | **Max**    | **Factor** | **Offset** | **unit** | **Byteorder** |
+-------------------------------------+------------------------------+----------------+-------------+------------+------------+------------+----------+---------------+
| CAN0_SIG_IVT_Voltage_1_MuxID        | 0                            | 8              | 0.0         | 255        | 1.0        | 0.0        | none     | Intel         |
+-------------------------------------+------------------------------+----------------+-------------+------------+------------+------------+----------+---------------+
| CAN0_SIG_IVT_Voltage_1_Status       | 8                            | 8              | 0.0         | 255        | 1.0        | 0.0        | none     | Intel         |
+-------------------------------------+------------------------------+----------------+-------------+------------+------------+------------+----------+---------------+
| CAN0_SIG_IVT_Voltage_1_Measurement  | 16                           | 32             | 0.0         | 4294967295 | 1.0        | 0.0        | mV       | Intel         |
+-------------------------------------+------------------------------+----------------+-------------+------------+------------+------------+----------+---------------+

``CAN0_IVT_Voltage_1_MuxID`` indicates the measurement type and ``CAN0_IVT_Voltage_1_Status`` indicates status values and counters of the current sensor measurement.
For details the `datasheet of the current sensor <http://www.isabellenhuette.de/uploads/media/IVT_Modular_datasheet_1.20_02.pdf>`_ must be consulted.
``CAN0_IVT_Voltage_1_Measurement`` is the voltage value measured by the sensor at the voltage input channel 1. It is a 32 bit unsigned value with 1mV resolution.
It must be noted that resolution in CAN transmission is not the same as the measurement accuracy.

--------------

+-------------------------------------+------------------------------+----------------+-------------+------------+------------+------------+----------+---------------+
| **Message: CAN0_MSG_IVT_Voltage_2** | **Message ID: 0x35E/0x523**  | **DLC: 6**     |             |            |            |            |          |               |
+-------------------------------------+------------------------------+----------------+-------------+------------+------------+------------+----------+---------------+
| **Signal name**                     | **Start bit**                | **Bit length** | **Min**     | **Max**    | **Factor** | **Offset** | **unit** | **Byteorder** |
+-------------------------------------+------------------------------+----------------+-------------+------------+------------+------------+----------+---------------+
| CAN0_SIG_IVT_Voltage_2_MuxID        | 0                            | 8              | 0.0         | 255        | 1.0        | 0.0        | none     | Intel         |
+-------------------------------------+------------------------------+----------------+-------------+------------+------------+------------+----------+---------------+
| CAN0_SIG_IVT_Voltage_2_Status       | 8                            | 8              | 0.0         | 255        | 1.0        | 0.0        | none     | Intel         |
+-------------------------------------+------------------------------+----------------+-------------+------------+------------+------------+----------+---------------+
| CAN0_SIG_IVT_Voltage_2_Measurement  | 16                           | 32             | 0.0         | 4294967295 | 1.0        | 0.0        | mV       | Intel         |
+-------------------------------------+------------------------------+----------------+-------------+------------+------------+------------+----------+---------------+

``CAN0_IVT_Voltage_2_MuxID`` indicates the measurement type and ``CAN0_IVT_Voltage_2_Status`` indicates status values and counters of the current sensor measurement.
For details the `datasheet of the current sensor <http://www.isabellenhuette.de/uploads/media/IVT_Modular_datasheet_1.20_02.pdf>`_ must be consulted.
``CAN0_IVT_Voltage_2_Measurement`` is the voltage value measured by the sensor at the voltage input channel 2. It is a 32 bit unsigned value with 1mV resolution.
It must be noted that resolution in CAN transmission is not the same as the measurement accuracy.

--------------

+-------------------------------------+------------------------------+----------------+-------------+------------+------------+------------+----------+---------------+
| **Message: CAN0_MSG_IVT_Voltage_3** | **Message ID: 0x35F/0x524**  | **DLC: 6**     |             |            |            |            |          |               |
+-------------------------------------+------------------------------+----------------+-------------+------------+------------+------------+----------+---------------+
| **Signal name**                     | **Start bit**                | **Bit length** | **Min**     | **Max**    | **Factor** | **Offset** | **Unit** | **Byteorder** |
+-------------------------------------+------------------------------+----------------+-------------+------------+------------+------------+----------+---------------+
| CAN0_SIG_IVT_Voltage_3_MuxID        | 0                            | 8              | 0.0         | 255        | 1.0        | 0.0        | none     | Intel         |
+-------------------------------------+------------------------------+----------------+-------------+------------+------------+------------+----------+---------------+
| CAN0_SIG_IVT_Voltage_3_Status       | 8                            | 8              | 0.0         | 255        | 1.0        | 0.0        | none     | Intel         |
+-------------------------------------+------------------------------+----------------+-------------+------------+------------+------------+----------+---------------+
| CAN0_SIG_IVT_Voltage_3_Measurement  | 16                           | 32             | 0.0         | 4294967295 | 1.0        | 0.0        | mV       | Intel         |
+-------------------------------------+------------------------------+----------------+-------------+------------+------------+------------+----------+---------------+

``CAN0_IVT_Voltage_3_MuxID`` indicates the measurement type and ``CAN0_IVT_Voltage_3_Status`` indicates status values and counters of the current sensor measurement.
For details the `datasheet of the current sensor <http://www.isabellenhuette.de/uploads/media/IVT_Modular_datasheet_1.20_02.pdf>`_ must be consulted.
``CAN0_IVT_Voltage_3_Measurement`` is the voltage value measured by the sensor at the voltage input channel 3. It is a 32 bit unsigned value with 1mV resolution.
It must be noted that resolution in CAN transmission is not the same as the measurement accuracy.

--------------

+--------------------------------------+------------------------------+----------------+-------------+------------+------------+------------+----------+---------------+
| **Message: CAN0_MSG_IVT_Temperature**| **Message ID: 0x525**        | **DLC: 6**     |             |            |            |            |          |               |
+--------------------------------------+------------------------------+----------------+-------------+------------+------------+------------+----------+---------------+
| **Signal name**                      | **Start bit**                | **Bit length** | **Min**     | **Max**    | **Factor** | **Offset** | **Unit** | **Byteorder** |
+--------------------------------------+------------------------------+----------------+-------------+------------+------------+------------+----------+---------------+
| CAN0_SIG_IVT_Temperature_MuxID       | 0                            | 8              | 0.0         | 255        | 1.0        | 0.0        | none     | Intel         |
+--------------------------------------+------------------------------+----------------+-------------+------------+------------+------------+----------+---------------+
| CAN0_SIG_IVT_Temperature_Status      | 8                            | 8              | 0.0         | 255        | 1.0        | 0.0        | none     | Intel         |
+--------------------------------------+------------------------------+----------------+-------------+------------+------------+------------+----------+---------------+
| CAN0_SIG_IVT_Temperature_Measurement | 16                           | 32             | -2147483648 | 2147483647 | 1.0        | 0.0        | 0.1°C    | Intel         |
+--------------------------------------+------------------------------+----------------+-------------+------------+------------+------------+----------+---------------+

``CAN0_IVT_Temperature_MuxID`` indicates the measurement type and ``CAN0_IVT_Temperature_Status`` indicates status values and counters of the current sensor measurement.
For details the `datasheet of the current sensor <http://www.isabellenhuette.de/uploads/media/IVT_Modular_datasheet_1.20_02.pdf>`_ must be consulted.
``CAN0_IVT_Temperature_Measurement`` is the temperature value measured by the sensor. It is a 32 bit signed value with 0.1°C resolution. It must be noted
that resolution in CAN transmission is not the same as the measurement accuracy.

--------------

+---------------------------------+------------------------------+----------------+-------------+------------+------------+------------+----------+---------------+
| **Message: CAN0_MSG_IVT_Power** | **Message ID: 0x526**        | **DLC: 6**     |             |            |            |            |          |               |
+---------------------------------+------------------------------+----------------+-------------+------------+------------+------------+----------+---------------+
| **Signal name**                 | **Start bit**                | **Bit length** | **Min**     | **Max**    | **Factor** | **Offset** | **Unit** | **Byteorder** |
+---------------------------------+------------------------------+----------------+-------------+------------+------------+------------+----------+---------------+
| CAN0_SIG_IVT_Power_MuxID        | 0                            | 8              | 0.0         | 255        | 1.0        | 0.0        | none     | Intel         |
+---------------------------------+------------------------------+----------------+-------------+------------+------------+------------+----------+---------------+
| CAN0_SIG_IVT_Power_Status       | 8                            | 8              | 0.0         | 255        | 1.0        | 0.0        | none     | Intel         |
+---------------------------------+------------------------------+----------------+-------------+------------+------------+------------+----------+---------------+
| CAN0_SIG_IVT_Power_Measurement  | 16                           | 32             | -2147483648 | 2147483647 | 1.0        | 0.0        | W        | Intel         |
+---------------------------------+------------------------------+----------------+-------------+------------+------------+------------+----------+---------------+

``CAN0_IVT_Power_MuxID`` indicates the measurement type and ``CAN0_IVT_Power_Status`` indicates status values and counters of the current sensor measurement.
For details the `datasheet of the current sensor <http://www.isabellenhuette.de/uploads/media/IVT_Modular_datasheet_1.20_02.pdf>`_ must be consulted.
``CAN_IVT0_Power_Measurement`` is the power value measured by the sensor (referring to current and voltage U1). It is a 32 bit signed value with 1W resolution. It must be noted
that resolution in CAN transmission is not the same as the measurement accuracy.

--------------

+---------------------------------------+------------------------------+----------------+-------------+------------+------------+------------+----------+---------------+
| **Message: CAN0_MSG_IVT_CoulombCount**| **Message ID: 0x527**        | **DLC: 6**     |             |            |            |            |          |               |
+---------------------------------------+------------------------------+----------------+-------------+------------+------------+------------+----------+---------------+
| **Signal name**                       | **Start bit**                | **Bit length** | **Min**     | **Max**    | **Factor** | **Offset** | **Unit** | **Byteorder** |
+---------------------------------------+------------------------------+----------------+-------------+------------+------------+------------+----------+---------------+
| CAN0_SIG_IVT_CC_MuxID                 | 0                            | 8              | 0.0         | 255        | 1.0        | 0.0        | none     | Intel         |
+---------------------------------------+------------------------------+----------------+-------------+------------+------------+------------+----------+---------------+
| CAN0_SIG_IVT_CC_Status                | 8                            | 8              | 0.0         | 255        | 1.0        | 0.0        | none     | Intel         |
+---------------------------------------+------------------------------+----------------+-------------+------------+------------+------------+----------+---------------+
| CAN0_SIG_IVT_CC_Measurement           | 16                           | 32             | -2147483648 | 2147483647 | 1.0        | 0.0        | As       | Intel         |
+---------------------------------------+------------------------------+----------------+-------------+------------+------------+------------+----------+---------------+

``CAN0_IVT_CoulombCount_MuxID`` indicates the measurement type and ``CAN0_IVT_CoulombCount_Status`` indicates status values and counters of the current sensor measurement.
For details the `datasheet of the current sensor <http://www.isabellenhuette.de/uploads/media/IVT_Modular_datasheet_1.20_02.pdf>`_ must be consulted.
``CAN0_IVT_CoulombCount_Measurement`` is the current counted by the sensor. It is a 32 bit signed value with 1As resolution. It must be noted
that resolution in CAN transmission is not the same as the measurement accuracy.

--------------

+---------------------------------------+------------------------------+----------------+-------------+------------+------------+------------+----------+---------------+
| **Message: CAN0_MSG_IVT_EnergyCount** | **Message ID: 0x528**        | **DLC: 6**     |             |            |            |            |          |               |
+---------------------------------------+------------------------------+----------------+-------------+------------+------------+------------+----------+---------------+
| **Signal name**                       | **Start bit**                | **Bit length** | **Min**     | **Max**    | **Factor** | **Offset** | **Unit** | **Byteorder** |
+---------------------------------------+------------------------------+----------------+-------------+------------+------------+------------+----------+---------------+
| CAN0_SIG_IVT_EC_MuxID                 | 0                            | 8              | 0.0         | 255        | 1.0        | 0.0        | none     | Intel         |
+---------------------------------------+------------------------------+----------------+-------------+------------+------------+------------+----------+---------------+
| CAN0_SIG_IVT_EC_Status                | 8                            | 8              | 0.0         | 255        | 1.0        | 0.0        | none     | Intel         |
+---------------------------------------+------------------------------+----------------+-------------+------------+------------+------------+----------+---------------+
| CAN0_SIG_IVT_EC_Measurement           | 16                           | 32             | -2147483648 | 2147483647 | 1.0        | 0.0        | Wh       | Intel         |
+---------------------------------------+------------------------------+----------------+-------------+------------+------------+------------+----------+---------------+

``CAN0_IVT_EnergyCount_MuxID`` indicates the measurement type and ``CAN_IVT0_EnergyCount_Status`` indicates status values and counters of the current sensor measurement.
For details the `datasheet of the current sensor <http://www.isabellenhuette.de/uploads/media/IVT_Modular_datasheet_1.20_02.pdf>`_ must be consulted.
``CAN0_IVT_EnergyCount_Measurement`` is the energy counted by the sensor (referring to current and voltage U1). It is a 32 bit signed value with 1Wh resolution.
It must be noted that resolution in CAN transmission is not the same as the measurement accuracy.

--------------

+-----------------------------------------+------------------------------+----------------+-------------+------------+------------+------------+----------+---------------+
| **Message: CAN0_MSG_GetReleaseVersion** | **Message ID: 0x777**        | **DLC: 8**     |             |            |            |            |          |               |
+-----------------------------------------+------------------------------+----------------+-------------+------------+------------+------------+----------+---------------+
| **Signal name**                         | **Start bit**                | **Bit length** | **Min**     | **Max**    | **Factor** | **Offset** | **Unit** | **Byteorder** |
+-----------------------------------------+------------------------------+----------------+-------------+------------+------------+------------+----------+---------------+
| CAN0_SIG_GetReleaseVersion              | 0                            | 64             | 0.0         | 0          | 1.0        | 0.0        | none     | Intel         |
+-----------------------------------------+------------------------------+----------------+-------------+------------+------------+------------+----------+---------------+

When message ``CAN0_MSG_GetReleaseVersion`` is received, CAN message ``CAN0_MSG_BOOT`` is transmitted as response message.

--------------

CAN TX Signals
--------------

+---------------------------------------+------------------------------+----------------+-------------+------------+------------+------------+----------+---------------+
| **Message: CAN0_MSG_BOOT**            | **Message ID: 0x101**        | **DLC: 8**     |             |            |            |            |          |               |
+---------------------------------------+------------------------------+----------------+-------------+------------+------------+------------+----------+---------------+
| **Signal name**                       | **Start bit**                | **Bit length** | **Min**     | **Max**    | **Factor** | **Offset** | **Unit** | **Byteorder** |
+---------------------------------------+------------------------------+----------------+-------------+------------+------------+------------+----------+---------------+
| CAN0_SIG_VersionNumberMajor           | 0                            | 8              | 0.0         | 255        | 1.0        | 0.0        | none     | Intel         |
+---------------------------------------+------------------------------+----------------+-------------+------------+------------+------------+----------+---------------+
| CAN0_SIG_VersionNumberMinor           | 8                            | 8              | 0.0         | 255        | 1.0        | 0.0        | none     | Intel         |
+---------------------------------------+------------------------------+----------------+-------------+------------+------------+------------+----------+---------------+
| CAN0_SIG_VersionNumberBugfix          | 16                           | 8              | 0.0         | 255        | 1.0        | 0.0        | none     | Intel         |
+---------------------------------------+------------------------------+----------------+-------------+------------+------------+------------+----------+---------------+
| CAN0_SIG_Checksum                     | 32                           | 32             | 0.0         | 4294967295 | 1.0        | 0.0        | none     | Intel         |
+---------------------------------------+------------------------------+----------------+-------------+------------+------------+------------+----------+---------------+

``CAN0_SIG_VersionNumberMajor``, ``CAN0_SIG_VersionNumberMinor`` and signal
``CAN0_SIG_VersionNumberMinor`` add up to the current flashed SW-version. The
latest Releaseversion is |version|. ``CAN0_SIG_Checksum`` holds the calculated
CRC32 checksum of the flashed software. This message is transmitted once after
startup or can be requested via CAN.

--------------

+------------------------------------------+------------------------------+----------------+-------------+------------+------------+------------+----------+---------------+
| **Message: CAN0_MSG_SystemState_0**      | **Message ID: 0x110**        | **DLC: 8**     |             |            |            |            |          |               |
+------------------------------------------+------------------------------+----------------+-------------+------------+------------+------------+----------+---------------+
| **Signal name**                          | **Start bit**                | **Bit length** | **Min**     | **Max**    | **Factor** | **Offset** | **Unit** | **Byteorder** |
+------------------------------------------+------------------------------+----------------+-------------+------------+------------+------------+----------+---------------+
| CAN0_SIG_GS0_general_error               | 0                            | 8              | 0.0         | 255        | 1.0        | 0.0        | none     | Intel         |
+------------------------------------------+------------------------------+----------------+-------------+------------+------------+------------+----------+---------------+
| CAN0_SIG_GS0_current_state               | 8                            | 8              | 0.0         | 255        | 1.0        | 0.0        | none     | Intel         |
+------------------------------------------+------------------------------+----------------+-------------+------------+------------+------------+----------+---------------+
| CAN0_SIG_GS0_error_overtemp_charge       | 16                           | 8              | 0.0         | 255        | 1.0        | 0.0        | none     | Intel         |
+------------------------------------------+------------------------------+----------------+-------------+------------+------------+------------+----------+---------------+
| CAN0_SIG_GS0_error_undertemp_charge      | 24                           | 8              | 0.0         | 255        | 1.0        | 0.0        | none     | Intel         |
+------------------------------------------+------------------------------+----------------+-------------+------------+------------+------------+----------+---------------+
| CAN0_SIG_GS0_error_overtemp_discharge    | 32                           | 8              | 0.0         | 255        | 1.0        | 0.0        | none     | Intel         |
+------------------------------------------+------------------------------+----------------+-------------+------------+------------+------------+----------+---------------+
| CAN0_SIG_GS0_error_undertemp_discharge   | 40                           | 8              | 0.0         | 255        | 1.0        | 0.0        | none     | Intel         |
+------------------------------------------+------------------------------+----------------+-------------+------------+------------+------------+----------+---------------+
| CAN0_SIG_GS0_error_overcurrent_charge    | 48                           | 8              | 0.0         | 255        | 1.0        | 0.0        | none     | Intel         |
+------------------------------------------+------------------------------+----------------+-------------+------------+------------+------------+----------+---------------+
| CAN0_SIG_GS0_error_overcurrent_discharge | 56                           | 8              | 0.0         | 255        | 1.0        | 0.0        | none     | Intel         |
+------------------------------------------+------------------------------+----------------+-------------+------------+------------+------------+----------+---------------+

+------------------------------------------+------------------------------+----------------+-------------+------------+------------+------------+----------+---------------+
| **Message: CAN0_MSG_SystemState_1**      | **Message ID: 0x111**        | **DLC: 8**     |             |            |            |            |          |               |
+------------------------------------------+------------------------------+----------------+-------------+------------+------------+------------+----------+---------------+
| **Signal name**                          | **Start bit**                | **Bit length** | **Min**     | **Max**    | **Factor** | **Offset** | **Unit** | **Byteorder** |
+------------------------------------------+------------------------------+----------------+-------------+------------+------------+------------+----------+---------------+
| CAN0_SIG_GS1_error_overvoltage           | 0                            | 8              | 0.0         | 255        | 1.0        | 0.0        | none     | Intel         |
+------------------------------------------+------------------------------+----------------+-------------+------------+------------+------------+----------+---------------+
| CAN0_SIG_GS1_error_undervoltage          | 8                            | 3              | 0.0         | 7          | 1.0        | 0.0        | none     | Intel         |
+------------------------------------------+------------------------------+----------------+-------------+------------+------------+------------+----------+---------------+
| CAN0_SIG_GS1_error_deep_discharge        | 11                           | 5              | 0.0         | 31         | 1.0        | 0.0        | none     | Intel         |
+------------------------------------------+------------------------------+----------------+-------------+------------+------------+------------+----------+---------------+
| CAN0_SIG_GS1_error_temperature_MCU0      | 16                           | 8              | 0.0         | 255        | 1.0        | 0.0        | none     | Intel         |
+------------------------------------------+------------------------------+----------------+-------------+------------+------------+------------+----------+---------------+
| CAN0_SIG_GS1_error_contactor             | 24                           | 8              | 0.0         | 255        | 1.0        | 0.0        | none     | Intel         |
+------------------------------------------+------------------------------+----------------+-------------+------------+------------+------------+----------+---------------+
| CAN0_SIG_GS1_error_selftest              | 32                           | 8              | for future use (not implemented yet)                                          |
+------------------------------------------+------------------------------+----------------+-------------+------------+------------+------------+----------+---------------+
| CAN0_SIG_GS1_error_cantiming             | 40                           | 8              | 0.0         | 255        | 1.0        | 0.0        | none     | Intel         |
+------------------------------------------+------------------------------+----------------+-------------+------------+------------+------------+----------+---------------+
| CAN0_SIG_GS1_current_sensor              | 48                           | 8              | 0.0         | 255        | 1.0        | 0.0        | none     | Intel         |
+------------------------------------------+------------------------------+----------------+-------------+------------+------------+------------+----------+---------------+
| CAN0_SIG_GS1_balancing_active            | 56                           | 8              | 0.0         | 255        | 1.0        | 0.0        | none     | Intel         |
+------------------------------------------+------------------------------+----------------+-------------+------------+------------+------------+----------+---------------+

+------------------------------------------+------------------------------+----------------+-------------+------------+------------+-------------+----------+---------------+
| **Message: CAN0_MSG_SystemState_2**      | **Message ID: 0x112**        | **DLC: 8**     |             |            |            |             |          |               |
+------------------------------------------+------------------------------+----------------+-------------+------------+------------+-------------+----------+---------------+
| **Signal name**                          | **Start bit**                | **Bit length** | **Min**     | **Max**    | **Factor** |  **Offset** | **Unit** | **Byteorder** |
+------------------------------------------+------------------------------+----------------+-------------+------------+------------+-------------+----------+---------------+
| CAN0_SIG_GS2_state_cont_interlock        | 0                            | 16             | 0.0         | 65535      | 1.0        | 0.0         | none     | Intel         |
+------------------------------------------+------------------------------+----------------+-------------+------------+------------+-------------+----------+---------------+
| CAN0_SIG_GS2_error_insulation            | 16                           | 8              | 0.0         | 255        | 1.0        | 0.0         | none     | Intel         |
+------------------------------------------+------------------------------+----------------+-------------+------------+------------+-------------+----------+---------------+
| CAN0_SIG_GS2_fuse_state                  | 24                           | 8              | 0.0         | 255        | 1.0        | 0.0         | none     | Intel         |
+------------------------------------------+------------------------------+----------------+-------------+------------+------------+-------------+----------+---------------+
| CAN0_SIG_GS2_lowCoinCellVolt             | 32                           | 8              | 0.0         | 255        | 1.0        | 0.0         | none     | Intel         |
+------------------------------------------+------------------------------+----------------+-------------+------------+------------+-------------+----------+---------------+
| CAN0_SIG_GS2_error_openWire              | 40                           | 8              | 0.0         | 255        | 1.0        | 0.0         | none     | Intel         |
+------------------------------------------+------------------------------+----------------+-------------+------------+------------+-------------+----------+---------------+
| CAN0_SIG_GS2_daisyChain                  | 48                           | 8              | 0.0         | 255        | 1.0        | 0.0         | none     | Intel         |
+------------------------------------------+------------------------------+----------------+-------------+------------+------------+-------------+----------+---------------+
| CAN0_SIG_GS2_plausibilityCheck           | 56                           | 8              | 0.0         | 255        | 1.0        | 0.0         | none     | Intel         |
+------------------------------------------+------------------------------+----------------+-------------+------------+------------+-------------+----------+---------------+

The signals of the messages ``CAN0_MSG_SystemState_0`` , ``CAN0_MSG_SystemState_1``
and ``CAN0_MSG_SystemState_2`` display information about the system status of
the battery system.

``CAN0_SIG_GS0_general_error`` indicates if and an error is detected from the BMS:

* Bit[0]: maximum safety limit violated, CAN timing, current sensor or contactor error detected
* Bit[1]: recommended safety limit violated
* Bit[2]: maximum operating limit violated

The current state of the battery system is represented by the a bitfield in
signal ``CAN0_SIG_GS0_current_state``:

* 0x00: Uninitialized
* 0x03: Idle
* 0x04: Standby
* 0x05: Precharge (normal)
* 0x06: Normal
* 0x07: Precharge (charge)
* 0x08: Charge
* 0xF0: Error

The various error signals ``CAN0_SIG_GSx_error_xxxx`` give information about
limit violations and internal errors. In general, the following bitfield is used:

* Bit[0]: maximum safety limit violated
* Bit[1]: recommended safety limit violated
* Bit[2]: maximum operating limit violated

Flag ``CAN0_SIG_GS1_error_deep_discharge`` is a non-volatile flag saved in
backup SRAM that indicates if a deep-discharge of a cell has been detected.
This means that a power-cycle of the BMS won't reset the flag provided the coin
cell is not empty. The affected cell has to be replaced and the BMS won't
reset the flag until the corresponding CAN debug message was sent (see
:ref:`faq_reset_deep_discharge`).

``CAN0_SIG_GS1_error_temperature_MCU0`` indicates if the operating range of
the MCU0 junction temperature is violated. ``CAN0_SIG_GS1_error_cantiming``
is set to 1 if the can timing is violated (see #define CHECK_CAN_TIMING for
more information). ``CAN0_SIG_GS1_current_sensor`` is 1 if no current sensor is
detected and otherwise 0. ``CAN0_SIG_GS1_error_contactor`` is set to 1 if
contactor error is detected. This means the feedback signal of the contactor
doesn't match the controlled state. ``CAN0_SIG_GS1_error_cantiming`` occurs if
no state request message is received within 100ms. This feature can be
enabled/disabled (see :ref:`software_documentation_defines`). The signal
``CAN0_SIG_GS1_balancing_active`` is a simple flag to show if balancing is ON
(1) or OFF (0). ``CAN0_SIG_GS2_error_insulation`` indicates an insulation
error. ``CAN0_SIG_GS2_dieTempMCU`` indicates a violation of the primary MCU die
temperature.

The status of contactors and the interlock is represented as a bitfield in
``BMS1_status_contactors`` (0: open, 1: closed):

* Bit[0]: Plus (normal)
* Bit[1]: Precharge (normal)
* Bit[2]: Minus (normal)
* Bit[3]: Plus (charge)
* Bit[4]: Precharge (charge)
* Bit[5]: Minus (charge)
* Bit[6-8]: reserved for future use
* Bit[9]: Interlock status
* Bit[10-15]: reserved for future use

Bitfield ``CAN0_SIG_GS2_lowCoinCellVolt`` displays the coin cell
status.

* Bit[0]: Coin cell voltage low: swap battery in the near future
* Bit[1]: Coin cell voltage critically low: swap battery as soon as possible

``CAN0_SIG_GS2_error_openWire`` is set to 1 if an open voltage sense wire is
detected. Bitfield ``CAN0_SIG_GS2_fuse_state`` indicates the fuse state (0: fuse
intact, 1: fuse tripped):

* Bit[0]: Fuse state normal path
* Bit[1]: Fuse/Contactor state normal path
* Bit[2]: Fuse state charge path
* Bit[3]: Fuse/Contactor state charge path

A problem with the daisy-chain communication is indicated with bitfield
``CAN0_SIG_GS2_daisyChain`` (0: no error, 1: error)

* Bit[0]: spi error
* Bit[1]: ltc PEC error
* Bit[2]: multiplexer error

Plausibility errors detected by on of the checks are indicated with bitfield
``CAN0_SIG_GS2_plausibilityCheck`` (0: no error, 1: error)

* Bit[0]: cell voltage plausibility error
* Bit[1]: temperature sensor plausibility error
* Bit[2]: pack voltage plausibility error

----------------

+------------------------------------------+------------------------------+----------------+-------------+------------+------------+------------+----------+---------------+
| **Message: CAN_MSG_SlaveState_0**        | **Message ID: 0x115**        | **DLC: 8**     |             |            |            |            |          |               |
+------------------------------------------+------------------------------+----------------+-------------+------------+------------+------------+----------+---------------+
| **Signal name**                          | **Start bit**                | **Bit length** | **Min**     | **Max**    | **Factor** | **Offset** | **Unit** | **Byteorder** |
+------------------------------------------+------------------------------+----------------+-------------+------------+------------+------------+----------+---------------+
| CAN0_SIG_SS0_states                      | 0                            | 64             |  for future use (not implemented yet)                         |               |
+------------------------------------------+------------------------------+----------------+-------------+------------+------------+------------+----------+---------------+

+------------------------------------------+------------------------------+----------------+-------------+------------+------------+------------+----------+---------------+
| **Message: CAN_MSG_SlaveState_1**        | **Message ID: 0x116**        | **DLC: 8**     |             |            |            |            |          |               |
+------------------------------------------+------------------------------+----------------+-------------+------------+------------+------------+----------+---------------+
| **Signal name**                          | **Start bit**                | **Bit length** | **Min**     | **Max**    | **Factor** | **Offset** | **Unit** | **Byteorder** |
+------------------------------------------+------------------------------+----------------+-------------+------------+------------+------------+----------+---------------+
| CAN0_SIG_SS1_states                      | 0                            | 64             |  for future use (not implemented yet)                                         |
+------------------------------------------+------------------------------+----------------+-------------+------------+------------+------------+----------+---------------+

This messages indicate any errors with the |slaves| but this functionality is currently not supported.

----------------

+------------------------------------------+------------------------------+----------------+-------------+------------+------------+------------+----------+---------------+
| **Message: CAN0_RecOperatingCurrent**    | **Message ID: 0x130**        | **DLC: 8**     |             |            |            |            |          |               |
+------------------------------------------+------------------------------+----------------+-------------+------------+------------+------------+----------+---------------+
| **Signal name**                          | **Start bit**                | **Bit length** | **Min**     | **Max**    | **Factor** | **Offset** | **Unit** | **Byteorder** |
+------------------------------------------+------------------------------+----------------+-------------+------------+------------+------------+----------+---------------+
| CAN0_SIG_RecChargeCurrent                | 0                            | 16             | 0.0         | 6553.5     | 0.1        | 0.0        | A        | Intel         |
+------------------------------------------+------------------------------+----------------+-------------+------------+------------+------------+----------+---------------+
| CAN0_SIG_RecChargeCurrent_Peak           | 16                           | 16             | 0.0         | 6553.5     | 0.1        | 0.0        | A        | Intel         |
+------------------------------------------+------------------------------+----------------+-------------+------------+------------+------------+----------+---------------+
| CAN0_SIG_RecDischargeCurrent             | 32                           | 16             | 0.0         | 6553.5     | 0.1        | 0.0        | A        | Intel         |
+------------------------------------------+------------------------------+----------------+-------------+------------+------------+------------+----------+---------------+
| CAN0_SIG_RecDischargeCurrent_Peak        | 48                           | 16             | 0.0         | 6553.5     | 0.1        | 0.0        | A        | Intel         |
+------------------------------------------+------------------------------+----------------+-------------+------------+------------+------------+----------+---------------+

The recommended current capability of the battery system is indicated by the
signals of the previous table. For both discharge and charge directions, two
values are stated, one for the continuous current capability and one for the
peak current capability. Currently, the peak value is simply the same as the
continuous value. The resolution of the values is 0.1A, which should be of
sufficient granularity for most applications. It is a tradeoff that enables a
range up to 6553.5A in charge and discharge direction with reasonable
resolution.

----------------

.. note::

    This feature is currently not supported!

+------------------------------------------+------------------------------+----------------+-------------+------------+------------+------------+----------+---------------+
| **Message: CAN0_MSG_SOP**                | **Message ID: 0x131**        | **DLC: 8**     |             |            |            |            |          |               |
+------------------------------------------+------------------------------+----------------+-------------+------------+------------+------------+----------+---------------+
| **Signal name**                          | **Start bit**                | **Bit length** | **Min**     | **Max**    | **Factor** | **Offset** | **Unit** | **Byteorder** |
+------------------------------------------+------------------------------+----------------+-------------+------------+------------+------------+----------+---------------+
| CAN0_SIG_MaxChargePower                  | 0                            | 16             | 0.0         | 6553.5     | 0.1        | 0.0        | kW       | Intel         |
+------------------------------------------+------------------------------+----------------+-------------+------------+------------+------------+----------+---------------+
| CAN0_SIG_MaxChargePower_Peak             | 16                           | 16             | 0.0         | 6553.5     | 0.1        | 0.0        | kW       | Intel         |
+------------------------------------------+------------------------------+----------------+-------------+------------+------------+------------+----------+---------------+
| CAN0_SIG_MaxDischargePower               | 32                           | 16             | 0.0         | 6553.5     | 0.1        | 0.0        | kW       | Intel         |
+------------------------------------------+------------------------------+----------------+-------------+------------+------------+------------+----------+---------------+
| CAN0_SIG_MaxDischargePower_Peak          | 48                           | 16             | 0.0         | 6553.5     | 0.1        | 0.0        | kW       | Intel         |
+------------------------------------------+------------------------------+----------------+-------------+------------+------------+------------+----------+---------------+

The power capability of the battery system is indicated by the signals of the previous table. For both discharge and charge directions, two values are
stated, one for the continuous power capability and one for the peak power capability. Currently, the peak value is simply the same as the continuous value.
The resolution of the values is 100W, which should be of sufficient granularity for most applications. It is a tradeoff that enables a range up to 6553.5kW
in charge and discharge direction with reasonable resolution.

.. note::

    This feature is currently not supported!

----------------

+------------------------------------------+------------------------------+----------------+-------------+------------+------------+------------+----------+---------------+
| **Message: CAN0_MSG_SOC**                | **Message ID: 0x140**        | **DLC: 8**     |             |            |            |            |          |               |
+------------------------------------------+------------------------------+----------------+-------------+------------+------------+------------+----------+---------------+
| **Signal name**                          | **Start bit**                | **Bit length** | **Min**     | **Max**    | **Factor** | **Offset** | **Unit** | **Byteorder** |
+------------------------------------------+------------------------------+----------------+-------------+------------+------------+------------+----------+---------------+
| CAN0_SIG_SOC_mean                        | 0                            | 16             | 0.0         | 100.0      | 0.01       | 0.0        | %        | Intel         |
+------------------------------------------+------------------------------+----------------+-------------+------------+------------+------------+----------+---------------+
| CAN0_SIG_SOC_min                         | 16                           | 16             | 0.0         | 100.0      | 0.01       | 0.0        | %        | Intel         |
+------------------------------------------+------------------------------+----------------+-------------+------------+------------+------------+----------+---------------+
| CAN0_SIG_SOC_max                         | 32                           | 16             | 0.0         | 100.0      | 0.01       | 0.0        | %        | Intel         |
+------------------------------------------+------------------------------+----------------+-------------+------------+------------+------------+----------+---------------+
| CAN0_SIG_SOC_max                         | 48                           | 16             | currently not used                                                            |
+------------------------------------------+------------------------------+----------------+-------------+------------+------------+------------+----------+---------------+

Once initialized, ``CAN0_SIG_SOC_mean``, ``CAN0_SIG_SOC_min``, ``CAN0_SIG_SOC_max`` the values are updated via Coulomb counting. The values can be initialized either with a look-up table or by setting the values directly.

----------------

+------------------------------------------+------------------------------+----------------+-------------+------------+------------+------------+----------+---------------+
| **Message: CAN0_MSG_SOH**                | **Message ID: 0x150**        | **DLC: 8**     |             |            |            |            |          |               |
+------------------------------------------+------------------------------+----------------+-------------+------------+------------+------------+----------+---------------+
| **Signal name**                          | **Start bit**                | **Bit length** | **Min**     | **Max**    | **Factor** | **Offset** | **Unit** | **Byteorder** |
+------------------------------------------+------------------------------+----------------+-------------+------------+------------+------------+----------+---------------+

This message is currently not backed up with information and provided for forward-compatibility only.

----------------

+------------------------------------------+------------------------------+----------------+-------------+------------+------------+------------+----------+---------------+
| **Message: CAN0_MSG_SOE**                | **Message ID: 0x160**        | **DLC: 8**     |             |            |            |            |          |               |
+------------------------------------------+------------------------------+----------------+-------------+------------+------------+------------+----------+---------------+
| **Signal name**                          | **Start bit**                | **Bit length** | **Min**     | **Max**    | **Factor** | **Offset** | **Unit** | **Byteorder** |
+------------------------------------------+------------------------------+----------------+-------------+------------+------------+------------+----------+---------------+

This message is currently not backed up with information and provided for forward-compatibility only.

----------------

+------------------------------------------+------------------------------+----------------+-------------+------------+------------+------------+----------+---------------+
| **Message: CAN_MinMaxCellVoltages**      | **Message ID: 0x170**        | **DLC: 8**     |             |            |            |            |          |               |
+------------------------------------------+------------------------------+----------------+-------------+------------+------------+------------+----------+---------------+
| **Signal name**                          | **Start bit**                | **Bit length** | **Min**     | **Max**    | **Factor** | **Offset** | **Unit** | **Byteorder** |
+------------------------------------------+------------------------------+----------------+-------------+------------+------------+------------+----------+---------------+
| CAN0_SIG_Cellvolt_mean                   | 0                            | 16             | 0.0         | 65535      | 1.0        | 0.0        | mV       | Intel         |
+------------------------------------------+------------------------------+----------------+-------------+------------+------------+------------+----------+---------------+
| CAN0_SIG_Cellvolt_min                    | 16                           | 16             | 0.0         | 65535      | 1.0        | 0.0        | mV       | Intel         |
+------------------------------------------+------------------------------+----------------+-------------+------------+------------+------------+----------+---------------+
| CAN0_SIG_Cellvolt_max                    | 32                           | 16             | 0.0         | 65535      | 1.0        | 0.0        | mV       | Intel         |
+------------------------------------------+------------------------------+----------------+-------------+------------+------------+------------+----------+---------------+
| CAN0_SIG_ModNumber_volt_min              | 48                           | 8              | 0.0         | 255        | 1.0        | 0.0        | none     | Intel         |
+------------------------------------------+------------------------------+----------------+-------------+------------+------------+------------+----------+---------------+
| CAN0_SIG_ModNumber_volt_max              | 56                           | 8              | 0.0         | 255        | 1.0        | 0.0        | none     | Intel         |
+------------------------------------------+------------------------------+----------------+-------------+------------+------------+------------+----------+---------------+

The minimum, maximum and mean voltage are transmitted in the signals ``CAN0_SIG_Cellvolt_min``, ``CAN0_SIG_Cellvolt_max`` and ``CAN0_SIG_Cellvolt_mean``.
Additionally, the number of the module with minimum and maximum voltage is indicated in the signals ``CAN0_SIG_ModNumber_volt_min`` and ``CAN0_SIG_ModNumber_volt_max``.
Indexing of module numbers starts from zero.

----------------

+------------------------------------------+------------------------------+----------------+-------------+------------+------------+------------+----------+---------------+
| **Message: CAN0_MSG_SOV**                | **Message ID: 0x171**        | **DLC: 8**     |             |            |            |            |          |               |
+------------------------------------------+------------------------------+----------------+-------------+------------+------------+------------+----------+---------------+
| **Signal name**                          | **Start bit**                | **Bit length** | **Min**     | **Max**    | **Factor** | **Offset** | **Unit** | **Byteorder** |
+------------------------------------------+------------------------------+----------------+-------------+------------+------------+------------+----------+---------------+

This message is currently not backed up with information and provided for forward-compatibility only.

----------------

+------------------------------------------+------------------------------+----------------+-------------+------------+------------+------------+----------+---------------+
| **Message: CAN0_MinMaxCellTemperatures** | **Message ID: 0x180**        | **DLC: 8**     |             |            |            |            |          |               |
+------------------------------------------+------------------------------+----------------+-------------+------------+------------+------------+----------+---------------+
| **Signal name**                          | **Start bit**                | **Bit length** | **Min**     | **Max**    | **Factor** | **Offset** | **Unit** | **Byteorder** |
+------------------------------------------+------------------------------+----------------+-------------+------------+------------+------------+----------+---------------+
| CAN0_SIG_Celltemp_mean                   | 0                            | 16             | -128.0      | 527.35     | 0.01       | -128.0     | °C       | Intel         |
+------------------------------------------+------------------------------+----------------+-------------+------------+------------+------------+----------+---------------+
| CAN0_SIG_Celltemp_min                    | 16                           | 16             | -128.0      | 527.35     | 0.01       | -128.0     | °C       | Intel         |
+------------------------------------------+------------------------------+----------------+-------------+------------+------------+------------+----------+---------------+
| CAN0_SIG_Celltemp_max                    | 32                           | 16             | -128.0      | 527.35     | 0.01       | -128.0     | °C       | Intel         |
+------------------------------------------+------------------------------+----------------+-------------+------------+------------+------------+----------+---------------+
| CAN0_SIG_ModNumber_temp_min              | 48                           | 8              | 0.0         | 255        | 1.0        | 0.0        | none     | Intel         |
+------------------------------------------+------------------------------+----------------+-------------+------------+------------+------------+----------+---------------+
| CAN0_SIG_ModNumber_temp_max              | 56                           | 8              | 0.0         | 255        | 1.0        | 0.0        | none     | Intel         |
+------------------------------------------+------------------------------+----------------+-------------+------------+------------+------------+----------+---------------+

The minimum, maximum and mean temperature are transmitted in the signals ``CAN0_SIG_Celltemp_min``, ``CAN0_SIG_Celltemp_max`` and ``CAN0_SIG_Celltemp_mean``,
respectively. Additionally, the number of the module with minimum and maximum temperature is indicated in the signals ``CAN0_SIG_ModNumber_temp_min`` and
``CAN0_SIG_ModNumber_temp_max``, respectively. Indexing of module numbers starts from zero.

----------------

+------------------------------------------+------------------------------+----------------+-------------+------------+------------+------------+----------+---------------+
| **Message: CAN0_Tempering**              | **Message ID: 0x190**        | **DLC: 8**     |             |            |            |            |          |               |
+------------------------------------------+------------------------------+----------------+-------------+------------+------------+------------+----------+---------------+
| **Signal name**                          | **Start bit**                | **Bit length** | **Min**     | **Max**    | **Factor** | **Offset** | **Unit** | **Byteorder** |
+------------------------------------------+------------------------------+----------------+-------------+------------+------------+------------+----------+---------------+
| CAN0_SIG_CoolingNeeded                   | 0                            | 8              | 0.0         | 255        | 1.0        | 0.0        | none     | Intel         |
+------------------------------------------+------------------------------+----------------+-------------+------------+------------+------------+----------+---------------+
| CAN0_SIG_HeatingNeeded                   | 8                            | 8              | 0.0         | 255        | 1.0        | 0.0        | none     | Intel         |
+------------------------------------------+------------------------------+----------------+-------------+------------+------------+------------+----------+---------------+
| CAN0_SIG_TemperingDemand                 | 16                           | 32             | 0.0         | 0xFFFFFFFF | 1.0        | 0.0        | none     | Intel         |
+------------------------------------------+------------------------------+----------------+-------------+------------+------------+------------+----------+---------------+

The signals ``CAN0_SIG_CoolingNeeded``, ``CAN0_SIG_HeatingNeeded`` and ``CAN0_SIG_TemperingDemand`` are left free for use for application specific development.
Here, ``CAN0_SIG_CoolingNeeded`` and ``CAN0_SIG_HeatingNeeded`` could be simple ON/OFF flags and ``CAN0_SIG_TemperingDemand`` could be a 'continuous' value
indicating the needed cooling/heating power.

----------------

+------------------------------------------+------------------------------+----------------+-------------+------------+------------+------------+----------+---------------+
| **Message: CAN0_Insulation**             | **Message ID: 0x1A0**        | **DLC: 8**     |             |            |            |            |          |               |
+------------------------------------------+------------------------------+----------------+-------------+------------+------------+------------+----------+---------------+
| **Signal name**                          | **Start bit**                | **Bit length** | **Min**     | **Max**    | **Factor** | **Offset** | **Unit** | **Byteorder** |
+------------------------------------------+------------------------------+----------------+-------------+------------+------------+------------+----------+---------------+
| CAN0_SIG_InsulationStatus                | 0                            | 8              | 0.0         | 255        | 1.0        | 0.0        | none     | Intel         |
+------------------------------------------+------------------------------+----------------+-------------+------------+------------+------------+----------+---------------+
| CAN0_SIG_InsulationValue                 | 8                            | 16             | 0.0         | 65535      | 1.0        | 0.0        | kOhm     | Intel         |
+------------------------------------------+------------------------------+----------------+-------------+------------+------------+------------+----------+---------------+

The signal ``CAN0_SIG_InsulationStatus`` indicates if the insulation value is greater than the threshold value and  ``CAN0_SIG_InsulationValue`` holds the
measured insulation value by the insulation monitoring device.

----------------

+------------------------------------------+------------------------------+----------------+-------------+------------+------------+------------+----------+---------------+
| **Message: CAN0_MovAveragePower_0**      | **Message ID: 0x1D0**        | **DLC: 8**     |             |            |            |            |          |               |
+------------------------------------------+------------------------------+----------------+-------------+------------+------------+------------+----------+---------------+
| **Signal name**                          | **Start bit**                | **Bit length** | **Min**     | **Max**    | **Factor** | **Offset** | **Unit** | **Byteorder** |
+------------------------------------------+------------------------------+----------------+-------------+------------+------------+------------+----------+---------------+
| CAN0_SIG_MovAverage_Power_1s             | 0                            | 32             | -2500000    | 4292467295 | 1.0        | -2500000   | W        | Intel         |
+------------------------------------------+------------------------------+----------------+-------------+------------+------------+------------+----------+---------------+
| CAN0_SIG_MovAverage_Power_5s             | 32                           | 32             | -2500000    | 4292467295 | 1.0        | -2500000   | W        | Intel         |
+------------------------------------------+------------------------------+----------------+-------------+------------+------------+------------+----------+---------------+

+------------------------------------------+------------------------------+----------------+-------------+------------+------------+------------+----------+---------------+
| **Message: CAN0_MovAveragePower_1**      | **Message ID: 0x1D1**        | **DLC: 8**     |             |            |            |            |          |               |
+------------------------------------------+------------------------------+----------------+-------------+------------+------------+------------+----------+---------------+
| **Signal name**                          | **Start bit**                | **Bit length** | **Min**     | **Max**    | **Factor** | **Offset** | **Unit** | **Byteorder** |
+------------------------------------------+------------------------------+----------------+-------------+------------+------------+------------+----------+---------------+
| CAN0_SIG_MovAverage_Power_10s            | 0                            | 32             | -2500000    | 4292467295 | 1.0        | -2500000   | W        | Intel         |
+------------------------------------------+------------------------------+----------------+-------------+------------+------------+------------+----------+---------------+
| CAN0_SIG_MovAverage_Power_30s            | 32                           | 32             | -2500000    | 4292467295 | 1.0        | -2500000   | W        | Intel         |
+------------------------------------------+------------------------------+----------------+-------------+------------+------------+------------+----------+---------------+

+------------------------------------------+------------------------------+----------------+-------------+------------+------------+------------+----------+---------------+
| **Message: CAN0_MovAveragePower_2**      | **Message ID: 0x1D2**        | **DLC: 8**     |             |            |            |            |          |               |
+------------------------------------------+------------------------------+----------------+-------------+------------+------------+------------+----------+---------------+
| **Signal name**                          | **Start bit**                | **Bit length** | **Min**     | **Max**    | **Factor** | **Offset** | **Unit** | **Byteorder** |
+------------------------------------------+------------------------------+----------------+-------------+------------+------------+------------+----------+---------------+
| CAN0_SIG_MovAverage_Power_60s            | 0                            | 32             | -2500000    | 4292467295 | 1.0        | -2500000   | W        | Intel         |
+------------------------------------------+------------------------------+----------------+-------------+------------+------------+------------+----------+---------------+
| CAN0_SIG_MovAverage_Power_config         | 32                           | 32             | -2500000    | 4292467295 | 1.0        | -2500000   | W        | Intel         |
+------------------------------------------+------------------------------+----------------+-------------+------------+------------+------------+----------+---------------+

The messages ``CAN0_MovAveragePower_0``, ``CAN0_MovAveragePower_1`` and
``CAN0_MovAveragePower_2`` provide moving average values over the different time
frames 1s, 5s, 10s, 30s and 60s. The signal ``CAN0_SIG_MovAverage_Power_config``
can be configured to an arbitrary duration. The default configuration is 3
seconds.

----------------
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

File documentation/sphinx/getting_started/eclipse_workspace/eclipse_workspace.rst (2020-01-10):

.. include:: ../../macros.rst

.. _GETTING_STARTED_ECLIPSE_WORKSPACE:

====================================
Eclipse Workspace Setup and Flashing
====================================

In this section, it is shown how to set up an Eclipse workspace to work with
the |foxBMS| sources. Within the workspace, it is possible to flash the
compiled sources on the |Master|.

Setting an Eclipse Workspace
============================

..  warning::
    Every part of this setup instruction must be read carefully and it must be
    followed step by step, including details. If this is not the case, the
    Eclipse Workspace will not work.

..  warning::
    Only |foxconda_name| (see :ref:`GETTING_STARTED_FOXCONDA`) is supported.
    The support for older versions of |foxconda_old| has been dropped.

In the following, it is described which requirements have to be fulfilled and
what steps have to be made to setup an Eclipse workspace for working with the
|foxbms| sources.

..  note::
    The following setup instructions use two variables which have to be adapted
    to the user's settings. The example below shows how to adapt these two
    variables.

    -   **Variable 1**: Path to the project directory

        -   The project directory is |setup_dir|. The path to the project is
            therefore |setup_path| (e.g., |setup_dir_example|,
            |setup_dir_example2|, etc.). This means, during this setup
            procedure where ever the variable |setup_path| occurs it needs to
            be replaced with actual project directory on the machine (e.g.,
            |setup_dir_example| or |setup_dir_example2|, etc.).

        -   The path to the project directory must not contain spaces.

    -   **Variable 2**: Path to |foxconda_name| installation

            -   The preferred installation path of |foxconda_name| is
                |foxconda_default_windows_path|. This path will be used during
                the setup. If this is changed, it is up to the reader to change
                it at time to the appropriate path. It is strongly recommended
                to install foxconda to |foxconda_default_windows_path|.

            -   If |foxconda_name| is installed into
                |foxconda_default_windows_path| some steps of these
                instructions can be skipped. These steps are indicated.

Requirements
------------

The following requirements have to be fulfilled to be able to set up an Eclipse
Workspace for working with the |foxbms| sources.

-   |foxconda_name| is installed.

-   |foxbms| source files are downloaded to |setup_path|. Getting the source
    files is described in section ":ref:`getting_started_build`".

-   `Eclipse CDT <https://www.eclipse.org/cdt/>`_ , in version Oxygen.1.Release
    (4.7.1a). Eclipse CDT Oxygen.1.Release (4.7.1a) can be downloaded form
    `eclipse.org <https://www.eclipse.org/downloads/packages/eclipse-ide-cc-developers/oxygenr>`_.
    After downloading the ``.zip file`` and extracting it, ``eclipse.exe`` must
    be started to launch ``Eclipse CDT``.

-   The following plugins must be installed into ``Eclipse CDT``. ``PyDev``
    (`PyDev project website <https://www.pydev.org/>`_) is mandatory, while
    ``LiClipseText``
    (`LiClipseText project website <http://www.liclipse.com/>`_) is optional.
    However it is recommended to install both plugins. The plugins can be
    installed from the ``Eclipse Marketplace``.

    .. _eclipse_marketplace:
    

            ``Eclipse Marketplace``

    - Installing ``PyDev``

            .. _pydev_plugin:
            

                ``PyDev`` Eclipse plugin

        - Click |ECLIPSEINSTALL| to install the plugin.

    - Installing ``LiClipseText``

            .. _liclipsetext_plugin:
            

                ``LiClipseText`` Eclipse plugin

        - Click |ECLIPSEINSTALL| to install the plugin.

How to Setup the Eclipse Workspace
----------------------------------

The setup process is divided into following parts:

 #. :ref:`creating_the_workspace`
 #. :ref:`configuring_the_python_interpreter`
 #. :ref:`importing_the_project`
 #. :ref:`configuring_the_project_paths`
 #. :ref:`configuring_the_project_includes`
 #. :ref:`testing_the_project_setup`

The order of these steps must **not** be changed.

.. _creating_the_workspace:

Creating the Workspace
++++++++++++++++++++++

The Eclipse Workspace will be called ``.ws``.

#.  Start ``Eclipse`` and click ``File`` -> ``Switch Workspace`` -> ``other``
    and configure ``path\to\foxbms\.ws`` as workspace, see
    :numref:`Fig. %s <switch_workspace>`.

    .. _switch_workspace:
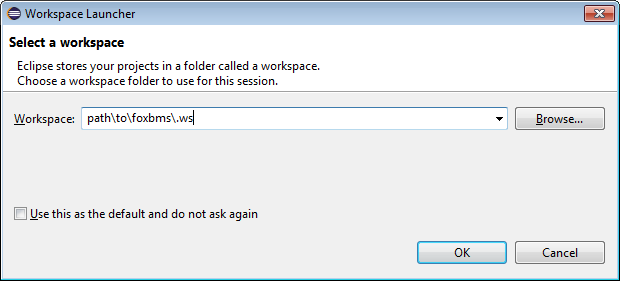
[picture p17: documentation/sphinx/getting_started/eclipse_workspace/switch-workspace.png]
    

        Selecting the correct workspace location

#. Click |ECLIPSELAUNCH|

|OK| The |foxbms| Eclipse Workspace is now successfully created. |OK|

.. _DEFAULT_ENCODING_AND_NEWLINE_DELIMITER:

Configuring Default Encoding and Newline Delimiter
++++++++++++++++++++++++++++++++++++++++++++++++++

#.  Open ``Window`` -> ``Preferences`` -> ``General`` -> ``Workspace``

#.  Set ``Text file encoding`` to ``Other: UTF-8`` and
    ``New text file line delimiter`` and select ``Other: Windows``

    ..  _SET_DEFAULT_ENCODING_AND_NEWLINE_DELIMITER:
    ..  figure:: eclipse-default-file-encoding-and-newline-delimiter.png

        Setting the default file encoding and the line delimiter

#.  Click |ECLIPSEAPPLYANDCLOSE|

.. _configuring_the_python_interpreter:

Configuring the Python Interpreter
++++++++++++++++++++++++++++++++++

#.  Open ``Window`` -> ``Preferences`` -> ``PyDev`` -> ``Interpreters`` ->
    ``Python Interpreter``.

    ..  _select_python_interpreter:
    ..  figure:: select-python-interpreter-1.png

        Selecting the python interpreter

#.  Click |ECLIPSENEW|.
    In the window ``Select Interpreter`` use

    #.  |foxconda_name| for the ``Interpreter Name``

    #.  |foxconda_pythonexe_path| for ``Interpreter Executable``.

    ..  _select_python_interpreter_2:
    ..  figure:: select-python-interpreter-2.png
        :width: 80 %

        Choosing the python interpreter name and executable

#.  Click |ECLIPSEOK|

#.  In menu ``Selection needed`` do not change anything and click |ECLIPSEOK|

    ..  _python_selection_needed:
    ..  figure:: python-selection-needed.png
        :width: 80 %

        Adding the ``PYTHONPATH``

#.  Click |ECLIPSEAPPLYANDCLOSE|

    ..  _python_configuration_done:
    ..  figure:: python-configuration-done.png
        :width: 80 %

        Configuration done

|OK| |foxconda_name| is now successfully selected as Python interpreter. |OK|

.. _importing_the_project:

Importing the Project
+++++++++++++++++++++

#.  Import the project via ``File`` -> ``Import``

    .. _eclipse_import.png:
    

        Select ``Import``

#.  Click ``General`` -> ``Existing Projects into Workspace``.

    ..  _setup_project_existing_projects_into_workspace.png:
    ..  figure:: setup-project-existing-projects-into-workspace.png

        Select projects import by ``Existing Projects into Workspace``

#.  Click |ECLIPSENEXT|

#.  Chose ``Select archive file:`` and use
    ``path\to\foxbms\tools\eclipse\foxbms-eclipse-project.zip``
    This will list the |foxbms| projects.

    .. _setup-project-import-projects.png:
    

        Select all projects to be imported

    .. note::
        Always import all projects that appear, as the number of projects might
        increase with future updates and this help might not be up-to-date.

#.  Click |ECLIPSEFINISH| to complete the project import process.

|OK| The |foxbms| projects are now successfully imported. |OK|

.. _configuring_the_project_paths:

Configuring the Project PATHs
+++++++++++++++++++++++++++++

..  note::
    If |foxconda_name| was installed in the default installation path
    (|foxconda_default_windows_path|), this section can be skipped.

For this setup: Change the path |foxconda_default_windows_path| to the path
where |foxconda_name| was installed to.

#.  Select the ``Primary`` project and click right and select ``Properties``.

    ..  _eclipse_project_properties.png:
    ..  figure:: eclipse-project-properties.png

        Eclipse project properties

#.  Goto ``C/C++ Build`` -> ``Environment``. Select ``[All configurations]``

    ..  _eclipse_project_properties_c_cpp_environment.png:
    ..  figure:: eclipse-project-properties-c-cpp-environment.png

        ``C/C++ Build`` project properties

        #. Click |ECLIPSEADD| and

            #.  use ``FOXCONDA3`` for ``Name``

            #.  use
                ``C:\foxconda3;``
                ``C:\foxconda3\bin;``
                ``C:\foxconda3\Scripts;``
                ``C:\foxconda3\Library\bin;``
                ``C:\foxconda3\Lib;``
                for ``Value``.

                .. warning::
                    -   The ``Value`` property  must not include spaces.
                    -   Do not add a backslash (``\``) at the end of the paths.
                    -   These paths need to be in a single line.

            #.  Check ``Add to all configurations``

            #.  Click |ECLIPSEOK|

        #. Click |ECLIPSEADD| and

            #.  Use ``PATH`` for ``Name``
            #.  Leave ``Value`` empty
            #.  Click |ECLIPSEOK|

        #. Select the ``PATH`` entry and click |ECLIPSEEDIT|

            #.  Delete all entries in ``Value``
            #.  Add ``${FOXCONDA3};`` to ``Value``
            #.  Click |ECLIPSEOK|

    The result should look like this:

    ..  _project_path_adding.png:
    ..  figure:: project-path-adding.png

        ``Environment`` settings for the project.

#.  Repeat these steps for the following projects:

    - ``documentation``
    - ``foxbms``
    - ``secondary``

|OK| The |foxbms| projects now include the correct environment settings. |OK|

.. _configuring_the_project_includes:

Configuring the Project Includes
++++++++++++++++++++++++++++++++

..  note::
    If |foxconda_name| was installed in the default installation path
    (|foxconda_default_windows_path|), this section can be skipped.

For this setup: Change the path |foxconda_default_windows_path| to the path
where |foxconda_name| was installed to.

#.  Select the ``primary`` project and click right. Goto ``C/C++ General`` ->
    ``Paths and Symbols`` and switch to Tab ``Includes``.

#.  Click |ECLIPSEADD| for ``Assembly``, ``GNU C`` and ``GNU C++`` and
    configure the following two paths as ``Includes``

    #. ``C:\foxconda3\Library\arm-none-eabi\include``

    #. ``C:\foxconda3\Library\lib\gcc\arm-none-eabi\4.9.3\include``

    ..  _include_header.png:
    ..  figure:: include-header.png

        Adding the gcc-includes to a project

    #. Click |ECLIPSEAPPLYANDCLOSE|

#.  Repeat this procedure for the ``secondary`` project.

#.  Restart Eclipse

|OK| The |foxbms| projects are now successfully configured. |OK|

.. _testing_the_project_setup:

Testing the Project Setup
+++++++++++++++++++++++++

#. ``foxbms`` project

    #.  Select the ``foxbms`` project and click |ECLIPSEHAMMER| button and
        select ``1 configure``. The project is now configured and all options
        (building documentation and binaries) can now be used.

        ..  code-block:: console

            'configure' finished successfully (0.450s)

    #.  Select the ``foxbms`` project and click |ECLIPSEHAMMER| button and
        select ``2 help``. The project help for building is printed.

#.  ``documentation`` project

    #.  Select the ``documentation`` project and click on the dropdown menu of
        the |ECLIPSEHAMMER| button and select ``1 sphinx`` to build the general
        |foxbms| documentation.

        ..  code-block:: console

            'sphinx' finished successfully (0.105s)

    #. The ``Documentation`` project is now successfully tested.

#.  ``primary`` project

    #.  Select the ``primary`` project and click on the dropdown menu of the
        |ECLIPSEHAMMER| button and select ``1 build_primary`` to build the
        |foxbms| binaries of the primary mcu.

        The binary generation was successful, if the Eclipse console puts the
        following line at the bottom:

        ..  code-block:: console

            'build_primary' finished successfully (1.340s)

    #.  Select the ``primary`` project and click on the dropdown menu of the
        |ECLIPSEHAMMER| button and select ``2 doxygen_primary`` to build the
        |foxbms| embedded documentation of the primary mcu.

        The primary mcu dopxygen documentation generation was successful, if
        the Eclipse console puts the following line at the bottom:

        ..  code-block:: console

            'doxygen_primary' finished successfully (46.906s)

    #.  Select the ``primary`` project, right click the project and select
        ``Clean Project``

        The cleaning of the primary mcu binaries and doxygen documentation was
        successful, if the Eclipse console puts the following line at the
        bottom:

        ..  code-block:: console

            'clean_primary' finished successfully (1.065s)

    #. The ``primary`` project is now successfully tested.

#.  ``secondary`` project

    #.  Select the ``secondary`` project and repeat all steps of the
        ``primary`` project.

    #. The ``secondary`` project is now successfully tested.

|OK| The |foxbms| Eclipse Workspace is now successfully tested. |OK|

..  warning::

    To test flashing in the next step, binaries of the primary and secondary
    mcu need to be build again.

Optional Settings
-----------------

When working with the build scripts (``wscript``) it is more convenient to have
python syntax highlighting. The following has to be configured to achieve it:

#.  Click ``Window`` -> ``Preferences``

#. Select ``General`` -> ``Editors`` -> ``File Associations``

#.  At the entry ``File types`` click |ECLIPSEADD|

    ..  _syntax-highlighting-wscript-1.png:
    ..  figure:: syntax-highlighting-wscript-1.png

        ``File Associations`` settings

#.  Define the file type ``wscript`` and click |ECLIPSEOK|

    ..  _syntax-highlighting-wscript-2.png:
    ..  figure:: syntax-highlighting-wscript-2.png

        ``File type definition``

#.  Select the ``Python Editor`` as and click |ECLIPSEOK|

    #.  ..  _syntax-highlighting-wscript-3.png:
        ..  figure:: syntax-highlighting-wscript-3.png

        ``Editor Selection`` setting

#.  Finish the configuration by clicking |ECLIPSEAPPLYANDCLOSE|

    ..  _syntax-highlighting-wscript-4.png:
    ..  figure:: syntax-highlighting-wscript-4.png

        Final file association setting for ``wscript``

Flashing |foxbms|
=================

This section describes how to supply the |master| in order to flash both |MCU0|
and |MCU1| with the firmware produced by compiling the C-code source files.

This section shows how to connect the different parts of the |foxbms| platform.

Convention for Connector Numbering
----------------------------------

:numref:`Fig. %s <connector_convention_flash>` presents the convention for the
connector numbering. It is used throughout the documentation.

.. _connector_convention_flash:


    Supply connector pin out, receptable - rear view, header - front view
    (image source: MOLEX)

There are two types of connectors:

 * Header
 * Receptable, plugged into the header

The numbering shown on the left in
:numref:`fig. %s <connector_convention_flash>` is always valid when viewing in
the direction indicated by the arrow with the indication ``viewing direction``.
This must be taken into account when crimping the receptables.

Hardware Setup of |master| and |slaves|
---------------------------------------

The foxBMS system can be mounted in a metal housing, as shown in
:numref:`fig. %s <housing_flash>`.

.. _housing_flash:


    |master| housing

Connectors are available, shown in
:numref:`Fig. %s <foxbmsfront_quickstart_flash>`, which presents all the
connectors of the |master|.

.. _foxbmsfront_quickstart_flash:


    Front view of the |master| indicating the location of each header

For this section on flashing, only the connector ``Supply`` is needed.

Supply of the |master|
----------------------

The first step is to supply the |master|, which works with supply voltages
between 12V and 24V DC. To supply the |master|, a connector must be prepared
for the ``Supply`` connector as shown in
:numref:`table %s <master_supply_connector>`, which describes the different
pins used.

.. _sixcon_view:


.. _master_supply_connector:

.. table:: |BMS-Master| Supply Connector

   ====   =============    ============    ============
   Pin    Signal           Input/Output    Description
   ====   =============    ============    ============
   1      SUPPLY_EXT_2     Input           12 - 24V
   2      SUPPLY_EXT_2     Input           12 - 24V
   3      GND_EXT_2        Input           GND
   4      SUPPLY_EXT_0     Input           12 - 24V
   5      GND_EXT_0        Input           GND
   6      GND_EXT_2        Input           GND
   ====   =============    ============    ============

The supply is separated as follows:

 -  The microcontrollers and the isolation devices are supplied through the
    pins ``SUPPLY_EXT_0`` and ``GND_EXT_0``
 -  The contactors and the interlock are supplied through the pins
    ``SUPPLY_EXT_2`` and ``GND_EXT_2``

To power up the |master|, plug in the supply connector and apply a voltage
between 12V and 24V. ``SUPPLY_EXT_0`` / ``GND_EXT_0`` and ``SUPPLY_EXT_2`` /
``GND_EXT_2`` may be connected to the same source for this initial test. At
this point, the |master| should draw approximately 150mA at 12V or 110mA at
24V.

Primary and Secondary MCU
-------------------------

The |BMS-Master| has two MCUs: primary (|MCU0|) and secondary (|MCU1|). The
|MCU1| is present to ensure redundant safety especially when used in research
and development prototyping.

First, the primary MCU will be flashed.

In order to program the primary MCU, the mini USB jack indicated as
``Prim. USB`` in :numref:`fig. %s <foxbmsfront_quickstart_flash>` must be used
to connect the |master| to a PC. The |master| can be connected to a PC
immediately. When connecting |master| for the first time, the required drivers
will install automatically.

.. note::

      Before the connection is made between the |master| and the computer for
      the first time, the computer must be connected to the internet, because
      the operating system might look for drivers on the internet. It this
      fails, administrator rights are needed to install the driver.

In case of problems by the installation of the drivers, administrator rights
might be needed. Once the hardware is supplied with the appropriate voltage,
the |foxbms| binaries can be flashed.

The same procedure must be made for secondary: the mini USB jack indicated as
``Sec. USB`` in :numref:`fig. %s <foxbmsfront_quickstart_flash>` must be used
to connect the |master| to a PC. As for the primary MCU, the PC must be
connected to the internet before the connection is made with the |master| for
the first time.

Flashing the Compiled Sources for the Primary MCU
-------------------------------------------------

In the chapter :ref:`getting_started_build`, the |foxbms| sources have been
compiled and the generated binary is ready to be flashed.
The |MCU0| will be flashed first.

These binaries are needed:

 1. a binary file with the header
 2. a binary file with the main code

Unless the build process has been altered or different binaries should be
flashed, there is no need to change the default file locations. For this guide,
the default file locations are used.

The device must be connected to the computer with the USB cable. The |MCU0|
USB-connector must be used. The ``primary`` project must be select. Clicking on
the dropdown menu of the |ECLIPSEHAMMER| button and selecting
``3 flash_primary`` allows flashing the |foxbms| binaries of the primary mcu.

.. note::

    Make sure that CAN0 connector is either disconnected or that there is no
    traffic on CAN0 bus while flashing ``primary`` MCU. If this is not the
    case, the internal bootloader of the controller will select a wrong boot
    source and the flashing fails.

The connection state can also be checked by watching the LEDs on the |master|
hardware: for a running board, the green power LED is on, and the two indicator
LEDs (green and red) are blinking alternately. If the device is connected and
being flashed, the power-on LED is on but the two indicator LEDs are off.

The LEDs for the |MCU0| must be used. In the :ref:`getting_started_cabling`, it
is explained how to find the |MCU0| indicator LEDs.

When the flashing is complete, the flashing windows disappears and the
indicator LEDs start to blink again.

Under Windows 7 (64 bit), it can happen that the COMPORT number is increased by
Windows, leading to problems during flashing. This can be reset in registry, by
setting ``ComDB`` to zero in the entry
``HKEY_LOCAL_MACHINE::SYSTEM::CURRENT_CONTROL_SET::CONTROL::COM NAME ARBITER``.
This way, all COM ports used are reset.

Flashing the Compiled Sources for the Secondary MCU
---------------------------------------------------

The same procedure as explained above must be followed for the |MCU1|. The
difference is that the |MCU1| USB-connector must be used. The ``secondary``
project must be selected before clicking on the dropdown menu of the
|ECLIPSEHAMMER| button. ``3 flash_secondary`` must then be selected to flash the
|foxbms| binaries of the secondary mcu.

With the supplied code, the |MCU1| checks the temperatures and voltages. If one
or more of the values are outside the limits, the |MCU1| opens the interlock
line (thus opening the contactors). The interlock line remains open until the
|MCU1| is reset.

.. note::

    Setting the limits is safety relevant and must be done with care.

.. note::

    **Working without configuring the right battery cell voltage limits is
    dangerous and should never be done when real batteries are connected, since
    they may burn and explode when overcharged or shorted.**

The next step shown in :ref:`getting_started_cabling` is to connect a |slave|
to perform voltage and temperature measurement.

Debugging the Primary and Secondary MCU
---------------------------------------

The following two debuggers can be used for debugging and have been tested with
|foxBMS|:

 *  `Segger J-Link Plus <https://www.segger.com/j-link-plus.html>`_, with the
    `19-Pin Cortex-M adapter <https://www.segger.com/jlink-adapters.html#CM_19pin>`_
    (needed to connect to foxBMS)
 *  `Lauterbach ÂµTrace Debugger for Cortex-M <http://www.lauterbach.com>`_

 .. |OK|                     image:: ok.png

.. |ECLIPSEADD|             image:: eclipse-add.png
.. |ECLIPSEAPPLY|           image:: eclipse-apply.png
.. |ECLIPSEAPPLYANDCLOSE|   image:: eclipse-apply-and-close.png
.. |ECLIPSEEDIT|            image:: eclipse-edit.png
.. |ECLIPSEFINISH|          image:: eclipse-finish.png
.. |ECLIPSEHAMMER|          image:: eclipse-hammer.png
.. |ECLIPSEINSTALL|         image:: eclipse-install.png
.. |ECLIPSELAUNCH|          image:: eclipse-launch.png
.. |ECLIPSENEW|             image:: eclipse-new.png
.. |ECLIPSENEXT|            image:: eclipse-next.png
.. |ECLIPSEOK|              image:: eclipse-ok.png

.. |setup_dir|                      replace:: ``foxbms``
.. |setup_path|                     replace:: ``path\to\foxbms``
.. |setup_dir_example|              replace:: ``C:\Users\username\Documents\foxbms``
.. |setup_dir_example2|              replace:: ``C:\projects\foxbms``
.. |foxconda_old|                   replace:: ``foxconda``
.. |foxconda_name|                  replace:: ``foxconda3``
.. |foxconda_path|                  replace:: ``C:\foxconda3``
.. |foxconda_pythonexe_path|        replace:: ``C:\foxconda3\python.exe``
.. |foxconda_default_windows_path|  replace:: ``C:\foxconda3``

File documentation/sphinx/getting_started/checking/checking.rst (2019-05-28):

.. include:: ../../macros.rst

.. _GETTING_STARTED_CHECKING:

====================
Checking-up |foxbms|
====================

This section describes how to test the |BMS-Master| with one |BMS-Slave|
connected. These tests show if the hardware and software components of the
|BMS-Master| and |BMS-Slave| are working correctly:

-----------------
Required Hardware
-----------------

 - 1 * |BMS-Master| including a supply cable
 - 1 * |BMS-Slave|
 - 1 * Battery voltage simulation at the |BMS-Slave| (e.g., voltage divider)
 - 1 * CAN-Bus to PC adapter
 - 1 * Normally closed switch for opening the |il| (hereafter referred to as
   |eo|)
 - 3 * Contactors with normally open feedback (hereafter referred to as |pmc|,
   |ppc|, |mmc|)
 - 1 * Debugger (optionally, but recommended)

Testing Without Debugger
------------------------

It is also possible to get little information if the system is running
correctly without variable checking on the debugger. When requesting the later
described states to the BMS, the contactors opening and closing can be heard.

Testing With Debugger
---------------------

This test procedure gives more detailed test information when a debugger is
used. The following variables should be checked during the test:

- ``os_timer``
- ``sys_state``
- ``bms_state``
- ``ltc_cellvoltage``
- ``cont_contactor_states``
- ``ilck_interlock_state``

-----------------
Required Software
-----------------

- |foxbms| binaries for |MCU0| (`latest release on GitHub for primary <https://github.com/foxbms/mcu-primary>`_)
- |foxbms| binaries for |MCU1| (`latest release on GitHub for secondary <https://github.com/foxbms/mcu-secondary>`_)
- Debugger-Software
- Software to send CAN messages from the PC on the CAN bus.
- CAN message for |normal| and |stdby|

--------------
Test Procedure
--------------

The test procedure consists of three steps:

 #. Preparing the hardware
 #. Building the software from source
 #. Requesting bms-states to |BMS-Master| and checking variable values on the
    debugger

If no debugger is available, only a partially test if all parts of |foxbms| are
running correctly can be performed. As mentioned above, it can be checked
accoustically if the contactors are opening and closing. This is marked in the
`Test`_ with |hear| and the corresponding explanation if needed.

Hardware Setup
--------------

#. Apply voltages to the |BMS-Slave| cell measurement inputs (e.g., voltage divider)
#. Connect the daisy chain connector from the |BMS-Slave| to the
   |BMS-Master|.
#. Connect the |eo| to the |il| of the |BMS-Master|.
#. Connect the following contactors to the |BMS-Master|:

   #. ``contactor 0`` the |pmc| in the positive current path
   #. ``contactor 1`` the |ppc| in the positive current path
   #. ``contactor 2`` the |mmc| in the negative current path

#. Connect the CAN-interface to the PC
#. The debugger is connected from the PC to the JTAG-interface of |MCU0| of
   |BMS-Master| (optional).

Software Setup
--------------

#. Build the |foxbms| binaries for both, |MCU0| and |MCU1|.

Test
----

#. Power |BMS-Master|
#. Flash |foxbms| |MCU0| binaries on |MCU0|
#. Flash |foxbms| |MCU1| binaries on |MCU1|
#. Start CAN-communication viewer (e.g., PCAN-View when using PCAN-USB)
#. Restart |BMS-Master|
#. Send CAN message for |req_stdby|
#. Check on the debugger if the system timer is running; variable: ``os_timer``
#. Check if |BMS-Slave| reads voltages; variable: ``ltc_cellvoltage``
#. |req_stdby|

   #. Check on the debugger if |il| is closed (|var_il| with ``ilck_interlock_state.feedback=ILCK_SWITCH_ON``)

#. |req_normal|

   #. Check on the debugger if contactors are closed in the correct order (|var_co|)

      #. close |mmc|
      #. close |ppc|
      #. close |pmc|
      #. open |ppc|

   |hear|: If this test is performed with no debugger, contactors can be clicking four times.

#. |req_stdby|

   #. Check on the debugger if |il| is closed (|var_il|)
   #. Check on the debugger if contactors are opened (|var_co|)

   |hear|: If this test is performed with no debugger, each contactor can be heard clicking one time.

#. |req_normal|

   #. Check on the debugger if contactors are closed in the correct order (|var_co|)

      #. close |mmc|
      #. close |ppc|
      #. close |pmc|
      #. open |ppc|

   |hear|: If this test is performed with no debugger, contactors can be heard clicking four times.

#. Open |il| by pressing |eo|

   #. Check on the debugger if |il| is opened (|var_il|)
   #. Check on the debugger if contactors are opened (|var_co|)

   |hear|: If this test is performed with no debugger, each contactor can be heard clicking one time.

#. |req_normal|

   #. BMS should switch to ``bms_state.state=BMS_STATEMACH_ERROR`` as the |il| is still open (|var_bms_state|)

#. Close |il| by releasing |eo|

   #. Check on the debugger if |il| is still open (|var_il|)
   #. BMS has to stay in error state (check |var_bms_state|)

#. |req_stdby|

   #. Check on the debugger if |il| is closed (|var_il|)
   #. Check on the debugger if contactors are still open (|var_co|)

#. |req_normal|

   #. Check on the debugger if contactors are closed in the correct order (|var_co|)

      #. close |mmc|
      #. close |ppc|
      #. close |pmc|
      #. open |ppc|

   |hear|: If this test is performed with no debugger, contactors can be heard clicking four times.

#. |req_stdby|

   #. Check on the debugger if |il| is closed (|var_il|)
   #. Check on the debugger if contactors are still open (|var_co|)

#. done

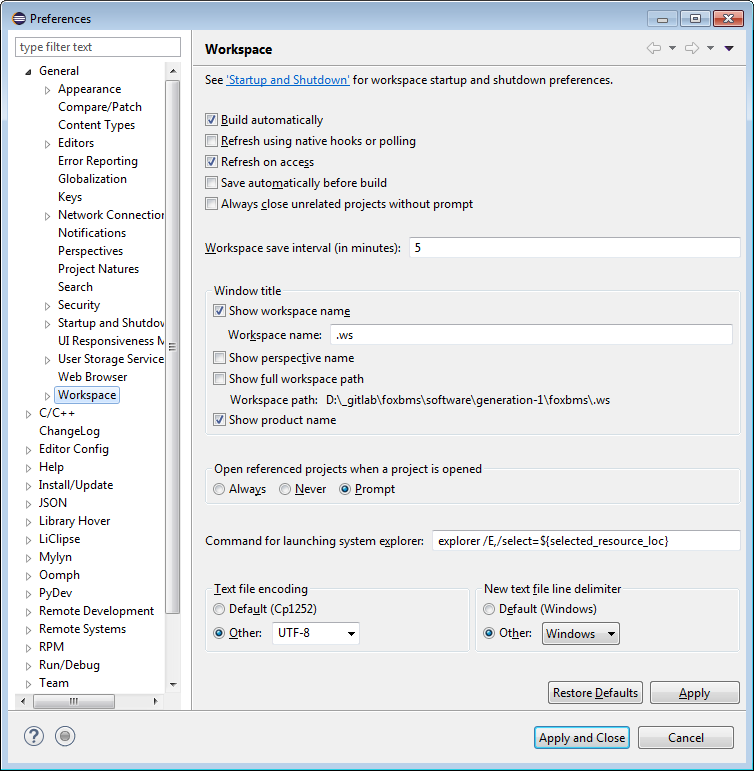
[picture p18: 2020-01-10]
documentation/sphinx/getting_started/eclipse_workspace/eclipse-default-file-encoding-and-newline-delimiter.png

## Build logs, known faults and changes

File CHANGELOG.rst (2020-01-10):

=========
Changelog
=========

**Release 1.6.3**

Software:

* Toolchain:

  * the flash process sometimes did not work correctly for the secondary MCU.
    The robustness of the `_ack` function was generally improved and flashing
    both, primary and secondary, MCU should no longer fail.
  * if foxBMS was not developed inside a git repository, building the binaries
    failed. For these cases building now succeeds and the binary is still
    runnable. This requires the define ``BUILD_ALLOW_DIRTY_STARTUP`` to be set
    to ``1`` (in ``general.h`` for both, primary and secondary MCU). Defining
    ``BUILD_ALLOW_DIRTY_STARTUP`` to ``1`` is the default setting.

* Bugfixes:

  * minimum, maximum and average SOC were identically if Coulomb counting
    feature of current sensors was used (``sox.c/h``)
  * recommended safety limit flag for undertemperature in charge direction was
    was never set. (``diag_cfg.c``)
  * diagnosis system monitoring error occured if ``ISOGUARD``-module was
    disabled (``isoguard.c``)
  * current sensor detection failed always if triggered mode was selected, as
    CAN TX messages were activated after check for current sensor (``sys.c``)

* Enhancements:

  * changed file structure to allow type definitions to be used as return
    values for static function prototypes (``cansignal_cfg.c``)

Hardware:

* none

Documentation:

* none

------------------------------------------------------------------------------

**Release 1.6.2**

Software:

* Toolchain:

  * added cpplint configuration file
  * added cppcheck configuration file
  * added flake8 configuration file
  * added busmaster project file

* Bugfixes:

  * cell voltages for module 4 for cells 12 and upwards were not transmitted
    via CAN (``cansignal_cfg.c``)
  * ISO_MeasureInsulation() did not correctly utilize DIAG_SysMonNotify(),
    which could lead to initialization errors (``isoguard.c``)
  * cell voltages and temperatures are now depicted in foxBMS-GUI if more than
    eight modules are selected (``foxbms_interface.py``)
  * compiling primary or secondary MCU binaries without COM module enabled led
    to a compile error
  * SPI chipselect pin for FPGA extension board was erroneously set in EEPROM
    module (``eepr.c``)

* Enhancements:

  * source code cleanup of interlock module (``interlock.c/h``)

Hardware:

* none

Documentation:

* fixed pinout of temperature sensor connectors X201 and X202 for 18-cell Slave
  ``v1.1.3 and above``

------------------------------------------------------------------------------

**Release 1.6.1**

Software:

* Toolchain:

  * none

* Bugfixes:

  * fixed the extension of the startup scripts (``*.S`` to ``*.s``)

* Enhancements:

  * none

Hardware:

* none

Documentation:

* none

------------------------------------------------------------------------------

**Release 1.6.0**

Software:

* Toolchain:

  * Updated to ``waf-2.0.15`` (from ``waf-2.0.14``)
  * ``size`` is now implemented as a waf-feature to speed up build times
  * foxBMS custom waf tasks displayed wrong information in the terminal about
    the running processes (e.g., ``Compiling`` instead of
    ``Creating hex file``)
  * fixed a task order constraint when building the elf file. For details see
    the updated build documentation (see section *Build Process*).
  * added a simple test, that verifies that low level drivers do not relay on
    higher level modules (e.g., FreeRTOS, database, etc.). A project can be
    tested by running ``python tools\waf build_primary_bare`` or
    ``python tools\waf build_secondary_bare`` (see section *Build Process*).
  * removed unnecessary ``run_always`` attribute to reduce build time
  * rewrote the build of libraries. Now libraries can be build independent from
    the project configuration. Libraries can then later be added to the project
    as needed with the ``configure --libs=...`` command (see section
    *Build Process*).
  * fixed ``clean_libs`` command as it did not remove all ``build_libs``
    artifacts
  * if an include directory does not exist, an error is raised
  * if a directory is included more than once, an error is raised
  * some build attributes of ``bld.env`` inside the ``wscript`` s haven been
    renamed (``__inc_hal`` to ``hal_dirs``, ``__inc_FreeRTOS`` to
    ``FreeRTOS_dirs``, ``__bld_common`` to ``common_dir``, ``__sw_dir`` to
    ``es_dir`` and ``__bld_project`` to ``mcu_dir``
  * an error is raised if the path to the foxBMS project directory contains
    whitespace
  * an error is raised if a comparison between signed and unsigned integers
    is used
  * ensured compatibility with PyYAML v5.1 by supplying a Loader-parameter
    to calls of yaml.load()
  * fixed generation of .hex file to only contain flash content
  * raise the ``switch``-warning to error in GCC
  * add a configuration for cppcheck to the repository
  * raise the ``type-limits``-warning to error in GCC
  * raise the ``double-promotion``-warning to error in GCC

* Bugfixes:

  * in the function ``LTC_RX_PECCheck()``, the LTC PEC (packet error code)
    check of the last module in the daisy-chain was overriding the PEC check
    of all preceding modules. If the PEC of the last module was correct, all
    other PECs were detected as correct, even if some errors were
    present (``ltc.c``)
  * fixed compile error, when setting define ``MEAS_TEST_CELL_SOF_LIMITS``
    to ``TRUE`` (``bms.c``)
  * some variables used to store database content at the beginning of the
    ``BMS_Trigger()`` function were defined as local variables. This could lead
    to a stack overflow if a high number of modules was configured. These
    variables have been defined as static to solve this issue (``bms.c``)
  * the ``DIAG_GeneralHandler`` has been removed. The ``DIAG_Handler`` must be
    used for all diagnosis instead, except for the diagnosis of the contactors,
    which is handled by ``DIAG_ContHandler``.
  * ``DIAG_Handler`` returned wrong value if it was called when an error has
    already been detected (``diag.c``)
  * If more cell voltages or temperatures were defined for CAN transmission
    than for measurement in the battery system, during transmission, the array
    boundaries of the local variables storing database entries were violated.
    now boundary violations are checked and default values are sent for CAN
    signals not corresponding to existing measurements. (``cansignal_cfg.c/h``)
  * fixed incorrect array offset mapping CAN1 RX messages to respective CAN1 RX
    signals (``cansignal.c``)
  * moved fuse state error handling from ``CONT`` module to ``BMS`` module to
    avoid ``CONT`` state machine switching into error state without ``BMS``
    state machine transitioning into error state
  * fixed an implicit cast to uint that prevented working protection of the
    battery cells against overdischarge and -charge below zero degrees
    (``bms.c``)
  * moved checksum feature to main ``wscript``
  * added initialization state flags to contactor-, BMS- and
    balancing-statemachine in order to fix race-conditions between these
    statemachines and the sys-statemachine
    (``sys.c/h``, ``bal.c/h``, ``bms.c/h``, ``contactor.c/h``)
  * fixed overlapping signals in dbc file for CAN message CAN_Cell_voltage_M2_0
  * fixed function ``BMS_CheckCurrent()``. If contactors opened in case of
    over-current, error flags remained set in spite of the current being
    back to zero.
  * allow for current thresholds in ``BMS_CheckCurrent()`` differing from the
    cell-limits and adaptable to both charge and normal powerline
    (``bms.c``, ``contactor.c/h``)

* Enhancements:

  * reimplemented UART COM Decoder as a non-realtime background task for easier
    use
  * removed direct register access in UART module to improve portability
    (``uart.c/h``)
  * added plausibility module to check pack voltage (``plausibility.c/h``)
  * added plausibility module to check cell voltage and cell temperature
    (``slaveplausibility.c/h``)
  * the Python wrapper and DLL needed to run the graphical user interface
    with a CAN-adapter from the company Peak are now redistributed with
    foxBMS. Before using them, the conditions in the file ``readme.txt`` in
    ``tools\gui`` must be read and accepted.
  * updated STM32 HAL to version 1.7.4 and CMSIS to version 2.6.2
  * rewrote CAN driver to work with new HAL CAN module introduced in
    HAL version 1.7.0 (``can.c/h``, ``can_cfg.c/h``)
  * updated FreeRTOS to version 10.2.0 and adapted FreeRTOSConfig.h accordingly
  * added dedicated datasheet files for EPCOS B57251V5103J060, EPCOS
    B57861S0103F045 and Vishay NTCALUG01A103G NTC sensors to calculate cell
    temperatures using either a look-up table or polynomial approximation
  * the diagnosis modules of primary and secondary were unified and moved to
    mcu-common
  * error and safe operating area flags are now written periodically (1ms) to
    prevent erroneous database operations due to concurrency effects
  * moved #define to configure current sensor response timeout from
    ``cansignal_cfg.h`` to ``batterysystem_cfg.h``
  * moved #define to select if current sensor is in cyclic or triggered mode
    from ``can_cfg.h`` to ``batterysystem_cfg.h``
  * added simple diag-function that allows to track the call period
    of system tasks
  * moved linker scripts from ``src`` to ``general\config\STM32F4xx``
  * moved FreeRTOS configuration headers from ``src\general\config`` to
    ``src\general\config\FreeRTOS``
  * removed ``MCU_0_`` and ``MCU_1_`` from the pin defines in ``io_mcu_cfg``
    to increase the readability of the drivers
  * added deep-discharge flag that gets set if the deep-discharge voltage limit
    is violated. Flag is stored in non-volatile backup SRAM and can only be
    reset with CAN debug message. This prevents closing the contactors
    before the affected cell has been replaced
  * added support for FreeRTOS runtime stats. The stats can be accessed by the
    new 'printstats' command in the COM module.
  * added state transition functions for ltc-statemachine to reduce
    code size (``ltc.c``)
  * added stack overflow-handler that can be used for debugging and detecting
    stack overflows during development
  * disabled dynamic allocation for operating system, removed heap-implementation
    and switched to static allocation for operating system components
  * information about the git repository from which the binaries are built is
    included in the binaries. The define ``BUILD_ALLOW_DIRTY_STARTUP`` has been
    added in ``general.h`` to allow or disallow the startup of the BMS in case
    of a non clean repository.
  * set error flag if current flows in spite of all contactors being open
    (``bms.c``)
  * added support for TCA6408A port expander in ``LTC`` module (write output
    pins and read input pins)
  * added decoding for up to 18 cell voltages per module in foxBMS interface

Hardware:

* removed version number from hardware file names

* Slave 12-cell v2.1.7

  * EMI layout improvements (targeting UN ECE R10 Revision 5)
  * added RC filters on NTC sensor inputs
  * replaced linear regulators for LTC6811 5V supply with DC/DC converters
  * added circuit for switching off 5V DC/DC converters in LTC sleep mode, thus
    reducing the current consumption to less than 20µA

* Interface LTC6820 v1.9.4

  * replaced connectors J500 and J501 with TE 534206-4 due to clearance issues
    in component placement

Documentation:

* added missing unit information for some CAN signals in section
  ``Communicating with foxBMS``
* added a section on how to configure ``conda`` to work behind a proxy.

------------------------------------------------------------------------------

**Release 1.5.5**

Software:

* Toolchain:

  * Updated to ``waf-2.0.14`` (from ``waf-2.0.13``)

* Bugfixes:

  * fixed UART frame error due to floating RX pin by enabling pull-up in the
    MCU
  * fixed reading wrong entry from database when checking battery system
    current against SOF limits (``bms.c``)
  * the flag SPI transmit_ongoing was reset incorrectly after SPI dummy byte
    was transmitted. This lead to invalid measured cell voltages if the
    daisy-chain was too long (i.e., more than 10 BMS-Slaves in the daisy-chain)
  * enabled simultaneous measurement of lithium-coin-cell V_bat and MCU
    temperature in ADC module
  * fixed error calculating MCU temperature in ADC module
  * balancing threshold for voltage-based balancing was set in the wrong place:
    it is now set in the function BAL_Activate_Balancing_Voltage (``bal.c``)

* Enhancements:

  * database entries are initialized with 0 to prevent undefined data if
    entries are read before valid values are written into the database
    (``database.c``)

Hardware:

* BMS-Slave 18-cell v1.1.5

  * EMI layout improvements (targeting UN ECE R10 Revision 5)
  * adapted component variations to simplify the management of component
    variations in Altium Designer
  * replaced DC/DC converter power inductor to comply with AEC-Q
  * added circuit for switching off DC/DC converters in LTC sleep mode, thus
    reducing the current consumption to less than 20µA
  * added pull-ups on GPIOs 6-9 of the LTCs (open-drain outputs) to enable them
    to be used as digital I/O

Documentation:

* BMS-Interface: fixed pin 11 in the pinout of the connectors for version 1.2.0
  and above
* Updated BMS-Slave 18-cell hardware documentation for version 1.1.5
* Updated year in copyright
* Fixed some wrong @file attributes in doxygen comments

------------------------------------------------------------------------------

**Release 1.5.4**

Software:

* Toolchain:

  * Added a Python script that implements a graphical user interface
    to communicate with foxBMS. The instructions in the README.md file
    supplied with the script must be followed.
  * Removed obsolete ``build.py`` wrapper
  * Updated to ``waf-2.0.13`` (from ``waf-2.0.12``)
  * Fixed a build error when using the ``build_all`` option

* Bugfixes:

  * In BMS module, wait time between error request to contactors and open
    request to interlock was increased. Otherwise, interlock opened before
    contactors were open. If this is the case, both contactors open at the
    same time without any delay between first and second contactor.
  * Fixed error in reading of interlock feedback.

* Enhancements:

  * none

Hardware:

* none

Documentation:

* none

------------------------------------------------------------------------------

**Release 1.5.3**

Software:

* Toolchain:

  * raised compiler warning ``[-Werror=comment]`` to error level
  * write compiler macros to header file for improved eclipse support

* Bugfixes:

  * fixed a bug, that caused the mcu temperature for primary and secondary mcu
    to be never updated.
  * fixed a bug, that caused the coin cell voltage of the primary mcu to be
    never updated.
  * rewrite of struct ``DIAG_RETURNTYPE_e``. The enumeration had
    non-consecutive numbering and potentially dangerous typo in duplicate enum
    (``DIAG_HANDLER_RETURN_ERR_OCCURED = 2`` and
    ``DIAG_HANDLER_RETURN_ERR_OCCURRED = 4``).
  * fixed a bug, that diagnosis entry for a voltage violation of the maximimum
    safety limit wrote to wrong database entry.
  * NVRAM module was compiled twice for primary mcu. Once it was compiled by
    mcu-common module and once again in mcu-primary module). Now compiled only
    once by mcu-common module as on mcu-secondary.

* Enhancements:

  * debug printing is replaced by ``printf`` for easier and more versatile
    usage
  * added additional basic math macros (e.g., LN10, PI etc.) in ``foxmath.h``
  * Fuse state is now monitored. Fuse can be placed in NORMAL and/or CHARGE
    path. Added flag to ``CAN0_MSG_SystemState_2`` message
  * added support to build and link multiple libraries
  * added warning flag if MCU die temperature is outside of operating range to
    ``CAN0_MSG_SystemState_2`` message
  * added warning flag to replace coin cell if measured coin cell voltage is
    low to ``CAN0_MSG_SystemState_2`` message
  * added daisy-chain communication error flags to ``CAN0_MSG_SystemState_2``
    message
  * added error flag if an open voltage sense wire is detected

Hardware:

* none

Documentation:

* updated library build documentation
* updated .dbc file

------------------------------------------------------------------------------

**Release 1.5.2**

Software:

* Toolchain:

  * updated to ``waf-2.0.12`` (from ``waf-2.0.11``)

* Bugfixes:

  * fixed bug that delay after SPI wake-up byte was not long enough

* Enhancements:

  * increased CPU clock frequency from 168MHz to 180MHz
  * increased SPI bitrate from 656.25kHz to 703.125kHz
  * added CAN boot message with SW-version and flash checksum (0x101)
  * CAN messages are now always sent, even if system error was detected
  * foxBMS SW-version requestable via CAN (request ID: 0x777, response ID: 0x101)
  * added insulation error flag to ``DATA_BLOCK_ERRORSTATE_s``
  * configurable behavior if contactors should be open on insulation error or not
  * separate configurable precharging for charge/discharge path possible

Hardware:

* Master v1.0.6

  * adapted CAN filter circuit for improved fault tolerance at short of CAN_L to GND or CAN_H to supply

* Extension v1.0.5

  * adapted CAN filter circuit for improved fault tolerance at short of CAN_L to GND or CAN_H to supply

Documentation:

* updated instruction for flashing primary MCU
* updated FAQ section

------------------------------------------------------------------------------

**Release 1.5.1**

Software:

* Toolchain:

  * toolchain compatible with POSIX operating systems
  * updated to ``waf-2.0.11`` (from ``waf-2.0.10``)
  * fixed missing files in eclipse workspace (CHANGELOG.rst and compiler-flags.yml)

* Bugfixes:

  * fixed bug updating BKPSRAM values to EEPROM: BKPSRAM checksum was calculated wrong

* Enhancements:

  * modules CONTACTOR, INTERLOCK and ISOGUARD can be disabled if not needed
  * selected new EEPROM M95M02 as default EEPROM (equipped on foxBMS-Master since v1.0.5)

Hardware:

* none

Documentation:

* added a section on how to build and include a library
* removed references to directory ``foxbms-setup``, as it is now simply called ``foxbms``
* removed references to script ``bootstrap.py``, as this script is no longer used

------------------------------------------------------------------------------

**Release 1.5.0**

* **foxBMS has been migrated from Python 2.7 to Python 3.6. The foxconda3 installer is found at https://iisb-foxbms.iisb.fraunhofer.de/foxbms/. foxconda3 must be installed to C:\foxconda3.**
* **EEPROM addresses on the BMS-Master were changed. Previous saved EEPROM data will be lost with new update.**
* **introduction of an improved software structure to differentiate between hardware-dependent and hardware-independent software layers**

Software:

* Toolchain:

  * switched to monolithic repository structure to simplify the versioning
  * raised compiler warning ``[-Wimplicit-function-declaration]`` to error level
  * avoid ``shell=True`` in python subprocess
  * updated python checksum script
  * updated to ``waf-2.0.10`` and renamed the waf binary to simply ``waf``

* Bugfixes:

  * fixed bug passing *mV* instead of *V* to function ``LTC_Convert_MuxVoltages_to_Temperatures()``
  * typedef ``DATA_BLOCK_ID_TYPE_e`` starts at 0x00 instead of 0x01 (renamed DATA_BLOCK_1 to DATA_BLOCK_00) for consistency
  * fixed bug in ltc module: wrote wrong values to database when using filtered mode for measuring cell voltages and temperatures
  * #define ``CONT_PRECHARGE_VOLTAGE_THRESHOLD`` used *V* instead of *mV*
  * fixed bug in function ``CAN_WakeUp()``: wrong HAL function call was corrected
  * fixed bug in diag module: did not evaluated diagnostic errors with ``DIAG_ERROR_SENSITIVITY_HIGH``

* Enhancements:

  * adapted wscripts to new restructured software architecture
  * added timestamp to MCU backup SRAM and external EEPROM entries
  * added three alarm levels (maximum operating limit, recommended safety limit, maximum safety limit)
  * enhanced voltage based balancing algorithm
  * updated .dbc file
  * added measure AllGPIO state to ltc module
  * added CAN message for pack voltage (CAN-ID: 0x1F0)
  * added algorithm module to enable future advanced algorithms
  * increased FreeRTOS heap size from 15kByte to 20kByte
  * increased stack size of 100ms application task from 512bytes to 1024bytes
  * increased size of CAN TX message buffer from 16 to 24 messages
  * added calculation of moving average values (1s, 5s, 10s, 30s and 60s) for current and power
  * database timestamp are now automatically written on DB_Write - no need to manually update timestamps anymore
  * added native matlab datatypes support
  * cleanup of ASCII conversion functions (uint to ASCII, hex to ASCII, int to ASCII)
  * added nvramhandler to automatically update non-volatile memory (i.e., external EEPROM on BMS-Master)
  * renamed various structs, variables and functions for an improved code understanding and increased readability

Hardware:

* added hardware changelogs
* ported hardware PCB design files to Altium Designer format (AutoDesk Eagle files no longer supported)
* updated hardware PCB designs: Master V1.0.5, Extension V1.0.4, Interface 1.9.3, Slave 12-cell (LTC6811-1) V2.1.5, Slave 18-cell (LTC6813-1) V1.1.3

Documentation:

* added foxbms styleguide
* fixed spelling errors
* added documentation of software architecture
* added documentation of algorithm module
* added documentation of nvramhandler
* updated isoguard documentation

------------------------------------------------------------------------------

**Release 1.1.0**

foxbms-setup(v1.0.1):

* updated build scripts
* updated waf script
* updated README.md

mcu-common(v1.1.0):

* updated license header
* seperated database entries to prevent concurrent read/write requests to the database
* updated wscripts to build specific files only for primary/secondary
* moved sdram from common repository to primary repository
* renamed database functions to ``DB_WriteBlock()`` and ``DB_ReadBlock()``
* There was a compile error when CAN0 and CAN1 are deactivated
* updated README.md

mcu-freertos(v1.1.0):

* updated license header
* updated wscripts to build specific files only for primary/secondary
* moved sdram from common repository to primary repository
* updated README.md

mcu-hal(v1.0.1):

* updated license header
* updated README.md

mcu-primary(v1.1.0):

* uses now wafs feature of variant builds
* baudrate of CAN0 and CAN1 can now be set independently
* the setup of the tasks in engine and application layer is now consistent
* updated license header
* fixed a bug in contactor module to write unnecessary often into the database which caused a high cpuload
* seperated database entries to prevent concurrent read/write requests to the database
* added support of external SDRAM using keyword ``MEM_EXT_SDRAM``
* moved sdram from common repository to primary repository
* fixed a bug that closed the interlock for a short period of time after restart even if no CAN message was received to switch to STANDBY state
* renamed database functions to ``DB_WriteBlock()`` and ``DB_ReadBlock()``
* updated README.md

mcu-secondary(v1.1.0):

* uses now wafs feature of variant builds
* the setup of the tasks in engine and application layer is now consistent
* updated license header
* seperated database entries to prevent concurrent read/write requests to the database
* renamed database functions to ``DB_WriteBlock()`` and ``DB_ReadBlock()``
* deleted unused code
* updated README.md

tools(v1.0.2):

* Updated waf
* Updated copyright
* Updated the Eclipse Project
* Updated checksum tool from gdb-based to object-copy-based toolchain
* updated README.md

documentation(v1.0.2):

* updated documentation for the build process
* updated FAQ section
* updated copyright
* updated README.md

------------------------------------------------------------------------------

**Release 1.0.1**

* updated build scripts
* updated waf script

------------------------------------------------------------------------------

**Release 1.0.0**

* renamed repository from ``foxBMS-setup`` to ``foxbms-setup``.
* Removed update functionallity
* Moved arm-none-eabi-size call as post function in build process
* added a ``.config.yaml`` file which includes a list of repositories which are
  boostrapped and their bootstrap location.

------------------------------------------------------------------------------

**Release 0.5.2**

Release notes:
We fixed a bug in the ltc driver, leading to a non-functional temperature
sensing for foxBMS Slave Hardware version 1.xx. The slave version is
configuration for the primary MCU in foxBMS-primary\src\module\config\ltc_cfg.h
by the define SLAVE_BOARD_VERSION and for the secondary MCU in
foxBMS-secondary\src\module\config\ltc_cfg.h by the define SLAVE_BOARD_VERSION.

* Set SLAVE_BOARD_VERSION to "1" if you are using version 1.xx of the foxBMS
  Slave.
* Set SLAVE_BOARD_VERSION to "2" if you are using version 2.xx of the foxBMS
  Slave. Version 2.xx is the default configuration.

Changelog:

* foxBMS-primary

  * fixed LTC temperature sensing bug

* foxBMS-secondary

  * fixed LTC temperature sensing bug

------------------------------------------------------------------------------

**Release 0.5.1**

* foxBMS-setup

  * added parameter '-u', '--update' to bootstrap.py for updating the setup
    repository.

* foxBMS-primary

  * updates for waf 1.9.13 support
  * updated module/EEPROM and migrated to module/nvmram
  * minor code adaptations and cleanup

* foxBMS-secondary

  * support for waf 1.9.13
  * minor code adaptations and cleanup

* foxbMS-tools

  * updated waf from version 1.8.12 to version 1.9.13

------------------------------------------------------------------------------

**Release 0.5.0**

A new project structure is now used by foxBMS. The documentation is no more
contained in the embedded software sources and has its own repository. FreeRTOS
and hal have their own repository, too.
A central repository called foxBMS-setup is now used. It contains
several scripts:

* bootstrap.py gets all the repositories needed to work with foxBMS
* build.py is used to compile binaries and to generate the documentation
* clean.py is used to removed the generated binaries and documentation

Release notes:

* New project structure
* Added support for external (SPI) EEPROM on the BMS-Master
* Redesign of can and cansignal module to simplify the usage
* Added support for triggered and cyclic current measurement of Isabellenhütte
  current sensor (IVT)
* Current sensor now functions by default in non-triggered modus (no
  reprogramming needed for the sensor)
* Updated and restructured complete documentation
* Restructured file and folder structure for the documentation
* Added safety and risk analysis section
* Cleaning up of non-used files in the documentation
* Consistency check and correction of the naming and wording used
* Addition of the source files (e.g., Microsoft Visio diagrams) used to
  generate the figures in the documentation
* Reformatted the licenses text formatting (no changes in the licenses
  content)
* Updated the battery junction box (BJB) section with up-to-date components
  and parameters

------------------------------------------------------------------------------

**Release 0.4.4**

The checksum tool is now automatically called when building binaries.
Therefore the command
``python tools/waf-1.8.12 configure build chksum``
is NOT longer supported. The command to build binaries with checksum support is
``python tools/waf-1.8.12 configure build``
This is the build command used in foxBMS FrontDesk, that is, FrontDesk software
is compatible with this change and now supports automatic checksum builds.

Release notes:

* Improved checksum-feature
* Updated copyright 2010 - 2017

------------------------------------------------------------------------------

**Release 0.4.3**

Starting from this version, a checksum mechanism was implemented in foxBMS. If
the checksum is active and it is not computed correctly, it will prevent the
flashed program from running. Details on deactivating the checksum can be found
in the Software FAQ, in How to use and deactivate the checksum.

Release notes:

* Important: Changed contactor configuration order in the software to match
  the labels on the front

  * Contactor 0: CONT_PLUS_MAIN
  * Contactor 1: CONT_PLUS_PRECHARGE
  * Contactor 2: CONT_MINUS_MAIN

* Fixed an bug which could cause an unintended closing of the contactors after
  recovering from error mode
* Increased stack size for the engine tasks to avoid stack overflow in some
  special conditions
* Added a note in the documentation to indicate the necessity to send a
  periodic CAN message to the BMS
* Fixed DLC of CAN message for the current sensor measurement
* Added checksum verification for the flashed binaries
* Updated linker script to allow integration of the checksum tool
* Activated debug without JTAG interface via USB

------------------------------------------------------------------------------

**Release 0.4.2**

Release notes:

* Removed schematic files from documentation, registration needed to obtain
  the files
* Added entries to the software FAQ

------------------------------------------------------------------------------

**Release 0.4.1**

Release notes:

* Corrected daisy chain connector pinout in quickstart guide
* Corrected code for contactors, to allow using contactors without feedback
* Corrected LTC code for reading balancing feedback
* Quickstart restructured, with mention of the necessity to generate the HTML
  documentation

------------------------------------------------------------------------------

**Release 0.4.0**

Beta version of foxBS that was supplied to selected partners for evaluation.

Release notes:

------------------------------------------------------------------------------

**foxBMS Hardware Change Log (deprecated)**

The hardware changelog is now included in the regular changelog (since version
1.5.0).

*foxBMS Master*

+--------+------------------------------------------------------------------------------------------------------+
| V1.0.6 | adapted CAN filter circuit for improved fault tolerance at short of CAN_L to GND or CAN_H to supply  |
+--------+------------------------------------------------------------------------------------------------------+
| V1.0.5 | schematic cleanup, improved fonts and sizes on PCB                                                   |
+--------+------------------------------------------------------------------------------------------------------+
| V1.0.4 | | introduced minor improvements to design                                                            |
|        | | replaced EEPROM with M95M02-DRMN6TP                                                                |
+--------+------------------------------------------------------------------------------------------------------+
| V1.0.3 | | ported schematics and layout to Altium Designer                                                    |
|        | | created hierarchical design                                                                        |
|        | | introduced minor improvements to design                                                            |
+--------+------------------------------------------------------------------------------------------------------+
| V1.0.2 | replaced ADuM14XX isolators by ADuM34XX                                                              |
+--------+------------------------------------------------------------------------------------------------------+
| V1.0.1 | added fuse protection on power supply input                                                          |
+--------+------------------------------------------------------------------------------------------------------+
| V1.0.0 | initial release                                                                                      |
+--------+------------------------------------------------------------------------------------------------------+

*foxBMS Extension*

+--------+------------------------------------------------------------------------------------------------------+
| V1.0.5 | adapted CAN filter circuit for improved fault tolerance at short of CAN_L to GND or CAN_H to supply  |
+--------+------------------------------------------------------------------------------------------------------+
| V1.0.4 | schematic cleanup, improved fonts and sizes on PCB                                                   |
+--------+------------------------------------------------------------------------------------------------------+
| V1.0.3 | | ported schematics and layout to Altium Designer                                                    |
|        | | created hierarchical design                                                                        |
|        | | introduced minor improvements to design                                                            |
+--------+------------------------------------------------------------------------------------------------------+
| V1.0.2 | replaced ADuM14XX isolators by ADuM34XX                                                              |
+--------+------------------------------------------------------------------------------------------------------+
| V1.0.1 | swapped input protection of isolated GPIOs                                                           |
+--------+------------------------------------------------------------------------------------------------------+
| V1.0.0 | initial release                                                                                      |
+--------+------------------------------------------------------------------------------------------------------+

*foxBMS Interface*

+--------+------------------------------------------------------------------------------------------------------+
| V1.9.4 | replaced connectors J500 and J501 with TE 534206-4 due to clearance issues in component placement    |
+--------+------------------------------------------------------------------------------------------------------+
| V1.9.3 | replace NAND-gate with SN74LVC00AQPWRQ1                                                              |
+--------+------------------------------------------------------------------------------------------------------+
| V1.9.2 | replace OR-gate with NAND-gate and add direction pin                                                 |
+--------+------------------------------------------------------------------------------------------------------+
| V1.9.1 | | rotate pinout of Daisy-Chain-Connectors in order to mirror Slave-Connectors                        |
|        | | add labels to Daisy-Chain-Connectors                                                               |
|        | | update with new layermarker                                                                        |
|        | | replace OR-gate with AEC-Q100 qualified COTS                                                       |
+--------+------------------------------------------------------------------------------------------------------+
| V1.9.0 | | update design for reverse isoSPI with second channel                                               |
|        | | port to Altium Designer                                                                            |
+--------+------------------------------------------------------------------------------------------------------+
| V1.1.0 | replaced isoSPI transformer HX1188 by HM2102                                                         |
+--------+------------------------------------------------------------------------------------------------------+
| V1.0.2 | modified connection of isoSPI transformer HX1188                                                     |
+--------+------------------------------------------------------------------------------------------------------+
| V1.0.1 | added fiducials                                                                                      |
+--------+------------------------------------------------------------------------------------------------------+
| V1.0.0 | initial release                                                                                      |
+--------+------------------------------------------------------------------------------------------------------+

*foxBMS Slave 12-cell (LTC6811-1)*

+--------+------------------------------------------------------------------------------------------------------+
| V2.1.7 | | modified component designators to be compatible with 18-cell versions                              |
+--------+------------------------------------------------------------------------------------------------------+
| V2.1.6 | | EMI improvements (layout)                                                                          |
|        | | added RC filters on NTC sensor inputs                                                              |
|        | | added DC/DC converters for 5V LTC supplies                                                         |
+--------+------------------------------------------------------------------------------------------------------+
| V2.1.5 | | Replaced Opamps, Port Expanders and Optocouplers with AEC-Q100 compliant ones                      |
|        | | Modified silkscreen texts                                                                          |
+--------+------------------------------------------------------------------------------------------------------+
| V2.1.4 | | Primary software timer is now switched on by default                                               |
|        | | added layermarker on PCB                                                                           |
+--------+------------------------------------------------------------------------------------------------------+
| V2.1.3 | replaced EOL port expander with PCF8574                                                              |
+--------+------------------------------------------------------------------------------------------------------+
| V2.1.2 | | ported schematics and layout to Altium Designer                                                    |
|        | | created hierarchical design                                                                        |
|        | | introduced minor improvements to design                                                            |
+--------+------------------------------------------------------------------------------------------------------+
| V2.1.1 | improved isolation distances between external DC/DC converter supply and battery module signals      |
+--------+------------------------------------------------------------------------------------------------------+
| V2.1.0 | added DC/DC converter for external power supply                                                      |
+--------+------------------------------------------------------------------------------------------------------+
| V2.0.3 | fixed isoSPI transformer CMC issue                                                                   |
+--------+------------------------------------------------------------------------------------------------------+
| V2.0.2 | | replaced LTC1380 MUXs with ADG728 (400 kHz I2C)                                                    |
|        | | adjusted connection of 100 ohm resistors for V+/V_REG supply                                       |
|        | | reduced value of I2C pullups to 1k2                                                                |
+--------+------------------------------------------------------------------------------------------------------+
| V2.0.1 | | added missing cooling areas on bottom side, adjusted silk screen                                   |
|        | | enlarged PCB tracks, R201/202/301/302 other package                                                |
|        | | enlarged T201/301 cooling area                                                                     |
|        | | Replaced PCF8574 with PCA8574 (400 kHz I2C)                                                        |
+--------+------------------------------------------------------------------------------------------------------+
| V2.0.0 | initial release                                                                                      |
+--------+------------------------------------------------------------------------------------------------------+

*foxBMS Slave 18-cell (LTC6813-1)*

+--------+------------------------------------------------------------------------------------------------------+
| V1.1.5 | | EMI layout improvements                                                                            |
|        | | adapted component variants to other changes                                                        |
+--------+------------------------------------------------------------------------------------------------------+
| V1.1.4 | | replaced DC/DC converter power inductor with AEC-Q compliant one                                   |
|        | | added circuit for switching off DC/DC converters in LTC sleep mode                                 |
|        | | added pull-ups on all GPIOs of the LTCs                                                            |
+--------+------------------------------------------------------------------------------------------------------+
| V1.1.3 | schematic cleanup, improved fonts and sizes on PCB                                                   |
+--------+------------------------------------------------------------------------------------------------------+
| V1.1.2 | | replaced ACPL-247 with ACPL-217 optocoupler in order to be able to use automotive components       |
+--------+------------------------------------------------------------------------------------------------------+
| V1.1.1 | | replaced port expander with TCA6408APWR (automotive)                                               |
|        | | replaced analog buffer opamp with AD8628ARTZ-R2 (automotive)                                       |
|        | | replaced DC/DC buck controller with LM5161QPWPRQ1 (automotive)                                     |
+--------+------------------------------------------------------------------------------------------------------+
| V1.1.0 | | ported schematics and layout to Altium Designer                                                    |
|        | | created hierarchical design                                                                        |
|        | | introduced minor improvements to design                                                            |
|        | | replaced linear regulation (PNP transistor) for LTC power supply with DC/DC converters             |
|        | | improved isolation distances between external DC/DC converter supply and battery module signals    |
|        | | added 8-24 V isolated external power supply                                                        |
|        | | replaced I2C EEPROM 24AA02UID with M24M02-DR (ECC)                                                 |
|        | | replaced isoSPI transformers HX1188NL with HM2102NL                                                |
|        | | reduced balancing resistors from 2x 68 Ohm to 2x 130 Ohm due to shrinked cooling areas             |
|        | | added layermarker on PCB                                                                           |
|        | | Primary discharge timer is now switched on by default                                              |
+--------+------------------------------------------------------------------------------------------------------+
| V1.0.1 | replaced all LTC1380 MUXs with ADG728 MUXs                                                           |
+--------+------------------------------------------------------------------------------------------------------+
| V1.0.0 | initial release                                                                                      |
+--------+------------------------------------------------------------------------------------------------------+

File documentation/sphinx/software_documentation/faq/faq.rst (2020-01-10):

.. include:: ../../macros.rst

.. _SOFTWARE_DOCUMENTATION_FAQ:

=======================
Software FAQ and HOWTOs
=======================

.. highlight:: C

This sections shows different kind of actions related to the software.

.. contents::
    :local:

.. _faq_current_sensor:

How to start |foxBMS| if no messages are sent by CAN?
-----------------------------------------------------

If no current sensor is connected to |foxBMS|, it will not start. This default behavior can be changed by setting the switch

.. code-block:: C

    #define CURRENT_SENSOR_PRESENT               TRUE

to ``FALSE`` as explaned in :ref:`software_documentation_defines`.

How to create a task and change its priority and period?
--------------------------------------------------------

First, declare a new task configuration in the ``appltask_cfg.h`` file:

.. code-block:: C

    /**
    * Task configuration of the 10ms application task
    */
    extern BMS_Task_Definition_s appl_tskdef_10ms;

The task configuration is a struct of type ``BMS_Task_Definition_s`` and defined as follows:

.. code-block:: C

    /**
    * struct for FreeRTOS task definition
    */
    typedef struct {
        uint32_t Phase;          /*!< (ms)                                 */
        uint32_t CycleTime;      /*!< (ms)                                 */
        OS_PRIORITY_e Priority;  /*!<                                      */
        uint32_t Stacksize;      /*!<  Defines the size, in words, of the
                                       stack allocated to the idle task.   */
    } BMS_Task_Definition_s;

- Phase:     phase offset of the task in ms
- CycleTime: cycle time of the task in ms
- Stacksize: stack size allocated to the task
- Priority: task priority for scheduling

The task priorities are defined by CMSIS and consist of seven priorities:

.. code-block:: C

    typedef enum  {
      osPriorityIdle          = -3,          // /< priority: idle (lowest)
      osPriorityLow           = -2,          // /< priority: low
      osPriorityBelowNormal   = -1,          // /< priority: below normal
      osPriorityNormal        =  0,          // /< priority: normal (default)
      osPriorityAboveNormal   = +1,          // /< priority: above normal
      osPriorityHigh          = +2,          // /< priority: high
      osPriorityRealtime      = +3,          // /< priority: realtime (highest)
      osPriorityError         =  0x84        // /< system cannot determine priority
                                             //    or thread has illegal priority
    } osPriority;

The priorities ``osPriorityRealtime``, ``osPriorityHigh``, ``osPriorityAboveNormal`` and ``osPriorityNormal`` are already used by the |foxbms| engine and therefore should not be used. In conlusion the priorities ``osPriorityBelowNormal`` and ``osPriorityLow`` shall be used.

Second, add the task configuration in the ``appltask_cfg.c`` file:

.. code-block:: C

    /**
     * predefined 10ms task for user code
     */
    BMS_Task_Definition_s appl_tskdef_10ms = { 0,   10, osPriorityBelowNormal, 512/4 };

Third, declare a task handle and a task function in the ``appltask.c/h`` file:

.. code-block:: C

    /**
     *  Definition of task handle 10ms task
     */
    xTaskHandle appl_handle_tsk_10ms;

   /**
     * @brief   10ms engine application task
     */
    extern void APPL_TSK_Cyclic_100ms(void);

The task initialization and creation is done in the function
``APPL_CreateTask()`` in the ``appltask.c`` file. Before assigning the task
handle to the newly created task, a new thread needs to be defined for the
operating system. This is done by a call of the function
``osThreadDef(name, thread, priority, instances, stacksz)``. The function parameters are:

  - name: name of the function that represents the task
  - thread: os_pthread-pointer to the function that represents the task
  - priority: initial priority of the thread function
  - instances: number of possible thread instances (0 -> only one instance)
  - stacksize

The task handle is now, with a call of ``osThreadCreate``, assigned to the task.

.. code-block:: C

    // Cyclic Task 10ms
    osThreadDef(APPL_TSK_Cyclic_10ms, (os_pthread )APPL_TSK_Cyclic_10ms,
            appl_tskdef_10ms.Priority, 0, appl_tskdef_10ms.Stacksize);
    appl_handle_tsk_10ms = osThreadCreate(osThread(APPL_TSK_Cyclic_10ms), NULL);

The implementation of the task should be done like shown in the following example:

.. code-block:: C

    void APPL_TSK_Cyclic_10ms(void) {
        while (os_boot != OS_SYSTEM_RUNNING)
        {
            ;
        }

        osDelayUntil(os_schedulerstarttime, appl_tskdef_10ms.Phase);

        while(1)
       {
            uint32_t currentTime = osKernelSysTick();

            APPL_Cyclic_10ms();

            osDelayUntil(currentTime, appl_tskdef_10ms.CycleTime);
        }
    }

.. note::

    - Every task should have the while loop ``while(os_boot != OS_SYSTEM_RUNNING)`` at the beginning of the funtion. This prevents the task from being executed before |foxbms| is completely initialized.
    - ``osDelayUntil(os_schedulerstarttime, appl_tskdef_10ms.Phase)`` sets the wished phase offset of the task
    - Tasks in FreeRTOS should never finish. Therefore, the actual task implementation is done in a ``while(1)``-loop
    - ``APPL_TSK_Cyclic_10ms`` serves as wrapper function for task implementation in ``APPL_Cyclic_10ms()``
    - The call of ``osDelayUntil(currentTime, appl_tskdef_10ms.CycleTime)`` sets the task in blocked state until the cycle time until the next period arrives
    - Every task should be secured by the system monitoring module (``DIAG_SysMonNotify()``)
    - |foxbms| provides two default tasks for user applications with a periods of 10ms and 100ms

    .. code-block:: C

        void APPL_Cyclic_10ms(void) {
            DIAG_SysMonNotify(DIAG_SYSMON_APPL_CYCLIC_10ms, 0);        // task is running, state = ok

            /* User specific implementations:   */
            /*   ...                            */
            /*   ...                            */
        }

How to add a software module and take it into account with WAF?
---------------------------------------------------------------

The steps to follow are:

 - Creation of a new subfolder (for example ``mymodule``) in one of the existing source folders ``application``, ``engine``, ``general``, ``module``, ``module/utils``)
 - Copy of all source files to the newly created subfolder
 - Modification of the wscript file located in the chosen existing source folder, to add the new module. For example, to add a software module in the ``application`` folder, in the ``includes`` section of the wscript, the following new line has to be added:

.. code-block:: python

    os.path.join(bld.srcnode.abspath(), 'src', 'application', 'mymodule'),

In case the new software module has to be used in another existing module, the same line has to be added in the wscript file corresponding to the existing module where it is imported.

How to change the multiplexer measurement sequence for the LTC driver?
----------------------------------------------------------------------

The sequence is defined in ``module\config\ltc_cfg.c``, via the array ``LTC_MUX_CH_CFG_t ltc_mux_seq_main_ch1[]``, which contains a concatenation of elements like:

.. code-block:: C

   {
       .muxID    = 1,
       .muxCh    = 0xFF,
   },
   {
      .muxID    = 2,
      .muxCh    = 0,
   },
   {
      .muxID    = 2,
      .muxCh    = 1,
   },

There are 4 multiplexers with IDs from 0 to 3 on the |slaves|. The multiplexer is chosen with the variable ``muxID``. Each multiplexer has 8 channels, chosen with the variable ``muxCh`` (between 0 and 7). Channel 0xFF means that the multiplexer is disabled (i.e., high-impedance mode: none of the 8 inputs is connected to the output). With the code sequence shown above, multiplexer is first disabled, then channel 0 of multiplexer 2 is read, then channel 1 of multiplexer 2 is read.

Typically, multiplexer 0 and 1 are used for temperature measurement, and multiplexer 2 and 3 are used for balancing feedback (i.e., monitor if a cell is being balanced or not). As a consequence, by default, measurements of multiplexer 0 and 1 are stored in a database structure of type ``DATA_BLOCK_CELLTEMPERATURE_s`` and measurement of multiplexer 2 and 3 are stored in a database structure of type ``DATA_BLOCK_BALANCING_FEEDBACK_s``.

For temperature measurements, the variable ``uint8_t ltc_muxsensortemperatur_cfg[6]`` contains the look-up table between temperature sensors and cells: the first entry defines the temperature sensor number assigned to the first cell, the second entry defines the temperature sensor number assigned to the second cell, and so on. If no look-up table is needed, this array should simply be filled with integers increasing from 0 to number of temperature sensors minus 1. In this example, ``muxsensortemperaturmain_cfg[6]`` has a size of 6 because it is the default number of temperature sensors supported by the |slaves|. This must be adapted at two places:

 - In ``module\config\ltc_cfg.c``, where the variable is defined
 - In ``module\config\ltc_cfg.h``, in the declaration ``extern uint8_t ltc_muxsensortemperatur_cfg[6]``

.. _sw_faq_temperature_sensors:

How to change the relation between voltages read by multiplexer via |LTC| and temperatures?
-------------------------------------------------------------------------------------------

The function ``float LTC_Convert_MuxVoltages_to_Temperatures(float v_adc)`` is defined in ``ltc_cfg.c``. It gets a voltage in V as input and returns a temperature. It can simply be changed to meet the application needs.

To get the function converting the measured voltage to temperature, the following procedure can be followed if a Negative Temperature Coefficient resistor (NTC) is used :

 #. Create a spreadsheet (e.g., in Microsoft Excel)
 #. In the datasheet of the NTC, take the table giving the resistance versus the temperature
 #. In the spreadsheet, define three columns:

    - Temperature value (read from the NTC datasheet)
    - Corresponding resistance value (read from the NTC datasheet)
    - Voltage value provided by the voltage divider calculated with the NTC
      resistance for each temperature value. On the latest |slave|, the voltage divider
      is formed by a 10kOhm resistor in series with the NTC, with a 3V power supply,
      as shown in :ref:`slave_voltage_divider`
    - Different slave versions may have different voltage dividers. Have a look a
      the :ref:`hw_slave` documentation to select correct voltage divider for your slave.

 #. Plot the temperature versus the corresponding measured voltage value (i.e., first column versus third column in the spreadsheet)
 #. Fit a polynomial function to the plotted curve (e.g., by using Microsoft Excel)
 #. Implement the polynom in ``float LTC_Convert_MuxVoltages_to_Temperatures(float Vout)``

The function ``float LTC_Convert_MuxVoltages_to_Temperatures(float Vout)`` gets a voltage as input and outputs the corresponding temperature.

How to configure the MCU clock?
-------------------------------

The configuration is defined in ``module/config/rcc_cfg.c`` via two structures:

.. code-block:: C

   RCC_OscInitTypeDef RCC_OscInitStruct = {
       .OscillatorType = RCC_OSCILLATORTYPE_HSE,
       .HSEState = RCC_HSE_ON,
       .PLL.PLLState = RCC_PLL_ON,
       .PLL.PLLSource = RCC_PLLSOURCE_HSE,
       .PLL.PLLM = RCC_PLL_M,    // Oscillator Clock: 8MHz -> (8Mhz / 8) * 336 / 2 -> 168MHz
       .PLL.PLLN = RCC_PLL_N,
       .PLL.PLLP = RCC_PLL_P,
       .PLL.PLLQ = RCC_PLL_Q     // Oscillator Clock: 8MHz -> (8Mhz / 8) * 336 / 7   -> 48MHz
   };

   RCC_ClkInitTypeDef RCC_ClkInitStruct = {
       .ClockType = RCC_CLOCKTYPE_SYSCLK|RCC_CLOCKTYPE_HCLK|RCC_CLOCKTYPE_PCLK1|RCC_CLOCKTYPE_PCLK2,
       .SYSCLKSource = RCC_SYSCLKSOURCE_PLLCLK,    // System Clock Source: PLL-Clock
                                                   // (Cortex-Core, AHB-Bus, DMA, memory)
       .AHBCLKDivider = RCC_AHBCLKDivider,         // Div=1 , AHB  CLOCK: 168MHz
       .APB1CLKDivider = RCC_APB1CLKDivider,       // Div=4 , APB1 CLOCK:  42MHz
       .APB2CLKDivider = RCC_APB2CLKDivider        // Div=2 , APB2 CLOCK:  84MHz
   };

:numref:`Fig. %s <systemclocks>` shows a summary of the system clocks, with the variables defined via the structures and their effect (either as divider or multiplier).

.. _systemclocks:


   Clock system of the microcontroller used in |foxbms|

On the |BMS-Master|, a 8MHz oscillator is used as clock source. It should be noted that some of the multipliers/dividers can take all integers values in a certain range, while others can only take a specific set of values. The values must be defined so that the clock values are within the allowed ranges. These are defined in the microcontroller datasheet.

How to configure the |LTC| and SPI clocks?
------------------------------------------

In ``module/config/ltc_cfg.h``, the macro ``#define SPI_HANDLE_LTC &spi_devices[0]`` is defined. It points to a SPI handle: this SPI device will be used for the communication with the |LTC|. SPI handles are defined in ``module/config/spi_cfg.c``. Depending on the SPI device chosen, the clock used will be peripheral clock 1 or 2 (this information is found in the STM32F4 datasheet). The clock used by the SPI device is obtained after division of the peripheral clock frequency. In the SPI handle, the value for the divider is defined via ``.Init.BaudRatePrescaler = SPI_BAUDRATEPRESCALER_128``. In the |LTC| driver, the SPI frequency is read directly via a HAL function and all timings are adapted automatically. The user must only ensure that the SPI frequency used for the |LTC| is not higher than 1MHz. This is the maximal frequency allowed for the |LTC| communication (as defined in the |LTC| datasheet).

How to configure the CAN clock?
-------------------------------

If the APB1 (Peripheral) clock changes, the CAN timing has to be adapted according to the following formula:

.. math::

   \text{clock}_\text{CAN} = \frac{\text{APB1}}{(\text{prescaler} + \text{timequantums})}

   \text{timequantums} = 1 + \text{timequantumsBS1} + \text{timequantumsBS2}

The timequantums (TQ) are constrained to specific discrete values by the STM32 microcontroller.

**Sample Configurations**

=============  ============   ============== =========== ===========
CAN clock      APB1           Prescaler      BS1         BS2
-------------  ------------   -------------- ----------- -----------
1.0 MHz        42 MHz         3              6 TQ        7 TQ
1.0 MHz        32 MHz         4              5 TQ        2 TQ
0.5 MHz        42 MHz         6              6 TQ        7 TQ
0.5 MHz        32 MHz         8              5 TQ        2 TQ
=============  ============   ============== =========== ===========

**Example:**

change the relevant low level driver handle in file /modules/config/can_cfg.c

``CAN_HandleTypeDef hcan1`` or ``CAN_HandleTypeDef hcan2``

.. code-block:: C

   .Init.Prescaler = 3,        // CAN_CLOCK = APB1 = 42 MHz
                               // resulting CAN speed: APB1/prescaler/sumOfTimequants
                               // sum: 1tq for sync + BS1 + BS2
   .Init.BS1 = CAN_BS1_6TQ,    // --> CAN = 42 MHz/(3*14) = 1.0 MHz
   .Init.BS2 = CAN_BS2_7TQ,

.. math::

   \text{timequantums} = 1 + 6 + 7 = 14

   \text{clock}_{CAN} = \frac{42.0\text{\MHz}}{(3 \cdot  14)} = 1.0 \text{\MHz}

Further details can be found in STM32F4 datasheet.

How to configure and drive I/O ports?
-------------------------------------

The pin configuration of the hardware is is defined in ``const IO_PIN_CFG_s io_cfg[]`` in the file ``module/config/io_cfg.c`` with entries like:

.. code-block:: C

   {PIN_MCU_0_BMS_INTERFACE_SPI_MISO, IO_MODE_AF_PP, IO_PIN_NOPULL,
    IO_SPEED_HIGH, IO_ALTERNATE_AF5_SPI1, IO_PIN_LOCK_ENABLE}

The parameters are:

 - Pin: Defines the pin name (defined in ``module/config/io_mcu0_cfg.h``).
 - Mode: The possibilities of the mode are defined in ``module/config io_cfg.c`` via the enum type ``IO_PIN_MODES_e``. Often used modes are ``IO_MODE_AF_PP`` for use of one alternate function of the pin, ``IO_MODE_INPUT`` to use the pin as an input, ``IO_MODE_OUTPUT_PP`` to use the pin as an output with push-pull functionality.
 - Pinpull: Defines wether the pin is used without pull-up or pull-down (``IO_PIN_NOPULL``), to use the pin with pull-up (``IO_PIN_PULLUP``) or to use the pin with pull-down (``IO_PIN_PULLDOWN``).
 - Speed: Defines the speed of the pin (``IO_SPEED_LOW``, ``IO_SPEED_MEDIUM``, ``IO_SPEED_FAST`` or ``IO_SPEED_HIGH``).
 - Alternate: Defines if the signal/pin uses an alternate function or not. If no alternate function is used this is set to ``IO_ALTERNATE_NO_ALTERNATE``. If the signal/pin uses a alternate function one can choose from the possibilities from the enumeration ``IO_PIN_ALTERNATE_e`` in ``module/config/io_cfg.h``.
 - Pinlock: ``IO_PIN_LOCK_DISABLE`` or ``IO_PIN_LOCK_ENABLE`` to disable or enable pin locking.
 - Initvalue: Sets the initial state of the pin in case of an output pin; The pin is set to ``IO_PIN_RESET`` for 0/low and to ``IO_PIN_SET`` for 1/high. If no value is given for a output pin it is set to low.

As explained above, the signal names are to be defined in ``module/config/io_mcu0_cfg.h`` with macros like:

.. code-block:: C

   #define PIN_MCU_0_BMS_INTERFACE_SPI_MISO IO_PA_6

where ``IO_Px_y`` corresponds to the physical pin on the MCU, with ``x`` the port (e.g., A,B,C) and ``y`` the pin number on the port (e.g., 0,1,2).

This configuration is initialized in ``main.c`` with the function call ``IO_Init(&io_cfg[0])``.

Pins configured as output are driven with the function with ``IO_PIN_RESET`` or ``IO_PIN_SET`` to set the pin to low or high. Example (The signal/pin name corresponds to the one defined in ``module/config/io_mcu0_cfg.h``).:

.. code-block:: C

   IO_WritePin(PIN_MCU_0_BMS_INTERFACE_SPI_MISO, IO_PIN_RESET);     // set pin low
   IO_WritePin(PIN_MCU_0_TO_MCU_1_INTERFACE_SPI_MISO, IO_PIN_SET);  // set pin high

The states of pins configured as input are read with the ``IO_ReadPin(<Signalname>)`` function. The function returns ``IO_PIN_RESET`` or ``IO_PIN_SET`` (0 or 1). Example with the signal/pin name corresponding to the one defined in ``module/config/io_mcu0_cfg.h``:

.. code-block:: C

   IO_PIN_STATE_e pinstate = IO_PIN_RESET;
   pinstate = IO_ReadPin(PIN_MCU_0_BMS_INTERFACE_SPI_NSS);

How to add and configure interrupts?
------------------------------------

The interrupt configuration can be found in ``general/config/nvic_cfg.c`` via the variable ``NVIC_InitStruct_s nvic_interrupts[]``, which contains entries of the form:
``{ DMA2_Stream2_IRQn, 2, NVIC_IRQ_LOCK_ENABLE, NVIC_IRQ_ENABLE }``

The configuration parameters are:

 - Symbolic name of interrupt source (as defined in the system file stm32f429xx.h)
 - Interrupt priority: number between 0 and 15, a lower number means a higher priority
 - Parameter irqlock: if set to ``NVIC_IRQ_LOCK_ENABLE``, the interrupt is locked according to the initial state and cannot be modified by the interface functions ``NVIC_EnableInterrupts()`` or ``NVIC_DisableInterrupts()``
 - Initial state of interrupt source: set to ``NVIC_IRQ_ENABLE`` to get the interrupt enabled by the initialization function. In case of ``NVIC_IRQ_DISABLE``, the interrupt must be activated by calling ``NVIC_EnableInterrupts()`` after the initialization

In ``general/config/stm32f4xx_it.c``, a corresponding callback function must be defined (for example ``void DMA2_Stream2_IRQHandler(void)`` for DMA stream 2 of DMA device 2). It will be called when the interrupt is triggered.

For a proper operation, the interrupt handling (callback function) has to execute the following steps:

 - Clear the pending interrupt with for example ``HAL_NVIC_ClearPendingIRQ(DMA2_Stream2_IRQn)``
 - Call the HAL IRQ handler (or a custom handler) with for example: ``HAL_DMA_IRQHandler(&dma_devices[0])``

.. note::

   Interrupt routines with interrupt priority above the maximum FreeRTOS configuration level (``configLIBRARY_MAX_SYSCALL_INTERRUPT_PRIORITY``) must not call FreeRTOS API functions. These interrupts are real-time interrupts, which are bypassing the operating system. Interrupt routines with interrupt priority equal or lower than this maximum level must call the corresponding FreeRTOS API functions with ending ``...._FROM_ISR()``.

Check the documentation (datasheet, reference manual) of the interrupt source for additional steps.

.. _database_entry:

How to add a database entry and to read/write it?
-------------------------------------------------

The example of the entry for cell voltages is taken. In
``engine\config\database_cfg.h``, the definition of a block must be added
``#define DATA_BLOCK_ID_CELLVOLTAGE DATA_BLOCK_1`` with one available block.
The blocks are defined via the following enumeration:

.. code-block:: C

   typedef enum {
       DATA_BLOCK00        = 0,
       DATA_BLOCK01        = 1,
       DATA_BLOCK02        = 2,
       DATA_BLOCK03        = 3,
       DATA_BLOCK04        = 4,
       DATA_BLOCK05        = 5,
       DATA_BLOCK06        = 6,
       DATA_BLOCK07        = 7,
       DATA_BLOCK08        = 8,
       DATA_BLOCK09        = 9,
       DATA_BLOCK10        = 10,
       DATA_BLOCK_MAX      = DATA_MAX_BLOCK_NR,
   } DATA_BLOCK_ID_TYPE_e;

If more than ``DATA_BLOCK_MAX`` blocks are needed, it must be changed in the
defines:

.. code-block:: C

   #define DATA_MAX_BLOCK_NR                11

A structure must then be declared for the block ID created:

.. code-block:: C

   /*  data structure declaration of DATA_BLOCK_ID_CELLVOLTAGE */
   typedef struct {
    /* Timestamp info needs to be at the beginning. Automatically written on DB_WriteBlock      */
       uint32_t timestamp;                       /*!< timestamp of database entry               */
       uint32_t previous_timestamp;              /*!< timestamp of last database entry          */
       /* data block entries                                                                    */
       uint16_t      voltage[NR_OF_BAT_CELLS];   //unit: mV
       uint8_t       state;
   } DATA_BLOCK_CELLVOLTAGE_s;

This structure needs to contain a variable timestamp and previous_timestamp at the
beginning of the struct. These timestamp are automatically updated each time new
values are stored in the database. The reamaing struct consists of all the data
needed for the entry. In ``mcu-primary\engine\config\database_cfg.c``, a variable with the
structure type must be declared

.. code-block:: C

    DATA_BLOCK_CELLVOLTAGE_s data_block_cellvoltage[DOUBLE_BUFFERING];

The user can choose ``SINGLE_BUFFERING`` or ``DOUBLE_BUFFERING``. The last
step is to add an entry in the structure
``DATA_BASE_HEADER_s data_base_header[]``:

.. code-block:: C

   {
   (void*)(&data_block_cellvoltage[0]),
   sizeof(DATA_BLOCK_CELLVOLTAGE_s),
   DOUBLE_BUFFERING,
   },

With either ``SINGLE_BUFFERING`` or ``DOUBLE_BUFFERING`` (the same as in the structure declaration).
When access to the created database entry is needed, a local variable with the corresponding type must be created in the module where it is needed:
``DATA_BLOCK_CELLVOLTAGE_s cellvoltage;``

Access to a data field is made with the usual C-syntax:

.. code-block:: C

   cellvoltage.voltage[i]

Getting the data from the database in the local variable is made via:

.. code-block:: C

   DB_ReadBlock(&cellvoltage ,DATA_BLOCK_ID_CELLVOLTAGE)

Storing data from the local variable to the database is made via:

.. code-block:: C

   DB_WriteBlock(&cellvoltage, DATA_BLOCK_ID_CELLVOLTAGE)

During each call of ``DB_WriteBlock()`` the timestamps will automatically be
updated.

How to store data in the backup SRAM of the MCU?
------------------------------------------------

The STM32F4 has 4kB Backup SRAM. Variables can be stored there with the keywork ``MEM_BKP_SRAM`` which is defined in ``src/general/config/global.h``.

Example:

.. code-block:: C

   #define DIAG_FAIL_ENTRY_LENGTH (50)
   DIAG_ERROR_ENTRY_s MEM_BKP_SRAM diag_memory[DIAG_FAIL_ENTRY_LENGTH];

.. _faq_can_manually_add:

How to manually add CAN entries (transmit and receive) and to change the transmit time period?
----------------------------------------------------------------------------------------------

Several steps have to be done to add a transmit message and signal (message and signal in receive direction in parentheses):

File: ``module/config/cansignal_cfg.h``

1. The message name must be added. For TX, i.e., transmit data, a message entry must be added in the enumeration ``CANS_messagesTx_e``: (RX, i.e., receive, ``CANS_messagesRx_e``)

2. Then one or more signal names must be added in the enumeration ``CANS_CANx_signalsTx_e`` (``CANS_CANx_signalsRx_e``)

File: ``module/config/can_cfg.c``

3. The CAN message must be defined

3.1. In case a TX message should be defined - add the message for CAN0 or CAN1 in the respective array (const CAN_MSG_TX_TYPE_s can_CANx_messages_tx). The message looks
like ``{ 0x123, 8, 100, 20, NULL_PTR }``

   The parameters are:

   - Message ID (11bit standard identifier used in |foxbms|)
   - Data Length Code (i.e., number of bytes), usually 8
   - Transmit period in ms: must be multiple of ``CANS_TICK_MS``
   - Delay in ms for sending the message the first time: must be multiple of ``CANS_TICK_MS``
   - A function pointer to be called after transmission, ``NULL_PTR`` if nothing needs to be done

3.2 If a RX message needs to be configured, the message for CAN0 or CAN1 must be added in the respective array (CAN_MSG_RX_TYPE_s can0_RxMsgs[]). The message looks like ``{ 0x123, 0xFFFF, 8, 0, CAN_FIFO0, NULL }``

    The parameters are:

    - Message ID (11bit standard identifier used in |foxbms|)
    - Mask for the CAN hardware filter (Select mask or use 0x0000 to select list mode)
    - Data Length Code (i.e., number of bytes), usually 8
    - Hardware receive FIFO (CAN_FIFO0 or CAN_FIFO1)
    - function pointer to be called after reception, usually NULL_PTR to do nothing because signals with respective function pointers are used

File: ``module/config/cansignal_cfg.c``

4. Then the signals added in the header must be added in the .c file and in ``const CANS_signal_s cans_CANx_signals_tx[]`` (``const CANS_signal_s cans_CANx_signals_rx[NR_SIGNALS_RX]``).

  A signal looks like:

  .. code-block:: C

    {CANS_MSG_Name}, 0, 8, 0, 255, 1, 0, NULL_PTR, &cans_getsignaldata

  The parameters are:

   - Symbolic name of the message containing the signal (defined in ``CANS_messagesTx_e``, in the header file)
   - Start bit of signal
   - Signal length in bits
   - Minimum value (float)
   - Maximum value (float)
   - Scaling factor (float)
   - Scaling offset (float)
   - Callback function for setter (when CAN msg is received) (``NULL_PTR`` if no function needed, e.g., for transmit)
   - Callback function gor getter (when CAN msg is transmitted) (``NULL_PTR`` if no function needed, e.g., for receive only)

5. The callback functions must be declared and implemented in ``cansignal_cfg.c``.

.. _faq_can_lessthan18cells:

How to adapt the CAN module when less than 18 battery cells or 12 temperature sensors per module are used?
----------------------------------------------------------------------------------------------------------

Five adaptions are necessary when removing unused battery cell voltages or temperatures This procedure is executed exemplarily
for 9 cell voltages and 5 temperature sensors:

1. Adapt struct ``const CAN_MSG_TX_TYPE_s can_CAN0_messages_tx[]`` in file ``module/config/can_cfg.c``:

.. code-block:: C

    { 0x200, 8, 200, 20, NULL_PTR },  //!< Cell voltages module 0 cells 0 1 2
    { 0x201, 8, 200, 20, NULL_PTR },  //!< Cell voltages module 0 cells 3 4 5
    { 0x202, 8, 200, 20, NULL_PTR },  //!< Cell voltages module 0 cells 6 7 8
    { 0x203, 8, 200, 20, NULL_PTR },  //!< Cell voltages module 0 cells 9 10 11
    { 0x204, 8, 200, 20, NULL_PTR },  //!< Cell voltages module 0 cells 12 13 14
    { 0x205, 8, 200, 20, NULL_PTR },  //!< Cell voltages module 0 cells 15 16 17

    { 0x210, 8, 200, 30, NULL_PTR },  //!< Cell temperatures module 0 cells 0 1 2
    { 0x211, 8, 200, 30, NULL_PTR },  //!< Cell temperatures module 0 cells 3 4 5
    { 0x212, 8, 200, 30, NULL_PTR },  //!< Cell temperatures module 0 cells 6 7 8
    { 0x213, 8, 200, 30, NULL_PTR },  //!< Cell temperatures module 0 cells 9 10 11

Remove all unused CAN message depending on the number of used cells/sensors. In the example case remove cell voltage message 0x203
because we transmit only cell voltages 0-8. Additionally remove cell temperature message 0x212 and 0x213 because we only use
temperatures 0-4. Repeat this process for all modules.

2. Adapt enum ``CANS_messagesTx_e`` in file ``module/config/cansignal_cfg.h``:

.. code-block:: C

    CAN0_MSG_Mod0_Cellvolt_0,  //!< Module 0 Cell voltages 0-2
    CAN0_MSG_Mod0_Cellvolt_1,  //!< Module 0 Cell voltages 3-5
    CAN0_MSG_Mod0_Cellvolt_2,  //!< Module 0 Cell voltages 6-8
    CAN0_MSG_Mod0_Cellvolt_3,  //!< Module 0 Cell voltages 9-11
    CAN0_MSG_Mod0_Cellvolt_4,  //!< Module 0 Cell voltages 12-14
    CAN0_MSG_Mod0_Cellvolt_5,  //!< Module 0 Cell voltages 15-17

    CAN0_MSG_Mod0_Celltemp_0,  //!< Module 0 Cell temperatures 0-2
    CAN0_MSG_Mod0_Celltemp_1,  //!< Module 0 Cell temperatures 3-5
    CAN0_MSG_Mod0_Celltemp_2,  //!< Module 0 Cell temperatures 6-8
    CAN0_MSG_Mod0_Celltemp_3,  //!< Module 0 Cell temperatures 9-11

Remove all unused enmus depending on the number of used cells/sensors. In the example case remove enum ``CAN0_MSG_Mod0_Cellvolt_3``
because we transmit only cell voltages 0-8. Additionally remove cell temperature enum ``CAN0_MSG_Mod0_Celltemp_2`` and
``CAN0_MSG_Mod0_Celltemp_3`` because we only use temperatures 0-4. Repeat this process for all modules.

3. Adapt enum ``CANS_CAN0_signalsTx_e`` in file ``module/config/cansignal_cfg.h``:

.. code-block:: C

    CAN0_SIG_Mod0_volt_valid_0_2,
    CAN0_SIG_Mod0_volt_0,
    CAN0_SIG_Mod0_volt_1,
    CAN0_SIG_Mod0_volt_2,
    CAN0_SIG_Mod0_volt_valid_3_5,
    CAN0_SIG_Mod0_volt_3,
    CAN0_SIG_Mod0_volt_4,
    CAN0_SIG_Mod0_volt_5,
    CAN0_SIG_Mod0_volt_valid_6_8,
    CAN0_SIG_Mod0_volt_6,
    CAN0_SIG_Mod0_volt_7,
    CAN0_SIG_Mod0_volt_8,
    CAN0_SIG_Mod0_volt_valid_9_11,
    CAN0_SIG_Mod0_volt_9,
    CAN0_SIG_Mod0_volt_10,
    CAN0_SIG_Mod0_volt_11,
    CAN0_SIG_Mod0_volt_valid_12_14,
    CAN0_SIG_Mod0_volt_12,
    CAN0_SIG_Mod0_volt_13,
    CAN0_SIG_Mod0_volt_14,
    CAN0_SIG_Mod0_volt_valid_15_17,
    CAN0_SIG_Mod0_volt_15,
    CAN0_SIG_Mod0_volt_16,
    CAN0_SIG_Mod0_volt_17,

    CAN0_SIG_Mod0_temp_valid_0_2,
    CAN0_SIG_Mod0_temp_0,
    CAN0_SIG_Mod0_temp_1,
    CAN0_SIG_Mod0_temp_2,
    CAN0_SIG_Mod0_temp_valid_3_5,
    CAN0_SIG_Mod0_temp_3,
    CAN0_SIG_Mod0_temp_4,
    CAN0_SIG_Mod0_temp_5,
    CAN0_SIG_Mod0_temp_valid_6_8,
    CAN0_SIG_Mod0_temp_6,
    CAN0_SIG_Mod0_temp_7,
    CAN0_SIG_Mod0_temp_8,
    CAN0_SIG_Mod0_temp_valid_9_11,
    CAN0_SIG_Mod0_temp_9,
    CAN0_SIG_Mod0_temp_10,
    CAN0_SIG_Mod0_temp_11,

Remove all unused enmus depending on the number of used cells/sensors. In the example case remove enums ``CAN0_SIG_Mod0_volt_valid_9_11``
to ``CAN0_SIG_Mod0_volt_11`` because we transmit only cell voltages 0-8. Additionally remove cell temperature enums ``CAN0_SIG_Mod0_temp_5``
to CAN0_SIG_Mod0_temp_11 because we only use temperatures 0-4. Repeat this process for all modules.

4. Adapt struct ``const CANS_signal_s cans_CAN0_signals_tx[]`` in file ``module/config/cansignal_cfg.c``:

.. code-block:: C

    /* Module 0 cell voltages */
    { {CAN0_MSG_Mod0_Cellvolt_0}, 0, 8, 0, UINT8_MAX, 1, 0, NULL_PTR, &cans_getvolt },  /*!< CAN0_SIG_Mod0_volt_valid_0_2 */
    { {CAN0_MSG_Mod0_Cellvolt_0}, 8, 16, 0, UINT16_MAX, 1, 0, NULL_PTR, &cans_getvolt },  /*!< CAN0_SIG_Mod0_volt_0 */
    { {CAN0_MSG_Mod0_Cellvolt_0}, 24, 16, 0, UINT16_MAX, 1, 0, NULL_PTR, &cans_getvolt },  /*!< CAN0_SIG_Mod0_volt_1 */
    { {CAN0_MSG_Mod0_Cellvolt_0}, 40, 16, 0, UINT16_MAX, 1, 0, NULL_PTR, &cans_getvolt },  /*!< CAN0_SIG_Mod0_volt_2 */
    { {CAN0_MSG_Mod0_Cellvolt_1}, 0, 8, 0, UINT8_MAX, 1, 0, NULL_PTR, &cans_getvolt },  /*!< CAN0_SIG_Mod0_volt_valid_3_5 */
    { {CAN0_MSG_Mod0_Cellvolt_1}, 8, 16, 0, UINT16_MAX, 1, 0, NULL_PTR, &cans_getvolt },  /*!< CAN0_SIG_Mod0_volt_3 */
    { {CAN0_MSG_Mod0_Cellvolt_1}, 24, 16, 0, UINT16_MAX, 1, 0, NULL_PTR, &cans_getvolt },  /*!< CAN0_SIG_Mod0_volt_4 */
    { {CAN0_MSG_Mod0_Cellvolt_1}, 40, 16, 0, UINT16_MAX, 1, 0, NULL_PTR, &cans_getvolt },  /*!< CAN0_SIG_Mod0_volt_5 */
    { {CAN0_MSG_Mod0_Cellvolt_2}, 0, 8, 0, UINT8_MAX, 1, 0, NULL_PTR, &cans_getvolt },  /*!< CAN0_SIG_Mod0_volt_valid_6_8 */
    { {CAN0_MSG_Mod0_Cellvolt_2}, 8, 16, 0, UINT16_MAX, 1, 0, NULL_PTR, &cans_getvolt },  /*!< CAN0_SIG_Mod0_volt_6 */
    { {CAN0_MSG_Mod0_Cellvolt_2}, 24, 16, 0, UINT16_MAX, 1, 0, NULL_PTR, &cans_getvolt },  /*!< CAN0_SIG_Mod0_volt_7 */
    { {CAN0_MSG_Mod0_Cellvolt_2}, 40, 16, 0, UINT16_MAX, 1, 0, NULL_PTR, &cans_getvolt },  /*!< CAN0_SIG_Mod0_volt_8 */
    { {CAN0_MSG_Mod0_Cellvolt_3}, 0, 8, 0, UINT8_MAX, 1, 0, NULL_PTR, &cans_getvolt },  /*!< CAN0_SIG_Mod0_volt_valid_9_11 */
    { {CAN0_MSG_Mod0_Cellvolt_3}, 8, 16, 0, UINT16_MAX, 1, 0, NULL_PTR, &cans_getvolt },  /*!< CAN0_SIG_Mod0_volt_9 */
    { {CAN0_MSG_Mod0_Cellvolt_3}, 24, 16, 0, UINT16_MAX, 1, 0, NULL_PTR, &cans_getvolt },  /*!< CAN0_SIG_Mod0_volt_10 */
    { {CAN0_MSG_Mod0_Cellvolt_3}, 40, 16, 0, UINT16_MAX, 1, 0, NULL_PTR, &cans_getvolt },  /*!< CAN0_SIG_Mod0_volt_11 */
    { {CAN0_MSG_Mod0_Cellvolt_4}, 0, 8, 0, UINT8_MAX, 1, 0, NULL_PTR, &cans_getvolt },  /*!< CAN0_SIG_Mod0_volt_valid_12_14 */
    { {CAN0_MSG_Mod0_Cellvolt_4}, 8, 16, 0, UINT16_MAX, 1, 0, NULL_PTR, &cans_getvolt },  /*!< CAN0_SIG_Mod0_volt_12 */
    { {CAN0_MSG_Mod0_Cellvolt_4}, 24, 16, 0, UINT16_MAX, 1, 0, NULL_PTR, &cans_getvolt },  /*!< CAN0_SIG_Mod0_volt_13 */
    { {CAN0_MSG_Mod0_Cellvolt_4}, 40, 16, 0, UINT16_MAX, 1, 0, NULL_PTR, &cans_getvolt },  /*!< CAN0_SIG_Mod0_volt_14 */
    { {CAN0_MSG_Mod0_Cellvolt_5}, 0, 8, 0, UINT8_MAX, 1, 0, NULL_PTR, &cans_getvolt },  /*!< CAN0_SIG_Mod0_volt_valid_15_17 */
    { {CAN0_MSG_Mod0_Cellvolt_5}, 8, 16, 0, UINT16_MAX, 1, 0, NULL_PTR, &cans_getvolt },  /*!< CAN0_SIG_Mod0_volt_15 */
    { {CAN0_MSG_Mod0_Cellvolt_5}, 24, 16, 0, UINT16_MAX, 1, 0, NULL_PTR, &cans_getvolt },  /*!< CAN0_SIG_Mod0_volt_16 */
    { {CAN0_MSG_Mod0_Cellvolt_5}, 40, 16, 0, UINT16_MAX, 1, 0, NULL_PTR, &cans_getvolt },  /*!< CAN0_SIG_Mod0_volt_17 */

    /* Module 0 cell temperatures */
    { {CAN0_MSG_Mod0_Celltemp_0}, 0, 8, 0, UINT8_MAX, 1, 0, NULL_PTR, &cans_gettemp },  /*!< CAN0_SIG_Mod0_volt_valid_0_2 */
    { {CAN0_MSG_Mod0_Celltemp_0}, 8, 16, -128, 527.35, 100, 128, NULL_PTR, &cans_gettemp },  /*!< CAN0_SIG_Mod0_temp_0 */
    { {CAN0_MSG_Mod0_Celltemp_0}, 24, 16, -128, 527.35, 100, 128, NULL_PTR, &cans_gettemp },  /*!< CAN0_SIG_Mod0_temp_1 */
    { {CAN0_MSG_Mod0_Celltemp_0}, 40, 16, -128, 527.35, 100, 128, NULL_PTR, &cans_gettemp },  /*!< CAN0_SIG_Mod0_temp_2 */
    { {CAN0_MSG_Mod0_Celltemp_1}, 0, 8, 0, UINT8_MAX, 1, 0, NULL_PTR, &cans_gettemp },  /*!< CAN0_SIG_Mod0_volt_valid_3_5 */
    { {CAN0_MSG_Mod0_Celltemp_1}, 8, 16, -128, 527.35, 100, 128, NULL_PTR, &cans_gettemp },  /*!< CAN0_SIG_Mod0_temp_3 */
    { {CAN0_MSG_Mod0_Celltemp_1}, 24, 16, -128, 527.35, 100, 128, NULL_PTR, &cans_gettemp },  /*!< CAN0_SIG_Mod0_temp_4 */
    { {CAN0_MSG_Mod0_Celltemp_1}, 40, 16, -128, 527.35, 100, 128, NULL_PTR, &cans_gettemp },  /*!< CAN0_SIG_Mod0_temp_5 */
    { {CAN0_MSG_Mod0_Celltemp_2}, 0, 8, 0, UINT8_MAX, 1, 0, NULL_PTR, &cans_gettemp },  /*!< CAN0_SIG_Mod0_volt_valid_6_8 */
    { {CAN0_MSG_Mod0_Celltemp_2}, 8, 16, -128, 527.35, 100, 128, NULL_PTR, &cans_gettemp },  /*!< CAN0_SIG_Mod0_temp_6 */
    { {CAN0_MSG_Mod0_Celltemp_2}, 24, 16, -128, 527.35, 100, 128, NULL_PTR, &cans_gettemp },  /*!< CAN0_SIG_Mod0_temp_7 */
    { {CAN0_MSG_Mod0_Celltemp_2}, 40, 16, -128, 527.35, 100, 128, NULL_PTR, &cans_gettemp },  /*!< CAN0_SIG_Mod0_temp_8 */
    { {CAN0_MSG_Mod0_Celltemp_3}, 0, 8, 0, UINT8_MAX, 1, 0, NULL_PTR, &cans_gettemp },  /*!< CAN0_SIG_Mod0_volt_valid_9_11 */
    { {CAN0_MSG_Mod0_Celltemp_3}, 8, 16, -128, 527.35, 100, 128, NULL_PTR, &cans_gettemp },  /*!< CAN0_SIG_Mod0_temp_9 */
    { {CAN0_MSG_Mod0_Celltemp_3}, 24, 16, -128, 527.35, 100, 128, NULL_PTR, &cans_gettemp },  /*!< CAN0_SIG_Mod0_temp_10 */
    { {CAN0_MSG_Mod0_Celltemp_3}, 40, 16, -128, 527.35, 100, 128, NULL_PTR, &cans_gettemp },  /*!< CAN0_SIG_Mod0_temp_11 */

Remove all unused struct entries depending on the number of used cells/sensors. Repeat this process for all modules.

5. Adapt functions ``cans_getvolt`` and ``cans_gettemp`` in file ``module/config/cansignal_cfg.c``:

Remove all case-statements for which the signals have been deleted in the previous steps.

.. _faq_can_lessthan8modules:

How to adapt the CAN module when less or more than 8 battery modules are used?
------------------------------------------------------------------------------

When less than 8 modules are used, the same procedure as described in :ref:`faq_can_lessthan8modules` must be used but only the unused
modules instead of unused cell voltages/temperatures must be deleted. If additional modules should be added also follow these instructions
but instead of deleting these signals and CAN messages add the wished number of new messages.

Morover an adaption of the functions  ``cans_getvolt`` and ``cans_gettemp`` in file ``module/config/cansignal_cfg.c`` is necessary:

.. code-block:: C

    // Determine module and cell number
    if (sigIdx - CAN0_SIG_Mod0_volt_valid_0_2 < CANS_MODULSIGNALS_VOLT) {
        modIdx = 0;
        cellIdx = sigIdx - CAN0_SIG_Mod0_volt_valid_0_2;
    } else if (sigIdx - CAN0_SIG_Mod1_volt_valid_0_2 < CANS_MODULSIGNALS_VOLT) {
        modIdx = 1;
        cellIdx = sigIdx - CAN0_SIG_Mod1_volt_valid_0_2;
    } else if (sigIdx - CAN0_SIG_Mod2_volt_valid_0_2 < CANS_MODULSIGNALS_VOLT) {
        modIdx = 2;
        cellIdx = sigIdx - CAN0_SIG_Mod2_volt_valid_0_2;
    } else if (sigIdx - CAN0_SIG_Mod3_volt_valid_0_2 < CANS_MODULSIGNALS_VOLT) {
        modIdx = 3;
        cellIdx = sigIdx - CAN0_SIG_Mod3_volt_valid_0_2;
    } else if (sigIdx - CAN0_SIG_Mod4_volt_valid_0_2 < CANS_MODULSIGNALS_VOLT) {
        modIdx = 4;
        cellIdx = sigIdx - CAN0_SIG_Mod4_volt_valid_0_2;
    } else if (sigIdx - CAN0_SIG_Mod5_volt_valid_0_2 < CANS_MODULSIGNALS_VOLT) {
        modIdx = 5;
        cellIdx = sigIdx - CAN0_SIG_Mod5_volt_valid_0_2;
    } else if (sigIdx - CAN0_SIG_Mod6_volt_valid_0_2 < CANS_MODULSIGNALS_VOLT) {
        modIdx = 6;
        cellIdx = sigIdx - CAN0_SIG_Mod6_volt_valid_0_2;
    } else if (sigIdx - CAN0_SIG_Mod7_volt_valid_0_2 < CANS_MODULSIGNALS_VOLT) {
        modIdx = 7;
        cellIdx = sigIdx - CAN0_SIG_Mod7_volt_valid_0_2;
    }

This if statement performs a module detection to allocate the correct cell voltage to the respective CAN message. This statement
needs to be shortened/extended depending on the number of used modules. The same method is used to allocate the cell temperatures
and thus needs to be adapted as well.

.. note::

    The define CANS_MODULSIGNALS_TEMP is calculated as followed:

    .. code-block:: C

        #define CANS_MODULSIGNALS_TEMP  (CAN0_SIG_Mod1_volt_valid_0_2 - CAN0_SIG_Mod0_temp_valid_0_2)

    When only one module is used this define needs to be redefined on the next signal used after the last temperature signal of
    module 0. If no signal is defined after the module 0 temperature signals use the last defined temperature signal. For the
    default configuration of foxBMS this could look like this:

    .. code-block:: C

        #define CANS_MODULSIGNALS_TEMP  ((CAN0_SIG_Mod0_temp_11 - CAN0_SIG_Mod0_temp_valid_0_2) + 1)

How to change the blink period of the indicator LEDs?
-----------------------------------------------------

It is defined via the three variables in ``module/utils/led.c``:

 - ``led_0_nbr_of_blink``
 - ``led_1_nbr_of_blink``
 - ``led_blink_time``

Currently the three variables are set directly in the function ``LED_Ctrl()``. If desired or needed, the three values can be read from the database and so set elsewhere in the code.

The time is set in ms via ``led_blink_time``. The LED cycle is divided in two periods, T0 and T1. Each of both periods lasts ``led_blink_time`` ms. During T0, LED0 is on or blinks and LED1 is off. During T1, LED0 is off and LED1 is on or blinks. The behavior described as ''is on or blinks'' is defined via ``led_0_nbr_of_blink`` for LED0 and via ``led_1_nbr_of_blink`` for LED1. If ``led_0_nbr_of_blink`` is set to 1, LED0 is on during T0. If ``led_0_nbr_of_blink`` is set to n greater than 1, LED0 will blink n times during T1. For example, if the period is set to 3000ms and ``led_0_nbr_of_blink`` set to 3, LED0 will have the following behavior during T0:

 - On for 500ms
 - Off for 500ms
 - On for 500ms
 - Off for 500ms
 - On for 500ms
 - Off for 500ms

The behavior is the same for LED1 with ``led_1_nbr_of_blink``. With this functionality, each LED can blink independently n times. If each LED can blink up to 4 times, the LEDs can visually give 16 different messages.

The adjustment of the blink period is provided to make reading by the user easier: for higher number of blinks, the blink period can be made longer: for example, it is easier to count 4 blinks in 3s than 4 blinks in 1s).

How to add an entry for the diag module?
----------------------------------------

Adding a new sensitivity level is done in ``src/engine/config/diag_cfg.h`` by adding a new ``#define`` in:

.. code-block:: C

   #define DIAG_ERROR_SENSITIVITY_HIGH        (0)   // logging at first event
   #define DIAG_ERROR_SENSITIVITY_MID         (5)   // logging at fifth event
   #define DIAG_ERROR_SENSITIVITY_LOW         (10)  // logging at tenth event
   #define DIAG_ERROR_SENSITIVITY_CUSTOM      (100) // logging at 100th event

and errors can be defined:

.. code-block:: C

   #define     DIAG_CH_CUSTOM_FAILURE             DIAG_ID_XX

and the error is then added in ``DIAG_CH_CFG_s  diag_ch_cfg[]`` in file ``src/engine/config/diag_cfg.c``:

.. code-block:: C

   DIAG_CH_CFG_s  diag_ch_cfg[] = {
    {DIAG_CH_CUSTOM_FAILURE,        DIAG_GENERAL_TYPE, DIAG_ERROR_SENSITIVITY_HIGH,
     DIAG_RECORDING_ENABLED, DIAG_ENABLED, dummyfu},

The number of logged error events can be changed by modifying the value of the macro:

.. code-block:: C

   #define DIAG_FAIL_ENTRY_LENGTH               (50)    // Number of errors that can be logged

.. note::
    The diag module is a powerful module for general error handling. The user has to be aware of timings when using custom diag entries. As example how to use this module correct syscontrol is choosen.
    - The function ``SYSCTRL_Trigger()`` is called in the 10ms task (``ENG_TSK_Cyclic_10ms()``), meaning every 10ms this function must be executed.
    - In the diagnosis-module header ``diag_cfg.h`` there is the enum ``DIAG_SYSMON_MODULE_ID_e`` for the different error types that are handeled by the diagnosismodule. For syscontrol errors there is ``DIAG_SYSMON_SYSCTRL_ID``.
    - In the diagnosis-module source ``diag_cfg.c`` there is the ``diag_sysmon_ch_cfg[]`` array assigning timings to this error, in this case 20ms.

    .. code-block:: C

        {DIAG_SYSMON_SYSCTRL_ID, DIAG_SYSMON_CYCLICTASK, 20,
        DIAG_RECORDING_ENABLED, DIAG_ENABLED, dummyfu2},

    This means every time ``SYSCTRL_Trigger()`` is called, the function indicating `syscontrol is running` has to be exectued. If this is not done, the diagnosis module will set the syscontrol to the error state. Therefore, the user must set up functions, which are wanted to be supervised by the diagnosis module, and that they are still running, in this way:

    .. code-block:: C

        void SYSCTRL_Trigger(SYSCTRL_TRIG_EVENT_e event) {
            DIAG_SysMonNotify(DIAG_SYSMON_SYSCTRL_ID, 0);    // task is running, therefore
                                    // reset state to 0
            /* user code */
        }

How to configure contactors without feedback?
---------------------------------------------

In the file ``src/module/config/contactor_cfg.c``, the contactors are defined with:

.. code-block:: C

   CONT_CFG_s cont_contactors_cfg[NR_OF_CONTACTORS] = {
           {CONT_MAIN_PLUS_CONTROL,        CONT_MAIN_PLUS_FEEDBACK,        CONT_FEEDBACK_NORMALLY_OPEN},
           {CONT_PRECHARGE_PLUS_CONTROL,   CONT_PRECHARGE_PLUS_FEEDBACK,   CONT_FEEDBACK_NORMALLY_OPEN},
           {CONT_MAIN_MINUS_CONTROL,       CONT_MAIN_MINUS_FEEDBACK,       CONT_FEEDBACK_NORMALLY_OPEN}
   };

The following change must be made to configure a contactor without feedback. In this case, the precharge contactor is taken as example:

.. code-block:: C

   {CONT_PRECHARGE_PLUS_CONTROL,   CONT_PRECHARGE_PLUS_FEEDBACK,   CONT_HAS_NO_FEEDBACK}

With this configuration, the feedback pin (``CONT_PRECHARGE_PLUS_FEEDBACK``) is ignored and the feedback value will always be equal to the expected value for the precharge contactor. This configuration should not be used without precautions since the safety level will be reduced.

.. _can_debug_message:

How to simply trigger events via CAN?
-------------------------------------

The CAN message with ID 0x100 is considered as a `debug message`. If received, the function ``cans_setdebug()`` defined in ``cansignal_cfc.c`` is called. There, a switch case is used on the first byte (byte0) of the message to define what to do. This means that 256 actions are possible, and that 7 bytes remain to transfer data in the debug message.

How to start/stop balancing the battery cells?
----------------------------------------------

When the ``#define BALANCING_DEFAULT_INACTIVE`` is set to ``FALSE``, |foxBMS| starts the balancing process automatically if the balancing requirements are met. The balancing behavior is described in details in the documentation of the :ref:`BALANCING` module.

This behavior can be influenced via a debug message sent per CAN (:ref:`can_debug_message`).

When the data ``0E 01 00 00 00 00 00 00`` is sent, the balancing state machine goes to the ``BAL_STATEMACH_INACTIVE_OVERRIDE`` state. No balancing takes place.

When the data ``0E 03 00 00 00 00 00 00`` is sent, the balancing state machine goes to the ``BAL_STATEMACH_ACTIVE_OVERRIDE`` state. Balancing takes place without taking into account the state of the |mod_bms|, the current flowing through the battery and the minimum cell voltage in the battery pack.

When the data ``0E 02 00 00 00 00 00 00`` is sent, the balancing state machine goes out of the override state. Balancing takes place taking into account the state of the |mod_bms|, the current flowing through the battery and the minimum cell voltage in the battery pack.

How to set the initial SOC value via CAN?
-----------------------------------------

This is done via the debug message with the first byte (byte0) equal to 11 (0x0B). The SOC is defined via the next two bytes (i.e., on 16bit: byte1 byte2). The SOC is given in 0.01% unit, which means that the 16bit number should be comprised between 0 and 10000. If a smaller value is given, the SOC will be set to 0%. If a greater value is given, SOC will be set to 100%.

.. _faq_reset_deep_discharge:

How to reset deep-discharge flag via CAN?
-----------------------------------------

.. note::

    This message should only be sent after
    replacing the affected cell as charging a deep-discharged cell is highly
    dangerous.

The deep-discharge flag can be reset by transmitting debug message with the
first byte (byte0) equal to 170 (0xAA).

.. _faq_voltage_input_configuration:

How to configure the voltage inputs?
------------------------------------

This number is changed in ``batterysystem_cfg.h`` with the define ``BS_NR_OF_BAT_CELLS_PER_MODULE``. In addition, the variable

.. code-block:: C

    const uint8_t ltc_voltage_input_used[BS_MAX_SUPPORTED_CELLS]

must be adapted, too, in ``ltc_cfg.c``.

It has the size of ``BS_MAX_SUPPORTED_CELLS``. If a cell voltage is connected to the LTC IC input, ``1`` must be written in the table. Otherwise, ``0`` must be written.

For instance, if 5 cells are connected to inputs ``0``, ``2``, ``5``, ``7``, ``11``,

.. code-block:: C

    #define BS_NR_OF_BAT_CELLS_PER_MODULE               5

must be used and

.. code-block:: C

    const uint8_t ltc_voltage_input_used[BS_MAX_SUPPORTED_CELLS] = {
        1 ,
        0 ,
        1 ,
        0 ,
        0 ,
        1 ,
        0 ,
        1 ,
        0 ,
        0 ,
        0 ,
        1 ,
    };

must be defined. The number of ``1`` in the table must be equal to ``BS_NR_OF_BAT_CELLS_PER_MODULE``.

.. _faq_temperature_sensor_configuration:

How to add/remove temperature sensors?
--------------------------------------

To add one temperature sensor, the first step is to change:

.. code-block:: C

    #define BS_NR_OF_TEMP_SENSORS_PER_MODULE           6

to:

.. code-block:: C

    #define BS_NR_OF_TEMP_SENSORS_PER_MODULE           7

in ``batterysystem_cfg.h``.

However, this obvious step is not sufficient.

In ``ltc_cfg.c``, the variable ``LTC_MUX_CH_CFG_s ltc_mux_seq_main_ch1[]`` which indicates the channel sequence to read on the multiplexer has to be modified. One sensor channel on one multiplexer has to be added. In this example, on the multiplexer with the ID 0 and channel 6 is read additionally.

Concretely:

.. code-block:: C

    {
        .muxID    = 1,
        .muxCh    = 0xFF,
    },
    {
        .muxID    = 2,
        .muxCh    = 0xFF,
    },
    {
        .muxID    = 3,
        .muxCh    = 0xFF,
    },
    {
        .muxID    = 0,
        .muxCh    = 0,
    },
    {
        .muxID    = 0,
        .muxCh    = 1,
    },
    {
        .muxID    = 0,
        .muxCh    = 2,
    },
    {
        .muxID    = 0,
        .muxCh    = 3,
    },
    {
        .muxID    = 0,
        .muxCh    = 4,
    },
    {
        .muxID    = 0,
        .muxCh    = 5,
    },
    {
        .muxID    = 0,      //configure the multiplexer to be used
        .muxCh    = 6,      //configure input to ne used on the selected multiplexer
    },

must be used instead of:

.. code-block:: C

    {
        .muxID    = 1,
        .muxCh    = 0xFF,
    },
    {
        .muxID    = 2,
        .muxCh    = 0xFF,
    },
    {
        .muxID    = 3,
        .muxCh    = 0xFF,
    },
    {
        .muxID    = 0,
        .muxCh    = 0,
    },
    {
        .muxID    = 0,
        .muxCh    = 1,
    },
    {
        .muxID    = 0,
        .muxCh    = 2,
    },
    {
        .muxID    = 0,
        .muxCh    = 3,
    },
    {
        .muxID    = 0,
        .muxCh    = 4,
    },
    {
        .muxID    = 0,
        .muxCh    = 5,
    },

Then the look-up table must be modified: it allows defining the correspondence between multiplexer channel and sensor order in the temperature array. By default, the mapping keeps the same order. In the previous example:

.. code-block:: C

    const uint8_t ltc_muxsensortemperatur_cfg[6] = {
        1-1 ,       /*!< index 0 = mux 0, ch 0 */
        2-1 ,       /*!< index 1 = mux 0, ch 1 */
        3-1 ,       /*!< index 2 = mux 0, ch 2 */
        4-1 ,       /*!< index 3 = mux 0, ch 3 */
        5-1 ,       /*!< index 4 = mux 0, ch 4 */
        6-1 ,       /*!< index 5 = mux 0, ch 5 */
        //7-1 ,     /*!< index 6 = mux 0, ch 6 */
        //8-1 ,     /*!< index 7 = mux 0, ch 7 */
        //9-1 ,     /*!< index 8 = mux 1, ch 0 */
        //10-1 ,    /*!< index 9 = mux 1, ch 1 */
        //11-1 ,    /*!< index 10 = mux 1, ch 2 */
        //12-1 ,    /*!< index 11 = mux 1, ch 3 */
        //13-1 ,    /*!< index 12 = mux 1, ch 4 */
        //14-1 ,    /*!< index 13 = mux 1, ch 5 */
        //15-1 ,    /*!< index 14 = mux 1, ch 6 */
        //16-1      /*!< index 15 = mux 1, ch 7 */
    };

must be changed to:

.. code-block:: C

    const uint8_t ltc_muxsensortemperatur_cfg[7] = {
        1-1 ,       /*!< index 0 = mux 0, ch 0 */
        2-1 ,       /*!< index 1 = mux 0, ch 1 */
        3-1 ,       /*!< index 2 = mux 0, ch 2 */
        4-1 ,       /*!< index 3 = mux 0, ch 3 */
        5-1 ,       /*!< index 4 = mux 0, ch 4 */
        6-1 ,       /*!< index 5 = mux 0, ch 5 */
        7-1 ,     /*!< index 6 = mux 0, ch 6 */
        //8-1 ,     /*!< index 7 = mux 0, ch 7 */
        //9-1 ,     /*!< index 8 = mux 1, ch 0 */
        //10-1 ,    /*!< index 9 = mux 1, ch 1 */
        //11-1 ,    /*!< index 10 = mux 1, ch 2 */
        //12-1 ,    /*!< index 11 = mux 1, ch 3 */
        //13-1 ,    /*!< index 12 = mux 1, ch 4 */
        //14-1 ,    /*!< index 13 = mux 1, ch 5 */
        //15-1 ,    /*!< index 14 = mux 1, ch 6 */
        //16-1      /*!< index 15 = mux 1, ch 7 */
    };

A last step has to be done in ``ltc_cfg.h``: adjust the size of the array, by changing:

.. code-block:: C

    extern const uint8_t ltc_muxsensortemperatur_cfg[6];

into:

.. code-block:: C

    extern const uint8_t ltc_muxsensortemperatur_cfg[7];

The same procedure must be used to remove a temperature sensor.

How to change the resolution of the temperature values stored?
--------------------------------------------------------------

The scaling of the raw values read from the |LTC| is made in ``ltc.c``, in the function ``static void LTC_SaveTemperatures_SaveBalancingFeedback(void)``. First, the raw data are read from the SPI buffer with:

.. code-block:: C

    val_ui=*((uint16_t *)(&LTC_MultiplexerVoltages[2*((LTC_NUMBER_OF_LTC_PER_MODULE*i*LTC_N_MUX_CHANNELS_PER_LTC)+muxseqptr->muxID*LTC_N_MUX_CHANNELS_PER_MUX+muxseqptr->muxCh)]));

Then the raw data are scaled and are available in Volt:

.. code-block:: C

    val_fl = ((float)(val_ui))*100e-6;

Then the read voltage is converted into a temperature with a look-up table:

.. code-block:: C

    val_si = (int16_t)(LTC_Convert_MuxVoltages_to_Temperatures(val_fl));

The last step is to store the temperature into a ``sint16`` variable:

.. code-block:: C

    ltc_celltemperature.temperature[i*(NR_OF_TEMP_SENSORS_PER_MODULE)+sensor_idx]=val_si;

At this step, the resolution can be changed. For instance, m°C could be stored instead of °C.

.. _faq_checksum:

How to enable and disable the checksum?
---------------------------------------

The checksum mechanism is enabled via the following define in the file ``general.h``:

.. code-block:: C

    #define BUILD_MODULE_ENABLE_FLASHCHECKSUM 1

How to call a user function to implement a specific algorithm?
--------------------------------------------------------------

In ``embedded-software\mcu-primary\src\application\config\appltask_cfg.c``, the user function must simply be called in one of the periodic user function:

.. code-block:: C

    void APPL_Cyclic_1ms(void)
    void APPL_Cyclic_10ms(void)
    void APPL_Cyclic_100ms(void)

depending on the periodicity needed. The user function can access system data via the database.

For instance, to access the voltages, a structure must be declared with

.. code-block:: C

    DATA_BLOCK_CELLVOLTAGE_s voltages;

The data is retrieved from the database with

.. code-block:: C

    DB_ReadBlock(&voltages, DATA_BLOCK_ID_CELLVOLTAGE);
    myvoltage = voltages.voltage[i];

The field ``voltages.timestamp`` is updated with the system timestamp (in ms) everytime new voltages are written in the database. This timestamp can be used to check if the voltages have been updated.

To store the results, an entry must be created in the database, as explained in :ref:`database_entry`.

Once the results are stored in the database, they can for instance be sent by CAN.

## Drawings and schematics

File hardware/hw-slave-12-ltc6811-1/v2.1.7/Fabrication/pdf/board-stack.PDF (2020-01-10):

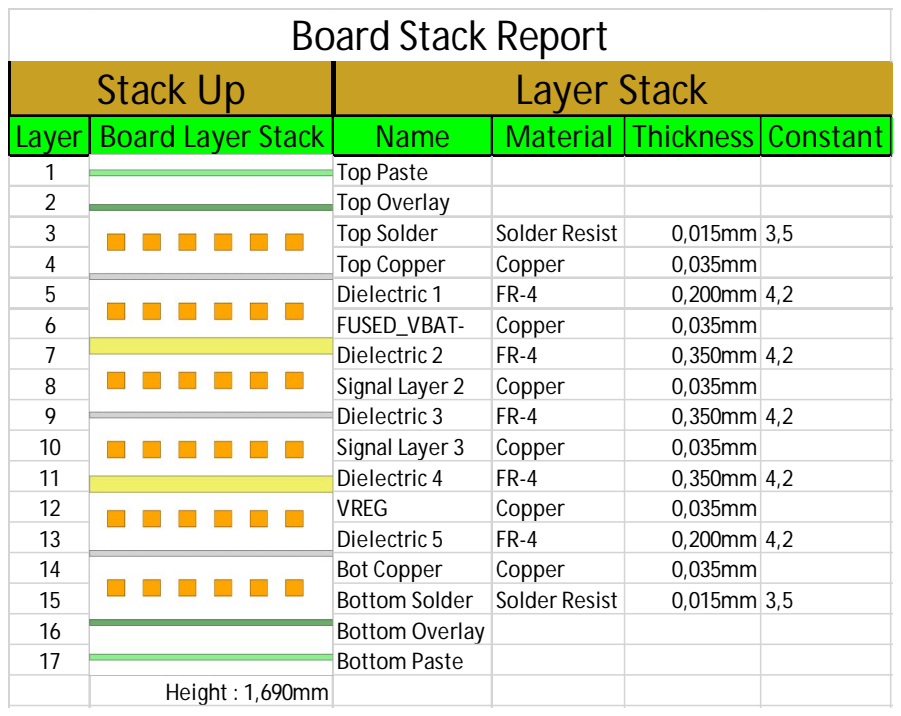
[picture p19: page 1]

Stack Up | Layer Stack
Layer | Board Layer Stack | Name | Material | Thickness | Constant
1 | | Top Paste
2 | | Top Overlay
3 | | Top Solder | Solder Resist | 0,015mm | 3,5
4 | | Top Copper | Copper | 0,035mm
5 | | Dielectric 1 | FR-4 | 0,200mm | 4,2
6 | | FUSED_VBAT- | Copper | 0,035mm
7 | | Dielectric 2 | FR-4 | 0,350mm | 4,2
8 | | Signal Layer 2 | Copper | 0,035mm
9 | | Dielectric 3 | FR-4 | 0,350mm | 4,2
10 | | Signal Layer 3 | Copper | 0,035mm
11 | | Dielectric 4 | FR-4 | 0,350mm | 4,2
12 | | VREG | Copper | 0,035mm
13 | | Dielectric 5 | FR-4 | 0,200mm | 4,2
14 | | Bot Copper | Copper | 0,035mm
15 | | Bottom Solder | Solder Resist | 0,015mm | 3,5
16 | | Bottom Overlay
17 | | Bottom Paste

Height : 1,690mm

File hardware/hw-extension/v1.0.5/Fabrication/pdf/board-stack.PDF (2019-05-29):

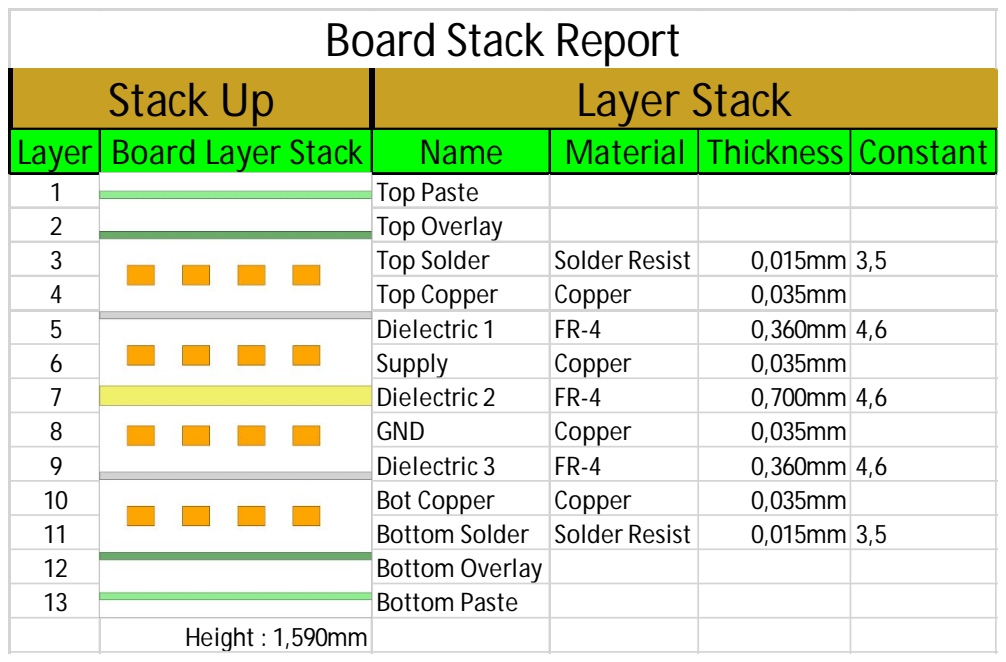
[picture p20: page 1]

Stack Up | Layer Stack
Layer | Board Layer Stack | Name | Material | Thickness | Constant
1 | | Top Paste
2 | | Top Overlay
3 | | Top Solder | Solder Resist | 0,015mm | 3,5
4 | | Top Copper | Copper | 0,035mm
5 | | Dielectric 1 | FR-4 | 0,360mm | 4,6
6 | | Supply | Copper | 0,035mm
7 | | Dielectric 2 | FR-4 | 0,700mm | 4,6
8 | | GND | Copper | 0,035mm
9 | | Dielectric 3 | FR-4 | 0,360mm | 4,6
10 | | Bot Copper | Copper | 0,035mm
11 | | Bottom Solder | Solder Resist | 0,015mm | 3,5
12 | | Bottom Overlay
13 | | Bottom Paste

Height : 1,590mm

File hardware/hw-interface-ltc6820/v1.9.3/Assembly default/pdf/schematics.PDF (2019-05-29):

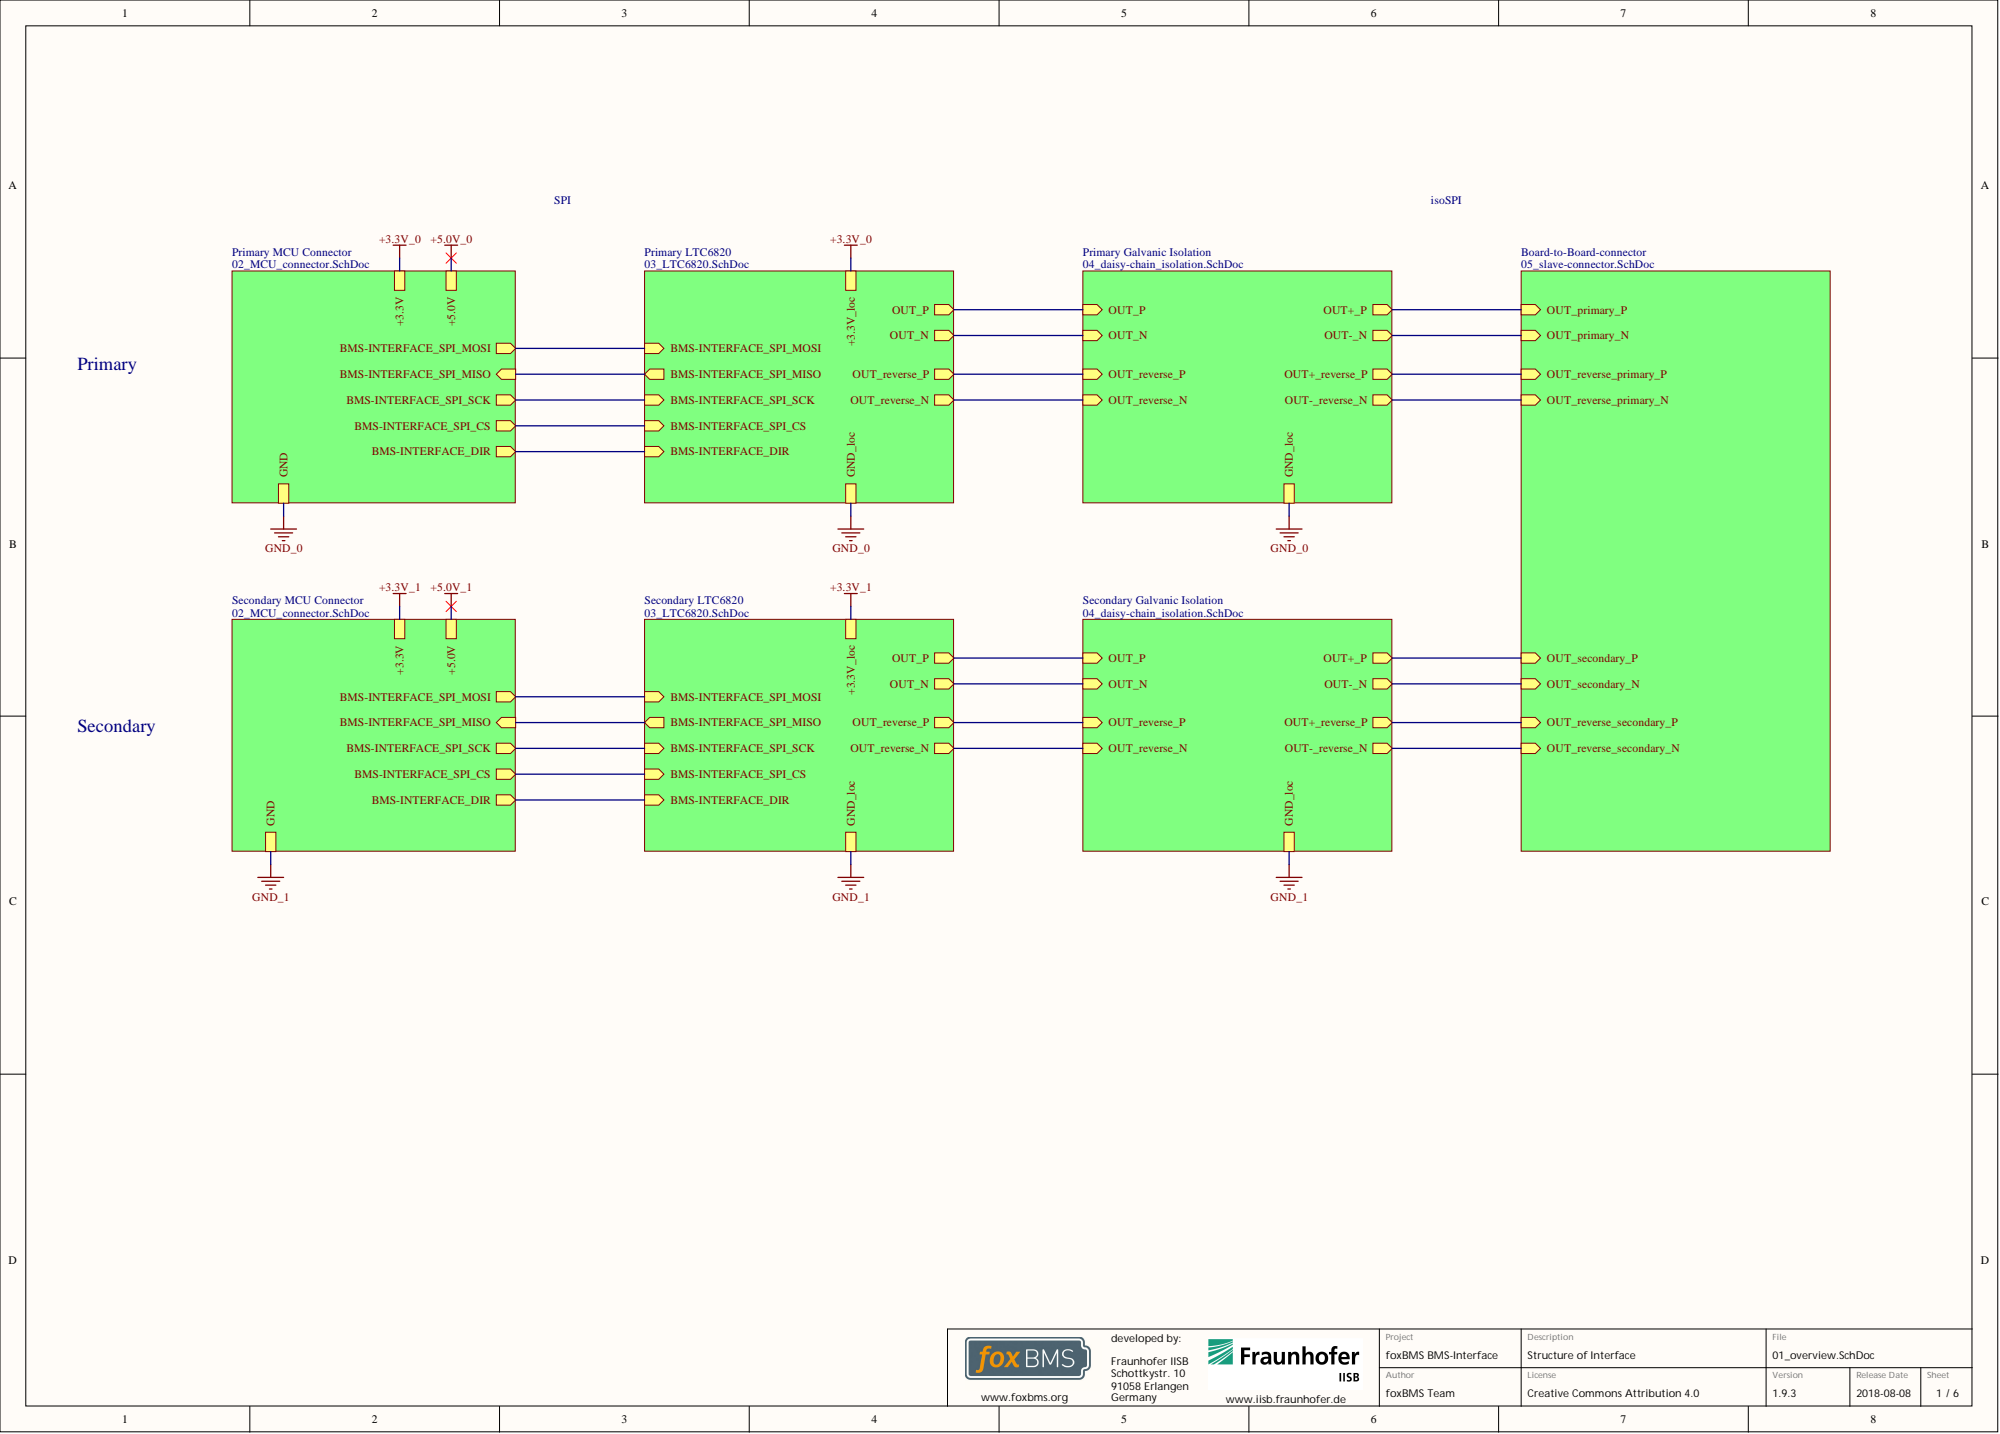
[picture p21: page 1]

Board-to-Board-connector
05_slave-connector.SchDoc

www.iisb.fraunhofer.de

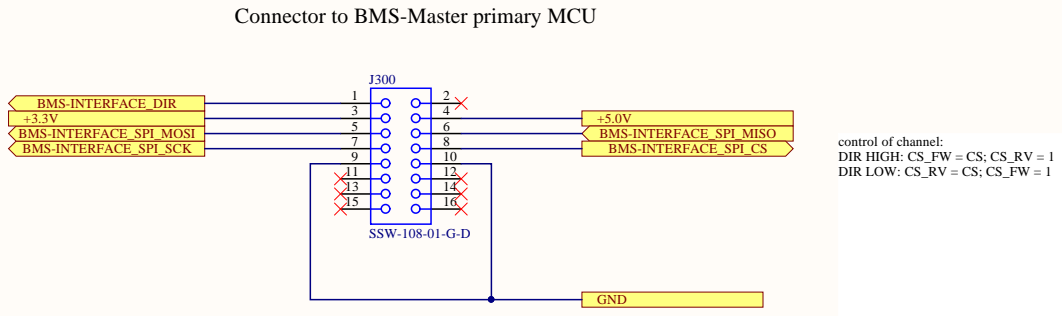
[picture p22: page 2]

Connector to BMS-Master primary MCU

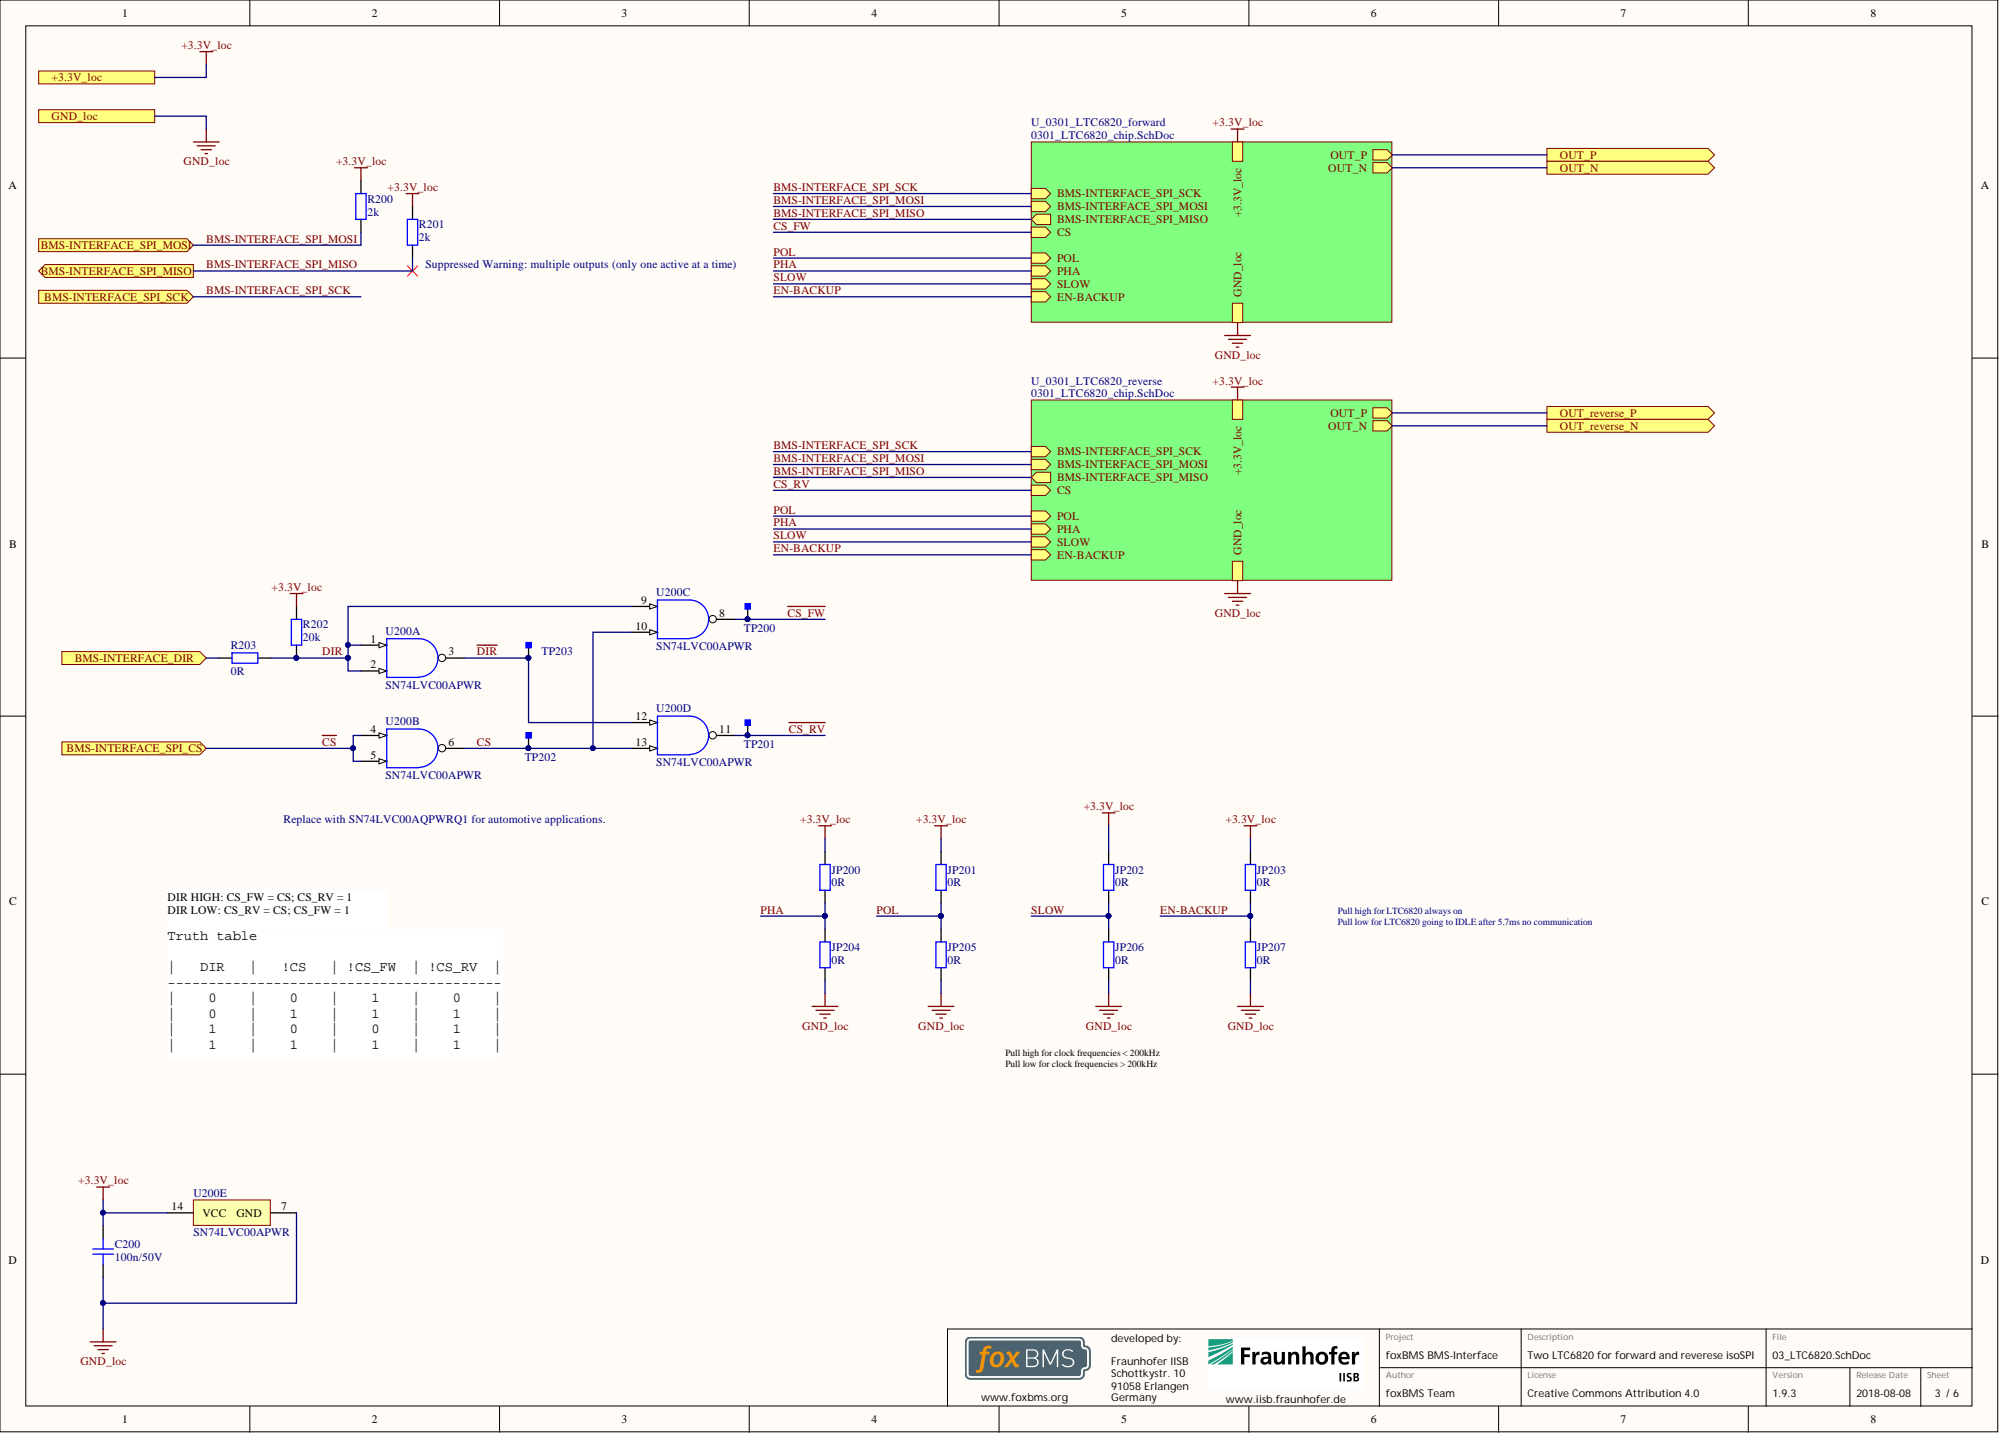
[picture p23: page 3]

Suppressed Warning: multiple outputs (only one active at a time)

Replace with SN74LVC00AQPWRQ1 for automotive applications.

Pull high for LTC6820 always on
Pull low for LTC6820 going to IDLE after 5.7ms no communication

Pull high for clock frequencies < 200kHz
Pull low for clock frequencies > 200kHz

Two LTC6820 for forward and reverese isoSPI

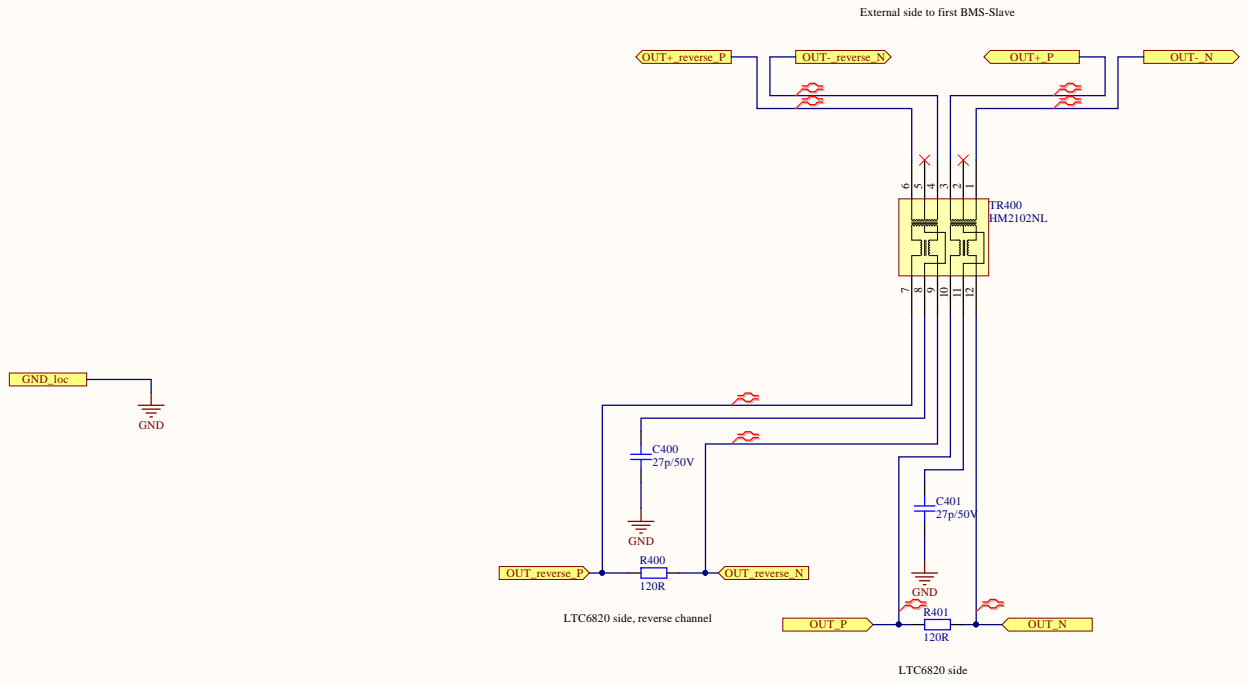
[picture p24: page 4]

External side to first BMS-Slave

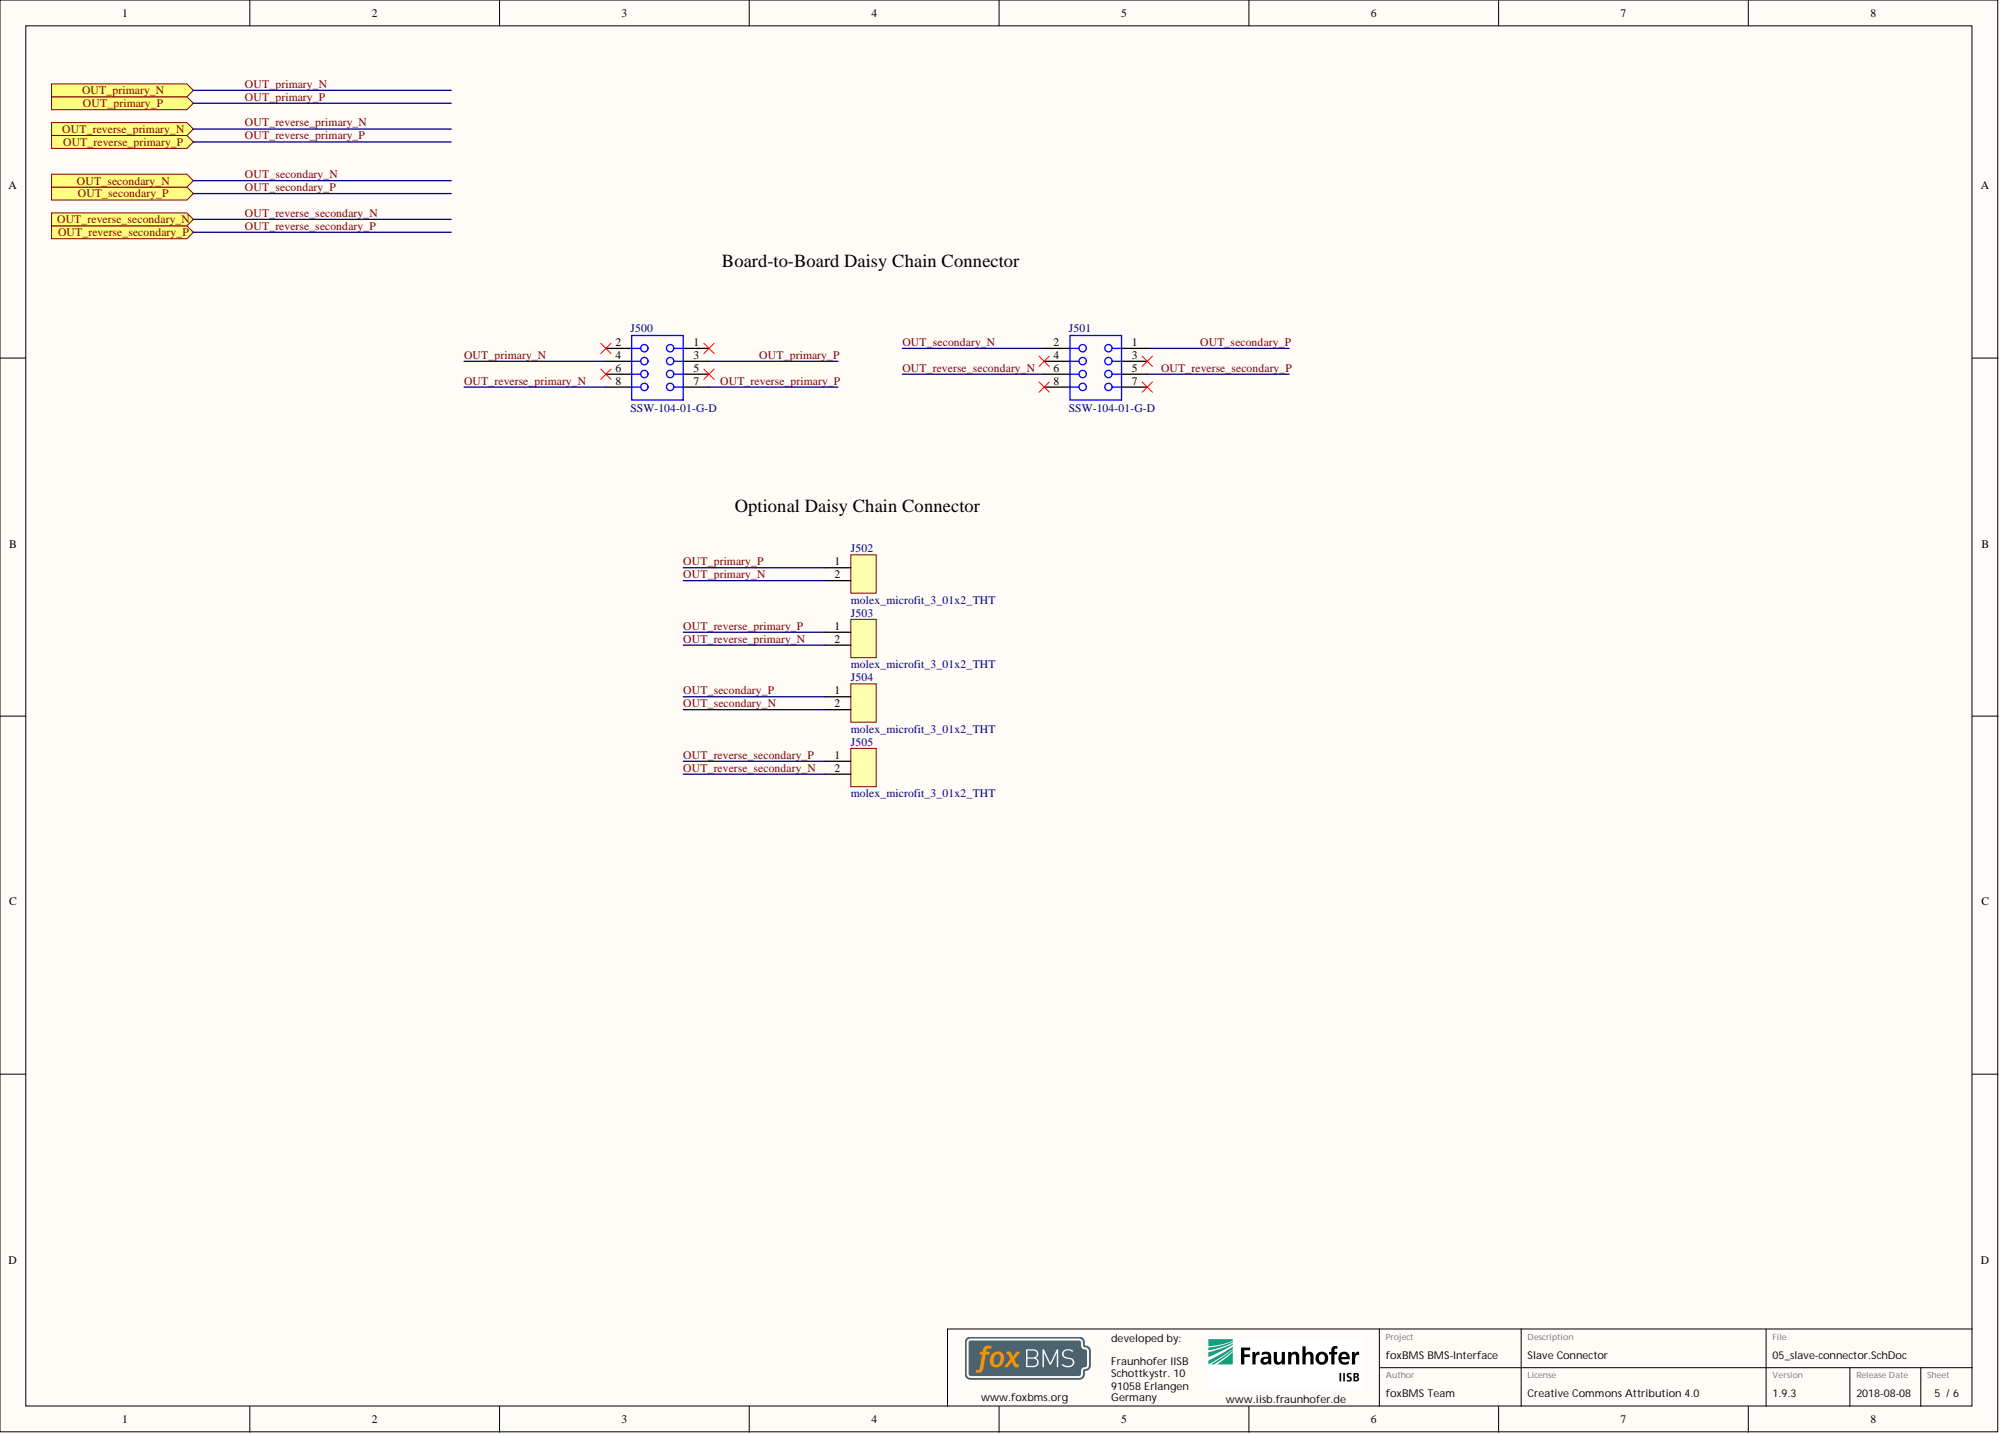
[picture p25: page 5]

Board-to-Board Daisy Chain Connector

Optional Daisy Chain Connector

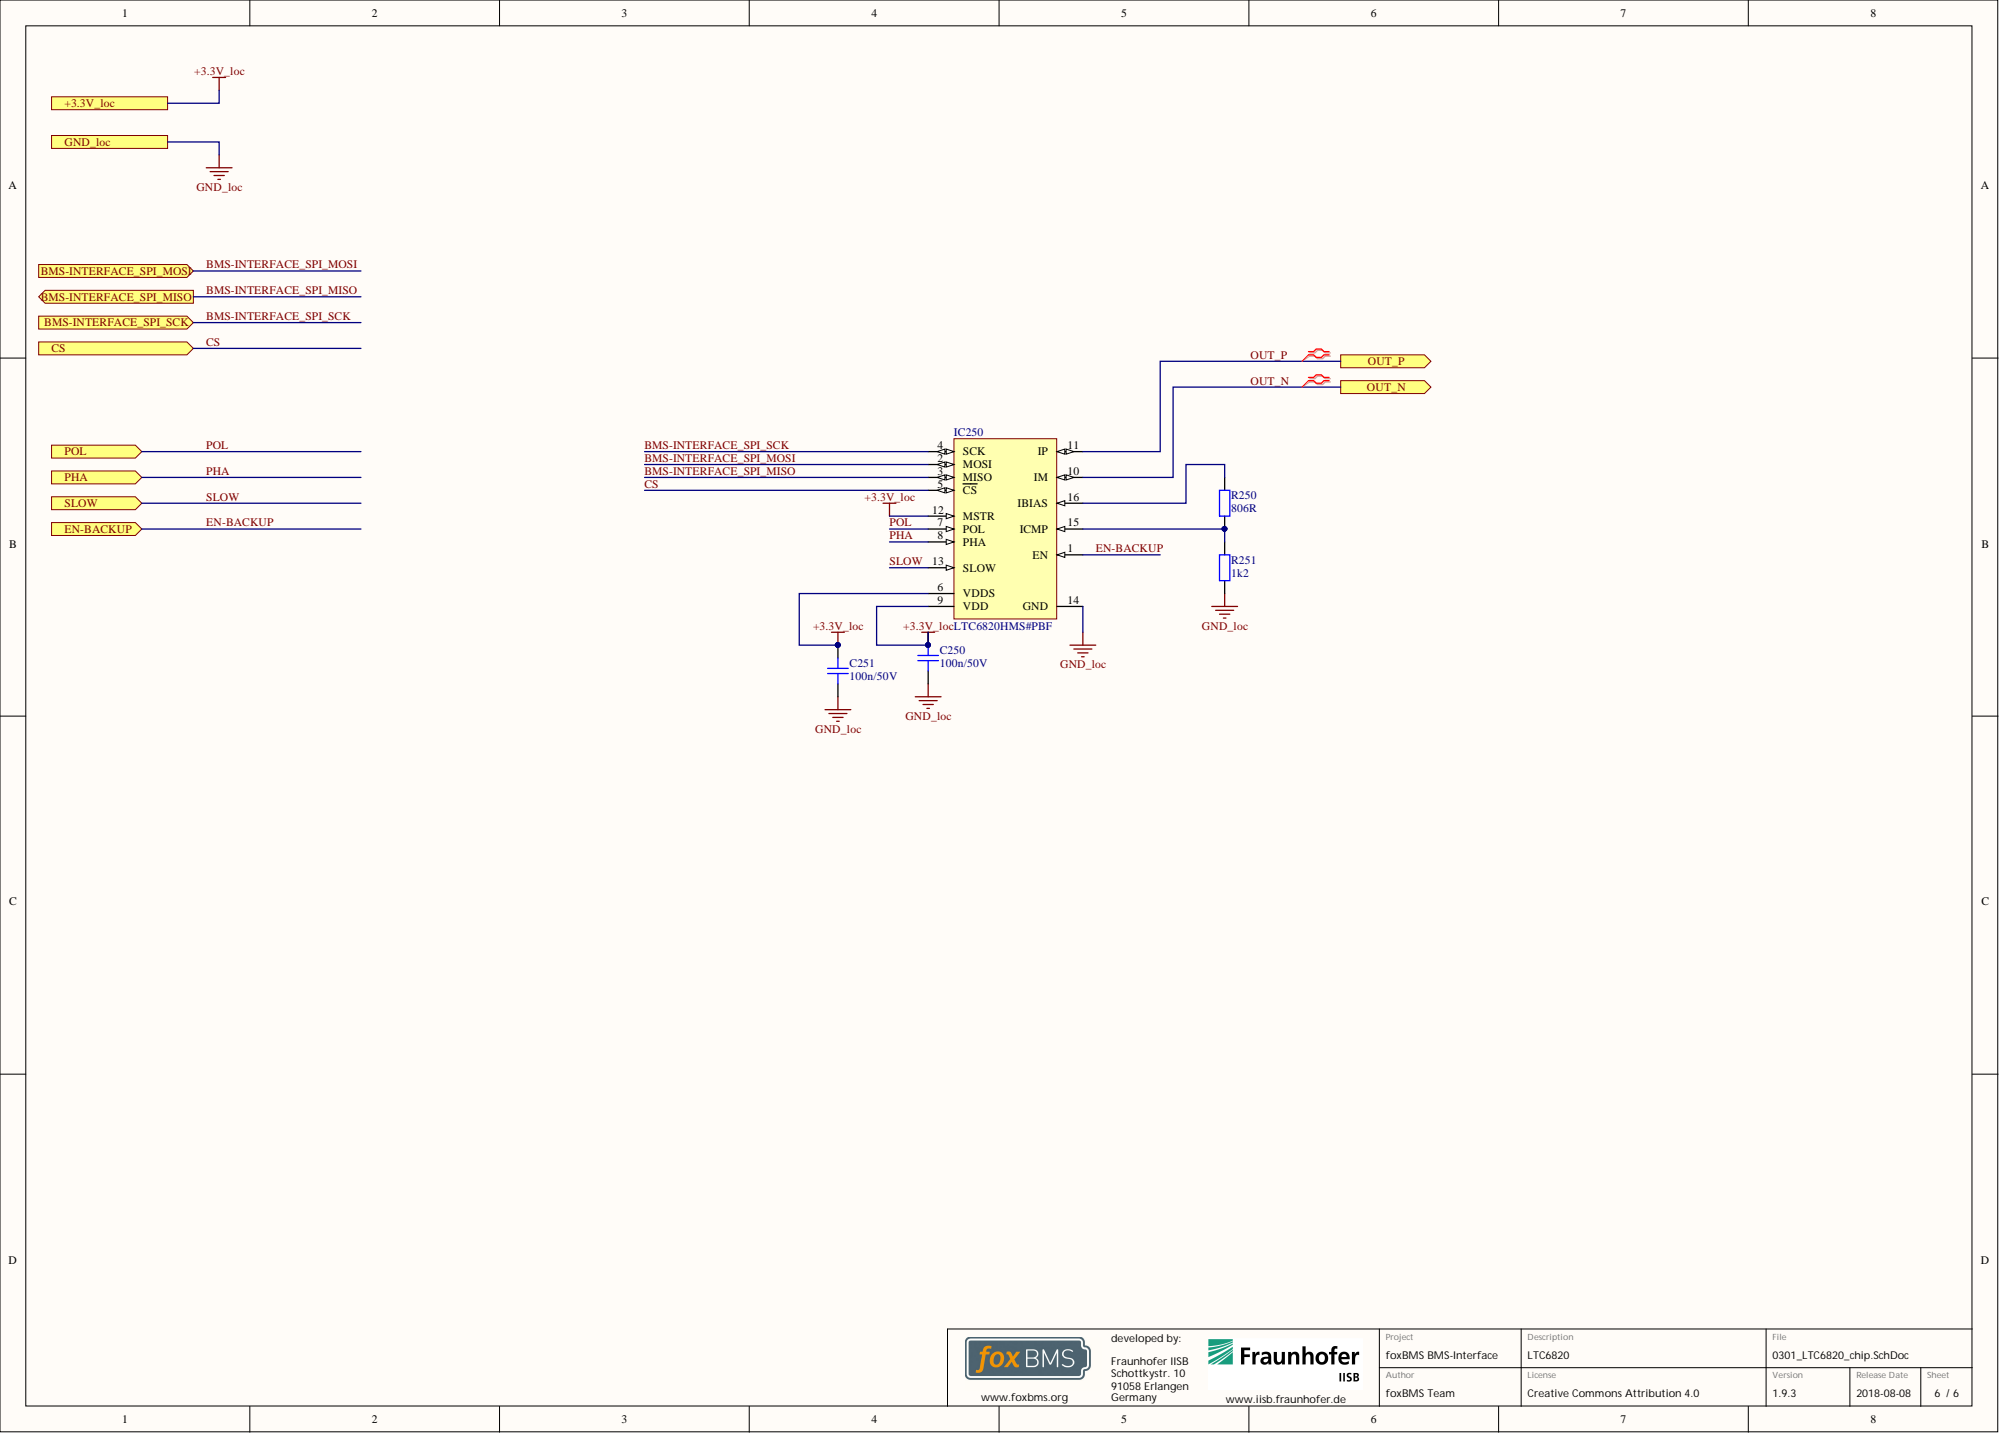
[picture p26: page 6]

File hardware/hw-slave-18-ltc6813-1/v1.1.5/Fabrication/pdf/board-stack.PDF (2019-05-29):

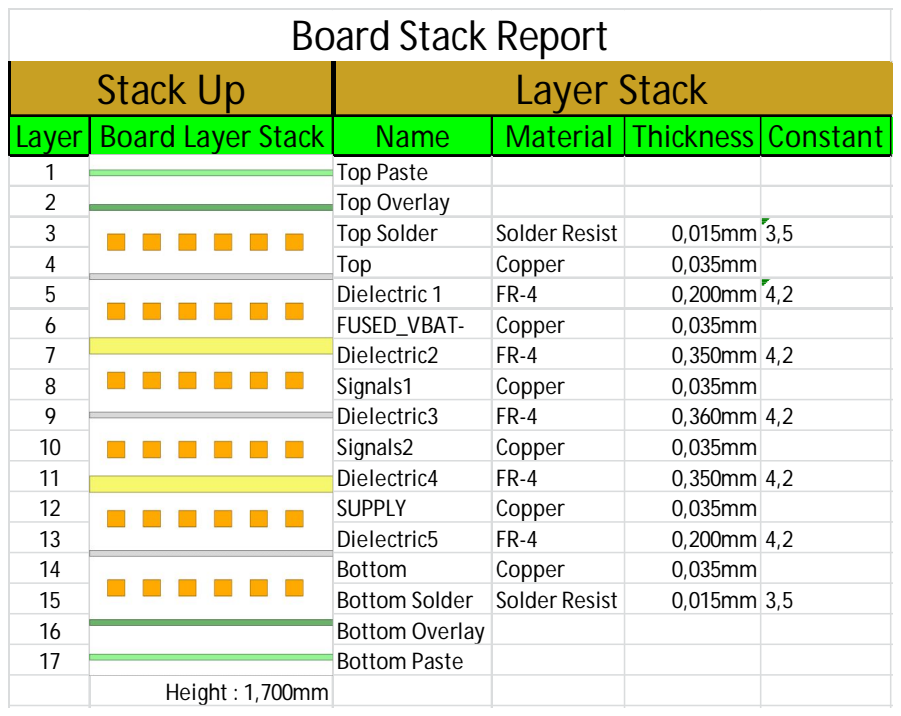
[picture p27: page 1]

Stack Up | Layer Stack
Layer | Board Layer Stack | Name | Material | Thickness | Constant
1 | | Top Paste
2 | | Top Overlay
3 | | Top Solder | Solder Resist | 0,015mm | 3,5
4 | | Top | Copper | 0,035mm
5 | | Dielectric 1 | FR-4 | 0,200mm | 4,2
6 | | FUSED_VBAT- | Copper | 0,035mm
7 | | Dielectric2 | FR-4 | 0,350mm | 4,2
8 | | Signals1 | Copper | 0,035mm
9 | | Dielectric3 | FR-4 | 0,360mm | 4,2
10 | | Signals2 | Copper | 0,035mm
11 | | Dielectric4 | FR-4 | 0,350mm | 4,2
12 | | SUPPLY | Copper | 0,035mm
13 | | Dielectric5 | FR-4 | 0,200mm | 4,2
14 | | Bottom | Copper | 0,035mm
15 | | Bottom Solder | Solder Resist | 0,015mm | 3,5
16 | | Bottom Overlay
17 | | Bottom Paste

Height : 1,700mm

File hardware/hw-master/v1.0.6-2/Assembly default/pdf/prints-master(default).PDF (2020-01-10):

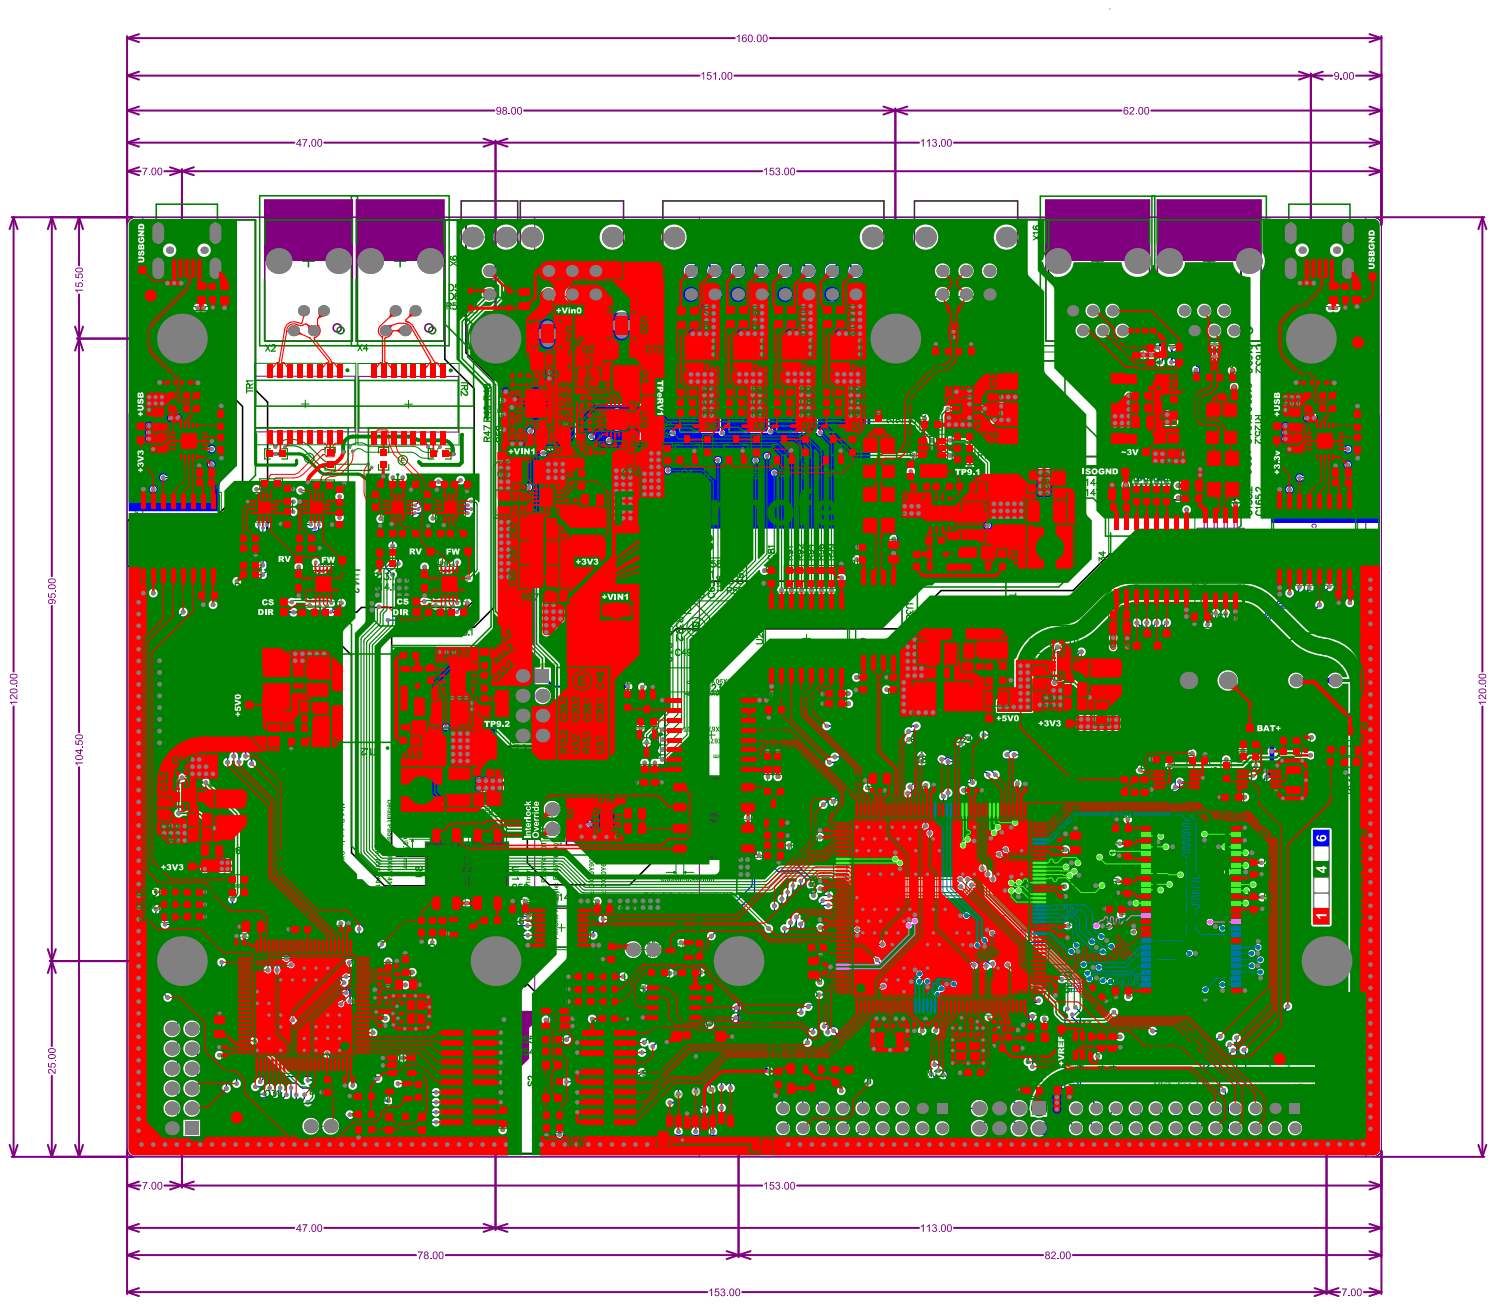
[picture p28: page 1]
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

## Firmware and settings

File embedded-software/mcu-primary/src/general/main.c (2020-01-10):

/**
 *
 * @copyright &copy; 2010 - 2019, Fraunhofer-Gesellschaft zur Foerderung der
 *  angewandten Forschung e.V. All rights reserved.
 *
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
 * We kindly request you to use one or more of the following phrases to refer
 * to foxBMS in your hardware, software, documentation or advertising
 * materials:
 *
 * &Prime;This product uses parts of foxBMS&reg;&Prime;
 *
 * &Prime;This product includes parts of foxBMS&reg;&Prime;
 *
 * &Prime;This product is derived from foxBMS&reg;&Prime;
 *
 */

/**
 * @file    main.c
 * @author  foxBMS Team
 * @date    26.08.2015 (date of creation)
 * @ingroup GENERAL
 * @prefix  none
 *
 * @brief   Main function
 *
 */


/*================== Includes =============================================*/
#include "main.h"

#include "cpu_cfg.h"
#include "os.h"
#include "version.h"
#include "can.h"
#include "vic.h"
#include "io.h"
#include "rcc.h"
#include "dma.h"
#include "spi.h"
#include "timer.h"
#include "led.h"
#include "adc.h"
#include "bkpsram.h"
#include "uart.h"
#include "com.h"
#include "chksum.h"
#include "diag.h"
#include "mcu.h"
#include "wdg.h"
#include "rtc.h"
#include "FreeRTOS.h"
#include "task.h"
#include "gitinfo_cfg.h"

/*================== Macros and Definitions ===============================*/


/*================== Constant and Variable Definitions ====================*/
RTC_STATUS_s main_state;


/*================== Function Prototypes ==================================*/
void SystemClock_Config(void);
void BOOT_Init(void);

/*================== Function Implementations =============================*/
/**
  * @brief  Main program
  *
  * @return int
  *
  */
int main(void) {
    uint32_t retErrorCode = 0;
    STD_RETURN_TYPE_e retval = E_NOT_OK;

    HAL_Init();         /* STM32F4xx HAL library initialization */
    RTC_Init();
#if BUILD_MODULE_ENABLE_WATCHDOG
    WDG_Init();        /* initialize and start watchdog*/
#endif
    BKP_SRAM_Init();    /* at this point diagnosis event memory in BKP_SRAM will be available */
    SystemClock_Config();
#if BUILD_MODULE_ENABLE_UART
    UART_Init();
    SYSCALL_Init();
#endif
    retval = DIAG_Init(&diag_dev, RTC_getRegisterValueBKPSRAM(BKPREGISTER_BKPSRAM_DIAG_VALID));
    if (retval == E_OK) {
        RTC_setRegisterValueBKPSRAM(BKPREGISTER_BKPSRAM_DIAG_VALID, BKPREGISTER_VALID);
    }

    BOOT_Init();
    IO_Init(&io_cfg[0]);
    IO_TogglePin(LED_DEBUG_LED_1);
    DMA_Init(&dma_devices[0]);
    SPI_Init(&spi_devices[0]);
    TIM_Init();
    LED_Init();
    ADC_Init(&adc_devices[0]);

    /* Initialize mutexes, events and tasks */
    OS_TaskInit();
    os_schedulerstarttime = OS_getOSSysTick();

    /* Initialize interrupts */
    retErrorCode = VIC_PreOsInterruptInit();
    if (retErrorCode != 0) {
        /* error event in vic init */
        DIAG_Handler(DIAG_CH_VIC_INIT_FAILURE, DIAG_EVENT_NOK, retErrorCode);
    }

    if (CHK_Flashchecksum(&ver_sw_validation) == E_OK) {
        chk_status.checksumstatus = CHK_CHECKSUM_PASSED;
    } else {
        chk_status.checksumstatus = CHK_CHECKSUM_FAILED;
        if (DIAG_HANDLER_RETURN_OK != DIAG_Handler(DIAG_CH_FLASHCHECKSUM, DIAG_EVENT_NOK, 0)) {
            while (1) {
                /* TODO: explain why infinite loop */
            }
        }
    }

    /* copy variable in order to prevent inlining */
    GIT_ValidStruct_s git_validation_copy __attribute__((unused)) = git_validation;
    if (GIT_checkStartup() == E_OK) {
        /* in case of a good startup check based on then git information,
         * it is always okay to start up
         */
        git_status.clean_repo_build = E_OK;
        git_status.allow_startup = E_OK;
    } else {
        if (BUILD_ALLOW_DIRTY_STARTUP) {
            /* Startup check was not okay, but a dirty startup was allowed by
             * by configuration
             */
            git_status.clean_repo_build = E_NOT_OK;
            git_status.allow_startup = E_OK;
        } else {
            while (1) {
                /* dirty startup is not allowed by some configuration, therefore
                 * no further startup, just set the struct for debugging
                 * purposes and wait
                 */
                git_status.clean_repo_build = E_NOT_OK;
                git_status.allow_startup = E_NOT_OK;
            }
        }
    }

    os_boot = OS_INIT_OSSTARTKERNEL;    /* start scheduler */
    vTaskStartScheduler();              /* vTaskStartScheduler() should never return */

    while (1) {
        /* TODO: explain why infinite loop */
    }
    return 0;
}


void SystemClock_Config(void) {
    RCC_ClockConfig();
}

/**
 * Set boot reset date, time and status
 */
void BOOT_Init(void) {
    uint32_t errCode = 0;
    RTC_Time_s currTime;
    RTC_Date_s currDate;

    errCode = MCU_SystemResetStatus(&main_state.CSR);

    /* Print startup info before error handling for improved readability over UART */
#if BUILD_MODULE_ENABLE_COM
    COM_StartupInfo();
#endif

    /* Unexpected reset occurred */
    if (errCode != 0) {
        DIAG_Handler(DIAG_CH_WATCHDOGRESET_FAILURE, DIAG_EVENT_NOK, errCode);
    }

    RTC_getTime(&currTime);
    RTC_getDate(&currDate);
    main_state.boot_rtcdate = currDate;      /* set boot date and time */
    main_state.boot_rtctime = currTime;
    RTC_WDG_RESETCOUNTER++;

    MCU_GetDeviceID(&mcu_unique_deviceID);

    /* @todo akdere: check diagnosis memory */
}

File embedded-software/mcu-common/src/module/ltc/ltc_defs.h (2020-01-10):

/**
 *
 * @copyright &copy; 2010 - 2019, Fraunhofer-Gesellschaft zur Foerderung der
 *  angewandten Forschung e.V. All rights reserved.
 *
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
 * We kindly request you to use one or more of the following phrases to refer
 * to foxBMS in your hardware, software, documentation or advertising
 * materials:
 *
 * &Prime;This product uses parts of foxBMS&reg;&Prime;
 *
 * &Prime;This product includes parts of foxBMS&reg;&Prime;
 *
 * &Prime;This product is derived from foxBMS&reg;&Prime;
 *
 */

/**
 * @file    ltc_defs.h
 * @author  foxBMS Team
 * @date    01.09.2015 (date of creation)
 * @ingroup DRIVERS
 * @prefix  LTC
 *
 * @brief   Headers for the driver for the LTC monitoring chip.
 *
 */

#ifndef LTC_DEFS_H_
#define LTC_DEFS_H_

/*================== Includes =============================================*/
#include "general.h"
#include "database.h"
#include "spi.h"

/*================== Macros and Definitions ===============================*/


/*================== Constant and Variable Definitions ====================*/

/**
 * Voltage measurement mode
 * 1: 01 27kHz Mode (Fast) 14kHz Mode
 * 2: 10 7kHz Mode (Normal) 3kHz Mode
 * 3: 11 26Hz Mode (Filtered) 2kHz Mode
 */
typedef enum {
    LTC_ADCMODE_UNDEFINED       = 0,    /*!< ADC measurement mode is not defined        */
    LTC_ADCMODE_FAST_DCP0       = 1,    /*!< ADC measurement mode: Fast with DCP0       */
    LTC_ADCMODE_NORMAL_DCP0     = 2,    /*!< ADC measurement mode: Normal with DCP0     */
    LTC_ADCMODE_FILTERED_DCP0   = 3,    /*!< ADC measurement mode: Filtered with DCP0   */
    LTC_ADCMODE_FAST_DCP1       = 4,    /*!< ADC measurement mode: Fast with DCP1       */
    LTC_ADCMODE_NORMAL_DCP1     = 5,    /*!< ADC measurement mode: Normal with DCP1     */
    LTC_ADCMODE_FILTERED_DCP1   = 6,    /*!< ADC measurement mode: Filtered with DCP1   */
} LTC_ADCMODE_e;

/**
 * Number of measured channels
 */
typedef enum {
    LTC_ADCMEAS_UNDEFINED               = 0,    /*!< not defined                            */
    LTC_ADCMEAS_ALLCHANNEL              = 1,    /*!< all ADC channels are measured          */
    LTC_ADCMEAS_SINGLECHANNEL_GPIO1     = 2,    /*!< only a single ADC channel (GPIO1) is measured  */
    LTC_ADCMEAS_SINGLECHANNEL_GPIO2     = 3,    /*!< only a single ADC channel (GPIO2) is measured  */
    LTC_ADCMEAS_SINGLECHANNEL_GPIO3     = 4,    /*!< only a single ADC channel (GPIO3) is measured  */
    LTC_ADCMEAS_SINGLECHANNEL_GPIO4     = 5,    /*!< only a single ADC channel (GPIO4) is measured  */
    LTC_ADCMEAS_SINGLECHANNEL_GPIO5     = 6,    /*!< only a single ADC channel (GPIO5) is measured  */
    LTC_ADCMEAS_SINGLECHANNEL_TWOCELLS  = 7,    /*!< only two cell voltages are measured */
    LTC_ADCMEAS_ALLCHANNEL_SC           = 8,    /*!< all ADC channels + sum of cells are measured   */
} LTC_ADCMEAS_CHAN_e;
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

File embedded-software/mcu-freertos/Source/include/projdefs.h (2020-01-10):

/*
 * FreeRTOS Kernel V10.2.0
 * Copyright (C) 2019 Amazon.com, Inc. or its affiliates.  All Rights Reserved.
 *
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
 * http://www.FreeRTOS.org
 * http://aws.amazon.com/freertos
 *
 * 1 tab == 4 spaces!
 */

#ifndef PROJDEFS_H
#define PROJDEFS_H

/*
 * Defines the prototype to which task functions must conform.  Defined in this
 * file to ensure the type is known before portable.h is included.
 */
typedef void (*TaskFunction_t)( void * );

/* Converts a time in milliseconds to a time in ticks.  This macro can be
overridden by a macro of the same name defined in FreeRTOSConfig.h in case the
definition here is not suitable for your application. */
#ifndef pdMS_TO_TICKS
	#define pdMS_TO_TICKS( xTimeInMs ) ( ( TickType_t ) ( ( ( TickType_t ) ( xTimeInMs ) * ( TickType_t ) configTICK_RATE_HZ ) / ( TickType_t ) 1000 ) )
#endif

#define pdFALSE			( ( BaseType_t ) 0 )
#define pdTRUE			( ( BaseType_t ) 1 )

#define pdPASS			( pdTRUE )
#define pdFAIL			( pdFALSE )
#define errQUEUE_EMPTY	( ( BaseType_t ) 0 )
#define errQUEUE_FULL	( ( BaseType_t ) 0 )

/* FreeRTOS error definitions. */
#define errCOULD_NOT_ALLOCATE_REQUIRED_MEMORY	( -1 )
#define errQUEUE_BLOCKED						( -4 )
#define errQUEUE_YIELD							( -5 )

/* Macros used for basic data corruption checks. */
#ifndef configUSE_LIST_DATA_INTEGRITY_CHECK_BYTES
	#define configUSE_LIST_DATA_INTEGRITY_CHECK_BYTES 0
#endif

#if( configUSE_16_BIT_TICKS == 1 )
	#define pdINTEGRITY_CHECK_VALUE 0x5a5a
#else
	#define pdINTEGRITY_CHECK_VALUE 0x5a5a5a5aUL
#endif

/* The following errno values are used by FreeRTOS+ components, not FreeRTOS
itself. */
#define pdFREERTOS_ERRNO_NONE			0	/* No errors */
#define	pdFREERTOS_ERRNO_ENOENT			2	/* No such file or directory */
#define	pdFREERTOS_ERRNO_EINTR			4	/* Interrupted system call */
#define	pdFREERTOS_ERRNO_EIO			5	/* I/O error */
#define	pdFREERTOS_ERRNO_ENXIO			6	/* No such device or address */
#define	pdFREERTOS_ERRNO_EBADF			9	/* Bad file number */
#define	pdFREERTOS_ERRNO_EAGAIN			11	/* No more processes */
#define	pdFREERTOS_ERRNO_EWOULDBLOCK	11	/* Operation would block */
#define	pdFREERTOS_ERRNO_ENOMEM			12	/* Not enough memory */
#define	pdFREERTOS_ERRNO_EACCES			13	/* Permission denied */
#define	pdFREERTOS_ERRNO_EFAULT			14	/* Bad address */
#define	pdFREERTOS_ERRNO_EBUSY			16	/* Mount device busy */
#define	pdFREERTOS_ERRNO_EEXIST			17	/* File exists */
#define	pdFREERTOS_ERRNO_EXDEV			18	/* Cross-device link */
#define	pdFREERTOS_ERRNO_ENODEV			19	/* No such device */
#define	pdFREERTOS_ERRNO_ENOTDIR		20	/* Not a directory */
#define	pdFREERTOS_ERRNO_EISDIR			21	/* Is a directory */
#define	pdFREERTOS_ERRNO_EINVAL			22	/* Invalid argument */
#define	pdFREERTOS_ERRNO_ENOSPC			28	/* No space left on device */
#define	pdFREERTOS_ERRNO_ESPIPE			29	/* Illegal seek */
#define	pdFREERTOS_ERRNO_EROFS			30	/* Read only file system */
#define	pdFREERTOS_ERRNO_EUNATCH		42	/* Protocol driver not attached */
#define	pdFREERTOS_ERRNO_EBADE			50	/* Invalid exchange */
#define	pdFREERTOS_ERRNO_EFTYPE			79	/* Inappropriate file type or format */
#define	pdFREERTOS_ERRNO_ENMFILE		89	/* No more files */
#define	pdFREERTOS_ERRNO_ENOTEMPTY		90	/* Directory not empty */
#define	pdFREERTOS_ERRNO_ENAMETOOLONG 	91	/* File or path name too long */
#define	pdFREERTOS_ERRNO_EOPNOTSUPP		95	/* Operation not supported on transport endpoint */
#define	pdFREERTOS_ERRNO_ENOBUFS		105	/* No buffer space available */
#define	pdFREERTOS_ERRNO_ENOPROTOOPT	109	/* Protocol not available */
#define	pdFREERTOS_ERRNO_EADDRINUSE		112	/* Address already in use */
#define	pdFREERTOS_ERRNO_ETIMEDOUT		116	/* Connection timed out */
#define	pdFREERTOS_ERRNO_EINPROGRESS	119	/* Connection already in progress */
#define	pdFREERTOS_ERRNO_EALREADY		120	/* Socket already connected */
#define	pdFREERTOS_ERRNO_EADDRNOTAVAIL 	125	/* Address not available */
#define	pdFREERTOS_ERRNO_EISCONN		127	/* Socket is already connected */
#define	pdFREERTOS_ERRNO_ENOTCONN		128	/* Socket is not connected */
#define	pdFREERTOS_ERRNO_ENOMEDIUM		135	/* No medium inserted */
#define	pdFREERTOS_ERRNO_EILSEQ			138	/* An invalid UTF-16 sequence was encountered. */
#define	pdFREERTOS_ERRNO_ECANCELED		140	/* Operation canceled. */

/* The following endian values are used by FreeRTOS+ components, not FreeRTOS
itself. */
#define pdFREERTOS_LITTLE_ENDIAN		0
#define pdFREERTOS_BIG_ENDIAN			1

/* Re-defining endian values for generic naming. */
#define pdLITTLE_ENDIAN					pdFREERTOS_LITTLE_ENDIAN
#define pdBIG_ENDIAN					pdFREERTOS_BIG_ENDIAN


#endif /* PROJDEFS_H */

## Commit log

2019-05-29 Extracting and Updating
    extracted, adding blankets and net classes
    [01_overview.SchDoc, 02_MCU_connector.SchDoc, 0301_LTC6820_chip.SchDoc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]
2019-07-09 hw-master updates
    Added dc-dc supply
    Changed iso dc-dc module
    Increased large ceramic package sizes
    Added impedance matched SDRAM traces
    Added piezo and supercap
    Added e-fuse and ferrite beads
    [02_MCU_connector.SchDoc, 05_slave-connector.SchDoc, CAN0.SchDoc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]
2019-07-10 DRC fixes
    Fixed hole-to-hole voilations
    Fixed most silk issues
    Known: C and R footprints w/o silk
2019-07-12 Updated footprints & Silk
    Changed 0402, 0603, 0805 R & C footprints w/ silk
    Fixed more design rule violations
    Changed top polygon pour with relief and no-pour over tracks/pads
    Known; re-annotate required to optimise manual placement
    Known; part numbers dont align with updated foorprints or comments
    Know; soldermask and paste mask updates needed
    [CAN0.SchDoc, EEPROM.SchDoc, FPGA_SPI_interface.SchDoc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]
2019-07-15 Updated routing
    Removed violations
    Re-annotated schematic from PCB
    Re-layed e-fuse
    Length matched SDRAM traces
    Fixed schematic-pcb rule sync
    Merged CAN0 molex connector
    Changed decoupling caps to 0402
    Moved super-cap next to piezo
    Moved silk artwork and designators
    Know; calculations required for TPS26602
    [CAN0.SchDoc, EEPROM.SchDoc, FPGA_SPI_interface.SchDoc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]
2019-10-29 Partial Check-in
    Merged multiple boards
    Updated libraries and re-arranged base schematic
    Reduced IO for single board
    **Work in progress**
    [01_overview.SchDoc, 0301_LTC6820_chip.SchDoc, 03_LTC6820.SchDoc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]
2019-10-29 Added Power and Ground planes
    Splitting up isolated ground planes
    Rerouted some USB components and de-coupling capacitors
    ** Work in progress **
    [CAN0.SchDoc, EEPROM.SchDoc, FPGA_SPI_interface.SchDoc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]
2019-12-22 Fixed Isolation Rules
    General layout complete
    Confirming e-fuse heatsink polygons
    Next step BOM
    [CAN_new.SchDoc, isolated_rs485.SchDoc, supply_internal.SchDoc]
2020-01-08 Updated packages and Impedance Rules (AD20)
    Updated project to AD20 Impedance and return path rules
    Improved ISO SPI routing
    Fixed impedance rules as per JLCpcb 6-layer spec.
    Added differential pair routing for USB, CAN, RS485 and ISO SPI paths
    ** Need polygon plane fixes
    [0301_LTC6820_chip.SchDoc, 03_LTC6820.SchDoc, CAN_new.SchDoc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]
2020-01-09 Updated Overlay Text Sizes
    Designator postions changes and re-numbered as per layout on board
    Submitted to JLCPCB.com for production
    [0301_LTC6820_chip.SchDoc, 03_LTC6820.SchDoc, Bill of Materials-master.xlsx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]
2020-01-10 Renaming folders in-line with previous versions
    Renamed modified current version to -2 revision of master
    [01_overview.SchDoc, 0301_LTC6820_chip.SchDoc, 03_LTC6820.SchDoc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]
2020-01-10 Merged Upstream and Cleanup master pcb project
    *Cleaned up output folder structure
    *Generated all output formats (PDF, Gerber, Stackup, STEP)
    *Completed BOM document
    **Submitted PCB to JLCpcb.com
    **Est $500AU part + $220 AU PCB cost (single board)
    [IsoDcDc-BSR033A.SchDoc, Pick Place for slave(default).csv, bat_connectors.SchDoc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]
